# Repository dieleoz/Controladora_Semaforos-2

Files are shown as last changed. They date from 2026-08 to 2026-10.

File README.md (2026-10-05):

# 🚦 Controladora de Semáforos Móviles de 3 Estados (V9.1)

> 🧭 **Las decisiones vigentes viven en [`DECISIONES.md`](DECISIONES.md)** — una fila por
> decision, con su fecha, su motivo y que deroga. *(Aqui se publicaba cuantas hay; se quito el
> 11/09 porque decia 18 y 9 cuando ya eran mas: se cuentan alli.)* Si un parrafo de cualquier
> documento contradice una fila de ahi, **gana la fila**: el parrafo esta caducado. Se lee
> ANTES de encargar un cambio de alcance.

---

## 🔴 Lo que este README no puede decirte, y es lo primero

> ▶️ **Donde esta parado el trabajo y por donde se retoma lo dice [`ESTADO.md`](ESTADO.md)**, que se
> reescribe en cada cierre; aqui no se repite. Lo que paso, en [`HISTORIA.md`](HISTORIA.md) y en `git log`.

**La instalación certificada es `e303485` (V8.4, 31/07/2026).** Lo de debajo llegó a una mesa
el 3-4/09 y la noche del 04/09 —banco con dos tarjetas; la última cinta, 05/09 22:19, sobre
`42a52cd`— y 🔴 **el 10/09 llegó por primera vez a una calle: un Maestro (`SERIE:179DB0`)
corrió en El Sisga con firmware V9 `SIN_BANCO`** —el paquete del 08/09 (`7ff7d12`); después
se probó el del 10/09 (`b354fe9`)—. Su cinta y su diario están en `evidencia/` (308 tramas,
308 checksums que casan). Lo que se reportó allí, lo que dice la cinta y la rama que salió de
ahí, validada por el diff, están en `roadmap.md` §3.16 (`N-162`). 🔴 **Con `7ff7d12`, el
Maestro 179DB0 se declara en hora con el reloj parado: no se usa el Modo Degradado allí.**
**Desde el 29/09 el funcional prueba en banco las candidatas** (`a505fa2`, `6bd1e4f`, `d3606be`; cintas en
`evidencia/300920261130/`, `011020260934/`, `021020260914/`), **pero ninguna ha pasado banco completo.**

**La razon lineas de instrumento / lineas de producto la mide el pre-commit en cada commit**
(`.githooks/trinquete.sh`, contra el techo `RAZON_TECHO` de `.topes`): si sube por encima del techo, el
commit se para. El techo solo baja, cuando un acta de campo archiva un tema (`CLAUDE.md` §4). Cuenta
el indice, sin `historico/`, e incluye la app y el ESP32, asi que no se compara con las razones de la
serie anterior (esa serie, en [`HISTORIA.md`](HISTORIA.md)).

**Tres auditorías externas independientes dijeron lo mismo**, y la tercera lo dijo de la
respuesta a la segunda. La regla que salió de ahí vive en `CLAUDE.md` §0 y §8:

> **Un `20/20` sobre decenas de miles de líneas de instrumento que nunca han tocado una tarjeta
> no es un entregable: es una coartada.**

La tabla de abajo es verdad. **Lee lo que mide antes de lo que puntúa.**

---

## 📐 LA SPEC — empieza por aquí, y son nueve ficheros (`SPEC_0` a `SPEC_8`)

**Escritas el 12–13/09 desde el fuente, verificando cada afirmación contra el código; manda la SPEC y
`DECISIONES.md` es su índice.** `SPEC_0` es la vista del sistema y `SPEC_7` el modo sin reloj. Sustituyen a ~17.000
líneas de manuales que describían un sistema que ha cambiado cuatro veces.
**Nacieron por debajo de 300 líneas a propósito** (hoy `SPEC_1` y `SPEC_2` lo pasan): un fichero que no se puede leer
entero no lo lee nadie entero, y
entonces cada lector deriva su propia versión.

| | qué contesta |
|---|---|
| [`SPEC_1_Ciclo_y_Luces`](05_Funcional/SPEC_1_Ciclo_y_Luces.md) | qué hace **un** poste con sus tres luces y su pluma: modos, tiempos, transiciones, la barrera de salidas |
| [`SPEC_2_Dos_Puntas_y_Radio`](05_Funcional/SPEC_2_Dos_Puntas_y_Radio.md) | 🔴 **lo único de verdad difícil: que los dos postes NUNCA den verde a la vez**, con una radio lenta que pierde tramas y sin cable entre ellos; y sin radio, el Degradado con testigo (§7.bis) y el **automatico a eleccion del tecnico** (§7.ter, 29/09) |
| [`SPEC_3_La_Hora`](05_Funcional/SPEC_3_La_Hora.md) | de dónde sale la hora y qué pasa cuando se pierde — **es lo que autoriza el Degradado**, o sea el modo que da verdes sin confirmar con la otra punta |
| [`SPEC_4_App_y_Bluetooth`](05_Funcional/SPEC_4_App_y_Bluetooth.md) | la **única** forma de operar el equipo (`D-16`): qué órdenes hay, qué contesta el equipo a cada una y de qué depende esa respuesta |
| [`SPEC_5_Cobre_Camaras_Pluma`](05_Funcional/SPEC_5_Cobre_Camaras_Pluma.md) | 🛑 **qué hay en cada pin, qué es peligroso y qué no se ha medido nunca.** Se lee con un destornillador en la mano |
| [`SPEC_8_Camaras_y_Barrera`](05_Funcional/SPEC_8_Camaras_y_Barrera.md) | 🛑 **qué HACE el equipo con las cámaras y la barrera**: el veto, el retardo de 3 s, cuándo pide que se revise una cámara, los dos interruptores de administrador, y **qué NO protege**. Es la otra mitad de `SPEC_5`: aquí lo que decide el **firmware**, allí lo que decide el **cobre** |
| [`SPEC_6_Campo_Radio_y_Alarmas`](05_Funcional/SPEC_6_Campo_Radio_y_Alarmas.md) | el **procedimiento de campo** del Degradado, la configuración de radio y antenas, y la tabla completa de alarmas → qué hace el técnico |

> ⚠️ **La spec dice qué HACE el equipo hoy, no qué debería hacer.** Lo que no cumple una decisión vigente vive
> en el apartado «HUECOS MEDIDOS» de cada una, con la medida pegada. **Y los manuales viejos siguen en el
> árbol a propósito**: se intentó jubilarlos y se paró con medida — hay contenido que ninguna spec cubre
> todavía (la receta de la APK, los ensayos de cámara con instrumento, la trama canónica con checksums de la
> que cuelga un pack). Está contado en `roadmap.md` 1.35(a).

## 🔧 Qué se probó en banco, y qué no

> **El 3 y 4 de Septiembre esto vio una tarjeta.** El funcional ejecutó la guía de 29 pasos
> sobre `617bd00`: **24 pasos completados**, 4 bloqueados por el enlace Bluetooth y 1 abortado
> por un incidente de seguridad. Informe en
> `evidencia/Informe_Pruebas_Banco_Semaforos_V9.0.pdf`.
>
> **Funcionó en cobre:** carga por SWD al primer intento, radio entre puntas con caída a ámbar
> en ~20 s y vuelta sola en ~3 s, talanquera, cámara de demanda y masa común a 0 V.
>
> ✅ **La regresión N-42 —el Modo Automático no movía las luces— está CERRADA EN COBRE.** La
> cerró la sesión de banco de la noche del 04/09, con el responsable delante: *«ahí cambia ese
> amarillo y este a verde. Ahora está funcionando»*. El arreglo es `ceb8cc5` —se retiró el
> asistente entero: una sola puerta, el modo arranca corriendo—. *(Este README publicó
> «regresión abierta» hasta el 07/09; el banco la había cerrado tres días antes.)*
>
> 🔴 **Y aparecieron tres defectos que ninguna cifra de la tabla de abajo podía ver**, porque
> ninguno es una propiedad del código: la tarjeta Maestro tiene un corto de 3,3 V a masa
> (**N-116**), las entradas de campo no tienen ninguna protección mientras las salidas sí
> (**N-120**), y el ESP32 no se anunciaba por Bluetooth (**N-117**). **Los tres pasaron el
> `20/20` sin despeinarlo.**
>
> *(El cuarto de aquella lista, **N-118** —«el mando A/B no responde, 0,6 V en reposo»—, quedó
> **REFUTADO el 05/09**: el propio banco había medido las dos ramas del experimento en la misma
> tabla. Mismo cobre, distinto `pinMode`, distinta tensión. Ver `05_Funcional/historico/DECISIONES_hist.md`, cerradas.)*

**Verificación actual** — cifras **copiadas del acta**
[`evidencia/2026-10-05_compuerta.txt`](evidencia/2026-10-05_compuerta.txt), que genera
`python 01_Firmware/compuerta.py` en una sola corrida. No se escriben a mano — y desde **N-62**
eso ya no es una promesa: el pack `documentos_01_cifras_del_acta` compara esta tabla contra la
última acta en cada corrida del banco. Cuando se escribió por primera vez, **falló**: esta tabla
publicaba 32 rutas y 86,4 % de flash cuando el acta que ella misma citaba medía 38 rutas y
92,8 %. Las cifras eran del 05/08 y llevaban la palabra *«copiadas»* encima.

| Comprobación | Estado | |
|---|---|---|
| guarda de rutas de los instrumentos | ✅ | 61 rutas parseadas, todas existen |
| banco por packs *(70 packs)* | 🔴 **FALLA** | **1372/1373 comprobaciones en 70 packs** — 69 PASS, **1 FALLA**. El rojo es CORRECTO: `decisiones_01_anclas` acusa a **`D-22`**, la única decisión vigente sin construir, y **necesita una tarjeta delante** (`CLAUDE.md` §1: no se decora) |
| compila Maestro / Esclavo / Repetidor / ESP32 | ✅ | **70.4 %** · 62.6 % · 20.6 % · 35.7 % — *el Maestro ocupa **45408 de 64512 B** (la ultima pagina queda para el testigo de `D-35`); el Esclavo, **40360 B**. Bajo al quitar la libreria RTC (`N-172`) y subio con la salida programada (`D-52`)* |
| simulador funcional | ✅ | 9/9 — eran 20, y 11 de aquellas no medían nada: se retiraron una a una con su evidencia |
| simulador de repetidor | ✅ | 10/10 |
| compila ESP32 | ✅ | 35.7 % — 1123581 de 3.145.728 B |
| simulador del puente ESP32 | ✅ | **150/150** — las tres puntas: `bluetooth.cpp` compilado, la app en jsdom, y solo el ESP32 modelado |
| simulador de app y bluetooth | ✅ | **12/12** — estuvo en `ABORTADO` unas horas el 05/09: **N-149** le añadió el campo `ESC` al `$STATUS` y el instrumento no supo con qué compararlo. Se enseñó a leerlo el mismo día. Queda escrito porque **mientras duró, todo lo que vigilaba entró sin mirar** (`CLAUDE.md` §1) |
| **app ejecutada en DOM** | ✅ | **540/540** — carga `index.html` en jsdom, más `app.js` y **los `js/*.js` que el propio HTML declara, en su orden**, y los **ejercita**: pestañas, modales, ingesta de telemetría, *fuzzing* de 200 tramas corruptas y los botones que mandan comandos. Es el único instrumento que **ejecuta** la app en vez de leerla |
| test funcional de la app | ✅ | **70/70** — decía «22/22» a mano y ejecuta 34; su prueba de Courier RTC era una tautología |
| test unitarios TDD de la app | ✅ | **85/85** — la **segunda** suite unitaria, que hasta el 01/09 **no estaba en la compuerta**: 23 pruebas verdes que no medían nada. *(Esta fila publicó `55/55` hasta el 07/09: era la cifra del 02/09, y `documentos_01` **no la vigila** — no está en su tupla `CIFRAS`.)* |
| test unitarios de la app | ✅ | **63/63** — seis suites que no cargan el navegador: NMEA y *checksums*, generador de comandos y barrera de PIN, validación de `SET_TIEMPOS`, Courier RTC, gestor de cruces y escala de 20 cruces |
| arnés del ciclo | ✅ | **55/55** — corre sobre el `ciclo_degradado.h` real compilado, sin espejo en Python |
| arnés del respaldo | ✅ | compila el `calcularSuma()` real; identidad de `respaldo.cpp` entre puntas + prueba de vida |
| arnés del Degradado a dos puntas | ✅ | **143/143** — las dos puntas en Degradado **cada una con su reloj**. Entrega **el número**: el cruce aguanta **29 s** de desfase contra los **20,2 s** que el equipo puede acumular en 48 h, o sea factor **1,44** — y no el 2 que afirmaban los comentarios de las dos puntas |
| arnés de las dos puntas | ✅ | **127/127** — el C++ **real de las DOS puntas** en el mismo proceso y el mismo instante: verde simultáneo en **0** instantes. Cubre `G3`/`N-163` (suelta del verde), `D-34` (verde del Esclavo frente al ámbar del Maestro, `G12`–`G14`) y `D-53` (rojo+amarillo antes de cada verde). Sin banco |
| arnés del automático | ✅ | **88/88** — compila `coordinador.cpp` + `semaforo.cpp` + `modo_automatico.cpp` + `modo_inteligente.cpp`, `demanda.cpp` y el `botones.cpp` real, y comprueba SFTY-2 sobre las escrituras de pin. Las 16 nuevas son el **Bloque G de `D-33`**: el retardo de bajada de la pluma y el veto de la cámara, ejecutados |

> 🛑 **Aquí había una fila más, `arnés de pantalla`, y NO se actualiza: se RETIRA.** Compilaba los cuatro
> `lcd.cpp`/`menu.cpp` reales contra 131 `.c` de U8g2, y **se fue con el LCD** el 13/09 (`D-32` (1), `17d3a1f`).
> La compuerta baja de **20 filas a 19** y el banco pierde sus **287 comprobaciones** (145 Maestro + 142
> Esclavo): **es una bajada A PROPÓSITO, no una regresión.** Se dice aquí abajo y no en la tabla porque en la
> tabla **sólo caben filas con una medida detrás** — una fila sin medida se lee como medida.

**19 PASS · 1 FALLA · 0 ABORTADO, de 19 comprobaciones — la compuerta sale con código `1`.**

> 🔴 **El `1` es el hallazgo, no una regresión.** Lo acusa `decisiones_01_anclas`: **`D-14`, `D-22` y
> `D-23` están vigentes en `DECISIONES.md` sin una línea que las construya.** `D-14` —*el controlador
> cierra un contacto y la cámara graba*— fue **el argumento de una compra**; `D-22` es poner `Y1`, y
> `D-23` es la pantalla propia del poste 2, **que es de la app y la app no se ha tocado**.
>
> 🛑 **Y ninguna de las tres se apaga poniéndole un ancla:** `D-23` se apaga **construyéndola**
> —un `$EVENT` nuevo en el Esclavo y su pantalla en la app—; `D-14` espera **una decisión del
> responsable** —qué canal de `J9`/`J11`/`J13` se gasta, para siempre—; y `D-22` espera **una
> tarjeta delante**, porque si `Y1` no oscila el `_Error_Handler` es `noreturn` y la tarjeta queda
> a oscuras. **El 07/09 se intentó cerrarlas poniéndoles el ancla en un comentario y la compuerta se
> puso en `20/20` sin que se construyera nada** *(`roadmap.md` §3.10)*. Las tres anclas están
> revertidas y el rojo volvió, que es donde tiene que estar.

> 🟢 **Y cuando vuelva a `0`, ese verde será más peligroso que el rojo, no menos.** Mientras la
> compuerta sale con `1` nadie la confunde con un permiso; un `0` sí se confunde. Lo que dice es
> exactamente esto:
> *los modelos y los arneses de PC no encuentran nada*. **No dice que el firmware funcione en la
> tarjeta.** El contraejemplo está fechado: los tres defectos que pararon el banco del 3-4/09
> pasaron estas 19 comprobaciones sin despeinarlas. **Verde no es entregable.**

### Por qué la compuerta está hecha así — cuatro lecciones, en una línea cada una

| | |
|---|---|
| **`ABORTADO` no es `PASS`** | una comprobación que no pudo correr no dice *nada* del firmware. Así se perdió la cobertura del Maestro sin que nadie se enterara (**N-28**) |
| **Un `FALLA` contado como `PASS`** | los tres validadores monolíticos imprimían `FALLA` y salían con código `0`. Se retiraron el 05/08 exigiendo que los packs sumaran *exactamente* sus comprobaciones y que el **texto** de cada una coincidiera — Costura `41 = 41`, Maestro `64/67 = 64/67`, Esclavo `31 = 31` (**N-46**) |
| **Un `gcc` que existe no es un `gcc` que enlaza** | dos arneses cayeron a `ABORTADO` de un día para otro con el mismo compilador en el acta: `ld` no abría una ruta con `ñ`. La compuerta **le exige enlazar un `main()` vacío** antes de fiarse (**N-44**) |
| **Un pack puede estar verde sin medir nada** | la prueba 2.8 del checksum hacía `break` sobre una condición siempre cierta y no evaluaba un solo candidato. Al arreglarla apareció un camino **explotable** en `FLAGS`/`SYNC_BAJA` (**N-51**) |

**El detalle de las cuatro, con su medida, está en [`roadmap.md`](roadmap.md).**

> **Un acta no es una frase.** `evidencia/` guarda fecha, hash de HEAD y versión de toolchain de
> cada corrida, así que "20/20" deja de ser un número que envejece en un README y pasa a ser
> algo que el auditor re-corre sobre ese mismo commit. Estado de hoy en
> [`ESTADO.md`](ESTADO.md); reglas permanentes en [`CLAUDE.md`](CLAUDE.md).

### 📦 El banco son 70 packs — y eso NO es una medalla

```
python 01_Firmware/Simulaciones/banco/correr.py --listar
python 01_Firmware/Simulaciones/banco/correr.py --pack esclavo_03   # un fallo, solo, en 1 s
```

**Por qué se migró** — había tanto instrumento como firmware: **8.898 líneas contra 8.895, uno a
uno**. Y los simuladores no ejecutan el C++, lo *reimplementan a mano*: son una segunda copia que
alguien sincroniza, y eso falló cuatro veces en una semana.

⚠️ **Pero `correr.py` NO es `compuerta.py`.** El banco es **una fila de veinte**: un
`x/y` de packs no dice nada de las otras diecinueve, y una de ellas puede estar en `ABORTADO` por
el mismo cambio que acabas de comitear. **Antes de comitear se corre `compuerta.py`, completo.**

### 📦 Qué se le manda al funcional, y por qué son dos paquetes

**Un paquete es una autorización implícita:** quien lo recibe asume que puede instalarlo. Con el
banco sin pasar, eso obliga a separar lo que pide una medida de lo que entrega una versión.

| | |
|---|---|
| **Encargo de banco** | Pide que alguien ponga la tarjeta delante. Lleva los binarios con sus MD5 y los firmware marcados `SIN_VALIDAR` en el propio nombre |
| **Entrega de versión** | Fuente para PlatformIO + APK + el `.html` de pruebas vigente + `LEEME_PRIMERO.txt`. **Sin `.bin`, sin manuales, sin `.md` y sin acta**; se deja en `entregas/` (ignorada por git), nunca en la raíz |

El `LEEME_PRIMERO` **no abre con la cifra en verde** — abre diciendo qué corre en campo, que esto
no es eso, y qué sigue roto. El método está en `orquestador:entregar` y en
`.claude/particularidades/entregar.md`.

**Certificado en campo:** 31 de Julio de 2026 *(V8.4, dos radios en enlace directo)*
**Última actualización del repositorio:** 11 de Septiembre de 2026 *(la cifra vigente y su hash de
HEAD están en el acta que cita la tabla de arriba, y no se repiten aquí: este pie llevaba
`14 PASS` sobre HEAD `2cde016` cuando el acta ya medía otra cosa, y un recuento viejo no se lee
como viejo, se lee como medida.)*
**Repositorio Oficial:** [`github.com/dieleoz/Controladora_Semaforos-2`](https://github.com/dieleoz/Controladora_Semaforos-2.git) — remoto `origin`.
**Normativa Aplicable:** Resolución 2024 del Ministerio de Transporte de Colombia (Secuencia de Luces y Tiempos de Seguridad Vial)

---

## 🧭 La arquitectura vigente, decidida en obra el 28/08 y cerrada el 31/08

**El documento con el detalle medido —`fichero:linea` en cada afirmación, las decisiones
abiertas con dueño y las medidas de multímetro— es
[`05_Funcional/17_Arquitectura_28-08_y_Decisiones_Abiertas.md`](05_Funcional/17_Arquitectura_28-08_y_Decisiones_Abiertas.md),
y manda la SPEC (`05_Funcional/SPEC_0..8`; [`DECISIONES.md`](DECISIONES.md) es su índice). Aquí va sólo el reparto,
porque un README que describe el aparato anterior manda a cablear el aparato anterior.**

### El reparto, en una frase

**El STM32 sigue siendo el controlador del semáforo. El ESP32 es un módulo de expansión colgado de
un puerto serie: aporta reloj y Bluetooth, y NO manda sobre las luces.**

```
                       fuente propia 12 V (NO sale de la tarjeta)
                                    |
   +--------------------+     +-----v--------------------+
   |   STM32F103C8      |     |         ESP32            |
   |   (controlador)    |     |   (modulo de expansion)  |
   |                    |     |                          |
   |  luces    J3-J8    |     |  DS3231  GPIO21 SDA      |
   |  barrera  J15      |     |          GPIO22 SCL      |
   |  camaras  J16 (*)  |     |          (pila propia)   |
   |  LoRa     J12      |     |                          |
   |           USART3   |     |  Bluetooth (sustituye    |
   |                    |     |   al modulo SPP)         |
   |  USART1 remapeado  |     |                          |
   |  PB6 TX == J17 p3 <------ GPIO16 (RX2)              |
   |  PB7 RX == J17 p2 ------> GPIO17 (TX2)              |
   +---------|----------+     +-----------|--------------+
             |                            |
             +-------- masa comun --------+
                       9600 8N1
```

*(\*) Aquí ponía ~~`camaras J14, J16`~~. ✏️ **11/09:** las cámaras van a `J16` —dos por poste, p10 y
p12 (`D-25`)—. `J14` no lleva cámara: ~~`A-2` lo reserva al fin de carrera,~~ **pero el firmware lo sigue
leyendo como cámara de demanda (`CAM_DEMANDA_PIN` = `PB0`)** — ~~conflicto abierto, del responsable~~
→ **`D-27` (11/09): `J14` LIBRE, sin cablear; el fin de carrera no se instala en este despliegue**,
así que en `J14` no se conecta nada (`ARQUITECTURA.map` §7.3).*

### El enlace, pin a pin — y la fuente

| ESP32 | dirección | `J17` | STM32 |
|---|---|---|---|
| `GPIO17` (TX2) | ➡️ | **p2** | `PB7` — **RX** del micro |
| `GPIO16` (RX2) | ⬅️ | **p3** | `PB6` — **TX** del micro |
| `GND` | — | p7 o p9 | `GND` — **masa común obligatoria** |

`9600 8N1`. El `USART1` ya está remapeado a `PB6`/`PB7` en el firmware de las dos puntas (N-76,
`bluetooth.cpp`, `grep -n "SerialBT(PB7, PB6)"`) — el puerto y el pinout son los mismos que ya
tenía el módulo SPP; **lo que se enchufa, no**.

> 🔴 **El ESP32 lleva fuente propia desde 12 V. NO cuelga de los 3,3 V de `J17` p6/p8.** Ese riel
> sale del `U5` y es **el mismo que alimenta al STM32 que gobierna el semáforo**: un ESP32 con radio
> da picos de corriente del orden de medio amperio, y un reset del controlador provocado por un
> periférico de diagnóstico es el reparto de riesgo que no se acepta. **El accesorio no puede tumbar
> al que manda.**

### Lo que se retira, y por qué — tachado, no borrado

> **Una vía descartada que desaparece en silencio vuelve a proponerse.** Por eso van tachadas con su
> motivo al lado, y no suprimidas.

| se retira | por qué | consecuencia |
|---|---|---|
| ~~**Pantalla LCD ST7920** (las dos puntas)~~ | **este PCB no permite ampliación**, y la pantalla ocupaba cinco pines —`PB3` `PB4` `PB5` `PB6` `PB7`— de los que el Bluetooth necesita `PB6`/`PB7`: **no había de dónde sacarlos**. Confirmado por el responsable el 05/09 (`D-17.bis`) | toda la operación pasa por la app. **Se retira del EQUIPO, no del código**: `lcd.cpp` y `menu.cpp` siguen compilando y `Validacion_LCD` sigue dando `271/271` sobre un framebuffer del PC |
| ~~**Módulo Bluetooth SPP dedicado** (`HC-05` / `JDY-30`)~~ | lo sustituye el ESP32 por el mismo `J17` | **no se compran** |
| ~~**Los CUATRO botones**~~ | los pines 3 y 4 son los que necesitan las cámaras, y el 05/09 el responsable retiró la botonera entera: **«todo por app»** | ⚠️ **DOS funciones de botón están muertas y DOS SIGUEN VIVAS, y el reparto no es casual**: `botonAceptar()`/`botonCancelar()` son `return false;` —son los de `PB14`/`PB15`, **los pines que ahora son cámaras**—; pero `botonArriba()`/`botonAbajo()` tienen llamadores vivos y leen `BOTON1`/`BOTON2`, **que son los pines del mando**. 🔴 **Lo que alguien cierre en `J16` p5/p8 contra los 3,3 V SIGUE ENTRANDO al firmware.** *(`Botón 1` y `Botón 2` SON `Mando A` y `Mando B`: los mismos dos pines con dos nombres.)* |
| ~~**El mando de relés** (hardware)~~ | 05/09, el responsable: *«ya no tenemos mandos de A y B, sólo la app»* (`D-1`) | ~~🔴 **El CÓDIGO no se toca**~~ 🛑 **DEROGADO POR `D-30` (12/09): el software TAMBIÉN sale** —el responsable: *«hasta el sw lo quitamos»*—. **Decidido y SIN CONSTRUIR**, y va con su precio medido, que es lo que lo tiene parado: `mando_ambarLocal()` tiene **SEIS** llamadas vivas (no cinco), y de ellas **la que ABRE PASO es el veto del `CMD_GO_GREEN` del Esclavo**; retirar sólo el armador deja ese `if` **ABIERTO, no inerte**. Además `mando.cpp` es el **único escritor de `senalActiva`**, así que el cambio toca **`SFTY-2`**, y después **ningún instrumento vigila la interceptación de las salidas por señal**. ⚠️ Y no cierra el cobre: `J16` p5/p8 siguen vacíos y **el firmware los lee por DOS caminos**, no sólo por el del mando (`CLAUDE.md` §3) |

> 🔴 **Y su consecuencia declarada, que es una propiedad del sistema y no una avería (`D-16`):
> SIN TELÉFONO NO HAY FORMA DE OPERAR EL EQUIPO.** Ni ámbar, ni volver a automático, ni parar el
> cruce. Va escrito en el manual del operario: el teléfono es herramienta crítica.

### Las cámaras van a `J16` p10 y p12 — **dos por poste** (`D-25`, 11/09) — y **ya se cablean**

*(Resumen: la tabla que manda es `05_Funcional/17_…` §1.7. La columna «red» es el nombre heredado
del netlist, **no el papel del pin**.)*

| `J16` | red | pin | uso nuevo |
|---|---|---|---|
| p1 | `/12V` | — | 🔴 **12 V crudos. Se tapa físicamente en CADA equipo que se monte** (N-120) — es el único conector de señal de la tarjeta que los trae, sin opto ni clamp |
| p5 | `/Boton1` | `PB9` | **libre y SIN CABLEAR** (`A-2`, cerrada el 05/09: ~~el fin de carrera va a `J14`~~ — *11/09, `D-27`: y tampoco allí, el fin de carrera no se instala; `J14` queda libre*). 🔴 **El firmware sigue leyendo ese pin** y alimentando el reconocedor de secuencias del mando |
| p8 | `/Boton2` | `PB13` | igual que p5 |
| p10 | `/Boton3` | `PB14` | 🎯 **`CAM_C_PIN` — cámara 1**, contacto de alarma entre p9 (3,3 V) y p10 *(verificada en banco el 03/09)* |
| p12 | `/Boton4` | `PB15` | 🎯 **`CAM_D_PIN` — cámara 2**, contacto de alarma entre p11 (3,3 V) y p12 |

> ✅ **`D-25` (11/09, el responsable): las conexiones de la guía de cámaras del Sisga quedan
> DEFINITIVAS** —4 cámaras, dos por poste— y derogan de `D-13` solo *«una por poste, p12 vacío»*.
> 🔴 **Lo que el que cablea tiene que saber, medido en el firmware de hoy:** las **dos entradas hacen
> LO MISMO** (piden paso; `botones.cpp`, `CAM_J16[2]`), **ninguna protege la pluma** (el veto es
> `A-1.bis`, sin construir), y **una segunda cámara muerta desde la instalación no la detecta nadie**
> (el vigilante salta el pin que nunca dio un flanco): se comprueba cada cámara por separado al
> instalar. Las frases falsas de la guía del 10/09 se corrigen en su versión nueva (`roadmap.md` §3.16)
> → ✏️ **11/09: es [`05_Funcional/Camaras_Sisga_4x.html`](05_Funcional/Camaras_Sisga_4x.html)**, con
> la fe de erratas delante y la talanquera en `J15` al final. ⚠️ **La app** (también la APK del 10/09)
> **pone `CAM: OK — las dos ven` en cuanto detecta CUALQUIERA de las dos cámaras del poste**, aunque la
> otra no haya detectado nunca: por eso **cada cámara se comprueba con el multímetro en su borne**
> (0 V en reposo, 3,3 V con algo en la zona), y no con la app.

> ✅ **La medida `M3` está CERRADA desde el 03/09 y las cámaras se cablean** (`D-3`). Medido en
> cobre —multímetro, conector vacío, paso 20 de la Guía—: el pull-down de **10 kΩ** que declaraba
> el netlist **es real y está en las cuatro posiciones** (`R65`–`R68` con su 100 nF); `p10` y `p12`
> dan **0 V en reposo**, así que la entrada es **activa en ALTO**, que es lo que el firmware ya
> hacía. El paso 21 cableó `p10` contra `p11` en normalmente abierto y funcionó, **sin demandas
> fantasma**.
>
> ~~🛑 No se cablea cámara a `J16` hasta cerrar la medida `M3`~~ — **caducado**: este README lo
> siguió publicando cuatro días después de cerrarse, y el 05/09 se le contestó al responsable con
> ese párrafo. Se conserva tachado porque una vía descartada que desaparece vuelve a proponerse.

> ⚠️ **El orden sigue siendo asimétrico: primero el firmware cargado, después el destornillador.**
> Un commit no protege de un destornillador — se exige la **carga verificada en la tarjeta**, no el
> merge. ✏️ **11/09, con `D-25` vale para los DOS pines:** con un binario anterior a `deeeab4` (la
> V8.4 incluida) `PB14` es `botonAceptar()` y **`PB15` es `botonCancelar()`**, así que lo que se
> cablee en `p10` **o en `p12`** puede actuar como un botón en un equipo que está en la calle.

### Seis luces gobernadas, no ocho

`pines.h` declara ocho salidas de luz, pero **el semáforo peatonal nunca se conectó a nada**:

| declarado | pin | ¿lo escribe alguien? |
|---|---|---|
| `ROJO1` `AMARILLO1` `VERDE1` / `ROJO2` `AMARILLO2` `VERDE2` | `PA0`-`PA5` | ✅ sí, y **sólo** `semaforo.cpp` |
| `ROJO_PEATON` · `VERDE_PEATON` | `PA6` · `PA7` | 🔴 **ni un `pinMode` ni un `digitalWrite` en ninguna de las dos puntas** |
| `BUZZER` | `PB1` | 🔴 **igual: declarado y nunca escrito** |

Es **hardware pagado y muerto** —tiene opto, MOSFET y bornera propia—. Se anota aquí porque
*"conserva las 8 luces"* es la clase de frase que se copia de documento en documento sin que nadie
corra el `grep`: **la barrera de salidas de `CLAUDE.md` §2 custodia ocho nombres; el equipo mueve
seis.**

### 🛑 Lo que esta arquitectura NO autoriza

- **Nada de esto ha pasado banco entero, y la compuerta no lo suple.** Lo que este apartado llama
  medido se midió en su mayoría **sobre ficheros** —el `.cpp`, el `.h`, el `.kicad_sch` y el
  `.kicad_pcb`—. Un fichero dice lo que alguien dibujó; una placa dice lo que se fabricó.
- 🟠 **Sin pantalla, `$STATUS` es el único tablero que existe** — y hoy trae `BAT:--` porque
  **no hay un solo `analogRead` en `src/`**. Un campo que no se mide se retira o se marca; no se
  deja con aspecto de medida.
- 🟠 **El ESP32 de este proyecto no tiene watchdog en el Repetidor** *(los dos STM32 sí: 4 s; el
  ESP32 de expansión también, desde `vigilante.cpp`)*, y hay precedente escrito de uno clavado
  tumbando el enlace. Con la pantalla y el mando retirados, un ESP32 colgado deja el equipo **sin
  ninguna superficie de mando**.

**El plano de conexiones que se entrega —`J17`, `J16`, `PB6`/`PB7`, el `DS3231` y el SWD— es
[`05_Funcional/Montaje_Campo_2026-10-05.html`](05_Funcional/Montaje_Campo_2026-10-05.html)**,
con el cobre medido en `17_...` y SPEC_5.

---

## 🗂️ Paquete Oficial de Entregables y Manuales (`05_Funcional/`, en `.md` y `.docx`)

> **ARCHIVADOS el 28/09 en `05_Funcional/historico/`: todas las filas salvo la 10 y la 17.** No son vigentes;
> mandan las `SPEC_0..8` (CLAUDE.md §15). La columna «Estado» describe cada manual antes de archivarlo.

| # | Manual | Estado |
|---|---|---|
| 1 | [`1_Manual_Usuario`](05_Funcional/historico/1_Manual_Usuario.md) | Operación y comportamiento vial (Resolución 2024) |
| 2 | [`2_Manual_Hardware_y_Pruebas`](05_Funcional/historico/2_Manual_Hardware_y_Pruebas.md) | Hardware, borneras y ensamblaje STM32 |
| 3 | [`3_Protocolo_Pruebas_Rigurosas`](05_Funcional/historico/3_Protocolo_Pruebas_Rigurosas.md) | Protocolo de auditoría funcional. ⚠️ **reescrito**: cada prueba lleva su marca `SE REESCRIBE` / `SE RETIRA` / `SE APLAZA` |
| 4 | [`4_Manual_Configuracion_Radios`](05_Funcional/historico/4_Manual_Configuracion_Radios.md) | E90-DTU (2.4 kbps / 30 dBm / FEC) |
| 5 | [`5_Manual_Puente_ESP32`](05_Funcional/historico/5_Manual_Puente_ESP32.md) | Puente repetidor V7.6 — **fuera de la configuración vigente** |
| 6 | [`6_Preguntas_Diseno_Funcional`](05_Funcional/historico/6_Preguntas_Diseno_Funcional.md) | Decisiones de diseño cerradas |
| 7 | [`7_Especificacion_Antenas`](05_Funcional/historico/7_Especificacion_Antenas.md) | Antenas y línea de vista |
| 8 | [`8_Procedimiento_Modo_Degradado`](05_Funcional/historico/8_Procedimiento_Modo_Degradado.md) | Operación de emergencia por reloj sin radio |
| 9 | [`9_Manual_Parametrizacion_Camara_IA`](05_Funcional/historico/9_Manual_Parametrizacion_Camara_IA.md) | **4 cámaras, dos por poste** en `J16` p10/p12 (`D-25`, 11/09) — ~~⚠️ **el manual todavía dice una por poste: pendiente de alinear**~~ ✏️ **alineado el 11/09** (el `.docx` no: se regenera aparte). **Es el entregable principal del diseño de cámaras** (`D-12`): toda la inteligencia vive en la configuración de la cámara. 🎯 |
|  |  | **11/09, `D-27`: sus VALORES de configuración salen del manual del modelo, [`05_Funcional/historico/MANUAL_CONFIGURACION_CAMARAS_IA.md`](05_Funcional/historico/MANUAL_CONFIGURACION_CAMARAS_IA.md) §4** —tabla valor a valor en su §4 Paso 3—; las cuatro cámaras están compradas |
| 10 | [`10_Manual_Modulo_Bluetooth_Telemetria`](05_Funcional/historico/10_Manual_Modulo_Bluetooth_Telemetria.md) | ⚠️ **manda enchufar un `HC-05` en `J17`, que es donde va el ESP32** |
| 11 | [`11_Manual_Instalacion_RTC_DS3231_Bateria`](05_Funcional/historico/11_Manual_Instalacion_RTC_DS3231_Bateria.md) | ~~`DS3231` en `PB0`/`PB8`~~ → **se muda al ESP32**. ⚠️ **manual sin corregir** |
| 12 | [`12_Cobertura_de_Pruebas_y_Huecos`](05_Funcional/historico/12_Cobertura_de_Pruebas_y_Huecos.md) | Qué mide cada instrumento y **qué queda sin medir** |
| 13 | [`13_Manual_Modulo_Expansion_I2C_y_Compras`](05_Funcional/historico/13_Manual_Modulo_Expansion_I2C_y_Compras.md) | ⚠️ **su §4 queda sin sujeto**: el I²C ya no vive en el STM32 |
| 14 | [`14_Manual_App_Movil_IOT_VIAL`](05_Funcional/historico/14_Manual_App_Movil_IOT_VIAL.md) | Operación de la app: SPP, gestor de cruces y Courier RTC |
| 15 | [`15_Lista_de_Compras_Hardware`](05_Funcional/historico/15_Lista_de_Compras_Hardware.md) | **Qué se pide, cuánto y cuándo** |
| 16 | [`16_Documento_Auditoria_Arquitectura_y_Usabilidad_App`](05_Funcional/historico/16_Documento_Auditoria_Arquitectura_y_Usabilidad_App_IOT_VIAL.md) | Auditoría de arquitectura y usabilidad de la app |
| 17 | [`17_Arquitectura_28-08_y_Decisiones_Abiertas`](05_Funcional/17_Arquitectura_28-08_y_Decisiones_Abiertas.md) | 🧭 **Manda sobre las filas 9, 10, 11 y 13.** Es donde se anotan las medidas de cobre |
| 18 | [`18_Especificacion_Firmware_ESP32`](05_Funcional/historico/18_Especificacion_Firmware_ESP32.md) | Especificación del firmware del módulo de expansión ESP32 |
| 19 | [`19_Especificacion_Placa_Portadora_ESP32`](05_Funcional/historico/19_Especificacion_Placa_Portadora_ESP32.md) | Especificación de la placa portadora del ESP32 |

*(**La lista se ha desfasado CUATRO veces por lo mismo, y sigue sin instrumento**: el 27/08 anunciaba
11 manuales de los 14 que existían; el 28/08, 15 de 16; el 31/08, 16 de 17; y hasta el 11/09, 17 de
**19**. Contar los ficheros es `ls 05_Funcional/[0-9]*.md`; que nadie lo haga es lo que hace falta
cerrar.)*

---

## 🛠️ Estructura del Ecosistema de Firmware

- [`01_Firmware/Maestro`](01_Firmware/Maestro): **El controlador.** Máquina de estados STM32,
  barrera de salidas (`semaforo.cpp`, el único que escribe pines de luz), Modo Degradado, mando de
  relés (código conservado) y telemetría Bluetooth (`USART1` **remapeado a `PB6`/`PB7` → `J17`**).
- [`01_Firmware/Esclavo`](01_Firmware/Esclavo): Nodo secundario STM32 con ACK por radio
  (`USART3`), fallback de orfandad a **25 s**, ámbar local con veto SFTY-21 y telemetría
  Bluetooth.
- [`01_Firmware/ESP32_Expansion`](01_Firmware/ESP32_Expansion): El módulo de expansión —reloj
  `DS3231` y Bluetooth—, **con watchdog** (`vigilante.cpp`).
- [`01_Firmware/Repetidor`](01_Firmware/Repetidor): Puente ESP32 back-to-back. ⚠️ **Fuera de la
  configuración vigente** y **sin watchdog**: es el mismo firmware que se quedó clavado tumbando el
  enlace el 31/07. **No es el ESP32 de expansión.**
- [`01_Firmware/Simulaciones/`](01_Firmware/Simulaciones): simuladores y `banco/` con sus
  packs *(cuántos, en el acta)*.
- [`01_Firmware/Validacion_LCD/`](01_Firmware/Validacion_LCD) · `_Ciclo/` · `_Respaldo/` ·
  `_Automatico/`: los arneses que compilan C++ real. Qué compila cada uno y su punto ciego:
  [`ARQUITECTURA.map`](ARQUITECTURA.map).
- [`01_Firmware/compuerta.py`](01_Firmware/compuerta.py): **la única forma correcta de
  verificar** — `18 PASS · 1 FALLA · 0 ABORTADO`, exit code 1. Las cifras están en la tabla de
  arriba, que se copia del acta; ésta es sólo la puerta. Qué se corre según lo que se toca (la
  cadencia) y por qué el simulador está congelado: `CLAUDE.md` §4.
- [`.githooks/`](.githooks) y [`.topes`](.topes): el pre-commit del método (topes de documentos,
  ancho, relatos, 500 líneas por fichero de código salvo el firmware grabado) y el trinquete
  instrumentos/producto. Se activa con `git config core.hooksPath .githooks`.
- [`.claude/particularidades/`](.claude/particularidades): lo propio de este repo para las skills
  del plugin `orquestador@diego` (`entregar`, `verificar`) y la mecánica larga de `CLAUDE.md`.
- `ESTADO.md` es el punto de retomar; `HISTORIA.md`, la crónica; `DECISIONES.md`, lo ya contestado.
- **Los paquetes no se versionan:** salen a `entregas/` (ignorada por git), y los retirados a
  `entregas/RETIRADOS/`.

> 🛑 **Y para cerrar donde se abrió: nada de este README es un permiso.** En campo corre la
> **V8.4**; la V9.1 compila y **pasa 18 de las 19 filas de la compuerta — la que falla es el censo de decisiones sin construir, y falla con razón** (`D-22` necesita una tarjeta delante). **Lo que hay hoy en el árbol no ha visto una
> tarjeta**. **Nada sube a campo sin pasar banco** — y el banco no lo sustituye ningún número verde
> de esta página.

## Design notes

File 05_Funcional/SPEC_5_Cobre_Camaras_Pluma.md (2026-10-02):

# SPEC 5 — COBRE Y CONECTORES

**Para quien tiene un destornillador en la mano, y para quien compra — UN SOLO LECTOR.** Que hay en
cada pin, que es peligroso, y que declara este proyecto **sin haberlo medido nunca**. 🔴 **Que HACEN
la camara y la barrera —el veto, el retardo de 3 s, el aviso, los dos interruptores— ya NO vive aqui:
es `SPEC_8`.** **Fuera** ademas: el ciclo (SPEC 1), la radio (SPEC 2), la hora (SPEC 3), la app (SPEC 4).

> **EL CORTE CON `SPEC_8`, Y POR QUE ES ESE — se escribe porque partir un documento deja huecos entre
> las dos mitades, y un hueco que nadie nombra no lo cubre nadie.** Aqui vive lo que decide **EL
> COBRE**: lo que hay en un borne y lo que pasa **sin firmware dentro**. Alli vive lo que decide **EL
> FIRMWARE**. Por eso **la pluma sin energia esta AQUI** (§4: cae el pin, cae el MOSFET, baja el
> brazo) y **la pluma que sube con el ambar intermitente esta en `SPEC_8` §5** — esa la decide una
> linea de `escribirPines()`, no el cobre.

**De donde sale cada linea.** Las MEDIDAS de cobre son de `05_Funcional/17_Arquitectura_28-08_y_
Decisiones_Abiertas.md`, **copiadas literales con su fecha** — esa spec **gana a esta** en todo lo
medido. Lo decidido vive en las spec (`DECISIONES.md` es su indice). El firmware se cita **por SIMBOLO**, nunca por
linea. **Escala:** `MEDIDO EN COBRE` = multimetro sobre la placa, con su numero y fecha · `MEDIDO` = leido
del fichero · `SIN VERIFICAR` = **nadie lo ha comprobado, ni aqui ni en ningun sitio**.

> 🔴 **Y la linea que manda sobre todo lo demas: no hay ni una fila «VERIFICADO EN LA PLACA» en todo
> el mapeo de la tarjeta** (`MAPEO_TARJETA_KICAD.md` §0 y §9) **salvo las que dejo el banco del
> 03-04/09**: `J16` p5/p8/p10/p12, `J17` p2/p3, `J14`, `J15` y las masas del modulo. Todo lo demas
> es un **dibujo**, no una placa.

# 🛑 PAGINA 1 — LOS AVISOS QUE HIEREN A UNA PERSONA: **TRES DE COBRE, Y EL CUARTO SE MUDO**

## 1. `J16` p1 lleva 12 V CRUDOS, y taparlo es OBLIGATORIO en cada equipo

`J16` es un conector de **senal**, directo a la pata del `U1`. **No hay opto, no hay resistencia en
serie y no hay clamp** entre `p1` y el resto del conector. `MAPEO_TARJETA_KICAD.md` §7: **`J16` es el
unico conector de senal de toda la tarjeta que trae 12 V**. **Un contacto de `p1` a `p10` o `p12`
mete 12 V en una pata que espera 3,3.**

- **`D-4`: se tapa en cada equipo que se monte** — no es cautela de banco (`N-120`). **El metodo que
  se documenta es RETIRAR EL PIN del cuerpo del conector volante** (paso 4 del banco), no la funda
  termorretractil: no se puede deshacer por accidente.
- **El firmware NO PUEDE protegerse de esto.** Esa posicion no llega a ningun pin del micro: ninguna
  linea de codigo se entera de que la puentearon contra una de senal. **La barrera es fisica o no hay
  barrera** (cabecera de `pines.h`, `D-4`).
- **MEDIDO EN COBRE 31/08 — el colchon no existe:** la separacion real red de 12 V / senal es
  **1,359 mm** en `p12` (el peor), **1,405 mm** en `p5`, **1,408 mm** en `p8`, 4,269 mm en `p10`. El
  documento viejo publicaba 10-28 mm: contaba **posiciones**. **Un pad no es una red.**

## 2. `J14` es una ENTRADA del micro. La salida de talanquera es `J15`

**`J14` p1 = `PB0`, entrada de 3,3 V, sin opto y sin diodo** (`R64` 10 kOhm + `C25` 100 nF a la
bornera: antirrebote RC de 1 ms **en la placa**). `J14` p2 son **3,3 V**, el nudo de `J16` p4/p7/p9/p11.

> 🔴 **Un rele cableado a `J14` se desconecta ANTES de energizar nada.** La salida de la talanquera
> es **`J15`** — `PB2` -> `R70` 220 / `R69` 10K -> opto `TLP127` (`U15`) -> MOSFET `IRLZ44N` (`Q10`)
> -> bornera. `J15` p1 = 12 V, `J15` p2 = **drenador de `Q10`**.

- **`D-27` (2), 11/09: `J14` queda LIBRE, SIN CABLEAR** — el fin de carrera **no se instala** aqui.
- ⚠️ **Mientras el firmware lea `PB0` como `CAM_DEMANDA_PIN`, en `J14` no se conecta NADA** — sigue
  leyendolo en las dos puntas (`SPEC_8` §2). Vacio, `R64` lo deja en **0 V** (`J14` **MEDIDO EN
  COBRE**, pasos 17-18 del banco 03-04/09).
- ⚠️ **`J15` p2 NO es masa**, aunque un esquema de guia lo rotulara «GND (Q10)»: con `Q10` abierto
  esta a **~12 V** (`D-25`).

## 3. `J16` p5 y p8 estan VACIOS: desde `D-44` el firmware ya NO los lee — y NO se cablean

> 🔴 **Regla de montaje, no cautela: NADA se cablea en `J16` p5 ni p8, y no se puentean «para
> probar».** La regla **sigue en pie**; lo que cambio el 14/09 y el 02/10 es **el motivo**, y son dos:
>
> 1. **El firmware que hay DENTRO del poste puede ser anterior a la retirada.** Un equipo sin carga
>    verificada de un firmware posterior al 14/09 **sigue componiendo secuencias con un puente**:
>    `A.A.A` entra al Modo Automatico **sin ninguna guarda** —abre paso—, `B.B.B` pone ambar y
>    `A.B.A.B` mete al poste en Degradado. **Que firmware lleva cada equipo lo dice `ESTADO.md`, no
>    esta spec**, y el instalador no lo puede ver desde la bornera (`CLAUDE.md` §3: se exige la CARGA,
>    no el commit).
> 2. ~~**El pin sigue LEIDO en el firmware de hoy**~~ → **cerrado por `D-44` (`f9cad1f`, 02/10; sin banco):**
>    en el fuente ya no hay lector (tabla de abajo, `SPEC_1` §12.2). **En campo manda lo CARGADO:** el
>    motivo 1 sigue mientras un equipo lleve firmware anterior.
> 3. **Es una entrada directa a una pata del micro, sin nada en medio** (§5), **a poco mas de un
>    milimetro de la red de 12 V** (§1).

**Lo que el firmware del arbol HACE con esos dos bornes** — MEDIDO leyendo el fuente de las dos puntas el
02/10/2026 sobre `f9cad1f`; **no ejercido en ninguna tarjeta**:

| | simbolo | que produce un flanco en p5/p8 |
|---|---|---|
| la lectura | `botones_setup()` declara `J16_P5_SIN_USO`/`J16_P8_SIN_USO` (`PB9`/`PB13`, antes `BOTON1`/`BOTON2`) como `INPUT` pelado; el reposo lo fija el pull-down de la placa. **Nadie los lee**: `botones_actualizar()` solo llama a `camaras_actualizar()` | **nada**: no hay lector |
| ~~las secuencias del mando~~ | ~~`mando_registrarPulso()` desde `botones_actualizar()`~~ — la llamada se corto el 14/09 (`ccca294`) y el modulo del mando salio entero de las dos puntas ese mismo dia (`f57a401`) | **ninguna secuencia**: no queda reconocedor |
| ~~lo que queda consumiendo el flanco~~ | ~~`botonArriba()` / `botonAbajo()`, `menu_loop()`, `modo_hora_loop()`~~ — salieron con `D-44` (`f9cad1f`), con `botonAceptar()`/`botonCancelar()` y el Modo Hora | **nada** |

Ya no existen en el fuente `mando_registrarPulso()`, `mando_ambarLocal()`, `semaforo_senalEnCurso()`,
`botonArriba()`, `botonAbajo()`, `menu_loop()` ni `modo_hora_loop()`.

> ⬇️ ~~De `mando_ambarLocal()` cuelgan tres vetos en `Esclavo/src/main.cpp`; retirar su armador los dejaria ABIERTOS, y por eso el codigo no se toca~~
> → **MEDIDO el 15/09 sobre los dos commits: ningun veto quedo abierto.** La bandera **solo** se armaba
> desde una secuencia del mando, asi que al cortar los pulsos valia `false` para siempre. Las tres guardas
> del bucle del Esclavo eran «bandera del mando **y** ambar de la app» y quedan en **solo el ambar de la
> app** —la misma respuesta, porque el primer termino ya era siempre verdadero—; la guarda de la
> reanudacion diferida del Degradado y la rama de `CANCELAR_AMBAR` que contestaba «queda el del mando»
> **eran inalcanzables** y salieron. **El veto que sigue vetando es el de la app** (`SPEC_2` §2.3).

## 4. 🔴 LA CAMARA FRENA LA BARRERA — **este aviso se mudo ENTERO a `SPEC_8` §1**

**Lo unico que se afirma de eso desde aqui es cobre: `J16` p10 y p12 son las dos camaras (§2.1) y
`J15` es la pluma (§4). El veto, el retardo de 3 s y el aviso son `SPEC_8`, y no se resumen aqui.**

# 1. El reparto, en una frase

**El STM32 sigue siendo el controlador del semaforo. El ESP32 es un modulo de expansion colgado de un
puerto serie (`J17`, `PB6`/`PB7`, 9600 8N1): aporta reloj `DS3231` y Bluetooth, y NO manda sobre las
luces.** Lleva **fuente propia desde 12 V** y no cuelga de los 3,3 V de `J17` p6/p8: ese riel es el
mismo que alimenta al STM32 del semaforo, y **el accesorio no puede tumbar al que manda** (`17_` §1.5).

# 2. La tabla de conectores — vivo, muerto o libre

**La columna «estado» esta MEDIDA hoy sobre `{Maestro,Esclavo}/include/pines.h` y `src/*.cpp`.**
⚠️ **No existen `camara.cpp` ni `talanquera.cpp`:** la camara vive en `botones.cpp`, la pluma dentro
de `semaforo.cpp`.

| bornera | pin del micro | que es | estado |
|---|---|---|---|
| `J3` `J4` `J5` | `PA0` `PA1` `PA2` | Rojo 1 / Amarillo 1 / Verde 1 | 🟢 **VIVO** — `escribirPines()` |
| `J6` `J7` `J8` | `PA3` `PA4` `PA5` | Rojo 2 / Amarillo 2 / Verde 2 | 🟢 **VIVO** — `escribirPines()` |
| `J11` · `J9` | `PA6` · `PA7` | Rojo peaton · Verde peaton | 🔴 **DECLARADOS Y MUERTOS** |
| `J13` | `PB1` | Buzzer | 🔴 **DECLARADO Y MUERTO** |
| `J15` | `PB2` | **Talanquera** — opto `U15`, MOSFET `Q10` | 🟢 **VIVO** — dentro de `escribirPines()` |
| `J12` | `PB10` TX · `PB11` RX · `PB12` DE/~RE | Radio LoRa (`USART3`) | 🟢 vivo — SPEC 2 |
| `J10` | `PA9` `PA10` · `PA8` DE/~RE | RS485 «IN» / telemetria | 🟡 vacio hoy |
| `J14` | `PB0` | **ENTRADA** — `CAM_DEMANDA_PIN` | 🟡 **LIBRE, sin cablear** (`D-27`) — pero **leido** |
| `J16` | ver abajo | ~~mando `A`/`B`~~ p5/p8 vacios + **las dos camaras** | mitad vivo, mitad libre (sin lector desde `D-44`, §3) |
| `J17` | `PB3`-`PB7` | LCD retirada -> **ESP32** (p2 = `PB7` RX, p3 = `PB6` TX) | 🟢 vivo |
| `J1` · `J2` | — | alimentacion · **SWD** | — |

> 🔴 **TRES SALIDAS NO EXISTEN MAS QUE EN LA TABLA (MEDIDO 02/09, reconfirmado hoy).**
> `grep -rn "ROJO_PEATON\|VERDE_PEATON\|BUZZER" Maestro/src Esclavo/src` devuelve **UNA sola
> coincidencia en las dos puntas, y es un COMENTARIO**. Ni un `pinMode`, ni un `digitalWrite`.
> **Si alguien cablea una cabeza peatonal a `J11`/`J9` o un zumbador a `J13`, no se enciende nunca y
> no hay mensaje de error**: el equipo parece sano — la averia mas cara de diagnosticar. **No se
> venden ni se incluyen en una entrega como funciones del equipo.** El
> cobre **si** esta: tres etapas completas, el mismo molde que `J15`; encender una cuesta **16 B de
> flash** de suelo (desensamblado del `.elf`, 05/09). Gastarlas es **`17_` §3.10, abierta**. 🟢 **Y ya
> NO tienen cuarto pretendiente: `D-32` (4), 13/09, cierra `D-14` para este despliegue** — el ancla vive
> en los dos `pines.h`, justo encima de estos tres pines, porque son sus tres candidatos.

## 2.1 `J16`, posicion por posicion

> 🛑 **La columna «red» es el NOMBRE DE LA RED EN KiCad, NO el papel del pin** — se bautizaron asi
> cuando la placa se diseno con botonera. **Quien lea `/Boton3` como «boton 3» y cablee un pulsador
> esta cableando en el borne de una camara.**

| `J16` | red | GPIO | que es HOY | **MEDIDO EN COBRE, paso 20, 03/09** |
|---|---|---|---|---|
| p1 | `/12V` | — | 🔴 **12 V crudos. SE TAPA** (`D-4`) | 12 V confirmados (pasos 3 y 4) |
| p2 | `GND` | — | **la unica masa del conector** | — |
| p3 · p6 | **sin red** | — | — | — |
| p4 · p7 · p9 · p11 | `3,3 V` | — | el borne contra el que se cierra el contacto | mismo nudo que `J14` p2 |
| p5 | `/Boton1` | `PB9` | 🟡 **LIBRE y sin lector** (`J16_P5_SIN_USO`, `D-44`; ~~`botonArriba()`~~) — **no se cablea**, §3 | **9,92 kOhm** a masa · 11,28 kOhm a 3,3 V · **0,6 V** |
| p8 | `/Boton2` | `PB13` | 🟡 **LIBRE y sin lector** (`J16_P8_SIN_USO`, `D-44`; ~~`botonAbajo()`~~) — **no se cablea**, §3 | **9,92 kOhm** · 11,28 kOhm · **0,6 V** |
| p10 | `/Boton3` | `PB14` | 🎯 **`CAM_C_PIN` — CAMARA 1 del poste** (`D-25`) | **9,93 kOhm** · 11,29 kOhm · **0 V** |
| p12 | `/Boton4` | `PB15` | 🎯 **`CAM_D_PIN` — CAMARA 2 del poste** (`D-25`) | **9,94 kOhm** · 11,31 kOhm · **0 V** |
| p13-p16 | sin red | — | pads que existen en el cobre y no en el esquema | — |

**El pull-down de 10 kOhm que declaraba el netlist es REAL y esta en las cuatro posiciones**
(`R65`-`R68`, con su 100 nF). Con 3,3 V en la posicion contigua, **el gesto que el conector pide es
cerrar el contacto contra los 3,3 V: entrada activa en ALTO, para los cuatro pines y sin excepcion.**
🛑 **El gesto de prueba es contra el 3,3 V contiguo —`p10` contra `p9`, `p12` contra `p11`— NUNCA contra masa**
*(el banco del 03/09 lo hizo tambien en `p5`/`p8`; en un equipo instalado esos dos no se puentean, §3)*: en todo `J16`
hay **una sola masa** (`p2`). Y **`p1` tapado antes de nada.**

# 3. Las camaras — **el cobre**

**Camara comprada: Hikvision `DS-2CD2683G2-IZS`** (`D-10`), **las CUATRO compradas** (`D-27` (1)),
**dos por poste** (`D-25`, 11/09: *«mantener estas conexiones como definitivas»*).

**El contrato es UN CONTACTO SECO y nada mas** (`D-12`): no hay red, no hay imagen, no hay video y no
hay analitica en el controlador — cero `WiFi`, `HTTPClient`, servidor ni ONVIF en el ESP32; el STM32
solo lee un pin. **Toda la inteligencia vive en la CONFIGURACION de la camara**, la del manual del
modelo comprado (`D-27` (3)). La camara **si graba en su propia microSD** (hasta 512 GB, ficha
oficial): el soporte de accidentes existe **en la camara, no en el firmware**.

**Cableado por poste** (`D-25`), cada camara por el **contacto seco de su salida de alarma** (`1A`/`1B`), que al detectar pone 3,3 V en el pin:

| camara | del borne | al borne |
|---|---|---|
| **camara 1** | `J16` **p9** (3,3 V) | `J16` **p10** (`PB14`, `CAM_C_PIN`) |
| **camara 2** | `J16` **p11** (3,3 V) | `J16` **p12** (`PB15`, `CAM_D_PIN`) |

## 3.1 Las DOS entradas hacen EXACTAMENTE LO MISMO — **`SPEC_8` §2**, con la tercera declarada

## 3.2 Una camara muerta desde la instalacion NO SE DETECTA SOLA — **`SPEC_8` §4** (su choque, §7.2)

## 3.3 Lo que la placa pone y lo que no

Las tres entradas son **`INPUT` PELADO y ACTIVAS EN ALTO**. `R64`/`R67`/`R68` son 10 kOhm a masa;
`C25`/`C28`/`C29`, 100 nF: **sobre el netlist las tres llevan el MISMO RC**. La asimetria publicada
(«`PB14`/`PB15` sin condensador») es **falsa** (11/09), y el comentario de `camara_leerPin()`
**todavia la dice** (§7). **Las resistencias estan medidas en cobre; los condensadores, NO.**

# 4. La talanquera — **la cadena electrica**

> 🔴 **Que HACE la pluma —cuando sube, cuando baja, quien la veta, quien la saca de servicio y que
> pasa en averia— es `SPEC_8`. Aqui solo el cobre por el que sale la orden.**

**Cadena:** `PB2` -> `R70` 220 / `R69` 10K -> opto `TLP127` (`U15`) -> MOSFET `IRLZ44N` (`Q10`) ->
bornera **`J15`** (p1 = 12 V, p2 = drenador). **`D-25` / `D-27` (4): `J15` p1/p2 a la bobina de un
rele, y los contactos del rele a `OPEN`/`COM` de la centralita.** **Lo que el COBRE garantiza, pin a
pin** (la regla completa es SFTY-28, y su tabla luz -> pluma es **SPEC 1 §2**):

- **La orden sale por la MISMA puerta que las luces** — dentro de `escribirPines()`, con el `verde`
  ya enclavado por SFTY-2. Una barrera con dos puertas no es una barrera.
- **Equipo SIN ENERGIA: el pin cae a LOW, el MOSFET no conduce, la pluma BAJA** — el fallo seguro. La
  compra pide **actuador con retorno por muelle o gravedad**: eso el software no lo garantiza.
- 🔴 **Y por eso «sacar la barrera de servicio» (`SPEC_8` §6) NO garantiza que el brazo se quede
  arriba si se va la luz:** sin energia la salida cae y el actuador baja por su muelle o por su peso.
  **El interruptor manda mientras haya corriente**; el cobre manda cuando no la hay.

⚠️ **MEDIDO EN COBRE (banco 04/09):** `J15` dio *«en rojo 0 V, en ambar 12 V»*. La causa se explico
el 05/09: **nueve de los diez drenadores llevan pull-up de 1 kOhm + LED al riel de 12 V** (`R23`,
`R28`, `R33`, `R38`, `R43`, `R48`, `R53`, `R58`, `R63`, `R73`), **en el cobre, no en el conector**.
**El borne de potencia en reposo esta a ~12 V, no a 0 V**, con ~10 mA por la cuenta `(12-2)/1k`.

> 🔴 **Un MOSFET a masa NO es un contacto seco.** El proyecto usa «contacto seco» con razon para las
> **entradas** de camara; **las salidas no lo son.** Y **el opto NO crea masa separada**: hay **UNA
> sola red `GND`** (103 pads, plano en las dos capas), con el catodo del LED del opto y la fuente del
> MOSFET dentro. **Lo colgado de esas borneras comparte la masa del controlador** — y sus 12 V.

# 5. La proteccion de esta placa es ASIMETRICA — **MEDIDO en el banco del 03-04/09**

| | cuantas | que llevan en medio |
|---|---|---|
| **Salidas** de campo | **9** *(⚠️ `17_` se corrige a si misma: son **DIEZ** cadenas, `Q1`-`Q10` con `U6`-`U15` — §7)* | `220 Ohm` en serie **+ opto `TLP127`** |
| **Entradas** de campo | **5** | 🔴 **nada.** Del borne **directo** a la pata del STM32 |

> **La tarjeta esta blindada contra lo que ella hace y desnuda contra lo que le hacen.** Cualquier
> tension que aparezca en un borne de entrada —un cruce de hilos en el armario, un cable de camara
> que roza `p1`, una descarga por la linea de una camara que vive fuera del gabinete— entra **entera**
> en una pata del micro que gobierna el semaforo.

**La propuesta para V2 —`2K2` en serie por entrada— es de `17_` §3.6, es del responsable, y NO se
decide aqui.** Su cuenta: con 12 V en el borne, **3,6 mA** (por debajo de los 5 mA/pata del
datasheet); nivel ALTO con la camara cerrada, **2,70 V** contra un `VIH` de **2,31 V**. 🔴 **Con
`4K7`: 2,24 V, POR DEBAJO de `VIH` — ya no leeria la camara.** No es «mas proteccion, mejor»: **hay
un techo y esta cerca**, y lo fija el pull-down de 10 kOhm que la placa ya trae.

# 6. `SIN VERIFICAR` — lo que el proyecto declara sin haberlo medido nunca

**La tabla se conserva ENTERA y con su numeracion**, porque se cita desde fuera por numero de fila.
Lo que no esta medido de la **conducta** —no del cobre— es `SPEC_8` §7.

| # | lo que nadie ha comprobado |
|---|---|
| 1 | **Ninguna camara AcuSense se ha conectado NUNCA a este equipo.** Lo que se cablo en el paso 21 fue **un puente de `p10` a `p11`**, no una camara |
| 2 | **Cual de los dos estados de la salida de la camara (NO/NC) significa demanda.** Es parametrizacion, y sigue **SIN TOMAR** |
| 3 | **`p12` no se ha cableado NUNCA**, ni en banco — y es el borne **mas cercano** a la red de 12 V (1,359 mm) |
| 4 | **La concesion de paso por camara.** El cableado si (paso 21, sin demandas fantasma); que el equipo **conceda** depende del Modo Automatico, que no se pudo seleccionar sin app |
| 5 | **Que `J9`, `J11` y `J13` esten REALMENTE SOLDADOS.** El esquematico los da `in_bom=yes`, `dnp=no`, `on_board=yes`; **nadie los ha mirado en cobre.** `J15`, el gemelo, si funciono: eso los hace **probables, no ciertos** |
| 6 | **Los ~12 V de reposo y los ~10 mA de las borneras de potencia.** Leidos del cobre, **no medidos con multimetro.** Se cierra en dos minutos midiendo p2 contra masa con la bornera desconectada |
| 7 | **Si el `D21` sin conectar de `J8` (`VERDE2`) es defecto o decision.** Su catodo esta sin conectar en esquema y cobre (red `unconnected-(D21-K-Pad1)`, cero pistas): **`J8` p2 FLOTA** en reposo mientras los otros nueve suben a 12 V. **No hay ni una nota en el repositorio.** Se cierra comparando `J8` p1-p2 contra `J7` p1-p2 |
| 8 | **Los condensadores `C25`/`C28`/`C29`.** En el netlist si; **en cobre, sin medir** — solo las resistencias (paso 20) |
| 9 | **El voltaje de `p5`/`p8` con el puente puesto.** El dato se perdio con el incidente de N-116 y **no se retoma sobre la Maestro** mientras siga con el corto |
| 10 | ~~**Que el mando `A`/`B` funcione con la polaridad corregida.**~~ → **sin sujeto desde el 14/09: el mando salio del firmware** (§3). Lo que sigue sin verificar es lo contrario y es de campo: **que firmware lleva cada equipo instalado**, porque con uno anterior un puente en p5/p8 **si** compone secuencias (`ESTADO.md`) |
| 11 | **La causa de N-116** — la tarjeta Maestro tiene un corto entre 3,3 V y `GND` **medido**, arranca ~30 s y se calienta. 🛑 **No se reenergiza.** El firmware queda descartado **por censo** (ninguna salida toca un pin de `J16`); eso **no nombra a nadie mas** |
| 12 | **El `2K2` de §5: no se ha probado en ninguna tarjeta.** Es aritmetica sobre el datasheet y sobre el pull-down medido, **no una medida** |
| 13 | **Que `PB3`/`PB4`/`PB5` se puedan usar con el ESP32 puesto.** Libres y en alta impedancia, con pista a `J17` p4/p1/p5 — **el mismo conector donde vive el modulo**. Usarlos **no cuesta el SWD** (`pinF1_DisconnectDebug()` hace `NOJTAG`, no `SWJ_DISABLE`) |
| 14 | **El nombre de `J17` p3.** La red del esquematico se rotula `RS(A0)` y el firmware lo llama `LCD_PSB`: **los dos no pueden ser ciertos a la vez.** Se cierra siguiendo el hilo hasta la pata rotulada, no leyendo mas codigo |
| 15 | **El pico de 500 mA del ESP32.** Es ficha y Manual 15, no medida — y en banco el modulo se alimento **por USB**, no por la fuente 12 V -> 5 V definitiva |
| 16 | **El `Y2` de la segunda tarjeta.** N-37 midio uno; el otro sigue sin diagnosticar |
| 17 | **Que por el enlace `J17` hable alguien.** El enlace fisico si (patas 42/43, masa comun < 50 mV, `GPIO17` a 3,3 V); **el Bluetooth no subio en toda la sesion de banco** |
| 18 | **Que espera electricamente el `ALARM IN` de la camara** (`D-14`): **sin tension, sin corriente**, y las palabras *«dry contact»* y *«relay»* **no aparecen en las 110 paginas** del manual del fabricante. Conectar una salida que en reposo esta a 12 V, con masa comun, a una entrada cuyo regimen no conocemos **no es un cableado: es un ensayo** — con multimetro y **antes** de escribir firmware. 🟢 **13/09: no urge, y por eso sigue aqui y no en la pagina 1.** `D-32` (4) decide que **`D-14` NO SE INSTALA en este despliegue** —medido sobre `Camaras_Sisga_4x.html`, la guia que sigue el instalador: solo cablea la SALIDA de alarma (`1A`/`1B`), nunca la entrada—. **La decision no borra la capacidad: dice que hoy no se monta**, igual que `D-27` (2) con `J14`. El dia que se instale, este ensayo va primero |
| 19 | **Que la sonda de la medida de `J15`** *(«en rojo 0 V, en ambar 12 V»)* estuviera entre p1 y p2. Es **deduccion** a partir de `TALANQUERA_ABRIR = HIGH`, no una lectura del informe |
| 20 | **Casi todo el resto del cobre de esta tarjeta.** El censo del 05/09 es lectura del `.kicad_pcb`, **no punta sobre la placa** |

> 🔴 **La unica medida de campo que hay no lo mejora:** la cinta del Maestro del Sisga (10/09,
> `evidencia/2026-09-10_Sisga_179DB0_cinta_tramas.txt`) trae **253 tramas con `CAM:` y las 253 dicen
> `CAM:?`**: en esos veinte minutos **ninguna camara le dio un flanco al equipo**. Con `D-25` son
> **cuatro** las que faltan por ver en cobre.

# 7. Choques que esta spec REPORTA y no resuelve

Manda la medida de cobre; el choque se escribe, no se arregla desde aqui (`CLAUDE.md` §12).

1. **`D-27` deja `J14` libre y el firmware sigue leyendo `PB0` como `CAM_DEMANDA_PIN`** en las dos puntas
   (aviso 2). Inofensivo con el borne vacio; **deja de serlo el dia que alguien cablee ahi.**
2. **La exencion del vigilante se escribio PORQUE `p12` iba vacio a proposito, y `D-25` le quito el
   motivo** (`CLAUDE.md` §6: una excepcion es una AFIRMACION sobre el codigo, y esta caduco). Sigue en
   el firmware: **una camara 2 muerta desde la instalacion no la avisa nadie** (`SPEC_8` §4). Pendiente EN
   FIRMWARE, no aqui.
3. **El comentario de `camara_leerPin()` en `botones.cpp` de las dos puntas dice que `PB14`/`PB15`
   «no llevan mas que el 10K de `R67`/`R68`».** El netlist trae `C28` y `C29` (100 nF). **Gana el
   cobre**; el comentario esta caducado y **no se toca desde esta spec**.
4. **`17_` se contradice en la cuenta de salidas de campo: «9» en tres sitios vivos y «DIEZ» en uno**
   (05/09). `pines.h` es explicito: **DIEZ MOSFET y DIEZ optos, `Q1`-`Q10` con `U6`-`U15`.** La
   asimetria del §5 no cambia de signo.
5. **`D-25` dice «las camaras no tocan el ciclo» y en Modo Inteligente SI alargan una fase** (con
   techo, `TECHO_POR_SUELO`). Es el conflicto (2) que `D-27` **no** cerro. El ciclo es SPEC 1.
6. **`CLAUDE.md` §2 enumera ocho pines de luz y `escribirPines()` mueve SEIS** mas la talanquera: la
   regla es **vacuamente cierta** para los dos peatonales (`N-96`; §2 de arriba y SPEC 1 §1).

*Decisiones recogidas: `D-1`, `D-2`, `D-3`, `D-4`, `D-10`, `D-12`, `D-13` (lo no derogado), `D-14`,
`D-25`, `D-27`, ~~`D-32` (1)~~ (derogada por `D-30`, reafirmada el 14/09), `D-32` (4), `D-30`. Abiertas que nombra sin resolver: `A-2`, `17_` §3.6 y §3.10. Las MEDIDAS
son de `17_Arquitectura_28-08_y_Decisiones_Abiertas.md`, que **gana a este fichero**; lo decidido vive
en las spec, y `DECISIONES.md` es su indice. El firmware se remidio contra `{Maestro,Esclavo}/include/
pines.h` y `src/{semaforo,botones,main}.cpp` el 12/09/2026; **§3, contra `botones.cpp`, `menu.cpp`,
`modo_hora.cpp` y `main.cpp` de las dos puntas el 15/09/2026**. **La conducta de camara y barrera se
partio a `SPEC_8` el 14/09/2026** (`roadmap.md` 1.45).*

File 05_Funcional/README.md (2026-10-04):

# 📁 DOCUMENTACIÓN FUNCIONAL Y MANUALES DE CAMPO (05_Funcional)

Esta carpeta centraliza los manuales de operación, guía de cableado, protocolo de pruebas y configuraciones de radio para el personal funcional y técnicos en terreno.

**Última revisión de este índice: 7 de septiembre de 2026** *(11/09: tocado sólo para `D-27` —
`J14` libre, cuatro cámaras compradas, la configuración de cámara sale del manual del modelo—)*.
🔴 **Y la regla que hay que leer antes que ningún manual: mandan las `SPEC_0..SPEC_8` de esta carpeta.**
Los documentos de esta carpeta congelan la foto del día en que se escribieron; esa tabla es la que se
mantiene. **Donde un manual y la SPEC no digan lo mismo, gana la SPEC** ([`DECISIONES.md`](../DECISIONES.md)
es su índice) — y si la contradicción es sobre **cobre, conectores o pines**, gana además
[`17_Arquitectura_28-08_y_Decisiones_Abiertas.md`](17_Arquitectura_28-08_y_Decisiones_Abiertas.md),
que es donde se anotan las medidas.

---

> ## 🚨 EMPIECE POR AQUÍ
>
> **0.** **Antes que nada, abra la SPEC (`SPEC_0`).** Manda sobre todos los documentos de esta carpeta;
> [`DECISIONES.md`](../DECISIONES.md) es su índice de lo ya contestado: donde un manual no diga lo mismo,
> **gana la SPEC**.
> **1.** Reconfigure las **2 radios** —enlace directo, **sin repetidor**— a `2.4 kbps` de Air Data
> Rate → **[`4_Manual_Configuracion_Radios.md`](historico/4_Manual_Configuracion_Radios.md)**
> *(~~«las 4 radios»~~ — **corregido el 07/09**: la configuración vigente son **2 radios en enlace
> directo**, como dice la cabecera de ese mismo manual y `CLAUDE.md` §3. El repetidor está fuera de
> la configuración vigente. ~~⚠️ El CUERPO de `4_Manual` todavía dice «cambiar en las 4 radios» en
> dos sitios: haga caso a su cabecera.~~ ✅ **Los dos sitios se corrigieron en el propio manual el
> 07/09** — ya no hay que hacerle caso a la cabecera contra su cuerpo.)*
> **2.** Cargue el firmware **en las dos tarjetas, la MISMA versión**
> → [`2_Manual_Hardware_y_Pruebas.md`](historico/2_Manual_Hardware_y_Pruebas.md) §4
> **3.** Ejecute el checklist y firme el acta
> → **[`3_Protocolo_Pruebas_Rigurosas.md`](historico/3_Protocolo_Pruebas_Rigurosas.md)**
> **4.** 🔧 **Si va a una SESIÓN DE BANCO, la hoja vigente es la
> [`Pruebas_Funcional_2026-10-04.html`](Pruebas_Funcional_2026-10-04.html)** — se abre en
> el navegador, **se rellena y se devuelve en PDF**. *(El `ENCARGO_SESION_BANCO.md` de 29 pasos se
> archivó el 07/09 en [`historico/`](historico/ENCARGO_SESION_BANCO_ARCHIVADO_07-09.md): se conserva
> como **acta** de la 1.ª noche, no como guion. **Un solo encargo vigente.**)*
> ⛔ *(Las dos guías «de 4 cámaras del Sisga» del 10/09 se **RETIRARON el 11/09** a
> [`historico/`](historico/): afirmaban que una cámara protege la pluma y que la pluma solo sube con
> verde, y las dos cosas son falsas en el firmware. ~~La cámara se cablea por el **Manual 9** y la
> decisión vigente `D-13`: **una por poste**.~~ Veredicto completo en `roadmap.md` §3.16.)*
>
> **5.** 📷 **Si va a montar las CÁMARAS o la TALANQUERA del Sisga, la guía de campo es la
> [`Camaras_Sisga_4x.html`](Camaras_Sisga_4x.html) — versión corregida del 11/09**, que sustituye a
> la del 10/09 y empieza por su **fe de erratas**. ✏️ **11/09, `D-25`:** las conexiones de aquella
> guía quedan **definitivas**: **cuatro cámaras, DOS POR POSTE** —cámara 1 entre `J16` p9 (3,3 V) y
> **p10** (`CAM_C_PIN`), cámara 2 entre `J16` p11 (3,3 V) y **p12** (`CAM_D_PIN`)— y la
> **talanquera en `J15`** por relé a la entrada `OPEN` de la centralita. La configuración de cada
> cámara, por el **Manual 9** y `D-13` (que sigue vigente en todo lo demás). Lo que el que cablea
> tiene que saber, medido en el firmware: **las dos cámaras de un poste hacen LO MISMO**, **ninguna
> frena la pluma** (baja con un coche debajo) y **la app dice `OK — las dos ven` en cuanto detecta
> CUALQUIERA de las dos**, aunque la otra no haya detectado nunca: **cada cámara se comprueba con
> el multímetro en su borne** (paso 11 de la guía).
>
> El paso 1 **no es opcional**: es la corrección de la causa raíz del fallo de comunicación que aparecía
> al paso de cada ciclo, en los tres modos, y del repetidor que no enlazaba. Sin él, el firmware nuevo
> no resuelve el síntoma.

---

> ## 📌 EL SISTEMA CAMBIÓ EL 01/08/2026 — LEA ESTO ANTES DE USAR LOS MANUALES
>
> Los manuales se escribieron cuando el equipo tenía **4 opciones de menú en una lista plana y ningún
> modo por reloj**. Ya no es así:
>
> | Novedad | Dónde está documentada |
> |---|---|
> | ~~**Menú en dos niveles** (`CONFIGURACION` como cuarta opción)~~ ⛔ **`D-17.bis` (05/09): LA PANTALLA Y EL MENÚ SE RETIRAN DEL EQUIPO.** *(Del equipo, no del código: `lcd.cpp` compila y `Validacion_LCD` sigue en `271/271` sobre un framebuffer del PC.)* **Y ya no se podía navegar igualmente:** `botonAceptar()`/`botonCancelar()` son `return false;` | `1_Manual_Usuario.md §3` |
> | ~~Pantalla **AJUSTAR HORA** y **sincronización horaria por radio**~~ ⛔ **DOS COSAS CAÍDAS:** la pantalla, por `D-17.bis` *(`MODO_HORA` tenía su único armador en el menú)*; y el reloj, por **`D-9`/`D-15`** — **la hora la lleva el `DS3231` del `ESP32` de cada poste**, el STM32 no tiene ninguno y **ya no contesta a `SET_RTC`**. Se consulta con **`CMD:LEER_RTC`** (`D-17`). 🔴 **07/09 — `D-20` corrige la SEGUNDA mitad: la sincronización por radio NO está caída, está sin destinatario.** Con `D-20`, **la autoridad de la hora es el ESP32 y es UNA sola** —la del poste 1—, y como los dos ESP32 no se hablan, **la hora vuelve a viajar por la radio**: `ESP32-M -> STM32-M -> radio -> STM32-E` ~~`-> ESP32-E`~~, con los STM32 de **carteros**. ~~**Y la app NO pone la hora en el poste 2, nunca.** *(Decidida y **SIN CONSTRUIR**.)*~~ 🔵 **11/09 — `D-26`: la hora la manda el ESP32 de CADA poste**; con radio el poste 2 hace caso al Maestro, **sin radio toma la de su propio ESP32**, y **al poste 2 sí se le pone la hora desde el teléfono** (es lo que se hace cuando cae la radio). Construida en `68dd2c5`, **sin banco**. `14_Manual_App_Movil_IOT_VIAL.md` §5.3.bis | `11_Manual_Instalacion_RTC_DS3231_Bateria.md` §4.1 · `4_Manual_Configuracion_Radios.md` §5 |
> | 🔴 ~~**`D-20` — la hora del POSTE 2 se pone en la PUESTA EN MARCHA, no durante la avería** *(con la radio muerta no hay camino a su reloj; …)*~~ **`D-26` (11/09) — la hora se pone en LOS DOS postes en la puesta en marcha, y con la radio caída se va al poste 2 a ponérsela** *(sin radio su controladora toma la de su `DS3231` — **perder la radio no es perder la hora**)*. **Y dos alarmas: `FALLO_RF` (radio) y `HORA_ESP32` (el ESP32 no le llega a su controladora)** | `1_Manual_Usuario.md §3` · `14_…` §5.3.bis · `11_…` (apartado final) |
> | **MODO DEGRADADO** — operación por reloj sin radio | **`8_Procedimiento_Modo_Degradado.md`** |
> | ~~**Mando de 2 canales (`A`/`B`)** y sus secuencias desde el piso~~ ⛔ **`D-1` (05/09): EL MANDO NO EXISTE.** *Su código se conserva a propósito —`mando_ambarLocal()` sostiene el veto de SFTY-21— pero no hay emisor, ni pulsadores, ni receptor RF.* **El equipo se opera SÓLO POR APP** (`D-16`) | `1_Manual_Usuario.md §6` · `2_Manual_Hardware_y_Pruebas.md §6` |
> | ~~El **Esclavo ahora tiene pantalla y menú propios**~~ ⛔ **`D-17.bis`: se retiran del equipo, en las dos puntas.** Lo que el Esclavo tiene hoy son **siete comandos por app**, uno de ellos `SET_MODO:DEGRADADO` (`D-18`) | `1_Manual_Usuario.md §7` |
> | **Pila `CR2032`** del reloj en ambas tarjetas — ⚠️ **es la del `VBAT` del STM32, cuyo cristal `Y2` está MUERTO.** No confundir con la pila del `DS3231` del `ESP32`, que es **otra pila en otro equipo** y puede tener que ser `LIR2032` recargable | `2_Manual_Hardware_y_Pruebas.md §5` · `11_…` §5.2 |

> ## 🛑 LOS TRES AVISOS DE COBRE QUE NO PUEDEN FALTAR EN NINGÚN DOCUMENTO DE ESTA CARPETA
>
> *(Añadidos aquí el 07/09 porque este README es el que dice «EMPIECE POR AQUÍ», y los tres hieren a
> una persona o destruyen una tarjeta. La fuente es `DECISIONES.md` y `17_Arquitectura…md`.)*
>
> 1. 🔴 **`J16` p1 lleva 12 V CRUDOS** a un conector de señal **directa** al micro —sin opto, sin
>    serie, sin clamp—. **Taparlo es OBLIGATORIO en cada equipo que se monte** (`D-4`, `N-120`), **no
>    una cautela de banco**. Un contacto de `p1` a `p10` o `p12` mete 12 V en una pata de 3,3 V.
> 2. 🔴 **`J14` es una ENTRADA del micro** (`PB0`, con `R64` + `C25`). **La salida de talanquera es
>    `J15`** (`PB2` → opto `U15` → MOSFET `Q10`). **Un relé de 12 V cableado a `J14` destruye el
>    STM32 que gobierna el semáforo — y además la pluma no se movería.** ⚠️ **Y `J16` y `J17`
>    comparten footprint y son idénticos a la vista:** antes de enchufar nada, **multímetro en la
>    posición 1 contra masa — si da ≈12 V es `J16`.**
> 3. 🔴 **`J16` p5 y p8 están VACÍOS y el código del mando SIGUE leyendo sus flancos** (`D-1`,
>    `A-2`). **Nada se cablea ahí, ni para probar:** cualquier cosa compone secuencias del mando sin
>    que nadie lo pida —`B·B·B` es ámbar local, `A·B·A·B` es entrar en Degradado—, y **`p4` es
>    adyacente a `p5`**, así que un puente corrido una posición pone 3,3 V contra masa: es el
>    candidato del sobrecalentamiento que abortó el paso 29 del banco.
>
> 🛑 **Y la regla de orden, que no es «van en el mismo commit» porque un commit no protege de un
> destornillador: el firmware nuevo tiene que estar CARGADO Y VERIFICADO EN LA TARJETA antes de que
> nadie enchufe nada en `J16`.** Se exige la carga verificada, no el merge.
>
> **La versión que corre en campo hoy es la V8.4**, que **no** incluye nada de lo anterior. Todo lo
> nuevo está construido y validado en simulador, pero **sin prueba de banco ni de campo**. Las
> Secciones 7 a 10 del protocolo de pruebas son su primera verificación física.

> ## ⚠️ SI VA A OPERAR EL MODO DEGRADADO
>
> **Lea completo el [`8_Procedimiento_Modo_Degradado.md`](historico/8_Procedimiento_Modo_Degradado.md) antes de
> tocar nada.** Ese modo da verde **sin confirmación del otro extremo** —con el radio muerto es
> inevitable— y tiene riesgos residuales que el cliente aceptó por escrito. Tres cosas que hay que
> saber de entrada:
>
> - Se activa **en las dos puntas** y **exige verificación visual de ambas**, al entrar **y al salir**.
> - **Se pide POR APP en las dos puntas, con la misma orden:** `CMD:PIN:1234:SET_MODO:DEGRADADO`
>   (`DECISIONES.md` `D-18`). ~~Hoy el Esclavo no tiene receptor de mando: activarlo en esa punta
>   **obliga a subir al gabinete**.~~ 🔴 **Corregido el 07/09: no hay que subir a ningún gabinete, y
>   el mando no existe (`D-1`).**
> - 🛑 **`D-16`: sin teléfono no hay forma de operar el equipo.** No es una avería; es una propiedad
>   declarada del sistema desde que se retiró el mando.
> - **Límite duro de 48 h:** pasado ese tiempo sin resincronizar, el modo **cae solo a ámbar**.

---

> ## 📷 CÓMO DETECTA VEHÍCULOS EL EQUIPO — CORRECCIÓN DEL 28/08/2026
>
> **Este README anunciaba «integración con visión artificial (YOLOv8)». Se corrige, y queda escrito
> qué decía**, porque lo que se borra en silencio se vuelve a proponer.
>
> **Lo que el firmware hace de verdad hoy: lee CONTACTOS SECOS, y nada más.** La analítica de vídeo
> la hace **el DSP de la propia cámara Hikvision AcuSense**; el equipo solo ve un pulso de 1 segundo.
>
> **Desde el 31/08 son TRES entradas por punta, no una** —este README decía *«lee UN contacto seco
> en `PB0`»*—:
>
> | entrada | pin | bornera | antirrebote de placa | estado |
> |---|---|---|---|---|
> | `CAM_C_PIN` | `PB14` | `J16` p10 | ~~❌ ninguno~~ *(pull-down `R67` 10 kΩ ✅; 11/09: el netlist trae además `C28` 100 nF, sin medir en cobre)* | ~~🔵 **AQUÍ VA LA CÁMARA DEL POSTE 1** (`D-2`/`D-3`)~~ → ✏️ **11/09, `D-25`: la CÁMARA 1 DE CADA POSTE**, contra `p9`. ~~NO cablear hasta `M3`~~ — `M3` cerrada el 03/09 |
> | `CAM_D_PIN` | `PB15` | `J16` p12 | ~~❌ ninguno~~ *(pull-down `R68` 10 kΩ ✅; 11/09: el netlist trae además `C29` 100 nF, sin medir en cobre)* | ~~🔵 **AQUÍ VA LA CÁMARA DEL POSTE 2** (`D-2`/`D-3`)~~ → ✏️ **11/09, `D-25`: la CÁMARA 2 DE CADA POSTE**, contra `p11`. **Hace lo mismo que la de `p10`** (`CAM_J16[2]`, un solo bucle en `camaras_actualizar()`). ⚠️ `p12` es el borne con **menos separación a la red de 12 V** (`1,359 mm`, `17_` §1.7): `p1` tapado, trabajo limpio |
> | `CAM_DEMANDA_PIN` | `PB0` | `J14` | ✅ `R64` 10 kΩ + `C25` 100 nF | ~~✅ **cableable hoy**~~ → 🟠 **VIVO Y SIN CÁMARA.** El firmware lo sigue leyendo, pero **`CAM_CIEGA`/`CAM_PEGADA` NO lo vigilan**: es el único borne sin aviso de avería. ~~Reservado a fin de carrera de barrera (`A-2`). 🔴 **CONFLICTO ABIERTO (11/09), del responsable:** `A-2` manda aquí el fin de carrera, pero~~ el firmware **lee `PB0` como cámara de demanda** —el Maestro por nivel en el Modo Inteligente, el Esclavo por flanco y lo manda por radio—, así que un fin de carrera en `J14` **pediría paso cada vez que se mueve la pluma**. ~~Antes de cablear nada aquí, pregunte al responsable~~ → 🟢 **`D-27` (11/09): `J14` LIBRE, sin cablear — el fin de carrera no se instala en este despliegue. En `J14` no se conecta nada** |
>
> 🛑 **Las dos filas de arriba bloqueaban trabajo YA AUTORIZADO, y se tachan con su motivo — 05/09.**
> `M3` se cerró el **03/09 con multímetro** (paso 20 del banco): pull-down real de **10 kΩ** en las
> **cuatro** posiciones de `J16` (`R65`–`R68`), `p10` **9,93 kΩ / 0 V** y `p12` **9,94 kΩ / 0 V** en
> reposo, y el **paso 21** cableó `p10` contra `p11` **sin demandas fantasma**. La medida ya estaba
> publicada en `17_Arquitectura...md` y en `6_Preguntas_Diseno_Funcional.md` §1.1 **desde el 04/09**:
> lo que faltaba era que alguien cruzara los ficheros. **Este README es el que dice «EMPIECE POR
> AQUÍ», así que su copia caducada pesa más que las otras.**
>
> 🔴 **Y lo que esa medida NO levanta: `J16` p1 reparte 12 V CRUDOS** —sin opto, sin serie, sin
> clamp—. **Taparlo es obligatorio en cada equipo que se monte** (N-120), no una cautela de banco:
> un contacto de `p1` a `p10` o `p12` mete 12 V en una pata de 3,3 V.
>
> **Las tres son de DEMANDA y activas en ALTO**: el contacto cierra contra **3,3 V**, no contra masa.
>
> | | |
> |---|---|
> | **NO hay** visión artificial embarcada en el STM32 | 64 KB de flash; el Maestro ya va al ~86 % |
> | **NO hay** YOLO, Raspberry Pi, Jetson ni PC en obra | Descartado **por decisión escrita** en `6_Preguntas_Diseno_Funcional.md` §2: *«Cero Computadores Edge Externos (CERRADO)»* |
> | **NO existe** el puerto serie de cámara IA (`AI_CARS`) | **`AiBus` y sus tres funciones están RETIRADOS**, no huérfanos: `grep AiBus` sobre las dos puntas sólo devuelve comentarios de historia. Colgaba del mismo USART1 que el Bluetooth, así que *«el puerto IA a 115200» nunca existió*; el enlazador ya descartaba las funciones, pero el objeto costaba **280 B de RAM por punta** en cada arranque |
> | **NO está construida** la cámara de umbral (despeje de tramo) | *Especificado, sin construir.* Falta una entrada física y un comando de radio. El despeje se hace **por tiempo** (`cfgDespejeSeg`), que es el criterio conservador. Ver `9_Manual_Parametrizacion_Camara_IA.md` |
>
> **Y el manual `05_Funcional/historico/MANUAL_CONFIGURACION_CAMARAS_IA.md` salió el 26/08 con dos errores de
> pin**, corregidos el 28/08 y registrados en su §0: asignaba la cámara de demanda a **`PB9`**.
>
> 🔴 **`PB9` y `PB13` son hoy `MANDO_A` y `MANDO_B`, los canales del mando de relés** (`J16` p5 y
> p8), y `PB8` es el **LED testigo `D5`**, no una bornera. **Cablear una cámara a `PB9`/`PB13` no
> inyecta «pulsaciones de menú»: compone SECUENCIAS DE MANDO.** Tres pulsos de tráfico en 12 s hacen
> `A·A·A` o `B·B·B` y **el semáforo cambia de modo solo**; cuatro alternos en 18 s lo meten en
> Degradado.
>
> **Evidencia:** todo lo anterior está **MEDIDO** sobre el fuente y el esquemático (`grep` de las
> llamadas y `pines.h` de las dos puntas). **Ninguna línea está VERIFICADA EN LA PLACA todavía**:
> la sesión de banco es su primera comprobación física.
>
> Referencia de campo vigente:
> **[`9_Manual_Parametrizacion_Camara_IA.md`](historico/9_Manual_Parametrizacion_Camara_IA.md)**
> y **[`15_Lista_de_Compras_Hardware.md`](historico/15_Lista_de_Compras_Hardware.md)**. ~~**Son 2 cámaras, una
> por poste** (`DECISIONES.md` `D-2` / `D-13`), y **van a `J16`: `p10` en un poste y `p12` en el
> otro** (`D-3`).~~ → ✏️ **11/09, `D-25`: son 4 cámaras, DOS POR POSTE, y van a `J16` —`p10`
> (contra `p9`) y `p12` (contra `p11`) en CADA poste—.** Guía de campo:
> [`Camaras_Sisga_4x.html`](Camaras_Sisga_4x.html).
>
> ~~**2 cámaras es el montaje mínimo y el único cableable hoy** —una por poste, en `J14`—; las dos
> entradas de `J16` de cada punta están en el firmware y **esperan la medida `M3`**.~~
>
> 🔴 **TACHADO EL 07/09 — DOS ERRORES EN UNA FRASE, Y EN EL DOCUMENTO QUE DICE «EMPIECE POR AQUÍ».**
> Mandaba la cámara a `J14` y **resucitaba `M3`**, que este mismo README declara cerrada tres
> párrafos más arriba. Es exactamente lo que él mismo advierte: *«su copia caducada pesa más que las
> otras»*.
>
> **Y el motivo por el que `J16` no es una preferencia de conector:** el vigilante de
> `CAM_CIEGA`/`CAM_PEGADA` **mira `J16` y no mira `J14`**. Una cámara cableada a `J14` **funciona y
> no está vigilada** — nadie se enteraría de que se estropeó. `J14`/`PB0` queda **libre y vivo**,
> ~~reservado a un posible fin de carrera de barrera — 🔴 **con el conflicto abierto de la tabla de
> arriba (11/09): el firmware lo sigue leyendo como cámara.**~~ → **y sin cablear (`D-27`, 11/09):
> el fin de carrera no se instala; el firmware lo sigue leyendo como cámara, así que no se conecta
> nada.**
>
> ⚠️ **Y el vigilante tampoco ve a una cámara que NUNCA haya detectado** (11/09, medido):
> `vigilante_tick()` no acumula silencio en un pin sin flanco y `camara_estado()` lo salta al
> publicar `CAM:`. Esa exención se escribió cuando `p12` iba vacío a propósito; con `D-25` pierde
> su motivo y **queda pendiente en firmware**. Hasta entonces, **una segunda cámara muerta desde el
> día que se monta no la avisa nadie**, y por eso cada cámara se comprueba con el multímetro.

---

## 📄 Índice de Manuales y Documentos Core:

> **ARCHIVADOS el 28/09 en `historico/`: todos los de esta lista salvo el 10 y el 17.** No son vigentes;
> mandan las `SPEC_0..8`. Lo que sigue describe cada documento antes de archivarlo.

1. 📘 **[1_Manual_Usuario.md](historico/1_Manual_Usuario.md)** / **`1_Manual_Usuario.docx`**  
   Manual de operación y secuencia de luces seguras bajo la **Resolución 2024 de MinTransporte Colombia**.
   Incluye el ~~**menú de dos niveles**, **AJUSTAR HORA**~~ *(⛔ `D-17.bis`: la pantalla y el menú se retiran del equipo)*, ~~el **mando de 4 relés**~~ *(⛔ `D-1`: **el mando no existe**; su código se conserva por SFTY-21)* y el **menú propio del Esclavo**. **Lo vigente de este manual es la operación por app** y el apartado de cámaras (§6, corregido el 07/09).
2. 📘 **[2_Manual_Hardware_y_Pruebas.md](historico/2_Manual_Hardware_y_Pruebas.md)**
   / **`2_Manual_Hardware_y_Pruebas.docx`**  
   Guía de ensamblaje, cableado de borneras RS485 `485_A` / `485_B` (A a A, B a B) y flasheo en PlatformIO.
   Incluye la **pila `CR2032` del reloj** (§5) y el **mando de relés** (§6). 🔴 **07/09:** ~~con la advertencia de que **el Esclavo no tiene receptor**~~ → **`D-1`: NO HAY MANDO en ninguna punta.** Y **§5 está derogada en su parte de diagnóstico**: `D-15` — el STM32 ya no contesta a `SET_RTC`; se consulta con **`CMD:LEER_RTC`** (`D-17`).
3. 📘 **[3_Protocolo_Pruebas_Rigurosas.md](historico/3_Protocolo_Pruebas_Rigurosas.md)**
   / **`3_Protocolo_Pruebas_Rigurosas.docx`**  
   Checklist obligatorio de pruebas de laboratorio y campo para certificar el equipo antes de puesta en marcha.
   ~~**68 pruebas**, con las Secciones **7 (reloj y sincronización)**, **8 (mando)**, **9 (Modo Degradado)** y **10 (interfaz del Esclavo)** nuevas.~~
   🔴 **AQUÍ NO VA UN TOTAL, y no es un descuido: es lo que el propio documento exige — 05/09.**
   ~~La cifra «68» **no aparece en el Protocolo**: `grep -c "68" 3_Protocolo_Pruebas_Rigurosas.md` da
   **0**, con y sin frontera de palabra.~~
   🔴 **ESA EVIDENCIA CADUCÓ EN 48 h — re-corrida el 07/09: `9` sin `-w` y `3` con `-w`.** Los
   nuevos aciertos son referencias de página del manual de la cámara, no un total de pruebas. **La
   conclusión sigue en pie —aquí no va un total—; lo que murió es el `grep` que la sostenía**, y por
   eso se tacha en vez de renumerarse (`CLAUDE.md` §4.sexies: *todo `grep` que se publique se corre
   antes*). Lo que ese documento publica es el reparto de los **82**
   identificadores de la revisión anterior (49 reescritas · 12 aplazadas · 21 retiradas · 4 nuevas),
   y **se niega expresamente a publicar un total nuevo** porque el denominador lo recorta quien
   ejecute la sesión. **Este README publicaba justo la cifra que el documento se niega a inventar.**
   ⚠️ **Y la Sección 10 (interfaz del Esclavo) está RETIRADA entera, no es nueva.** Las nuevas
   vigentes son la **7 (reloj)**, la **8 (mando)** y la **9 (Modo Degradado)**.
4. 📘 **[4_Manual_Configuracion_Radios.md](historico/4_Manual_Configuracion_Radios.md)**
   / **`4_Manual_Configuracion_Radios.docx`**  
   Configuración de radios industriales **E90-DTU** con `RF_Setting4.6.exe` y DIP switches `M0`/`M1`.
5. 📘 **[5_Manual_Puente_ESP32.md](historico/5_Manual_Puente_ESP32.md)** / **`5_Manual_Puente_ESP32.docx`**  
   Instrucciones para la instalación del puente repetidor con ESP32 (Modo 4 Radios para curvas ciegas).
6. 📘 **[6_Preguntas_Diseno_Funcional.md](historico/6_Preguntas_Diseno_Funcional.md)**
   / **`6_Preguntas_Diseno_Funcional.docx`**  
   Cuestionario y parámetros de diseño de obra, y la **detección vehicular por contacto seco**.
   Contiene la decisión **CERRADA** de *«Cero Computadores Edge Externos»* (§2): la analítica corre
   **dentro de la cámara**, y al equipo llega **un pulso de hardware** — no vídeo ni datos.
7. 📡 **[7_Especificacion_Antenas.md](historico/7_Especificacion_Antenas.md)** / **`7_Especificacion_Antenas.docx`**  
   **Especificación para fabricación de antenas bajo pedido.** Documento para entregar al proveedor:
   sintonía a **171 MHz**, ROE ≤ 1,5:1 en 168–174 MHz, sin plano de tierra y con **reporte de medición
   de ROE exigido como entregable**. Resuelve la causa del alcance de 3 cuadras medido el 31/07.
8. 🕹️ **[8_Procedimiento_Modo_Degradado.md](historico/8_Procedimiento_Modo_Degradado.md)**
   / **`8_Procedimiento_Modo_Degradado.docx`**  
   **Procedimiento de campo del MODO DEGRADADO.** Requisitos previos, activación **en las dos puntas**
   con verificación visual de ambas, el **límite duro de 48 h**, la salida —también verificada en
   ambas puntas— y los **riesgos residuales aceptados por el cliente**. **Obligatorio leerlo antes de
   operar ese modo.**

> # 🔴 07/09 — ESTE ÍNDICE LLEGABA HASTA EL 8, Y EN LA CARPETA HAY **19** DOCUMENTOS NUMERADOS
>
> **Medido:** `ls -1 05_Funcional/[0-9]*.md | wc -l` → **19**. Los once que faltaban aquí incluyen
> **los tres que hoy más mandan**, y uno de ellos gana a este README en cobre:

9. 📷 **[9_Manual_Parametrizacion_Camara_IA.md](historico/9_Manual_Parametrizacion_Camara_IA.md)** —
   **entregable principal desde `D-12`**: sin red y sin analítica en el controlador, **toda la
   inteligencia vive en la CONFIGURACIÓN de la cámara.** Es lo que se lleva delante de la cámara.
   🎯 **11/09, `D-27`:** los **valores** de esa configuración son los del manual del modelo
   comprado, [`historico/MANUAL_CONFIGURACION_CAMARAS_IA.md`](historico/MANUAL_CONFIGURACION_CAMARAS_IA.md)
   §4 —la tabla valor a valor está en el §4 Paso 3 del Manual 9—, y **las cuatro cámaras están
   compradas**. ~~⚠️ La guía, paso 07, todavía dice «objetivo: no filtrar»~~ — ✅ **corregida el 11/09 (`7037eb6`)**: la
   guía [`Camaras_Sisga_4x.html`](Camaras_Sisga_4x.html) dice ya ☑ Vehículo · ☐ Humano si la casilla existe (`D-27`).
10. 📱 **[10_Manual_Modulo_Bluetooth_Telemetria.md](historico/10_Manual_Modulo_Bluetooth_Telemetria.md)** —
    el transporte SPP y la alimentación del módulo. **§1 congela el transporte: SPP, no BLE.**
11. ⏱️ **[11_Manual_Instalacion_RTC_DS3231_Bateria.md](historico/11_Manual_Instalacion_RTC_DS3231_Bateria.md)** —
    pila del RTC y el `DS3231`. ⚠️ **§4.1 derogada por `D-15`: no se diagnostica el reloj mandando
    `SET_RTC` al STM32.** La orden vigente es **`CMD:LEER_RTC`** (`D-17`).
12. 🧪 **[12_Cobertura_de_Pruebas_y_Huecos.md](historico/12_Cobertura_de_Pruebas_y_Huecos.md)** — qué está
    cubierto y qué no. **No publica cifras: remite al acta de `evidencia/`.**
13. 🔌 **[13_Manual_Modulo_Expansion_I2C_y_Compras.md](historico/13_Manual_Modulo_Expansion_I2C_y_Compras.md)** —
    🛑 **PRE-IMPLEMENTACIÓN. El bus I²C sobre el STM32 NO SE MONTA.** Lo vigente de él es **§3 y la
    fe de erratas `J14`/`J15`** —riesgo eléctrico real— y **§4.1**, el censo de pines.
14. 📱 **[14_Manual_App_Movil_IOT_VIAL.md](historico/14_Manual_App_Movil_IOT_VIAL.md)** — la app. **Y desde
    `D-16`, la única superficie de mando del equipo.**
15. 🛒 **[15_Lista_de_Compras_Hardware.md](historico/15_Lista_de_Compras_Hardware.md)** — 💰 **el que se
    ejecuta con DINERO: cada fila es una compra.**
16. 📋 **[16_Documento_Auditoria_Arquitectura_y_Usabilidad_App_IOT_VIAL.md][doc16]**
17. 🏗️ **[17_Arquitectura_28-08_y_Decisiones_Abiertas.md](17_Arquitectura_28-08_y_Decisiones_Abiertas.md)** —
    🔴 **GANA A TODO LO DEMÁS DE ESTA CARPETA EN HARDWARE MEDIDO.** Es donde se anotan las medidas de
    cobre, con su fecha, su instrumento y el firmware que había dentro.
18. 🧩 **[18_Especificacion_Firmware_ESP32.md](historico/18_Especificacion_Firmware_ESP32.md)** — el ESP32 de
    **EXPANSIÓN** *(no el del repetidor del doc 5)*. 🟢 **Su firmware existe:**
    `01_Firmware/ESP32_Expansion/`, con rótulo Bluetooth y watchdog.
19. 🔧 **[19_Especificacion_Placa_Portadora_ESP32.md](historico/19_Especificacion_Placa_Portadora_ESP32.md)** —
    la portadora de la línea `A8`.

---

## 🔄 Regeneración de los entregables Word

Los `.docx` **se generan desde los `.md`**, que son la única fuente de verdad:

```bash
python 05_Funcional/convertir_a_word.py        # regenera TODOS los .md numerados de la carpeta
python 05_Funcional/convertir_a_word.py 3 8    # solo los numerados 3 y 8
```

> ~~regenera los 8~~ 🔧 **CORREGIDO EL 07/09: son 19.** El script **descubre solos los `.md`
> numerados** (`sorted(os.listdir(DIR))`), así que **no hay que tocarlo al añadir uno** — lo que
> caducaba era el número escrito aquí a mano. **Y por eso este README no vuelve a publicar la
> cuenta**: se mide con `ls -1 05_Funcional/[0-9]*.md | wc -l`.

> **No edite los `.docx` a mano:** cualquier cambio se pierde al regenerarlos. Edite el `.md`
> correspondiente y vuelva a ejecutar el script.
>
> *Archivo obsoleto:* `2_Manual_Hardware.docx` es un remanente del nombre anterior del documento 2.
> El vigente es `2_Manual_Hardware_y_Pruebas.docx`.

---

## 🔗 Matriz de Referencia Cruzada:
- **`ARQUITECTURA.map` $\leftrightarrow$ `05_Funcional`:** Mapeo directo entre la topología de red RS485/LoRa y las instrucciones físicas de conexión.
- **`README.md` & `roadmap.md` $\leftrightarrow$ `05_Funcional`:** Garantiza el cumplimiento de las fases de desarrollo (Fase 1 Lógica Core, Fase 2 «AI Edge», Fase 3 Protocolo Binario V7 y Fase 4 Pruebas Físicas).
  > *Nota (28/08/2026):* el nombre **«Fase 2 AI Edge»** es histórico y **no describe lo construido**.
  > Lo que quedó de esa fase es la lectura de **contactos secos** —`PB0` en `J14`, y `PB14`/`PB15`
  > en `J16` desde el 31/08— ver el aviso de cámaras más arriba. No hay computador edge ni
  > inferencia en el microcontrolador.

[doc16]: historico/16_Documento_Auditoria_Arquitectura_y_Usabilidad_App_IOT_VIAL.md

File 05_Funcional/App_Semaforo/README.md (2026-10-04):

Lo que hace la app lo dice `05_Funcional/SPEC_4_App_y_Bluetooth.md`.
Se prueba con `node test_dom_execution.js`; se entrega como APK dentro del paquete (`entregar.md`).

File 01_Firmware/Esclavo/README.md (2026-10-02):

Lo que hace este firmware lo dice la SPEC: `05_Funcional/SPEC_0..SPEC_8` (manda tambien sobre el fuente).

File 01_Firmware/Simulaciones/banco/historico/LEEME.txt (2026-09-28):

PACKS ARCHIVADOS DEL BANCO (28/09/2026, poda "opcion B")

correr.py solo descubre banco/packs/: nada de esta carpeta corre ni cuenta. La guarda de
rutas de compuerta.py tampoco la censa. No se borro nada: git mv, historia intacta.
Se archiva lo que no media firmware o lo que un arnes C++ real ya ejerce; cada modelo se
comprobo con un mutante inyectado en el .cpp real antes de sacarlo.
costura_06_reanudacion salio y VOLVIO a packs/: quitar respaldo_hayCiclo() de la puerta
de reanudacion del Esclavo solo lo caza ese pack; ningun arnes reanuda sin ciclo en la pila.

costura_02_fase_ciclo.py        - barrido Python de la fase del Degradado y "el Esclavo guarda el byte tal cual". Sale: mutante "Esclavo duplica el despeje" lo cazan compilar_dos_puntas (D1,G10) y compilar_degradado (B4,B5,C2). costura_12 aun lee este fichero por ruta.
costura_04_config.py            - un ACK por par de configuracion. Sale: mutante "Esclavo no acusa" lo cazan costura_03 y los dos arneses de dos puntas; el mutante "acusa tambien VERDE" no lo cazaba ni este pack (mira config_rxVerde, no la rama de main.cpp).
costura_07_motivos_rechazo.py   - tabla de motivos de rechazo para el manual y LIMITE_*_H derivado de _MS. Sale: sirve a documentacion; un limite cambiado lo cazan costura_05 y compilar_degradado (D2).
costura_11_lcd_sin_bus.py       - que la LCD no mueva el bus J17. Sale: sujeto retirado por D-32(1).
documentos_02_trazabilidad_sfty.py - tabla SFTY->pack de OPTIMIZACIONES.md contra las etiquetas # EJERCE. Sale: solo documento; la tabla queda sin vigilante.
documentos_04_cifras_sin_vigilante.py - cifras de manuales y CERTIFICACION_SW.md contra el acta. Sale: solo documento; las cifras de manuales quedan sin vigilante.
documentos_05_copias_coherentes.py - README/ESTADO/CERTIFICACION coherentes entre si. Sale: solo documento.
documentos_06_no_reabre_lo_cerrado.py - sujetos muertos que reaparecen en documentos vivos (CLAUDE.md 16.3). Sale: solo documento; CLAUDE.md 16.3 lo sigue nombrando.
enlace_02_silencio_j17.py       - registro de silencio de J17. Sale: el propio pack dice que sus numeros no significan nada hasta decidir AB-1.
maestro_05_ciclo_sin_radio.py   - barrido Python del ciclo del Maestro y desigualdad deriva/limite. Sale: su fase es una copia Python que no mira el C++; mutante "limite duro a 60 h" lo cazan costura_05 y compilar_degradado (D2).

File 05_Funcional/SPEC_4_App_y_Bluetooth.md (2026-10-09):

# SPEC 4 — La app y el Bluetooth: la unica forma de operar el equipo

**Para:** el tecnico que va al poste, el funcional y el auditor. **Escrita el 12/09/2026.**

> 🔴 **`D-16`: SIN TELEFONO NO HAY FORMA DE OPERAR EL EQUIPO.** No hay pantalla (`D-17.bis`), no hay
> pulsadores (`D-2`: `BOTON3`/`BOTON4` son camaras) y no hay mando (`D-1`). Ni ambar, ni volver a
> automatico, ni parar el cruce. **Es una propiedad DECLARADA del sistema, no una averia** — y es lo
> que obliga a todo lo de abajo: **cada orden tiene que contestar lo que de verdad paso**, porque no
> queda ninguna otra superficie donde el operario pueda comprobarlo.

**Que manda:** este fichero en su materia y `05_Funcional/17_...` en el cobre; `DECISIONES.md` es su indice.
**Que NO entra aqui:** el ciclo y sus tiempos (SPEC 1), la radio entre postes (SPEC 2), la hora y su
siembra (SPEC 3), el cobre y los conectores (SPEC 5).

**Convencion de este fichero:** se cita el **simbolo**, nunca el numero de linea (`CLAUDE.md` §7.3), y
**no se copia ninguna cifra que este fichero no pueda recalcular** (§14): donde hace falta un numero se
nombra al pack que lo rehace en cada corrida.

---

## 1. El transporte: telefono -> ESP32 -> STM32

Son **tres tramos** y **el del medio no es un cable tonto**.

| tramo | como | quien lo define |
|---|---|---|
| telefono <-> ESP32 | **Bluetooth SPP**, sin cifrar. El rotulo que ve Android lo sirve `transporte_abrir()` | `transporte_app.cpp` |
| ESP32 <-> STM32 | **UART por `J17`**, `ENLACE_BAUDIO` / `ENLACE_FORMATO`, `ENLACE_PIN_TX`/`RX` | `contrato.h` |
| formato de trama | `$TIPO,CLAVE:valor,...` cerrado con `*XX\r\n`, `XX` = XOR-8 del payload **saltando el `$`** | `enviarTramaConCrc()` / `calcularChecksum()` en los dos `bluetooth.cpp` |

**El rotulo SPP se APRENDE.** La serie sale del silicio del STM32 y el ESP32 no puede saberla al arrancar:
`transporte_aprenderRotulo()` la toma del primer `$STATUS` que retransmite y la guarda, y el rotulo bueno
—`ROTULO_PREFIJO` + serie + `M` o `E`— aparece **en la arrancada siguiente**. Hasta entonces se ve
`ROTULO_PROVISIONAL` **a proposito**: un rotulo inventado es peor que uno que admite que no sabe. **No se
re-rotula en caliente**: cambiar el nombre SPP tira la sesion del operario.

**El puente NO filtra la telemetria de subida.** `desdeElEquipo()` valida FORMATO —`trama_valida()`— y
retransmite **toda trama bien formada, la conozca o no**. La lista `PREFIJOS_STM32` existe solo para los
contadores de diagnostico. Un filtro por prefijo se comeria el `$EVENT`, que es la bitacora entera.

**La UNICA trama que el puente modifica** es el sello de hora de `sellarHoraSiFaltaba()`, y va **despues**
de validar el checksum y **recalculandolo**. Su alcance es de SPEC 3.

**Lo que el puente se queda y NO cruza** (`despachador_esParaElPuente()`): `CMD:LEER_RTC`, cualquier
linea que contenga `SET_RTC:`, y cualquier linea que contenga `HORA_ESP32`. Las tres las contesta el
propio puente marcado `NODE:PUENTE`. **O cruza o la atiende el puente, nunca las dos** (`D-15`).

**Los dos limites de linea, y los dos avisan:**

- **Bajada (app -> equipo):** `TRAMA_MAX_UTIL`. Lo que se pase se descarta y **se dice** con
  `$ERR,NODE:PUENTE,CMD:DESCONOCIDO,DESC:LINEA_DEMASIADO_LARGA`. El STM32 truncaria en silencio y
  compararia la linea recortada con `strcmp` como si estuviera entera: por eso el tope se mide en el
  puente.
- **Subida (equipo -> app):** `BUF_ENTRADA_STM32`; lo que desborda se cuenta en
  `puente_descartadasPorLargo()` y no sube.

**El latido.** El puente emite `LATIDO_LINEA` cada `LATIDO_MS` hacia el STM32 para que sus contadores de silencio
de `J17` cuenten **muertes del puente** y no silencios del puerto. **Los dos despachadores tienen una rama
reservada que sale sin actuar y SIN CONTESTAR**, la primera de todas: sin ella el latido caeria en el
`$ERR,CMD:AUTH_FAILED,DESC:PIN_INVALIDO` del final y la app pintaria un aviso rojo cada dos segundos acusando al
operario de una clave que nadie tecleo. **Y sin telefono conectado no se escribe:** `transporte_escribir()` mira
`hasClient()` y devuelve `0`, porque contar como entregada una trama que `BluetoothSerial` tira dejaria mintiendo
al unico contador que se puede mirar desde fuera.

---

## 2. Quien atiende cada orden — las dos puntas NO aceptan lo mismo

La app enruta por `NODE:` del `$STATUS`, no por lo que el operario suponga que tiene delante. Las listas
son `SOLO_MAESTRO` y `SOLO_ESCLAVO` en `app.js`, y `app_08_enrutado_por_punta` recalcula el reparto
leyendo **los dos despachadores** y prohibe que una lista reclame una orden que atienden las dos.

| solo el MAESTRO | solo el ESCLAVO | el PUENTE de cada poste |
|---|---|---|
| `SET_MODO:` AUTO · MANUAL · AMBAR · MENU · ALCANCE · INTELIGENTE · `MANUAL:CAMBIAR_TURNO` · `SET_TIEMPOS` · `TEST_LEDS` · `DEMANDA` · `REINICIAR_RELOJ` · `FORZAR_ROJO` | `AMBAR_EMERGENCIA` · `CANCELAR_AMBAR` | `LEER_RTC` · `SET_RTC` |

Las dos puntas atienden `SET_MODO:DEG_T`, `SET_DEG_AUTO` y `CONSULTA_DEG_AUTO` (§3.1, §3.2). ⬇️ ~~`SET_MODO:DEGRADADO`
la atienden las DOS~~ → **salio de las dos con `D-46` (`f9cad1f`, 02/10; sin banco)**, y `SOLICITAR_PASO` del
Esclavo con ella: las dos caen en el `else` final de `procesarComando()` y contestan
`$ERR,CMD:DESCONOCIDO,DESC:COMANDO_NO_SOPORTADO` (`..._EN_ESCLAVO` en el Poste 2).

⚠️ **`FORZAR_ROJO` no significa lo mismo en las dos puntas, y por eso el Esclavo ya no lo acepta:** alli
prometia rojo y hacia ambar con la talanquera arriba. Lo rechaza **nombrando el literal nuevo**
(`AMBAR_EMERGENCIA`), no en silencio y no como alias.

---

## 3. Las ordenes, y QUE CONTESTA el equipo a cada una

> 🔴 **La regla que gobierna esta tabla (`CLAUDE.md` §2): un `$ACK` que no depende de lo que la llamada
> devolvio es una mentira con formato de exito.** El molde bien hecho es `SET_TIEMPOS`: **pregunta DENTRO
> del `if`** y tiene **un `$ERR` por cada motivo de rechazo**.

### 3.1 Maestro (poste 1) — `Maestro/src/bluetooth.cpp`, `procesarComando()`

| orden | PIN | que contesta, y **de que depende** |
|---|---|---|
| `SET_MODO:AUTO` | si | `RESULT:OK` **incondicional**. La rama llama ella misma a `coordinador_iniciarModo()` —el todo-rojo de entrada—, asi que no depende del flanco de `main.cpp`; las dos llamadas son `void` y no hay rechazo posible |
| `SET_MODO:MANUAL` | si | `RESULT:OK` incondicional, por lo mismo: la rama llama a `coordinador_forzarRojoTotal()` (`N-147`: se entra por el todo-rojo que no programa nada) |
| `SET_MODO:AMBAR` | si | **dos respuestas**, y dependen de `modoActual_get()` leido ANTES de escribirlo: `RESULT:REARMADO` si ya estaba en `MODO_AMBAR` —la rama re-arma con `modo_ambar_setup()`— y `RESULT:OK` si no. `N-146`: sin esto el equipo contestaba OK seis veces sin encender nada |
| `SET_MODO:MENU` | **no** | **tres**: en `MODO_DEGRADADO` depende del bool de `modo_degradado_pedirSalida()` — `RESULT:SALIENDO_TODO_ROJO` si arranco la salida, `$ERR ... YA_VUELVE_AL_MENU` si ya estaba en marcha. Ninguno es OK: el menu tarda el todo-rojo. Fuera del Degradado, `RESULT:OK`. **Construido (`a4545bb`), sin banco:** sigue siendo la salida INMEDIATA del poste conectado, con el aviso de paleteros; con el Maestro en `MENU` esperando la siembra de `D-29`, revoca el permiso y contesta `RESULT:OK_REANUDACION_CANCELADA`. Hueco sin radio: SPEC 2 §7.quater |
| `SET_MODO:ALCANCE` | **no** | `$ERR ... EN_MARCHA_PARE_EL_MODO` si `modoActual_get()` es `MODO_DEGRADADO`; si no, `RESULT:OK` **incondicional** — ver §7 |
| `SET_MODO:INTELIGENTE` | si | igual que la anterior, y con la misma reserva de §7 |
| ~~`SET_MODO:DEGRADADO`~~ | — | **Salio con `D-46` (`f9cad1f`; sin banco):** `$ERR,CMD:DESCONOCIDO,DESC:COMANDO_NO_SOPORTADO`. Su puerta, `modo_degradado_evaluarEntrada()` con `DEG_RECHAZO`, queda en el fuente sin llamador que la alcance y se conserva |
| `SET_MODO:DEG_T:ahora,inicio,verde,despeje` | si | Construido (`990c278`; `D-35`, SPEC 2 §7.bis). **La unica orden de entrada al Degradado.** Puerta paralela a `modo_degradado_evaluarEntrada()`, sin sync de radio: `$ERR ... DESC:<texto>` (`modo_degradado_textoTestigo()`) por `MDT_FALTA_HORA`, `MDT_AHORA_DESFASADO` (`TOLERANCIA_TESTIGO_S`), `MDT_DESPEJE_RANGO`, `MDT_INICIO_VENCIDO`, `MDT_AMBAR_VIGENTE`, `MDT_EN_VERDE`, `MDT_NO_GUARDADO`; `RESULT:OK` / `RESULT:RENOVADO`. Con salida programada (`D-52`): `$ERR ... DESC:Cancele antes la salida programada` |
| `SET_DEG_AUTO:1` / `SET_DEG_AUTO:0` | si | Construido (`A-15`, SPEC 2 §7.ter (a)). **El `$ACK` sale DIFERIDO**, cuando el `ECO` del otro poste refleja el cambio: `RESULT:ON_EFECTIVO` (el otro tambien apto) / `RESULT:ON_FALTA_EL_OTRO_POSTE` / `RESULT:OFF`. Rechazos: `$ERR ... SIN_ENLACE_CON_EL_OTRO_POSTE` · `EN_DEGRADADO_SALGA_PRIMERO` · `FORMATO_INVALIDO`; sin `ECO` en `DEG_AUTO_ACUSE_MS`, `$ERR ... CAMBIADO_AQUI_SIN_ACUSE_DEL_OTRO_POSTE` (el cambio queda y se sigue publicando). Maestro en `MENU`: siempre ese `$ERR` (SPEC 2 §7.ter (a)). Misma orden y mismos literales en el Esclavo |
| `CONSULTA_DEG_AUTO` | no (es una consulta) | Construido. `RESULT:ESTE_<ON/OFF>_OTRO_<ON/OFF>_APTO_<SI/NO>`: la opcion propia, el ultimo `APTO` oido del otro y el `APTO` propio. Igual en el Esclavo |
| `FORZAR_ROJO` | **no** (y con PIN tambien) | Fuera de Degradado: `coordinador_forzarRojoTotal()`, `RESULT:OK`, 3 s de amarillo y rojo (`D-45`); sobre un rojo+amarillo, rojo directo (`D-53`, HUECO, SPEC 1 §3.3 (3)). En Degradado, **construido el 04/10 (`a4545bb`, `D-51`), sin banco:** rojo FIJO inmediato en ese poste (`DEG_ROJO_SIN_HORA`; tambien en la ventana de `D-29`), sin aviso de paleteros (decidido); respuestas en §3.ter.ter |
| `SET_MODO:DEG_FIN:ahora,salida` · `SET_MODO:DEG_FIN:CANCELAR` | si | Construido el 04/10 (`a4545bb`, `D-52`), sin banco; SPEC 2 §7.quater (c): `salida` = `HH:MM:SS` a la que esta punta sale por su reloj; aviso de paleteros; un `$ERR` por motivo y `$ACK` solo si quedo programada (listas en §3.ter.ter) |
| `CONSULTA_DEG_FIN` | no (es una consulta) | Construido el 04/10, sin banco. `RESULT:NINGUNA` o `RESULT:SALE_HHMMSS_FALTAN_<s>S_<RESPALDADA/SIN_RESPALDO>` (`_SIN_RESPALDO` tambien tras `FORZAR_ROJO` o hora perdida). Molde `CONSULTA_DEG_AUTO`; el contador no cabe en `$STATUS` (SPEC 2 §7.quater (c)). Igual en el Esclavo |
| `MANUAL:CAMBIAR_TURNO` | si | **tres, y el ORDEN importa** (`N-151`): `$ERR ... MODO_SIN_CICLO_SALGA_PRIMERO` si `modoMueveElCoordinador()` es falso; si no, `RESULT:OK` cuando `pedirCambioVerificado()` devuelve true, y `$ERR ... EN_TRANSICION_REINTENTE` cuando no |
| `TEST_LEDS` | si | Solo fuera de servicio (`N-82.bis`): `testLedsAdmitido()` exige modo `MENU` o `ALCANCE`, luz en `S_ROJO` y `ACK_RED` del Esclavo (`coordinador_rojoEsclavoConfirmado()`). `RESULT:STARTING_6S` si quedo armado; `$ERR` `SIN_ENLACE_AMBAR_NO_SE_PRUEBA` en `S_FALLO`, `ESPERANDO_ROJO_DEL_ESCLAVO` sin acuse, `EN_SERVICIO_PASE_A_MENU` en el resto |
| `SET_TIEMPOS:v,r,d` | si | **EL MOLDE. Cuatro respuestas, una por motivo:** `$ERR ... FORMATO_INVALIDO` si el `sscanf` con el `%c` centinela no convierte 3 exactos —dos ordenes pegadas convierten 4—; `$ERR ... EN_MARCHA_PARE_EL_MODO` si `modoAutomatico_enMarcha()`; `$ERR ... RANGO` si `modoAutomatico_fijarTiempos()` devuelve false; `RESULT:OK` **solo** si devolvio true; la app, en DEGRADADO, dice solo «guardados» y que sigue en Degradado (con rojo fijo no da verdes) |
| `REINICIAR_RELOJ` | si | **cuatro, y el `$ACK` NO sale en la rama** (1.49 (a), `622a20b`). ~~depende del bool de `reloj_reiniciarDominioRespaldo()`: `RESULT:CRISTAL_OK_PONGA_LA_HORA` o ...~~ → el bool solo decide si hay algo que verificar. `$ERR ... REPITA_EN_UNOS_SEGUNDOS` si ya hay una orden esperando veredicto —sin tocar nada: reiniciar otra vez abriria otra ventana y dejaria dos ordenes para un veredicto—; `$ERR ... SIGUE_PARADO_VEA_CONSULTA_RELOJ` si el oscilador no arranca, con el `$EVENT` `ORIGEN:RELOJ` de `reportarBitsDelReloj()`; y si arranca, **no contesta todavia**: publica `$EVENT ... ORIGEN:APP_BLUETOOTH, DETALLE:RELOJ_REINICIADO_VERIFICANDO` y deja la orden pendiente. **El veredicto sale despues, una sola vez**, desde `bluetooth_loop()` cuando `reloj_estadoCristal()` deja de decir VIGILANDO: `RESULT:CRISTAL_OK_PONGA_LA_HORA` **solo** con CUENTA, o `$ERR ... ARRANCA_Y_NO_CUENTA_VEA_CONSULTA_RELOJ` con CONGELADO, otra vez con los bits. **Llega unos segundos despues de pulsar**: el plazo es la ventana de vigilancia del cristal y no se copia aqui. La app traduce los tres `DESC` |
| `DEMANDA` | si | **tres**: `$ERR ... SOLO_EN_MODO_INTELIGENTE` fuera del modo —registrar una peticion que ningun ciclo va a mirar es fingirla—; `RESULT:REGISTRADA` si `demanda_solicitar()` devuelve true; `$ERR ... REPITA_EN_UNOS_SEGUNDOS` si devuelve false |

### 3.2 Esclavo (poste 2) — `Esclavo/src/bluetooth.cpp`, `procesarComando()`

**`AMBAR_EMERGENCIA` tiene DOS puertas —sin PIN y con PIN— con el MISMO bloque letra por letra.** No se
factoriza a proposito: los packs (`esclavo_07`, `esclavo_08`) leen el bloque de CADA rama, y una respuesta
que viviera en una funcion comun los dejaria midiendo un bloque vacio (`N-89`).

| orden | PIN | que contesta, y **de que depende** |
|---|---|---|
| `AMBAR_EMERGENCIA` | **no** | **seis literales, y ninguno promete de mas.** Con la luz libre (`!degradado_gobiernaLuz()`) el ambar se enciende ya; lo que el `RESULT` anade es **si el aviso al Poste 1 puede haber sido oido**, y eso NO sale de `protocolo_enviarPaquete()` —que es `void`— sino de dos banderas: `enlaceCaidoAnunciado` (esta punta ya declaro que se quedo sin radio) y `avisoAmbarConfirmado` (`D-31`: el Poste 1 acuso un aviso anterior de ESTE ambar). De ahi `OK`, `OK_SIN_RADIO`, `OK_POSTE1_AVISADO` y sus tres gemelos `YA_EN_AMBAR_LATCH_PUESTO...` cuando la luz ya estaba en ambar y lo unico nuevo es el latch. **`SIN_RADIO` gana a `POSTE1_AVISADO`**: el acuse es de hace un rato, la caida es de ahora |
| `AMBAR_EMERGENCIA` (con el Degradado gobernando) | — | `RESULT:SALIENDO_TODO_ROJO` si hay salida iniciada y `RESULT:SALIDA_YA_EN_CURSO` si es una rendicion (`degradado_rendicionEnCurso()`) — **no `OK`**, porque el ambar tarda el todo-rojo entero. Y si la salida en curso termina en ROJO porque la pidio otro: `$ERR ... SALIDA_A_ROJO_EN_CURSO_REPITA`, **sin armar el latch** |
| `CANCELAR_AMBAR` | si | **PIDE PIN al reves que armar**, y es deliberado: quitar el ambar devuelve el cruce a dar verdes, o sea **abre paso**. Depende de `ambarEmergencia`: con latch puesto lo retira, avisa al Poste 1 y contesta `RESULT:RETIRADO` (la rama del mando salio con el, `D-30`). Sin latch, `RESULT:REENVIADO_AL_MAESTRO` si esta punta **sigue** en `S_FALLO` (la red de la trama perdida, `N-152`), y `$ERR ... NO_HAY_AMBAR_VIGENTE` si no |
| ~~`SOLICITAR_PASO`~~ · ~~`SET_MODO:DEGRADADO`~~ | — | **Salieron con `D-46` (`f9cad1f`; sin banco):** `$ERR,CMD:DESCONOCIDO,DESC:COMANDO_NO_SOPORTADO_EN_ESCLAVO`. La app ya no las ofrecia (`D-36`, `D-37`). El paso se da desde el Maestro (Manual y DAR PASO, SPEC 1 §8); al Degradado se entra por el testigo |
| `SET_MODO:DEG_T:ahora,inicio,verde,despeje` | si | Construido (`990c278`; `D-35`, SPEC 2 §7.bis). Misma orden, `RechazoTestigo` propio: `DEG_RECHAZO_T_SIN_HORA` / `_AHORA_DESFASADO` / `_INICIO_VENCIDO` —texto «repita el testigo en el Maestro»— / `_DESPEJE_RANGO` / `_AMBAR_VIGENTE`, o `RESULT:OK` / `RESULT:RENOVADO` |
| `SET_MODO:DEG_FIN:ahora,salida` · `...:CANCELAR` · `CONSULTA_DEG_FIN` | si · si · no | Construidos el 04/10 (`a4545bb`, `D-52`), sin banco. Misma orden y mismos literales que el Maestro (§3.1), con `RechazoSalida` propio; aqui muerde «Salida ya vencida», con el MISMO literal que el Maestro (el consejo lo dice la app). Al llegar la hora llama a `iniciarSalida(false)`: rojo, el despeje y `DEG_INACTIVO`, **sin menu**: sin radio queda en ambar por silencio. `DEG_T` con salida programada se rechaza igual |
| `SET_DEG_AUTO:1` / `SET_DEG_AUTO:0` · `CONSULTA_DEG_AUTO` | si · no | Construidos. Los del Maestro (§3.1); aqui el enlace es una orden de gobierno del Maestro en los ultimos `SFTY6_SILENCIO_MS`, y el `ECO` llega en su `PING` |
| `FORZAR_ROJO` | las dos formas | `$ERR ... RENOMBRADO_USE_AMBAR_EMERGENCIA`. **Se rechaza ensenando el nombre bueno**, no en silencio: quien lo manda tiene una app o un manual anteriores al cambio |
| `TEST_LEDS` | si | `$ERR ... NO_EN_SERVICIO_USE_EL_MAESTRO`, **rechazado a proposito**: la secuencia enciende VERDE sin mirar nada, y ese verde saldria mientras el Maestro da paso al otro sentido |

### 3.3 El puente ESP32 de cada poste — `ESP32_Expansion/src/despachador.cpp`

| orden | PIN | que contesta, y **de que depende** |
|---|---|---|
| `CMD:LEER_RTC` | no (es una consulta: no abre, no para, no cambia) | `$ACK,NODE:PUENTE,...,RESULT:OK` con `FECHA:` y `HORA:` **releidas del chip ahora mismo**, o **siete `$ERR` distintos**, uno por cada valor de `MotivoSinHora` —incluido `BARRERA_INCOHERENTE`, que existe para que un defecto del firmware no se disfrace de averia del modulo—, mas un octavo, `MOTIVO_NO_CONTEMPLADO`, para que nadie anada un valor al enum y deje la consulta muda—. Cada literal vive **dentro** de su rama |
| `SET_RTC:<fecha>,<hora>` | **el PIN viaja y no lo comprueba nadie** — ver §7 | siete motivos, uno por valor de `ResultadoReloj`, y el `$ACK` final **devuelve la hora RELEIDA**, no la que se mando. Hay un octavo caso que es `$ACK` y no `$ERR`: `RESULT:HORA_PUESTA_SIN_PROPAGAR` cuando el DS3231 quedo puesto pero `siembra_ahora()` no pudo poner la linea entera en el cable. El detalle es de SPEC 3 |
| cualquier linea con `HORA_ESP32` dentro | — | `$ERR,NODE:PUENTE,CMD:HORA_ESP32,DESC:LINEA_RESERVADA_AL_PUENTE`, **y va la primera de todas**: esa orden solo la origina el modulo, y el STM32 la acepta sin PIN porque el puente no lo conoce |

---

## 3.bis 🟢 LAS BOTONERAS A/B/C/D ESTAN ELIMINADAS — el equipo se opera SOLO por la app

**El hardware ya no existe: se retiro del equipo el 05/09** —*«se opera solo por app»*— y el
responsable lo reafirma el 14/09: *«eliminamos las botoneras A, B, C y D»*. **No hay superficie
fisica de operacion**: ni botones, ni receptor que comprar, ni pantalla —esa salio del firmware el
13/09—. La guia de campo ya retiro su paso de prueba del mando, y **`J16` p5 y p8 se quedan vacios:
no hay nada que cablear ahi**.

✅ **Y EL PROGRAMA YA NO COMPONE NADA CON ELLOS: el mando salio del firmware el 14/09.** `mando.cpp` y `mando.h` de
las dos puntas estan retirados —681 lineas— y con ellos el reconocedor de secuencias, de modo que
**un puente en `J16` p5 o p8 ya no compone nada**: era el unico riesgo que quedaba vivo, porque
puentear una bornera para probarla es lo primero que hace un instalador y entonces movia el cruce de
verdad. Los bornes siguen vacios y pelados, asi que **la instruccion de no cablearlos sigue en pie**;
lo que cambia es que ya no es lo unico que lo impide.

✅ **Y lo que cuesta sacarlo esta MEDIDO hoy, porque el repositorio lo daba por mas caro de lo que
es** — dos frases que lo frenaban y son falsas:

| lo que se decia | lo medido el 14/09 |
|---|---|
| *«retirar el mando se lleva por delante parte de la barrera de salidas»* | **No.** La bandera que intercepta las luces la arman **dos** funciones y sus **unicos** llamadores son el mando. Sin ellos la bandera se queda en falso para siempre y la guarda que cuelga de ella **no dispara**: el equipo escribe las luces por el camino normal. **No deja ningun veto abierto — deja codigo muerto** |
| *«borrar el menu borra el todo-rojo de las dos puntas»* | **Tampoco.** Ese todo-rojo tiene **tres** llamadores: el menu, el Modo Alcance y el Modo Hora, **y los dos ultimos se alcanzan desde la app**. ⬇️ Con `D-44` el Modo Hora salio y `menu_setup()` **se quedo**: es la puerta que piden `SET_MODO:MENU` y la salida de cada modo |

✅ **Y la condicion que puso el responsable se cumplio: el camino de interceptar las luces SALIO
ENTERO con el mando**, en vez de quedarse dentro sin nadie que lo ejerza. Con el fuera, `semaforo.cpp`
escribe los pines por un solo sitio —`aplicarSalidas()`, donde vive el enclavamiento `SFTY-2`— y la
lista de funciones autorizadas a saltarselo **baja de cinco a una**: cualquier camino nuevo a una
lampara es ahora un rojo del banco en vez de una excepcion ya aprobada por su nombre.

✅ **Y CON `D-44` (`f9cad1f`, 02/10; sin banco) SALIO EL RESTO** (SPEC 1 §12.2): `J16` p5/p8 son `J16_P5_SIN_USO` y
`J16_P8_SIN_USO`, `INPUT` sin lector (`botones_actualizar()` solo llama a `camaras_actualizar()`); salieron
`botonArriba`/`Abajo`/`Aceptar`/`Cancelar`, la navegacion del menu, el Modo Hora y `semaforo_toggle()`.
`menu_setup()` se queda: es el todo-rojo de `SET_MODO:MENU`.

## 3.ter EL DEGRADADO CON TESTIGO EN LA APP — flujo (`D-35`, SPEC 2 §7.bis; construido en `11b57b3`)

**Boton nuevo, en LAS DOS pantallas** —Maestro y Esclavo—, gobernado por `puntaCorrecta()` igual que los demas
(`app.js`, §7 hueco nuevo abajo): «Degradado con testigo». ~~Aparece junto a `SET_MODO:DEGRADADO`~~ → desde `D-46` es
la unica entrada al Degradado: `SET_MODO:DEGRADADO` salio del firmware.

**En el Maestro (primera punta que se toca):**
1. El operario escribe el **traslado** —minutos hasta el Esclavo, por defecto **20**— y el **despeje** —30 a 255 s,
   el mismo limite que el firmware exige (§3.1)—. `verde` no se pide: viaja fijo en **180**.
2. La app manda `SET_RTC:<fecha del telefono>,<hora del telefono>` a ESTA punta, igual que siempre —**no bloquea
   el paso siguiente**: el resultado (`RESULT:OK` o `HORA_PUESTA_SIN_PROPAGAR`) se registra en el Diario, pero
   el testigo ya no depende de el (SPEC 2 §7.bis: la garantia la da `ahora`, no el `SET_RTC` previo).
3. La app LEE la hora del telefono OTRA VEZ, justo antes de enviar —es el `ahora` de la orden—, calcula
   `inicio = ahora + traslado` y manda `SET_MODO:DEG_T:ahora,inicio,180,<despeje>`.
4. **Lo que la app GUARDA, para el paso 2 del Esclavo** (localmente, no en el equipo): `inicio`, `verde`,
   `despeje`, la `SERIE:` del Maestro (del `$STATUS`, `NODE:` distingue de cual poste vino) y el instante en
   que se emitio. Sin este dato el operario tendria que teclear los mismos numeros dos veces, y un numero mal
   repetido en el Esclavo es exactamente lo que este modo NO puede permitirse (§8(e): un ciclo distinto en cada
   punta solapa verdes).

**En el Esclavo (segunda punta, tras desplazarse):**
1. La pantalla ofrece «Aplicar testigo guardado — Maestro `<serie>`, inicio `HH:MM:SS`», con `inicio`, `verde`
   y `despeje` del paso anterior, **no un formulario nuevo**: repetirlos a mano es el error que el guardado
   del paso 4 evita.
2. La app manda `SET_RTC` a esta punta primero, igual que en el Maestro — tampoco bloquea aqui.
3. La app LEE la hora del telefono de nuevo —un `ahora` distinto del que uso el Maestro, mas tarde por el
   traslado— y manda `SET_MODO:DEG_T:ahora,inicio,verde,despeje`: `inicio`, `verde` y `despeje` son los
   GUARDADOS, no se recalculan aqui; `ahora` es fresco.
4. **Si `ahora` no coincide con el reloj de esta punta** (mas de `TOLERANCIA_TESTIGO_S`), se rechaza con
   `DEG_RECHAZO_T_AHORA_DESFASADO`; la app sugiere repetir el `SET_RTC`. **Si `inicio` ya pasó**, se rechaza con
   `DEG_RECHAZO_T_INICIO_VENCIDO` y la app traduce el motivo tal cual lo devuelve el firmware: «el testigo
   caducó — repita el paso completo en el Maestro». **No ofrece reintentar con el mismo `inicio`**: el traslado
   ya se cumplió (el motivo no lo arregla el reintento, lo arregla un testigo nuevo).

**Testigo con más de 31 días (el limite de vigencia del testigo):** la app no puede saberlo de
antemano —el contador vive en la tarjeta, no en el telefono—; se entera por el `$STATUS`/`$ALARM` igual que
hoy se entera del ámbar por límite duro (`SPEC 6` Parte C), y el texto es el que ya existe para ese aviso,
sin uno nuevo.

## 3.ter.bis EL DEGRADADO AUTOMATICO EN LA APP — construido en `js/deg_auto.js` (`A-15`, SPEC 2 §7.ter)

**Es una ELECCION DE MONTAJE, no un modo que se pone cuando ya cayo la radio** (decidido el 05/10, tras el banco del
funcional: lo intento sin radio y no entendio el rechazo `SIN_ENLACE_CON_EL_OTRO_POSTE`). Construido en
`js/deg_auto.js` y `js/deg_auto_eleccion.js` (`N-176`, sin banco):
- **La tarjeta (pestana Tecnico, las dos pantallas) es una pregunta**: «Si se cae la radio entre los postes:»
  (a) «Ambar intermitente y voy con el testigo» = `SET_DEG_AUTO:0`, la de fabrica y la de carretera (`D-43`);
  (b) «Entran solos en Degradado a los 5 min sin radio» = `SET_DEG_AUTO:1`. Pide PIN; se elige en LOS DOS postes.
- **Sin radio los botones quedan desactivados** y la orden no sale: con `FALLO COM` fuera de `MODO:AMBAR` o `RF:0%`.
  No se bloquea por `APTO_NO`: con la opcion en OFF el apto es siempre NO.
- **Pantalla principal, linea fija encima de la tarjeta del cruce** con lo que dio `CONSULTA_DEG_AUTO`: «Si se
  cae la radio: AMBAR, ir con testigo» o «… DEGRADADO SOLO a los 5 min»; «Los postes no coinciden» en rojo si ESTE
  y OTRO difieren.
- **Recuadro de la eleccion, «Listo para entrar solo»** (06/10, foto de Marco: «SI» con el otro en OFF y no entro): SI
  solo con `ESTE_ON`, `OTRO_ON` y `APTO_SI`, lo mismo que exige el firmware para entrar. Si no, NO con el motivo:
  «este poste en OFF», «el otro poste no esta listo» (su ultimo APTO oido) o «este poste no cumple las
  condiciones». **Debajo, «Que falta» con el PRIMER paso pendiente y la accion** (responsable, 06/10: «no dice que
  hacer»), en este orden: (1) ESTE OFF: «pulse (b) en este poste»; (2) conectado al Maestro con `MODO` distinto de
  `AUTO`/`INTELIGENTE`: «ponga el POSTE 1 en AUTO o INTELIGENTE y espere a que cicle con radio» (`puertaAbierta()`);
  (3) OTRO OFF: desde el Maestro, «vaya al POSTE 2, pulse (b) y espere 10 s»; desde el Esclavo, «el POSTE 1 debe
  estar en AUTO o INTELIGENTE con (b) pulsada»; (4) APTO NO: «ponga la hora y compruebe que hay radio»; todo bien:
  «nada: si la radio cae 5 min, entran solos».
- **Al conectar**, si no consta o no coincide, aviso que pide elegir («Mas tarde» lo pospone hasta la siguiente).
- **Al caer la radio**, cartel segun la eleccion: (a) «quedan en AMBAR y NO arrancan solos: hay que ir con el
  testigo», con boton al testigo; (b) cuenta «aprox. m:ss» desde que la app ve `FALLO COM` (llega tarde respecto al
  reloj del firmware: por eso «aprox.»), y con `AUTO_ENTRADA_INICIO` o `MODO:DEGRADADO`, «En Degradado por reloj».
  La cuenta (b) sale solo con `ESTE_ON`, `OTRO_ON` y `APTO_SI`: es lo que el firmware exige para entrar
  (`degAuto_loop()`: `respaldo_otroApto()` y `puertaAbierta()`, y `entrar()` repite la comprobacion de
  `degAuto_aptoPropio()`; el ECO `respaldo_aptoDado()` no llega a la app). En cualquier otro caso sale el cartel (a),
  con boton al testigo y una linea con el motivo: ESTE y OTRO distintos, «Los postes no tienen la misma eleccion»;
  `ESTE_ON_OTRO_ON` con `APTO_NO`, «Este poste no esta listo para entrar solo». Si la cuenta pasa de 0 en mas de
  60 s sin `MODO:DEGRADADO` ni `AUTO_ENTRADA_INICIO` (cubre el ECO, que la app no ve): «No entraron solos: quedan en
  AMBAR. Hay que ir con el testigo», con boton al testigo.
- Mientras espera el `$ACK` diferido (hasta `DEG_AUTO_ACUSE_MS`) queda «esperando al otro poste», no el valor pedido.

**Eventos y alarmas que traduce, a texto de operario:**
- `DEGRADADO` / `AUTO_ENTRADA_INICIO_HH:MM:SS` — «Sin radio 5 min: modo degradado automatico, rojo hasta HH:MM».
- `DEGRADADO` / `ENLACE_DISPONIBLE` — un **cartel fijo** (`js/carteles_equipo.js`, §6): «LA RADIO VOLVIO entre los
  dos postes. Siguen en Degradado.» y, para volver al ciclo, Volver al menu en el Poste 1. El firmware lo repite
  mientras oiga al otro (SPEC 2 §7.ter (c)): toast y linea solo la primera vez por conexion; despues se refresca la
  hora del ultimo aviso. Lo quitan Entendido, soltar el enlace o un `$STATUS` con otro `MODO`.
- `$ALARM DEGRADADO,CAUSA:AUTO_NO_<codigo>` (codigos en SPEC 2 §7.ter (b); tabla `DegAuto.MOTIVO`) — «No pudo
  entrar solo: <motivo>.» y lo que dice la `ACCION`: con `SIGUE_AMBAR`, «Sigue en ambar»; con `QUEDA_ROJO` (solo el
  Maestro con `GUARDADO`), «Queda en ROJO FIJO en este poste, no en ambar: avise a mantenimiento».
- `$ALARM DEGRADADO,CAUSA:OTRO_EN_DEGRADADO,ACCION:REVISE_OTRO` — «El otro poste esta en degradado y este no: vaya
  al otro poste».
- `$ALARM DEGRADADO,CAUSA:RENOVAR_TESTIGO,ACCION:REPITA_TESTIGO` (28 dias sin renovar) — «vaya a los dos postes y
  repita el Degradado con testigo». Sin vencimiento: la luz no cambia (29/09).

**Y el `$STATUS` del Maestro en Degradado publica `ESC:?`**: la app lo pinta como «desconocido», no como el ultimo
color que vio (SPEC 2 §7.ter (e)).

## 3.ter.ter LA SALIDA PROGRAMADA Y EL ROJO TOTAL EN LA APP — construido el 04/10, sin banco (`D-52`, `D-51`; SPEC 2
§7.quater)

**Respuestas del firmware (construido el 04/10, `a4545bb`, sin banco).** `FORZAR_ROJO` en Degradado, cada una segun lo
que devolvio `modo_degradado_forzarRojo()`: `RESULT:ROJO_FIJO_EN_ESTE_POSTE` · `RESULT:YA_EN_ROJO_FIJO` ·
`RESULT:SALIDA_YA_EN_CURSO` · `RESULT:OK` (fuera del modo). En la ventana de `D-29` (permiso esperando la siembra)
revoca el permiso y entra en ROJO FIJO, nunca ambar: `OK_REANUDACION_CANCELADA`. `SET_MODO:MENU` en esa ventana:
`OK_REANUDACION_CANCELADA`.
no cruza a nadie.

`SET_MODO:DEG_FIN`, un `$ERR ... DESC:<texto>` por motivo y en este orden: `FORMATO_INVALIDO` · «No esta en
Degradado» · «Ya esta saliendo» · «Falta: reloj sin poner en hora» · «Ahora no coincide» (`TOLERANCIA_TESTIGO_S`) ·
«Salida ya vencida» (mas de 12 h por delante) · «Salida antes del inicio» · «En verde: repita en rojo» · «No se pudo
guardar la salida» · «No hay salida programada» (`CANCELAR` sin nada). `$ACK` solo si quedo programada:
`RESULT:PROGRAMADA` · `REPROGRAMADA` (solo con respaldo en flash) · `PROGRAMADA_SIN_RESPALDO` (sin respaldo: rojo total
o sin registro; un corte la pierde; gana a `REPROGRAMADA`) · `CANCELADA`.

**Lo que HACE la app (`7cd3042`, sin banco ni telefono):** `FORZAR_ROJO` sale sin aviso de paleteros
(`js/aviso_degradado.js`, `aplica()` solo mira `SET_MODO:*`, `SET_DEG_AUTO:0` y las dos órdenes del Esclavo). La clave
`FORZAR_ROJO|SALIENDO_TODO_ROJO` ya no existe en `ACK_TEXTO` (`app.js`).
1. **Texto de `FORZAR_ROJO` en Degradado**, una entrada por `RESULT` (SPEC 4 §3.1): `ROJO_FIJO_EN_ESTE_POSTE` dice
   «ROJO FIJO en ESTE poste. El OTRO POSTE SIGUE ALTERNANDO por su reloj: vaya a él. Se sale con la salida programada o
   con Volver al menu»; `YA_EN_ROJO_FIJO`, «ya estaba en rojo fijo; nada cambia»; `SET_MODO:MENU` con
   `OK_REANUDACION_CANCELADA`, «volvió al menú; el degradado que esperaba la hora NO se reanudará». Desaparece la clave
   `SALIENDO_TODO_ROJO` de esta orden; `SALIDA_YA_EN_CURSO` se queda (ya está saliendo al menú). **Sin aviso de
   paleteros** (decidido, SPEC 2 §7.quater (b)).
2. **Botón «Programar salida del Degradado»** en las DOS pantallas, un bloque por punta según `state.node` (si no
   coincide, aviso y no sale nada), con el mismo flujo
   que el testigo (§3.ter): en el Maestro se escribe la hora de salida (por defecto `ahora` + el traslado, editable) y
   la app manda `SET_MODO:DEG_FIN:ahora,salida` con `ahora` releído justo antes de enviar; **guarda `salida`** (local) y
   en el Esclavo ofrece «Aplicar salida guardada — Maestro `<serie>`, salida `HH:MM:SS`» sin formulario nuevo, con un
   `ahora` fresco. **Lleva el aviso de paleteros** (`aplica()` ya cubre `SET_MODO:DEG_FIN`; el vale se compara por el
   nombre de la orden, no por sus argumentos). Botones «Reprogramar» y «Cancelar salida» (`SET_MODO:DEG_FIN:CANCELAR`).
3. **Tarjeta de estado** (la pestaña Técnico, como `js/deg_auto.js`): pide `CONSULTA_DEG_FIN` al conectar y tras cada
   orden y pinta «sale a HH:MM:SS, faltan N s» contando hacia atrás sola, con la marca «sin respaldo» si el firmware la
   dio. **Si esta app programó el Maestro y no consta el Esclavo, el cartel queda fijo:** «salida programada en el
   Maestro; FALTA el Esclavo» (el firmware no puede saberlo sin radio; riesgo SPEC 2 §7.quater (h).1).
4. **Traduce** cada `$ERR` de `DEG_FIN` (un texto por motivo; «Salida ya vencida» dice «reprograme la salida en el
   Maestro o cancélela», **no ofrece reintentar** con la misma hora), cada `RESULT` (`PROGRAMADA`, `REPROGRAMADA`,
   `PROGRAMADA_SIN_RESPALDO`, `CANCELADA`), `$EVENT DEGRADADO,SALIDA_PROGRAMADA_*` y `$ALARM DEGRADADO,CAUSA:ROJO_TOTAL,
   ACCION:ROJO_FIJO` («rojo total puesto por una persona; el otro poste sigue alternando»), que NO es `ROJO_SIN_HORA`.

**Ficheros (HACE, `7cd3042`).** `js/deg_fin.js` (modulo `DegFin`: botones, tarjeta con cuenta atras, motivos y
`$EVENT`; la tarjeta se arma por JS porque `index.html` no crece) · `js/deg_auto.js` (reparte a `DegFin` desde los
enganches que `app.js` ya llamaba: `enviarFin`, `consultarFin`) · `js/aviso_degradado.js` (el vale del aviso de
paleteros se casa por NOMBRE de orden, no por la trama: `DEG_FIN` lleva un `ahora` distinto en cada envio) ·
`app.js` (entradas de `ACK_TEXTO` y `CONSULTA_DEG_FIN` en `SIN_PIN`). Copias en `www/` y en la APK.
**Limites que HACE y quedan escritos:** un `CANCELADA` que esta app no pidio (otro telefono) no borra el cartel local
«FALTA el Esclavo», aunque la tarjeta si refleja la consulta; y la app mide la ventana de 12 h con el reloj del
telefono y el poste con el suyo, asi que en el borde pueden discrepar: manda el `$ERR` del poste.

**Aviso `$EVENT DEGRADADO ... SYNC:<h>h AVISO:SI|NO VENCIDA:SI|NO` (HACE, sin banco; `deg_auto.js`).** El evento no
dice si el poste tiene testigo y la app no lo deduce de `h`; se publica en todo modo y en las dos puntas. `VENCIDA:SI`
va primero, con o sin `AVISO` (sin testigo y sin fecha el Maestro publica `AVISO:NO VENCIDA:SI`): «sin sincronizacion
de radio valida (48 h o mas, o sin fecha): este poste no da verdes por reloj; la luz que tiene la ve en su estado en
esta pantalla: ambar, o rojo fijo si llega la alarma de reloj parado». No remite a una alarma de la rendicion: el
Maestro emite `LIMITE_48H` pero el Esclavo se rinde sin ninguna (SPEC 6, fila `LIMITE_48H`, solo Maestro), y con el
reloj parado (`D-49`) el poste esta en rojo fijo con la trama diciendo `VENCIDA:SI`. `AVISO:SI` sin `VENCIDA:SI`: un
solo texto, «lleva <h> h sin radio» (sin la cifra si falta `h`), «si este poste tiene testigo, renuevelo en los dos
postes; si no, recupere la radio antes de 48 h». La orden de renovar la da tambien la alarma `RENOVAR_TESTIGO`, que no
sale sin fecha.

## 4. El PIN

- La forma del cable es `CMD:PIN:<pin>:<accion>` y la comparacion es **literal en los dos despachadores**.
  La app lo antepone a todo lo que no este en su lista `SIN_PIN`.
- **El criterio, escrito en el firmware:** *el PIN guarda lo que ABRE paso o mueve luces; no lo que las
  para.* Por eso el rojo de emergencia entra sin clave: quien esta viendo el incidente tiene que poder
  pedirlo aunque no se sepa la clave.
- **La segunda puerta de la app no es una clave: es el VALE DE VIA DESPEJADA.** Para las ordenes que abren paso
  desde la botonera de campo, `enviarComandoFirmware()` exige `viaConfirmadaVigente()` en vez del PIN, y el motivo
  no es comodidad: **un PIN demuestra QUIEN eres y no demuestra que hayas MIRADO.** El firmware no cambia —sigue
  exigiendo el PIN y la app se lo sigue poniendo—; cambia a quien se lo pide la app.
- **La app devuelve si la orden llego a salir, y el que llama tiene que mirarlo.** `enviarComandoFirmware()`
  devuelve `bool`: pulsar un boton no es saber que el equipo obedecio, y **ni siquiera es saber que la orden
  salio**. Una orden que no salio se anota en el Diario **y no en la cinta** —por el cable no paso un byte—.

- **La unica orden que sale sin que nadie pulse es `CMD:VERSION`** (sin PIN, no cambia nada): una vez por enlace,
  a los `TIMEOUT_ENLACE_MS` de conectar, solo con telemetria viva y si el CONTROLADOR no ha contestado ya
  (`EVT:VERSION` es el sello del puente). No renueva la inactividad del PIN. El sello de cada `NODE` va en la linea
  `Firmware:` de la cabecera del diario y de la cinta, y **«Exportar todo como archivo»** saca los dos en un
  `IOTVIAL_<serie>_<AAAAMMDD-HHMMSS>.txt` (`js/exportar.js`). En el navegador sale por la hoja de compartir con
  el fichero adjunto o, si no la hay, como descarga. En la APK se escribe en la cache de la app
  (`@capacitor/filesystem`, `Directory.Cache`) y se abre la hoja de compartir de Android con ese fichero
  (`@capacitor/share`, por el `FileProvider` `<applicationId>.fileprovider` y el `<cache-path>` de
  `file_paths.xml`); cerrar la hoja se dice como cancelado, y un fallo, o una APK sin los dos plugins, va en rojo a
  la bitacora con «use Copiar». Sin probar en un telefono (§7.12).

🔴 **Lo que el PIN NO cubre hoy esta medido y esta en §7.**

---

## 5. Las cinco tramas que la app lee

`TIPOS_QUE_LA_APP_LEE` en `app.js` es la lista, y `juzgarTrama()` la unica puerta: valida el XOR-8 y
**devuelve POR QUE** cuando no entra. Una cabecera fuera de la lista **no se pinta y se cuenta nombrandola**.

| trama | campos, en orden | quien la emite |
|---|---|---|
| `$STATUS` | `NODE` `SERIE` `MODO` `ESTADO` `T` `RF` `RTT` `BAT` `HORA` **`ESC`** `PLUMA` `CAM` | Maestro, cada `tUltimaTelemetria` |
| `$STATUS` | `NODE` `SERIE` `MODO` `ESTADO` `T` `RF` `RTT` `BAT` `HORA` `PLUMA` `CAM` | Esclavo — **sin `ESC`**, y la asimetria es deliberada (`N-149`): esta punta no tiene a quien preguntarle por el otro poste |
| `$ACK` | `CMD` `RESULT` (+ `FECHA` `HORA` en los del puente, que ademas llevan `NODE:PUENTE`) | la punta que atendio la orden |
| `$ERR` | `CMD` `DESC` (+ `NODE:PUENTE` si es del ESP32) | idem |
| `$EVENT` | `NODE` `ORIGEN` `DETALLE` `HORA` | las dos puntas. Es el **Diario de Ordenes**: lo que sobrevive al viaje del tecnico |
| `$ALARM` | `NODE` `EVENTO` `CAUSA` + el tramo del enlace + `ACCION` `HORA` | las dos puntas. El tramo es `RF`/`RTT`/`SINRESP` en el Maestro y `RX`/`OK`/`RUIDO` en el Esclavo — **no son los mismos tres numeros**, porque no miden lo mismo |

**Las marcas de ausencia, y significan cosas distintas:** `--` es *«todavia no lo se»* o *«en esta fase no
hay dato»*; `!` es *«llego un valor imposible»*. **Un `0` de relleno esta prohibido**: `T:0` es el ultimo
segundo de la fase y significa lo contrario que `T:--`.

**El `DETALLE` de un `$EVENT` no lleva comas**, y no es estilo: el parser de la app parte por `,` y cada
trozo por su **primer** `:`, asi que una coma dentro convertiria el resto en campos sueltos que el pintor
de `$EVENT` no mira. Los buffers de todas estas tramas los recalcula `esp32_07_presupuesto_bytes` en cada
corrida, **y la cuenta no se copia aqui** (§14).

---
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

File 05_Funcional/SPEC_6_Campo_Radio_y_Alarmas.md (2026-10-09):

# SPEC 6 — CAMPO: el Degradado paso a paso, la radio como aparato, y las alarmas

**Para el que esta subido al poste con el telefono en la mano**, y para el que compra antenas. Escrita el
12/09/2026. **Son los huecos que las otras cinco spec dejaron entre ellas**, y no repite lo que ya dicen: el
**comportamiento** del Degradado es SPEC 2 §7 y su **luz** es SPEC 1 · el **dialogo de radio** y los DOS RELOJES
del silencio son SPEC 2, §§4 y 9 · la **hora** es SPEC 3 §7 · el **formato de las tramas** y lo que la app pinta es
SPEC 4 · el **cobre**, `J12` y las camaras son SPEC 5. Aqui va **lo que se TECLEA, lo que se CONFIGURA, lo que se
HACE cuando salta una alarma — y el unico binario que hoy se puede cargar en el equipo montado (PARTE D).**

**De donde sale cada linea.** Manda la spec (`DECISIONES.md` es su indice) y el fuente dice lo que el equipo HACE. **Los
manuales anteriores NO son fuente**: se abrieron para censar y **ninguna frase entro sin remedirla**. Se cita el
**SIMBOLO**, nunca la linea, y **no se copia ninguna cifra que este fichero no pueda recalcular**. 🔴 **Un paso
inventado es peor que un paso ausente, porque el instalador lo ejecuta:** donde el fuente no dice como se hace algo,
aqui pone **HUECO** y no un procedimiento verosimil.

# PARTE A — PROCEDIMIENTO DE CAMPO DEL MODO DEGRADADO

**Cuando se usa:** la radio entre postes esta MUERTA y el cruce tiene que seguir alternando; que hace el equipo
dentro, SPEC 2 §7. **No se entra "por si acaso"**: con el Maestro vivo su latido saca al Esclavo del modo.

## A.1 La entrada — UNA orden, y en LAS DOS PUNTAS por separado

~~`SET_MODO:DEGRADADO`, **con PIN, a cada poste**; el Esclavo tambien la acepta (`D-18`)~~ → **salio de las dos puntas
con `D-46` (`f9cad1f`, 02/10; sin banco)**: hoy contesta `$ERR,CMD:DESCONOCIDO,DESC:COMANDO_NO_SOPORTADO`
(`..._EN_ESCLAVO` en el Poste 2). **La entrada es el testigo (A.1.bis), con PIN, a cada poste** (y, construida
`D-56`, con la clave de administracion de la app para ver la pestana). La tabla de abajo y
A.2 son las respuestas de la orden retirada: solo valen ante un equipo con firmware anterior (`ESTADO.md`). La app
antepone el PIN ella sola.
**No hay mando, no hay pulsadores y no hay pantalla**, asi que **sin telefono no hay forma de pedirlo**
(`D-1`, `D-2`, `D-16`, `D-17.bis`). **Que contesta cada punta** (la tabla completa es SPEC 4 §3):

| respuesta | que hacer |
|---|---|
| `RESULT:OK` | entro. **Empieza el todo-rojo obligatorio de entrada** — la luz tarda, no repita |
| `RESULT:YA_ACTIVO` *(Esclavo)* | **ya estaba dentro**: esta pulsacion no encendio nada |
| `$ERR ... DESC:<motivo>` | **rechazado. Lea el motivo — dice cual falta.** Las dos tablas de A.2 |

## A.2 🔴 LAS DOS PUNTAS NO RECHAZAN POR LO MISMO, Y HAY QUE LEER CADA UNA

Medido sobre las funciones de entrada y rechazo de cada punta. **MAESTRO — seis motivos**, su `DESC:` las dos juntas:

| lo que se lee en el telefono | que falta, y que se hace |
|---|---|
| `Falta: reloj sin poner en hora` | la hora no puede decidir una luz: **fiable, no solo puesta**. Ponerle la hora a ESE poste con el telefono, o esperar la siembra de su ESP32; si no llega, mire la alarma de la hora (parte C) |
| `Falta: nunca hubo sincronizacion RF` | esta punta **jamas** hablo con la otra en esta sesion. **Arregle la radio primero** (parte B): sin una sincronizacion no hay modo |
| `Falta: la ultima sync es muy vieja` | la hubo y caduco. El plazo de frescura son **horas, no dias**, y **NO es el mismo que el del Esclavo** |
| `Falta: el esclavo no tiene el ciclo` | el otro poste no ha acusado la configuracion. **No se puede saltar**: sin ella el Maestro daria verde por reloj mientras el Esclavo cae a ambar por orfandad |
| `Falta: sin medida de desfase valida` | no hay medida de desfase utilizable (`SFTY-23`) |
| `Desfase fuera de tolerancia (+-3s)` | la hay y se sale de la tolerancia. **No se corrige a ojo** |

**ESCLAVO — seis motivos, y TRES no existen en el Maestro:**

| lo que se lee en el telefono | que falta, y que se hace |
|---|---|
| `SIN HORA VALIDA` | igual que la primera del Maestro |
| `FALTA CONFIG CICLO` | el Maestro nunca le mando la duracion del ciclo |
| `CICLO EN CERO` | 🔸 **solo aqui.** Se la mando con un verde o un despeje en cero |
| `NUNCA SINCRONIZADO` | no hubo ninguna sincronizacion en esta sesion |
| `SYNC CADUCADA >48h` | 🔸 **solo aqui, y el plazo es OTRO**: es el limite duro, mucho mas largo que el plazo de frescura del Maestro. **Obliga a arreglar la radio** |
| `AMBAR EMERG.PUESTO` | 🔸 **solo aqui, y es la que muerde** — ver el bucle de abajo |

> 🔴 **EL BUCLE DEL AMBAR ENCLAVADO, que se paga en el poste.** El plan de aborto (A.4) manda `AMBAR_EMERGENCIA` al
> Esclavo, y **ese ambar queda enclavado**: esa punta **rechaza volver a entrar en Degradado** hasta que alguien
> mande `CANCELAR_AMBAR`. **No es una averia**: la maquina no revoca sola lo que puso una persona, porque debajo
> de esa luz puede haber alguien trabajando. **El Maestro no tiene esa guarda**, asi que aceptara mientras el
> Esclavo rechaza. ⚠️ **Y de que las dos listas sean distintas sale lo peor: UNA PUNTA PUEDE ENTRAR Y LA OTRA NO**,
> que es peor que ninguna — **si la segunda rechaza, se saca a la primera** (A.4) antes de arreglar el motivo.

## A.1.bis EL TESTIGO — para cuando la radio no vuelve en semanas, no en minutos (construido, `990c278`; `D-35`)

**Cuando se usa:** el enlace entre postes está muerto y **no hay repuesto a la vista** —el de A.1 es para un corte
que se resuelve pronto—. **Una orden por poste**, `SET_MODO:DEG_T:ahora,inicio,verde,despeje` —la app manda
`SET_RTC` primero por costumbre, pero YA NO CONDICIONA el testigo: éste prueba por sí solo que el reloj del
poste coincide con el del teléfono, comparando `ahora` (SPEC 4 §3.ter trae el flujo completo, con el traslado
y el despeje)—. **Primero el Maestro, después el Esclavo** —el segundo aplica el MISMO testigo que guardó la
app en el primero, no uno nuevo, pero LEE `ahora` otra vez al enviarlo—.

| respuesta | qué hacer |
|---|---|
| `RESULT:OK` | entró. Queda en **ROJO fijo hasta `inicio`**, después alterna sola: no repita |
| `$ERR ... DESC:<motivo>` | rechazado. Lea el motivo — A.2.bis dice cuál falta |
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

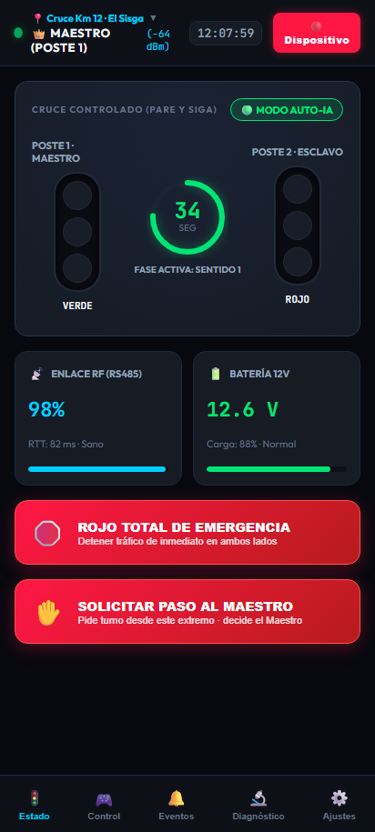
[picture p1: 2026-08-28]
evidencia/08_dashboard_telemetria_en_vivo.png

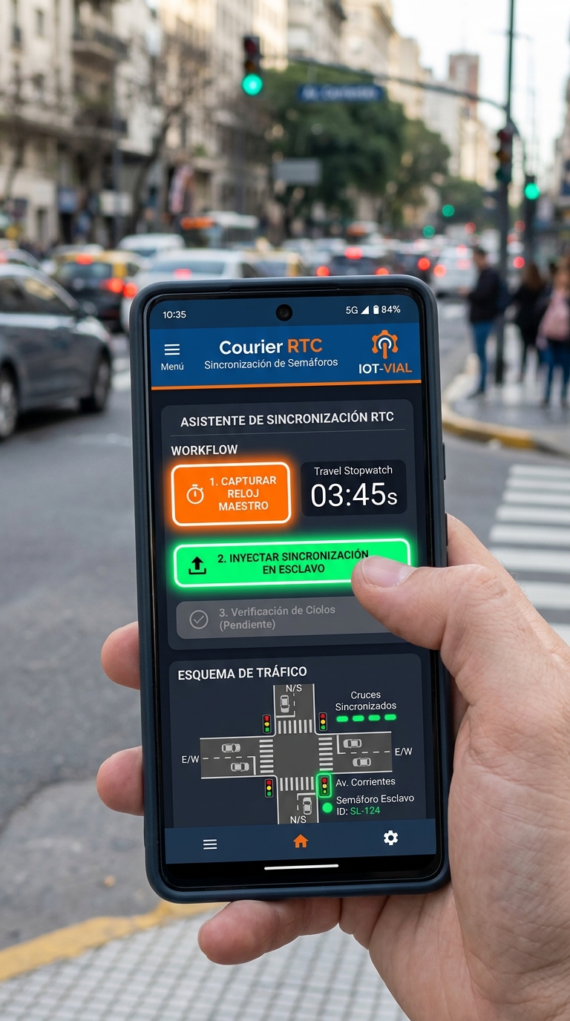
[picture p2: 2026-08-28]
05_Imagenes/app_courier_flow.jpg

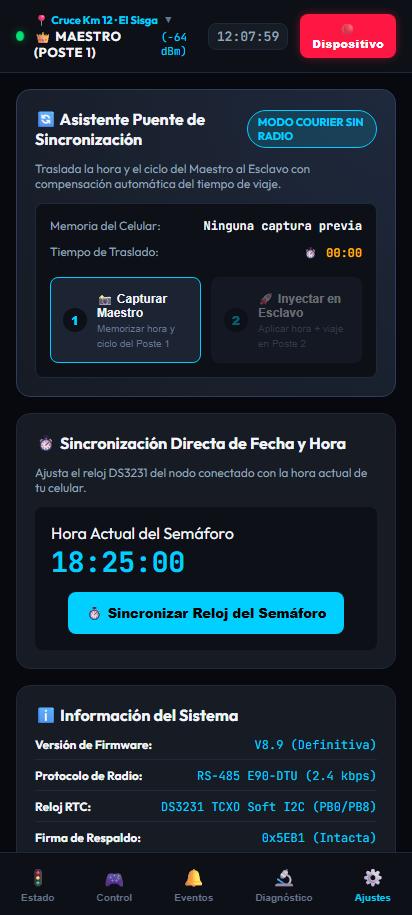
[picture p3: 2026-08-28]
evidencia/07_pestana_ajustes.png

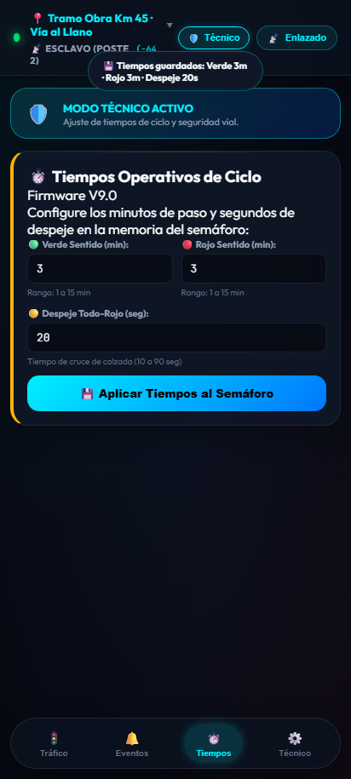
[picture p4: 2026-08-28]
evidencia/07_tiempos_guardados_exito.png

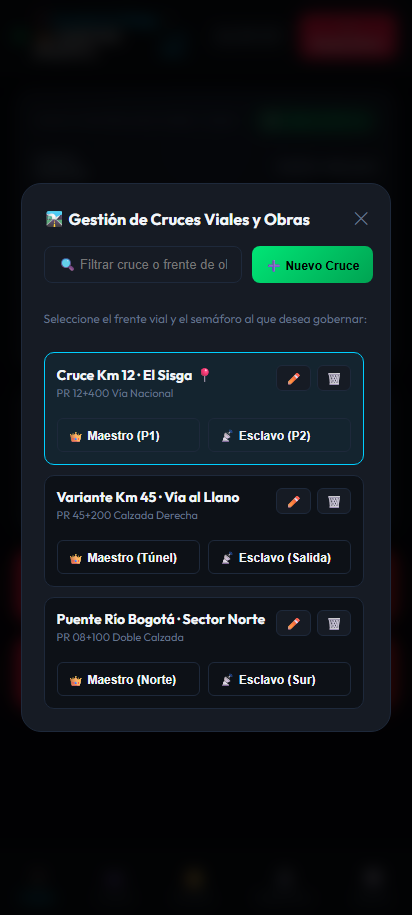
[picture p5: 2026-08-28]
evidencia/03_modal_gestor_cruces.png

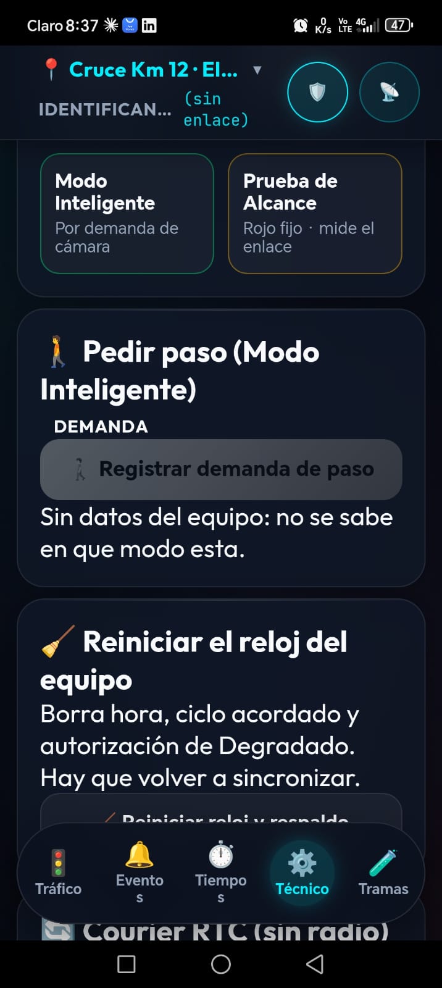
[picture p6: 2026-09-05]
evidencia/WhatsApp Image 2026-09-04 at 8.38.30 PM.jpeg

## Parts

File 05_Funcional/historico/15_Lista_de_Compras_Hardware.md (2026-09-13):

# 🛒 MANUAL 15: LISTA DE COMPRAS DE HARDWARE — QUÉ PEDIR, CUÁNTO Y CUÁNDO

**Sistema:** Controladora de Semáforos Móviles de 3 Estados (V9.0)
**Fecha:** 27 de Agosto de 2026
**Última revisión:** **11 de Septiembre de 2026 (2.ª)** — 🎯 **`D-27`: LAS CUATRO CÁMARAS ESTÁN
COMPRADAS, y `A4` pasa a ser un RELÉ DE BOBINA DE 12 V, no un módulo optoacoplado.** El responsable
cierra lo que fija la guía del Sisga: `A2` queda **cubierta entera (4 de 4)**; `J14` queda **libre y
sin cablear** (el fin de carrera no se instala, así que no se compra); y la talanquera va **como en
la guía** —bobina entre `J15` p1 y p2, contacto a `OPEN`/común de la centralita—, que es lo que
ahora pide `A4`. Detalle en el bloque de abajo, que va primero.

**Revisión anterior:** **11 de Septiembre de 2026** — 📷 **`D-25`: SON CUATRO CÁMARAS, DOS POR POSTE.**
Cambia la **cantidad** de `A2`, `A7` (cable) y `A10` (microSD), y ~~**constan compradas sólo 2**~~
*(`D-27`, 11/09: **las cuatro compradas**)*.

**Revisión anterior:** **5 de Septiembre de 2026** — ⛔ **`A9` SALE DE LA LISTA: el mando de relés y
sus pulsadores NO SE COMPRAN**, y **entra `A10`: las microSD de las cámaras**. Detalle en el bloque
rojo de abajo.

**Revisión anterior:** **4 de Septiembre de 2026** — 🔬 **primera revisión con datos de BANCO REAL
(sesión del 03–04/09), y cambia lo que se compra en cuatro sitios:**

* ~~🟢 **`A9` (receptor del mando) se PIDE, y con salida `NO` (normalmente abierto).**~~ ⛔ **CADUCADO
  EL 05/09 POR `D-1`: NO SE COMPRA NINGUNO.** Se conserva tachado con su motivo, y el motivo entero
  se conserva en el bloque `A9`, porque la cadena de razonamiento —una sola masa en `J16`, activo en
  ALTO, `NC` inseguro— **sigue siendo válida para los pines de cámara**, que sí se cablean.
* 🟢 **`A7` (cable y conector de `J16`) se DESBLOQUEA para conectar:** la medida **`M3` está cerrada
  en banco** —pull-down real de 10 kΩ, `p10` 9,93 kΩ y `p12` 9,94 kΩ—. Se compraba ya; **ahora
  además se puede enchufar**, con el pin de 12 V tapado.
* 🆕 **Aparece el bloque `E`: la REVISIÓN V2 DE LA TARJETA.** Dos líneas nuevas que **no son
  decisiones tomadas**, sino cuentas para quien firme la placa: **`E1` resistencias de 2K2** para
  proteger las cinco entradas de campo, y **`E2` un diodo de potencia** que sustituya al `D30`.
* 🛑 **`A5` (la fuente) y `A8` (la placa portadora) siguen EXACTAMENTE IGUAL que el 31/08: sin pedir,
  sin referencia elegida, sin diseñar y sin fabricar.** Cuatro días después no se ha movido nada:
  se escribe para que la fila no envejezca en silencio.

**Revisión anterior:** **31 de Agosto de 2026** — 🟢 **`BLQ-1` CERRADO: el módulo que llegó es un
`ESP32-WROOM-32` clásico y habla SPP, así que `A1′` se DESBLOQUEA.** Con ella cambian tres cosas
más: `A5` pasa a exigir **DC-DC conmutado y no lineal** (con la cuenta de disipación delante),
aparece **`A8`, la placa portadora**, que hasta hoy no era línea de compras, y el **receptor del
mando de relés sube de prioridad**, porque sin él el Esclavo se queda sin ninguna vía de mando. Lo
del 28/08 se conserva entero debajo.
**Revisión anterior:** 28 de Agosto de 2026 (3.ª del día) — 🔄 **la arquitectura cambió en obra: el
`ESP32` SUSTITUYE al módulo Bluetooth SPP, el `DS3231` deja de ir en la placa STM32 y se cuelga del
`ESP32`, y se retiran la pantalla LCD, los cuatro pulsadores y el mando de relés.** Lo que ya no se
compra queda **tachado con su motivo**, no borrado. *(2.ª rev. del 28/08: corrige la bornera de la
talanquera en A4 —decía `J14`, y `J14` es una ENTRADA del micro—; avisa de que el `DS3231` no tiene
driver; arregla las referencias a las secciones del Manual 13. 1.ª rev.: bloque 0 con el estado real
de lo recibido —llegaron ESP32, no `HC-05`—, criterio de compra del módulo Bluetooth y corrección de
`JDY-31` → `JDY-30`.)*
**Para:** el funcional / quien autoriza la compra

---

> [!IMPORTANT]
> # 🎯 11/09/2026 (2.ª) — `D-27`: CÁMARAS CUBIERTAS, Y EL RELÉ DE LA TALANQUERA ES OTRA PIEZA
>
> **Decisión del responsable, 11/09 (`DECISIONES.md` `D-27`)**, sobre `D-25`:
>
> | línea | antes de `D-27` | con `D-27` |
> |---|---|---|
> | **`A2`** cámaras | 4 pedidas, **2 compradas**, 2 `SIN VERIFICAR` | ✅ **las 4 COMPRADAS**, modelo `DS-2CD2683G2-IZS` (`D-10`) confirmado. **Nada que pedir** |
> | **`A4`** talanquera | ~~«Módulo de 1 relé optoacoplado, con jumper `JD-VCC`»~~ | 🔴 **UN RELÉ con BOBINA de 12 V DC y un contacto normalmente abierto**, uno por poste — **sin módulo optoacoplado ni `JD-VCC`**: `J15` sólo da dos hilos (p1 = 12 V, p2 = drenador de `Q10`) y no hay ni masa ni 3,3 V para alimentar la lógica de un módulo. La **rueda libre ya está en la placa** (`D30`, un `1N4148` de 200 mA — bloque `E2`): **la corriente de la bobina tiene que quedar por debajo de eso**. Qué corriente, y qué aguanta el contacto frente a la entrada `OPEN` de la centralita: `SIN VERIFICAR` — **la referencia la elige el responsable antes de pedir** |
> | fin de carrera de la pluma | *(nunca fue línea: `A-2` lo mandaba a `J14`)* | ⛔ **NO SE COMPRA en este despliegue.** `J14` queda **libre y sin cablear**: el firmware lo lee como demanda (`CAM_DEMANDA_PIN`), así que en `J14` no se conecta nada |
> | `A7` · `A10` | ver el bloque `D-25` | **sin cambio**: 2 conectores + cable para 4 cámaras; ~~4 microSD, sin comprar~~ → 🟢 **las 4 microSD COMPRADAS y en mano** *(`A-0`, 12/09: cuatro de 64 GB)* |
>
> **De dónde sale el cableado de `A4`:** `05_Funcional/Camaras_Sisga_4x.html`, apartado *«Talanquera
> en J15»* —`J15` p1 a un borne de la bobina, p2 al otro, contacto NA a `OPEN` y a su común «como diga
> el manual de esa centralita», diodo ya en la placa (`D30`)—. 🛑 **Y lo que la guía deja sin
> comprobar se queda sin comprobar aquí:** cómo responde la centralita cuando `OPEN` se queda cerrado
> o se suelta, y qué hace la pluma sin energía. **Ninguna cámara la frena.**
>
> ⚠️ **Sin cambio en `E2`**: el diodo de potencia en lugar del `D30` sigue siendo **una propuesta
> para la V2** de la placa, escrita para una carga de motor; con `D-25`/`D-27` la carga de `J15` es
> una bobina de relé, y **si la V2 lo sigue necesitando es una pregunta, no una compra**.

> [!IMPORTANT]
> # 📷 11/09/2026 — `D-25`: CUATRO CÁMARAS, DOS POR POSTE. LA CANTIDAD CAMBIA ~~Y NO ESTÁ CUBIERTA~~ *(`D-27`: cubierta)*
>
> **Decisión del responsable, 11/09 (`DECISIONES.md` `D-25`):** *«mantener estas conexiones como
> definitivas»*. En **cada** poste:
>
> | | señal | 3,3 V | pin del micro |
> |---|---|---|---|
> | **cámara 1** | `J16` **p10** | `J16` **p9** | `PB14` · `CAM_C_PIN` |
> | **cámara 2** | `J16` **p12** | `J16` **p11** | `PB15` · `CAM_D_PIN` |
> | **talanquera** | `J15` **p1** = 12 V · **p2** = drenador de `Q10` (**NO es masa**: con `Q10` abierto está a ~12 V) | — | `PB2` · `MOTOR_TALANQUERA` |
>
> La talanquera va a la **bobina de un relé** entre `J15` p1 y p2, y el **contacto** de ese relé a la
> entrada **`OPEN`** de la centralita de la barrera. **Deroga de `D-13` SÓLO «una cámara por poste» y
> el `p12` vacío**; el resto de `D-13` sigue: las cuatro con la misma configuración.
>
> **Lo que cambia en esta lista, línea a línea:**
>
> | línea | antes | con `D-25` | qué consta |
> |---|---|---|---|
> | **`A2`** cámaras | 2 | **4** | ~~🔴 **compradas constan 2** (fila `A2`, 05/09). **Las otras 2: `SIN VERIFICAR` con compras.**~~ → 🟢 **`D-27` (11/09): las 4 compradas.** Y el modelo está marcado **`Discontinued`** en la web del fabricante (05/09): ~~**esas 2 son las que ese aviso afecta**~~ *(con las cuatro ya compradas, afecta sólo a repuestos)* |
> | **`A7`** conexión a `J16` | 2 juegos | **2 conectores** *(uno por tarjeta)* **+ cable de 2 hilos para 4 cámaras** | sin pedir |
> | **`A10`** microSD | 2 | **4** *(una por cámara)* | ~~sin comprar~~ → 🟢 **COMPRADAS**, cuatro de **64 GB** *(`A-0`, 12/09)* |
> | **`A4`** relé de talanquera | 2 | **2** *(uno por poste, no cambia)* | ⚠️ ver la nota de la fila `A4`: el tipo de relé pedido **no casa** con dos hilos en `J15` · 🟢 **`D-27`: se cambia la pieza** — relé de bobina 12 V DC, contacto NA (bloque `D-27` de arriba) |
> | energía de cámara por poste | 13 W | **2 × 13 W = 26 W** *(máximo de ficha)* | es un número para quien dimensiona batería y panel — ver el bloque 📷 de `A2` |
>
> 🛑 **LO QUE LA SEGUNDA CÁMARA NO ES, y quien firma la compra tiene que saberlo** (medido el 11/09
> en el firmware, `botones.cpp` y `semaforo.cpp` de las dos puntas):
>
> 1. **Hace LO MISMO que la primera.** Las dos entradas se recorren en el mismo bucle
>    (`CAM_J16[2] = {CAM_C_PIN, CAM_D_PIN}`): piden paso y las vigila el mismo vigilante. No hay una
>    «de demanda» y otra «de presencia».
> 2. **NO protege la pluma.** `escribirPines()` sube la pluma con `(verde && !testLedsActivo) ||
>    estado == S_FALLO` y **no lee ninguna cámara**: la pluma baja aunque haya un coche debajo, y sube
>    también con el ámbar intermitente. El veto es `A-1.bis`, **sin construir**. **No es la «segunda
>    cámara por poste de SFTY-29»** que esta lista citaba: SFTY-29 sigue siendo **sólo diseño**.
> 3. **Una cámara que no ha detectado nunca nada no la vigila nadie.** El vigilante y el campo `CAM:`
>    se saltan el pin que nunca dio un flanco —exención escrita cuando `p12` iba vacío a propósito—, y
>    la app pinta *«OK — las dos ven»* con la primera detección de **cualquiera** de las dos. **Cada
>    cámara se comprueba con el multímetro en su borne** al montarla.
>
> ⚠️ **Y `p12` es el borne de `J16` más cercano a la red de 12 V** (`1,359 mm` de cobre, `03_Hardware_Tarjeta/MAPEO_TARJETA_KICAD.md` §7.bis). Con
> `D-25` ahí va una cámara: **el p1 de `J16` se tapa en cada equipo** (`D-4`), y el tapón va en `A7`.

> [!IMPORTANT]
> # ⛔ 05/09/2026 — DOS CAMBIOS QUE SE EJECUTAN CON DINERO. LÉASE ANTES DE EMITIR NINGUNA ORDEN
>
> ## 1. 🛑 `A9` SALE: **EL MANDO DE 4 RELÉS Y LOS PULSADORES NO SE COMPRAN — Y NO ES UNA PIEZA PENDIENTE**
>
> **`DECISIONES.md` `D-1`, confirmada por el responsable el 05/09:** *«ya no tenemos mandos de A y B,
> sólo la app, los quitamos»*.
>
> **Esto NO es «está pendiente», NO es «se compra después del banco» y NO es «falta decidir la
> referencia». Es una decisión tomada: no se compra, ni ahora ni luego.** Se escribe con estas
> palabras porque la línea `A9` llevaba desde el 31/08 subiendo de prioridad y el 04/09 volvió al
> «se pide»: **quien lea una copia impresa de cualquiera de esas dos revisiones va a pedir dos
> receptores RF que ya no tienen para qué**.
>
> | | qué se compra |
> |---|---|
> | Receptor RF del mando *(línea `A9`)* | ⛔ **NADA. Cero unidades** |
> | Emisor de 4 canales | ⛔ **nada — el que había se retiró con el mando** |
> | Pulsadores de `J16` p5 y p8 | ⛔ **nada. Los pines quedan LIBRES y sin cablear** |
>
> 🛑 **Y LA OTRA MITAD, QUE VA PEGADA A ÉSTA O EL LECTOR SACA LA CONCLUSIÓN CONTRARIA: el CÓDIGO del
> mando NO se retira.** Es firmware, no compras, pero se escribe aquí porque *«ya no compramos el
> mando»* invita directamente a *«pues quitemos su código»*, y eso **abre el veto de SFTY-21 en vez
> de dejarlo inerte**. Con el mando desmontado la bandera simplemente **no se arma nunca**, que es lo
> correcto. El desarrollo está en el **Manual 2 §6**.
>
> ### 📵 Y la consecuencia de operación que esta lista tiene que declarar, porque nace de una compra que NO se hace
>
> **Retirado el mando, la app es la ÚNICA superficie de mando del equipo** (`D-16`). Ni ámbar, ni
> volver a Automático, ni parar el cruce sin un teléfono. **Lo que esta lista puede hacer al respecto
> es una sola cosa, y no cuesta casi nada: que haya un SEGUNDO TERMINAL ya emparejado** —con su cable
> de carga— **antes de que un equipo salga a la calle**. No se pide como electrónica; se pide como
> herramienta, igual que la escalera.
>
> ## 2. 🆕 `A10` ENTRA: **LAS microSD DE LAS CÁMARAS SE COMPRAN**
>
> **Decisión del responsable, 05/09:** *«cada cámara tiene una micro, la metemos»*. Deja de ser la
> pregunta `A-0` en su primera mitad: **se compran, una por cámara — ~~2 unidades~~ → 4 unidades
> (11/09, `D-25`: cuatro cámaras).** Ver la línea
> **`A10`** en el bloque **A**.
>
> ⚠️ **Lo que la decisión NO cierra, y sigue en `A-0` de `DECISIONES.md`:** ~~**capacidad**,~~ **días de
> retención** y **si la grabación va continua o por evento**. ~~Se puede comprar sin cerrarlas —una
> tarjeta grande sirve para las tres respuestas—~~ **pero no se puede configurar la cámara sin ellas**.
>
> 🟢 **12/09 — YA NO SE COMPRAN: ESTÁN COMPRADAS.** El responsable: *«ya están compradas, con SD de
> 64 GB, son 4 ya»*. **La capacidad deja de ser pregunta: 64 GB.** ⚠️ **Sin verificar si son
> `high endurance`.**
>
> ---
>
> # 🔬 04/09/2026 — LO QUE EL BANCO CAMBIÓ EN ESTA LISTA
>
> **Es la primera vez que esta lista se corrige con una tarjeta delante y no con el fuente.** Se lee
> antes que el resto porque **una copia impresa de la revisión del 31/08 se ejecuta con dinero y le
> falta lo de abajo**.
>
> ## 1. ~~🟢 `A9` — se PIDE, con salida `NO`~~ ⛔ **NO SE PIDE (05/09, `D-1`).** El mando **estuvo** sordo, ya no lo está en el fuente, **y ya no está**
>
> 🛑 **Todo este apartado queda como HISTÓRICO: cierra `N-118` y no autoriza ninguna compra.** Se
> conserva entero porque explica por qué durante cuatro días se creyó que había un defecto de placa,
> y esa confusión es la que no debe volver.
>
> **EL DEFECTO, en pasado — es lo que midió el banco el 03–04/09 sobre el firmware `617bd00`:**
> `R65`/`R66` —10 kΩ a masa, el mismo cobre que las entradas de cámara— dejan el pin en **0,6 V**.
> Aquel firmware leía `INPUT_PULLUP` y activo en **BAJO**, así que veía **BAJO permanente** y el
> arranque lo sembraba como **«flanco ya consumido»**: **nunca había transición**. No era que el
> mando funcionara mal — **es que no había gesto que lo activara** (N-118).
>
> **EL ESTADO DE HOY:** 🟢 **el firmware está arreglado en las DOS puntas** (`346ea5f`), verificado
> por lectura el 05/09 sobre los símbolos, no sobre números de línea:
>
> ```text
>   RE-CORRIDO EL 07/09 -- los cuatro renglones se movieron; el hallazgo, no
>
>   $ grep -n "pinMode(BOTON1, INPUT)" Maestro/src/botones.cpp Esclavo/src/botones.cpp
>   Maestro/src/botones.cpp:521:  pinMode(BOTON1, INPUT);        (decia :160)
>   Esclavo/src/botones.cpp:507:  pinMode(BOTON1, INPUT);        (decia :178)
>
>   $ grep -n "lecturaCruda = " Maestro/src/botones.cpp Esclavo/src/botones.cpp
>   Maestro/src/botones.cpp:42:  bool lecturaCruda = (digitalRead(b.pin) == HIGH);   (decia :40)
>   Esclavo/src/botones.cpp:56:  bool lecturaCruda = (digitalRead(b.pin) == HIGH);   (decia :54)
> ```
>
> Exactamente como la cámara en N-67. 🔴 **Y nadie lo volvió a medir con el binario nuevo dentro:**
> el paso 29 se abortó y la Maestro sigue con el corto de N-116. **Esa medida queda `SIN VERIFICAR` y
> ya no se va a tomar** — porque no hay mando.
>
> ⚠️ ~~**Y con el arreglo cambia EL GESTO DE PRUEBA:** cerrar contra los 3,3 V del pin contiguo,
> `p5`–`p4` y `p8`–`p7`.~~ ⛔ **CADUCADO EL 05/09: no hay mando, así que no hay gesto.** **`p5` y `p8`
> quedan libres y NO se les acerca un cable** — ni para probar: `p4` es adyacente a `p5` y un puente
> corrido una posición pone 3,3 V contra masa, que es el candidato del calentamiento del paso 29.
>
> 🟢 ~~**Y de ahí sale una DECISIÓN DE COMPRA que no está tomada: `NO` o `NC`.**~~ → **CADUCADA el
> 04/09 (no era una decisión: la decide el cobre) y AMORTIZADA el 05/09 (no hay compra).** ✅ **Lo que
> del razonamiento sigue vigente y por eso no se borra: los cuatro pines de `J16` son eléctricamente
> idénticos y todos son ACTIVOS EN ALTO** —una sola masa en el conector (`p2`), 3,3 V en cada
> posición contigua—. **Eso gobierna hoy el cableado de las CÁMARAS** (`A7`), que sí se conectan.
>
> ## 2. 🟢 `A7` — `M3` CERRADA: las cámaras de `J16` ya se pueden CONECTAR
>
> ```text
>   M3, paso 20, tarjeta energizada y J16 vacio:
>     J16 p10 (PB14) ->  9,93 kOhm a masa  ->  0 V
>     J16 p12 (PB15) ->  9,94 kOhm a masa  ->  0 V
>   Paso 21: en reposo, CON y SIN el cable puesto, el equipo NO pide paso solo.
> ```
>
> **El pull-down de 10 kΩ es real.** Esta lista decía *«el cable se compra hoy; conectarlo espera a
> `M3`»* — **ya no espera**. La polaridad la decide el cobre: **activo en ALTO**, contacto contra los
> 3,3 V del borne contiguo. Detalle completo en el **Manual 9**.
>
> ## 3. 🛑 EL AVISO QUE ACOMPAÑA A TODO LO QUE SE ENCHUFE EN `J16`
>
> **`J16` p1 lleva 12 V CRUDOS, y las 5 entradas de campo van DESNUDAS al pin del STM32** —sin
> resistencia en serie, sin opto, sin clamp—, mientras que **las 9 salidas de la placa sí llevan
> 220 Ω y optoacoplador**. **Tapar físicamente el pin de 12 V de `J16` es OBLIGATORIO en cada equipo
> antes de cablear.** El 04/09 **una tarjeta Maestro quedó con un cortocircuito de 3,3 V a masa**;
> esto es lo único que hay entre un instalador y que vuelva a pasar.
>
> **Eso no es una compra: es un gesto de montaje.** La compra que lo corrige de verdad es el bloque
> **`E`**, y es de la **revisión V2 de la placa**.
>
> ## 4. ⏸️ Lo que NO se movió en cuatro días, y por eso se escribe
>
> | | estado al 31/08 | estado al **04/09** |
> |---|---|---|
> | **`A5`** fuente DC-DC conmutada | sin pedir, sin referencia elegida | **igual** |
> | **`A8`** placa portadora | sin pedir, sin diseñar, sin dueño | **igual** |
> | **`A1′`** conteo de pines (30/38) y cuántos hay en almacén | sin contar | **igual** |
>
> **Una fila que no cambia no es una fila cerrada.** `A5` y `A8` siguen siendo lo que **BLOQUEA EL
> MONTAJE** del `ESP32`, y las dos se pueden empujar hoy sin esperar a nadie.

---

> [!IMPORTANT]
> # 🟢 31/08/2026 — `BLQ-1` ESTÁ CERRADO: LA LÍNEA `A1′` SE DESBLOQUEA
>
> **El módulo que llegó a obra es un `ESP32-WROOM-32` clásico.** La ficha del artículo comprado
> —aportada por el responsable— lo declara con **tres confirmaciones independientes**, y las tres
> apuntan al mismo silicio:
>
> ```text
> Microcontrolador ...  ESP32-WROOM-32
> CPU ................  Tensilica Xtensa 32-bit LX6, DUAL-CORE
>                       el S3 es LX7 y el C3 es RISC-V -> no es ninguno de los dos
> Bluetooth ..........  v4.2 BR/EDR and Bluetooth Low Energy (BLE)
>                              ^^^^^^ Bluetooth Clasico
> ```
>
> **`BR/EDR` es Bluetooth Clásico, o sea SPP.** Es exactamente el perfil que necesita
> `createRfcommSocketToServiceRecord` del puente nativo de Android: **la app conecta sin tocar una
> línea de transporte**, y **el apartado 1 del Manual 10 no se reabre**. 📄 **LEÍDO** de la ficha del
> artículo, no medido con `esptool` ni con la serigrafía en la mano — ver `roadmap.md` **N-107** y
> `ESTADO.md` (fila `BLQ-1`).
>
> ### Lo que eso cambia en esta lista, y lo que NO
>
> | | |
> |---|---|
> | ✅ **`A1′` deja de estar 🛑 BLOQUEADA** | El módulo que hay sirve. **La cantidad que hay en almacén sigue sin anotarse** |
> | ✅ **La vía WiFi queda descartada** | No hay que reabrir el Manual 10 §1. Era la rama cara y ya no está sobre la mesa |
> | ✅ **La alimentación queda fijada por la propia ficha** | `12 V → DC-DC **conmutado** → 5 V → `VIN`` (entrada recomendada 5 V, límite 5,5 V, con regulador a bordo). Ver `A5`, que **cambió** con este dato |
> | ✅ **Las E/S del módulo son de 3,3 V** | El enlace con el STM32 por `J17` va **directo, sin adaptador de niveles**. No hay que comprar traductor |
> | 🛑 **NO se compra ni un `ESP32` más todavía** | **El bloqueo cambió de motivo, no desapareció:** ahora es el **conteo de pines**. Ver el aviso de abajo |
>
> ### 🛑 Lo que HOY bloquea comprar más módulos: 30 pines o 38, y no es lo mismo
>
> **Estas NodeMCU vienen en dos formatos, de 30 y de 38 pines, con anchos de placa distintos** — y
> la placa portadora (`A8`) lleva **hembrillas**, no la huella del `WROOM-32`. Un módulo de 38 pines
> no entra en unas hembrillas dimensionadas para 30, y al revés queda con filas al aire.
>
> **Se cuentan los pines y se mide el ancho con pie de rey ANTES de fabricar la portadora.** Es lo
> único que bloquea el taladro, y **no bloquea firmware** — el firmware del ESP32 es el mismo en los
> dos formatos. **Se anota aquí, con fecha y quién lo contó:**
>
> ```text
> Fecha: ____________   Contado por: ____________________
> Pines por fila:  [ ] 15 (placa de 30)   [ ] 19 (placa de 38)
> Ancho de placa medido con pie de rey: ________ mm
> Separacion entre filas (centro a centro): ________ mm
> Cuantos modulos hay en almacen: ______
> ```
>
> > ⚠️ **Y por qué no se compra «uno más por si acaso» antes de contarlos:** si el segundo pedido
> > llega en el otro formato, la portadora sirve para uno de los dos postes. Dos referencias
> > distintas en el mismo cruce es exactamente lo que este documento lleva un mes evitando.
>
> ### La lección de N-107, que se queda escrita porque cuesta dinero repetirla
>
> **El bloqueo se mantuvo más días de los necesarios por exigir la medida más cara.** Se pidió
> durante toda una sesión *«la serigrafía del blindaje, 30 segundos»* cuando **la ficha técnica del
> artículo comprado ya lo declaraba** y estaba a mano desde el principio.
>
> > **Antes de declarar algo bloqueado por una medida física, censa qué fuentes escritas pueden
> > responderlo ya.** Una ficha de compra, una factura, una serigrafía y un `esptool chip_id`
> > contestan la misma pregunta con costes muy distintos, y **la más cara no es la primera que hay
> > que pedir**. Un bloqueo que se levanta leyendo no es un bloqueo: es una consulta pendiente.

> [!CAUTION]
> # 🔄 28/08/2026 — LA ARQUITECTURA CAMBIÓ. ESTO SE LEE ANTES QUE EL RESTO DEL DOCUMENTO
>
> **El `ESP32` pasa a SUSTITUIR al módulo Bluetooth SPP —ya no se compran `HC-05` ni `JDY-30`—, el
> `DS3231` se cuelga del `ESP32` por I²C con pila propia en vez de montarse en la placa STM32, y se
> retiran la pantalla LCD, ~~los cuatro pulsadores y el mando de relés~~.**
>
> > 🔴 **ESA ÚLTIMA FRASE ESTÁ CORREGIDA DESDE EL 31/08 Y NO SE EJECUTA LITERAL.** Por decisión del
> > responsable: **se retiran SÓLO los pulsadores 3 y 4** (`PB14`/`PB15`), y **el MANDO DE RELÉS SE
> > CONSERVA** en los canales A (`PB9`) y B (`PB13`). **Retirar el mando entero no dejaba código
> > inerte: borraba un veto de seguridad** —el que impide que una orden de radio saque al Esclavo de
> > un ámbar que un operario dejó puesto a propósito—. ~~**Y de la corrección sale una línea de compra
> > nueva: `A9`, el receptor RF del mando, que nunca se compró.**~~
> >
> > 🔧 **05/09 — LA CORRECCIÓN SE CORRIGE A SU VEZ, Y CONVIENE VER LAS DOS MITADES POR SEPARADO
> > PORQUE UNA SOBREVIVE Y LA OTRA NO:** el responsable retiró **el hardware** del mando (`D-1`), así
> > que **`A9` queda anulada: cero unidades**. Pero *«retirar el mando entero no dejaba código
> > inerte: borraba un veto de seguridad»* **sigue siendo exactamente cierto**, y es hoy el motivo de
> > que **el código NO se toque** aunque el aparato ya no exista.
>
> **Todo lo que aparece ~~tachado~~ más abajo es de la arquitectura anterior: no se compra, y lleva
> el motivo escrito al lado.** No se borra a propósito — una línea borrada vuelve a proponerse
> dentro de un mes y nadie recuerda que se descartó; una línea tachada con su porqué, no.

> [!CAUTION]
> ### 🩹 FE DE ERRATAS DEL 28/08/2026 — 🔴 **LA FILA A4 MANDABA CABLEAR LA TALANQUERA A `J14`**
>
> **Si ya se cableó un módulo de relé de talanquera a `J14` siguiendo la versión anterior de esta
> lista: DESCONECTARLO ANTES DE ENERGIZAR.** No es un error de compra —el relé pedido es el
> correcto—, es un error de **dónde se conecta**.
>
> | | decía la lista | es |
> |---|---|---|
> | Bornera | **`J14`** ❌ | **`J15`** ✅ |
> | Red | `Puerta` ❌ | `Motor` ✅ |
> | Pin | — | `PB2` (`MOTOR_TALANQUERA`) |
>
> * **`J14` es ~~la ENTRADA de la cámara de demanda~~ una ENTRADA del micro** (`PB0`, `CAM_DEMANDA_PIN`), con `R64` 10 kΩ y
>   `C25` 100 nF de antirrebote. **Meterle los 12 V de un relé destruye el STM32**, que es el micro
>   que gobierna el semáforo — y además la pluma no se movería, porque `J14` no tiene etapa de
>   salida.
>   ✏️ **11/09 — «de la cámara» ya no vale:** las cámaras van a `J16` (`D-2`/`D-3`; con `D-25`, dos
>   por poste en p10 y p12) y ~~**`A-2` reservó `J14` al fin de carrera de la pluma**. 🔴 **CONFLICTO
>   ABIERTO, no se resuelve aquí:**~~ el firmware **sigue leyendo `PB0` como `CAM_DEMANDA_PIN`** —el
>   Maestro por nivel en el Modo Inteligente, el Esclavo por flanco y lo manda como demanda por
>   radio—, así que un fin de carrera en `J14` **se leería como coches pidiendo paso**. ~~Es del
>   responsable.~~ → 🟢 **`D-27` (11/09): `J14` LIBRE, sin cablear — el fin de carrera no se instala
>   en este despliegue y no se compra.** En `J14` no se conecta nada.
> * **La talanquera SALE por `J15`:** `PB2` → opto `U15` → MOSFET `Q10` → `J15`. Es un canal de
>   potencia propio, ya montado en la placa.
> * **Medido** el 28/08 en `01_Firmware/Maestro/include/pines.h` (líneas 31 y 46). El **Manual 13
>   §3 siempre lo dijo bien**; lo que estaba mal era la §5 de aquel manual y esta fila A4, y las dos
>   se han corregido hoy.
> * **La errata no se borra: queda escrita con su fecha**, porque quien haya cableado siguiendo la
>   versión vieja tiene que poder enterarse.
>
> **De dónde salió el error, para no repetirlo:** la red de `J14` se llama **`Puerta`** en el
> esquemático, y «puerta» suena a talanquera. **No lo es: es ~~por donde la cámara pide paso~~ una
> entrada** *(11/09: ~~reservada al fin de carrera por `A-2`, y leída por el firmware como cámara —
> conflicto abierto, ver arriba~~ → leída por el firmware como demanda, y **libre y sin cablear** por
> `D-27`)*.

> ### Por qué existe este documento, y qué NO es
>
> La compra estaba repartida en **siete manuales** (el 4 las radios, el 7 las antenas, el 9 las
> cámaras, el 10 los módulos Bluetooth, el 11 la pila del reloj, el 13 la placa de expansión). Un
> listado repartido es como se olvida una línea, y como se compra dos veces la misma.
>
> **Esto es un índice con cantidades y decisión, no una copia de las especificaciones.** De cada
> línea, la especificación completa —modelo exacto, conector, tolerancias— vive en su manual, y ahí
> se lee antes de pedir. Copiarla aquí crearía una segunda versión que alguien tendría que
> sincronizar a mano, que es exactamente el defecto que este proyecto lleva un mes cerrando.

> ### 🛑 La regla que decide qué entra en esta lista
>
> **No se compra hardware para una función que el firmware no ejecuta.** Se ha pagado dos veces por
> saltársela: `PB8` estuvo en cuatro manuales como *«umbral de tramo»* con el pin **sin leer** (N-59),
> y la placa de expansión iba a llevar chip para dos funciones que **ya están en el cobre** de la
> tarjeta (N-63). Por eso hay bloques separados y no una lista sola: **A** lo que se pide, **B** lo
> que espera al banco, **C** lo que ya está en servicio y **D** —nuevo el 28/08— **lo retirado, que
> se escribe en vez de borrarse**, y **E** —nuevo el **04/09**— **lo que necesita una
> revisión V2 de la placa: cuentas para quien la firme, no compras autorizadas**.

---
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

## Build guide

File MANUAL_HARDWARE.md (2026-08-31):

# ⚙️ Manual de Hardware y Topología Física (V7.6 Definitiva)

Este documento describe la arquitectura física de las placas impresas (PCBs), los componentes electrónicos, y la topología de red utilizada en el ecosistema de semáforos móviles.

**Última revisión:** 31 de agosto de 2026 — **el apartado 3 (cámaras) estaba MAL y se ha corregido.**
Llamaba a `PB8` *«Entrada Libre»* y mandaba enchufarle una cámara: `PB8` es el **`LED_TESTIGO`**, una
salida por `R16` 1 kΩ al LED `D5`. Y mandaba las cuatro cámaras contra `GND` cuando la entrada es
**activa en ALTO**. Es `N-105` de [`roadmap.md`](roadmap.md). El texto viejo queda **tachado en su
sitio con el motivo, no borrado**.

---

## 1. Topología de Comunicaciones y Conexión de Radios RS485

Para superar los obstáculos del terreno (montañas, maquinaria, polvo), el sistema utiliza radios industriales **E90-DTU (RS485/232 $\leftrightarrow$ RF)**.

```text
+------------------------+        2 Hilos RS485       +------------------------+
| Tarjeta Semáforo STM32 |                            |     Radio E90-DTU      |
|  (MAX3485 Integrado)   |                            |   (Caja Metalica RF)   |
|                        |                            |                        |
|        Bornera A  ----|----------------------------|----> Pin 485_A         |
|        Bornera B  ----|----------------------------|----> Pin 485_B         |
|                        |                            |      Pin V+ (12-24V)   |
|        GND / V-   ----|----------------------------|----> Pin V-            |
+------------------------+                            +------------------------+
```

### 💡 Reglas Inquebrantables de Cableado:
1. **La PCB del Semáforo ya incluye el integrado MAX3485:** Convierte las señales TTL del STM32 (`PB10`, `PB11`, `PB12`) a bus diferencial RS485.
2. **Conexión de solo 2 hilos de datos hacia la radio E90-DTU:**
   - Bornera **`A`** de la Tarjeta Semáforo $\rightarrow$ Pin **`485_A`** de la radio E90-DTU.
   - Bornera **`B`** de la Tarjeta Semáforo $\rightarrow$ Pin **`485_B`** de la radio E90-DTU.
   - **`V+`** y **`V-`** para alimentación de 12V/24V de la radio.
3. **Autoconmutación TX/RX:** La radio E90-DTU realiza la conmutación de dirección RS485 automáticamente por hardware. NO se requiere cablear pines DE/RE hacia la radio.

---

## 2. Topologías de Red Soportadas (Transparente Automático)

El firmware V7.6 en las placas STM32 es 100% agnóstico a la topología de red instalada:

### Opción A: Modo Directo (2 Radios - Línea de Vista)
- **Maestro:** Conectado por bornera A/B a Radio 1 (Frecuencia 170.0 MHz).
- **Esclavo:** Conectado por bornera A/B a Radio 2 (Frecuencia 170.0 MHz).
- **Operación:** Transmisión directa transparente por aire. No requiere la tarjeta Repetidor ESP32.

### Opción B: Modo Repetidor (4 Radios - Esquinas Ciegas / Montaña)
- **Maestro:** Conectado a Radio 1 (Frecuencia 170.0 MHz).
- **Repetidor ESP32 (Físico Back-to-Back V7.6):**
  - Radio B1 en 170.0 MHz (Habla con el Maestro).
  - Radio B2 en 172.0 MHz (Habla con el Esclavo).
  - El ESP32 reenvía tramas con temporizador de ráfaga inter-byte de 15ms y 2ms de estabilización RS485 en `01_Firmware/Repetidor`.
- **Esclavo:** Conectado a Radio 4 en 172.0 MHz.

### Opción C: Modo Cable Físico Directo (Respaldo si el radio no va)
- **Maestro:** Bornera `RS485_OUT` (Pines A, B, GND).
- **Esclavo:** Bornera `RS485_OUT` (Pines A, B, GND).
- **Conexión:** Cable trenzado directo 3 hilos (A con A, B con B, GND con GND).
- **Operación:** Comunicación cableada transparente sin necesidad de radios.

---

## 3. Integración de las Cámaras IA de Demanda Vehicular

> ## 🛑 AVISO — `PB8` **NO** ES UNA «ENTRADA LIBRE». ES UNA **SALIDA A LED** (31/08/2026)
>
> Este apartado llamaba a `PB8` *«Entrada Libre»* y mandaba enchufarle ahí la Cámara 2 y la Cámara 4.
>
> **MEDIDO EN EL FUENTE** (`01_Firmware/Maestro/include/pines.h:63`, línea idéntica en el Esclavo):
>
> ```
> #define LED_TESTIGO        PB8  // -> R16 1K -> LED D5. NO es entrada de camara
> ```
>
> `PB8` sale por **`R16` de 1 kΩ al LED `D5`**. No es bornera, no es entrada optoacoplada y no hay
> dónde enchufar un contacto seco. El firmware lo deja **en alta impedancia a propósito**
> (`01_Firmware/Maestro/src/modo_inteligente.cpp:50`): con `INPUT_PULLUP` se le colarían ~40 µA y
> quedaría un testigo encendido a medias que nadie sabría explicar.
>
> **Y el `GND` de las cuatro líneas también estaba mal.** La entrada de cámara es
> **activa en ALTO** (`modo_inteligente.cpp:25`, `:46`) y la bornera saca el pin **junto a 3,3 V**:
> cableada contra masa, **la cámara no dispara nunca**. Es `N-105`; ver el detalle y las dos
> configuraciones de la salida de la cámara en [`MANUAL_USUARIO.md`](MANUAL_USUARIO.md) §6.3.
>
> Es la **tercera** vez que este proyecto publica un pin como libre sin cruzarlo contra `pines.h`
> (`N-59`, `N-67`, y ésta). **«Pin libre» no es una observación: es una medida contra `pines.h`.**

### 3.1 ~~El cableado que este apartado mandaba hacer~~ — ⛔ ANULADO, CONSERVADO COMO RASTRO

* ~~**En el Semáforo Maestro (Extremo 1):**~~
  * ~~**Cámara 1 (Demanda Sentido 1):** Contacto seco `1A`/`1B` conectado a **`PB0`** (Entrada Libre) y **`GND`**.~~
  * ~~**Cámara 2 (Umbral Tramo 1):** Contacto seco `1A`/`1B` conectado a **`PB8`** (Entrada Libre) y **`GND`**.~~
* ~~**En el Semáforo Esclavo (Extremo 2):**~~
  * ~~**Cámara 3 (Demanda Sentido 2):** Contacto seco `1A`/`1B` conectado a **`PB0`** (Entrada Libre) y **`GND`**.~~
  * ~~**Cámara 4 (Umbral Tramo 2):** Contacto seco `1A`/`1B` conectado a **`PB8`** (Entrada Libre) y **`GND`**.~~
* ~~**Independencia de Buses:** Los pulsos de detección entran por las entradas dedicadas `PB0` y `PB8` sin interferir con los botones del panel LCD (`PB9`, `PB13`, `PB14`, `PB15`)…~~
  ⛔ **Falso por partida doble:** `PB8` no es entrada, y `PB14`/`PB15` **dejan de ser botones** y pasan
  a ser justamente las entradas de cámara (`N-104`). Lo que **sí** sigue siendo cierto es que nada de
  esto toca el bus de sincronización `RS485_OUT`.

### 3.2 ✅ El reparto real de estos pines

| pin | qué es de verdad | nivel |
|---|---|---|
| **`PB0`** | **`CAM_DEMANDA_PIN`** — la **única** entrada de cámara con firmware que la lee hoy. Bornera **`J14`**, con `R64` 10 kΩ (*pull-**down***) + `C25` 100 nF = antirrebote por hardware de 1 ms | ✅ **MEDIDO** (`pines.h:43-46`; se lee en `modo_inteligente.cpp:98`, `:136` y `Esclavo/src/main.cpp:350`) |
| **`PB8`** | **`LED_TESTIGO`** — salida por `R16` 1 kΩ al LED `D5`. **No es entrada de nada** | ✅ **MEDIDO** (`pines.h:63`) |
| **`PB9`** (`J16` p5) | **`BOTON1` = `MANDO_A`** del mando de relés. **Se conserva** (`N-104`) | ✅ **MEDIDO** (`pines.h:92`, `botones.cpp:119`) |
| **`PB13`** (`J16` p8) | **`BOTON2` = `MANDO_B`**. **Se conserva** — es el único canal que arma `ambarLocal` | ✅ **MEDIDO** (`pines.h:93`, `botones.cpp:120`, `Esclavo/src/mando.cpp:129-132`) |
| **`PB14`** (`J16` **p10**) | Hoy `botonAceptar()`. **Destino decidido de cámara** tras la Fase 3 | ✅ **MEDIDO** hoy (`pines.h:94`, `botones.cpp:131`) · 📖 **LEÍDO** el destino (`ESTADO.md:83`) |
| **`PB15`** (`J16` **p12**) | Hoy `botonCancelar()`. **Destino decidido de cámara** tras la Fase 3 | ✅ **MEDIDO** hoy (`pines.h:95`, `botones.cpp:132`) · 📖 **LEÍDO** el destino (`ESTADO.md:83`) |

> 🔴 **`PB9`/`PB13` no son un destino posible para una cámara, ni siquiera «provisionalmente».** Son
> los dos canales del mando: tres pulsos dentro de la ventana de **12 s** (`mando.cpp:38`) componen
> una secuencia —`A·A·A` = Modo Automático, `B·B·B` = Ámbar y armado de `ambarLocal`—, así que **el
> tráfico cambiaría el modo del semáforo solo**. Detalle completo en `MANUAL_USUARIO.md` §6.

### 3.3 🛑 Bloqueos vigentes antes de cablear cámara a `J16`

**No se cablea todavía.** Las cuatro condiciones están enumeradas en `MANUAL_USUARIO.md` §6.5; en
resumen y con su medida:

1. 🔴 **Falta la medida M3** — la polaridad de los pines de botón está en **contradicción medida**:
   el `.kicad_pcb` traza `R65`–`R68` de 10 kΩ **a `GND`** (pull-**down**, activo en ALTO) y
   `botones.cpp:19` lee `== LOW` con `INPUT_PULLUP`. Las dos no pueden ser ciertas.
   `03_Hardware_Tarjeta/MAPEO_TARJETA_KICAD.md` §3 · `05_Funcional/17_…` sección **M3**.
   **`PB0` tiene su resistencia a masa MEDIDA; de `PB14`/`PB15` sólo lo dice el netlist** — y con
   `pinMode(INPUT)` pelado, un pin sin resistencia real **flota** y el ruido dispara demandas fantasma.
2. 🔴 **Orden asimétrico** (`CLAUDE.md` §9.bis): `PB14` es **`botonAceptar()`, el que EJECUTA**, leído
   hoy activo en BAJO. **El firmware nuevo tiene que estar CARGADO EN LA TARJETA antes de que nadie
   enchufe nada en `J16`.** Un commit no protege de un destornillador.
3. 🔴 **`J16` p1 lleva 12 V crudos** —sin opto, sin limitadora, sin clamp— y **se tapa físicamente
   antes de cablear**. La separación **real sobre cobre** contra la red de 12 V, **MEDIDA** en
   `03_Hardware_Tarjeta/MAPEO_TARJETA_KICAD.md:576-588`, no es el paso del conector:

   | red de 12 V contra | separación mínima real |
   |---|---|
   | `/Boton1` (p5) | 1,405 mm |
   | `/Boton2` (p8) | 1,408 mm |
   | `/Boton3` (**p10**) | **4,269 mm** |
   | `/Boton4` (**p12**) | **1,359 mm** ← el peor |

   👉 **Si una de las dos cámaras es más crítica, va en `p10`**, no en `p12`.
4. 🔴 **Ningún firmware lee `PB14`/`PB15` como cámara todavía**: siguen en `pinMode(…, INPUT_PULLUP)`
   como botones (`botones.cpp:52-53`).

Detalle de parametrización de la cámara —incluidas las **dos configuraciones `NO`/`NC`** de la salida
de relé y cuál elegir según **M3**— en
[`05_Funcional/9_Manual_Parametrizacion_Camara_IA.md`](05_Funcional/9_Manual_Parametrizacion_Camara_IA.md).

> **Nada de este apartado ha pasado prueba de banco y no autoriza a instalar ni a cablear nada.**

---

## 4. Módulo Bluetooth para Telemetría y Diagnóstico Móvil

Para soporte técnico, caja negra de alarmas y monitoreo desde el suelo sin subir al poste (estándar probado en proyecto Baliza):
* **Pines de Conexión:** Puerto **USART1 REMAPEADO** del STM32 — **`PB6` TX ➔ `RXD` BT, `PB7` RX ➔ `TXD` BT**, conector **`J17`**. ✅ **MEDIDO EN EL FUENTE:** `static HardwareSerial SerialBT(PB7, PB6);` (`01_Firmware/Maestro/src/bluetooth.cpp:28`, con el porqué del remapeo en `:16-22`).
  > ⛔ Este apartado publicó ~~«`PA9` TX ➔ `RXD` BT, `PA10` RX ➔ `TXD` BT»~~ hasta el 31/08/2026. Ese
  > era el sitio del puerto **antes de `N-76`**, y no es un detalle de redacción: manda soldar el módulo
  > Bluetooth a dos pines por los que hoy **no sale ni un byte**. El técnico no vería un error — vería
  > un módulo mudo, que es el fallo más caro de diagnosticar desde el suelo.
* **Desacoplo Eléctrico:** Pin `PA8` forzado en `HIGH` permanente para poner en alta impedancia ($\text{Hi-Z}$) el transceptor `MAX3485 U3`.
* **Alimentación:** `5V` (o `3.3V`) y `GND` de la tarjeta controladora.
* **Funcionalidad:** Envío continuo de telemetría (estado de luces, modo, cuenta regresiva `T:`, calidad de señal RF, % de paquetes y motivos de alarma con hora exacta de RTC) hacia la App en celular con comandos protegidos por PIN (`1234`). Detalle completo en [`05_Funcional/10_Manual_Modulo_Bluetooth_Telemetria.md`](05_Funcional/10_Manual_Modulo_Bluetooth_Telemetria.md).

---

## 5. Placa Base (Mainboard STM32)

La tarjeta principal de control que gobierna las luces del semáforo.

### Componentes Clave:
- **Cerebro:** Microcontrolador **STM32F103C8T6** ("Blue Pill" / CKS32F103).
- **Pantalla y UI:** LCD ST7920 (128x64 píxeles) conectada por SPI de 3 hilos. 4 botones físicos de navegación.
- **Salidas de Potencia:** Transistores MOSFET N-Channel (**IRLZ44N**) a 12V/24V para lámparas LED (Rojo, Amarillo, Verde).
- **Protección Galvánica:** 9 Entradas Optoacopladas para aislamiento eléctrico de botoneras y sensores.
- **Transceptor Integrado:** Chip MAX485 (Half-Duplex) conectado a la bornera RS485 `A` / `B`.
- **Watchdog:** Inicialización IWDG por registros directos adaptada a CKS32F103 (refresco en `loop()`).

---

## 6. Placa Repetidora (ESP32 V7.6)

Ubicada en la carpeta [`01_Firmware/Repetidor`](file:///d:/@Proyect/Controladora_Semaforos/01_Firmware/Repetidor).

### Componentes Clave:
- **Cerebro:** Microcontrolador **ESP32 Dev Module**.
- **Puertos Seriales:** `RadioA` (UART1: RX=16, TX=17, DE/RE=4) y `RadioC` (UART2: RX=32, TX=33, DE/RE=22).
- **Firmware V7.6:** Passthrough asíncrono con `delay(2)` y 15ms de ventana de ráfaga que previene la fragmentación de tramas binarias.

---

## 7. Guía de Pruebas y Carga de Firmware en PlatformIO

### 5.1 Carga del Firmware a los STM32 y ESP32:
En PlatformIO (VSCode), usar el botón **"Open Project"** y abrir de forma independiente la carpeta específica del nodo a programar:
1. `01_Firmware/Maestro` para la tarjeta Maestro STM32.
2. `01_Firmware/Esclavo` para la tarjeta Esclavo STM32.
3. `01_Firmware/Repetidor` para la tarjeta Repetidor ESP32.

> **Tip para Chips Clones CKS32F103:** Si el ST-Link rechaza la primera carga, mantener presionado el botón RESET de la tarjeta BluePill al hacer clic en "Upload" y soltarlo en el instante en que la consola indique "Connecting...".

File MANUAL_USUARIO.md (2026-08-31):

# 🚦 Manual de Operación y Comportamiento del Sistema (V8.9 Definitiva)

Este manual define el **"Ground Truth"** (la verdad absoluta) de cómo DEBE comportarse el sistema, sirviendo como base para validar que las simulaciones y el código cumplan con la especificación.
Todas las operaciones están alineadas al **Manual de Señalización Vial de Colombia (Resolución 2024 - MinTransporte)**.

**Última revisión:** 31 de agosto de 2026 — **el apartado 6 (cámaras) estaba MAL y se ha corregido.**
Mandaba cablear las cuatro cámaras a `PB9` y `PB13`, que son **los dos canales del mando de relés**, y
además con la polaridad invertida. Es `N-105` de [`roadmap.md`](roadmap.md). El texto viejo **no se
borra**: queda tachado en su sitio con el motivo, porque una vía descartada que desaparece en
silencio se vuelve a proponer. **Nada de esto ha pasado prueba de banco y este manual no autoriza a
cablear nada** — ver el apartado 6.6.

---

## 1. Comportamiento Físico de las Luces (Secuencia Normativa Colombia)

Para evitar arranques prematuros y dar tiempo de frenado, la secuencia lumínica **debe** operar de la siguiente manera:

1. 🔴 **ROJO FIJO:** Vía cerrada.
2. 🟡 **AMARILLO FIJO:** (Duración estricta de 4.0 segundos avisando el arranque inminente en Maestro y Esclavo).
3. 🟢 **VERDE FIJO:** Vía libre.
4. 🔴 **ROJO FIJO:** (Transición directa desde el verde, 0s de aviso). Vía cerrada.

### Tiempos de Despeje (All-Red / Rojo Estático)
Cuando se solicita el cambio de vía, el sistema debe entrar en un estado de **ROJO ABSOLUTO**.
- Durante *N* segundos, **ambos semáforos estarán en ROJO**.
- **Variabilidad de Terreno:** Como la obra puede abarcar de 20m a 500m (con radios que alcanzan hasta 6km en línea vista), el tiempo de despeje no puede estar limitado a un valor bajo.
- **Configuración:** La interfaz del menú LCD permite configurar tiempos de despeje de **10 a 90 segundos**, con **piso mínimo de 10 s** por seguridad vial. Lo impone el firmware, no la pantalla: `DESPEJE_SEG_MIN = 10, DESPEJE_SEG_MAX = 90` en `01_Firmware/Maestro/src/modo_automatico.cpp:34`, y `modoAutomatico_fijarTiempos()` **rechaza** (`return false`) cualquier valor fuera del rango, venga del menú o de un comando por Bluetooth. ✅ **MEDIDO EN EL FUENTE.**

> ### ⛔ Este apartado publicó ~~«de 5 a 999 segundos, piso mínimo de 5 s, hasta 16.6 minutos»~~ hasta el 31/08/2026. Era falso por partida triple.
>
> No se borra —una vía descartada que desaparece en silencio se vuelve a proponer— y se explica por qué,
> porque las tres razones son distintas:
>
> 1. 🔴 **El piso publicado era la MITAD del real.** Un operario que configurase **5 s** de despeje
>    creyendo que el manual manda, se encontraría con que el equipo **rechaza el valor** y se queda con
>    el anterior. El despeje es *«el tiempo que garantiza que el tramo quedó vacío antes de dar verde al
>    otro lado»*: **los 10 s no son un número redondo, son el tramo más corto que esta casa ha montado**
>    (comentario de `modo_automatico.cpp:29-31`). Publicar 5 s invita a pedir un despeje que **no da
>    margen**, y esto está en la matriz de seguridad como **SFTY-4**.
> 2. 🔴 **El techo publicado era 11 veces el real.** El máximo es **90 s**, no 999. Quien planifique un
>    túnel de 500 m contando con *«hasta 16.6 minutos»* está planificando sobre un equipo que no existe.
> 3. 🔴 **Y 999 no fue nunca representable.** `despejeSeg` es un **`uint8_t`** (`modo_automatico.cpp:34`,
>    `:37`): el valor más grande que cabe en ese tipo es **255**. La cifra publicada no era una
>    configuración desafortunada — era un número que **ningún firmware podría haber aceptado jamás**, y
>    llevaba meses escrito como si fuera una capacidad del equipo.

---

## 2. Comportamiento en Destello / Intermitente (Bajo Flujo)

Según el Manual de Señalización (2024), si el flujo vehicular baja al 50% o menos durante 4 horas o más (usualmente operación nocturna), el sistema debe pasar a operación intermitente.
- **Funcionamiento:** Un semáforo parpadea en 🟡 **Ámbar** (Precaución - vía principal) y el otro en 🔴 **Rojo** (Pare - vía secundaria), o ambos en Rojo Intermitente para pasos de igual jerarquía.

---

## 3. Comportamiento de la Interfaz y Menú (LCD ST7920)

El acceso a la pantalla LCD y los botones de configuración es crítico para los operarios.
- **Regla de Oro (Independencia de Red):** El operario DEBE poder acceder al menú de configuración (para elegir modo Manual, Automático o Inteligente, y fijar tiempos) **incluso si las radios están apagadas o no hay comunicación con el esclavo**.
- **Comportamiento en Menú:** En el Menú Principal, si hay comunicación el Maestro mantiene **🔴 ROJO FIJO continuo en ambos semáforos** sin congelar la pantalla. Si no hay comunicación, indica orfandad pasando a Amarillo Intermitente.
- **Arranque Inmediato:** Al seleccionar un modo en el menú, el sistema aplica inmediatamente el tiempo de Despeje All-Red en ambos extremos.

### Prueba de Alcance
Cuarta opción del Menú Principal. Muestra **calidad de enlace en %**, barra gráfica, **tiempo de respuesta** en ms y fallos consecutivos, actualizándose cada 3 segundos. Permite determinar la cobertura real de radio desplazando el equipo, en lugar de estimarla.
Mientras está activa, ambos semáforos permanecen en **🔴 Rojo Fijo** (o Amarillo Intermitente sin enlace), igual que en el Menú. **No arranca ciclos.** Se sale con el Botón 4.

---

## 4. Comportamiento ante Fallas (Fail-Safe & Self-Healing Real)

1. **Pérdida de Comunicación (SFTY-6):** Si se pierde comunicación por más de **25 s de silencio**, el sistema entra automáticamente en `C_FALLO` / `S_FALLO` (🟡 **Amarillo Intermitente**). En `C_FALLO`, el Maestro envía `CMD_GO_RED` para obligar al Esclavo a pasar a Rojo o Amarillo Intermitente por timeout. ✅ **MEDIDO:** `SFTY6_SILENCIO_MS = 25000UL` en `01_Firmware/Maestro/include/protocolo.h:149` y en `01_Firmware/Esclavo/include/protocolo.h:149` — el umbral vive **una sola vez por punta** y las dos líneas son idénticas.
   > ⛔ Este manual publicó ~~12.0 segundos~~ hasta el 31/08/2026. Era el umbral anterior a **N-71**, y no
   > era sólo una cifra vieja: **12 s quedaban por debajo de los ~20,8 s que el ciclo necesita** para
   > agotar sus cinco reintentos, así que **los reintentos 4 y 5 no se ejecutaban nunca** — el ámbar por
   > orfandad saltaba antes. Nada lo delataba, porque irse a ámbar es un comportamiento razonable.
2. **Auto-Recuperación Autónoma (Self-Healing Real):** Al restablecerse la señal de radio, el sistema **NO requiere reinicio manual**. Limpia automáticamente el registro de duplicados (`protocolo_resetReplayProtection()`), fuerza Rojo Estático (All-Red) de 15 segundos en ambos semáforos para limpiar la vía y reanuda el ciclo lumínico sin intervención técnica.
3. **Cuelgue de Procesador (Ruido EMI):** El Watchdog interno (`IWatchdog` activo a 4.0s) reinicia el procesador ante interferencias severas.

---

## 5. Resiliencia RF: Ráfaga configurable y Ventana Deslizante (SFTY-11)

Para garantizar comunicación inquebrantable en zonas de montaña con alta interferencia:
- **Ráfaga (Burst):** 1 copia de 4 bytes con FEC activo en radios E90-DTU.
- **Ventana Deslizante (Sliding Window):** Procesamiento asíncrono con CRC-8 Maxim (`0x31`).
- **Protección Antirepetida (Replay Protection):** Descarte de duplicados mediante `msgID`.

---

## 6. Integración de Cámaras IA para Demanda Vehicular (AcuSense G2)

> ## 🛑 AVISO DE SEGURIDAD — LÉASE ANTES DE CABLEAR NADA (31/08/2026)
>
> ### ⛔ NO SE CABLEA CÁMARA A `PB9` NI A `PB13`. **SON LOS DOS CANALES DEL MANDO DE RELÉS.**
>
> Hasta el 31/08 este apartado mandaba las cuatro cámaras a `PB9` y `PB13`. **`PB9` es `MANDO_A` y
> `PB13` es `MANDO_B`**, y el mando **se conserva** (decisión del 31/08, `N-104`).
>
> **MEDIDO EN EL FUENTE:**
>
> ```
> 01_Firmware/Maestro/src/botones.cpp:119   if (flanco[0]) mando_registrarPulso(MANDO_A);  // BOTON1 = PB9  = J16 p5
> 01_Firmware/Maestro/src/botones.cpp:120   if (flanco[1]) mando_registrarPulso(MANDO_B);  // BOTON2 = PB13 = J16 p8
> 01_Firmware/Maestro/include/pines.h:92-93 #define BOTON1 PB9   ·   #define BOTON2 PB13
> 01_Firmware/Maestro/src/mando.cpp:38      VENTANA_TRIPLE_MS = 12000     (12 s)
> 01_Firmware/Maestro/src/mando.cpp:225-234 A·A·A -> ACC_AUTOMATICO   ·   B·B·B -> ACC_AMBAR
> 01_Firmware/Esclavo/src/mando.cpp:129-132 case ACC_AMBAR: ambarLocal = true;
> ```
>
> **Lo que pasa si alguien sigue el texto viejo:** una cámara enchufada ahí **entrega pulsos**, y
> **tres pulsos dentro de la ventana de 12 s componen una secuencia del mando** (apartado 7 de este
> mismo manual). En `PB9`, `A·A·A` mete el equipo en **Modo Automático**; en `PB13`, `B·B·B` lo manda
> a **Ámbar** y además arma `ambarLocal`, la bandera de la que cuelgan los tres vetos del Esclavo
> (`01_Firmware/Esclavo/src/main.cpp:406`, `:416`, `:540`), que **desobedecen las órdenes de radio**.
>
> ### 🔴 Dicho en una línea: **el tráfico cambiaría el modo del semáforo solo**, sin que nadie lo pida y sin que nada lo registre como orden.
>
> **Y encima había un SEGUNDO error que TAPABA al primero.** El texto viejo decía *«y `GND`»*. El
> camino de cámara del firmware es `pinMode(INPUT)` pelado y **activo en ALTO**
> (`01_Firmware/Maestro/src/modo_inteligente.cpp:46` y `:25`), y la bornera saca el pin **junto a
> 3,3 V**. Cableada a masa, **la cámara no dispara nunca**: un ensayo de taller la habría dado por
> buena sin llegar a ver el defecto de arriba, que aparecería el día que alguien *«arreglara»* el
> cableado. **Los dos errores se corrigen juntos o el arreglo es peor que el defecto.**

### 6.1 ~~El cableado que este manual mandaba hacer~~ — ⛔ ANULADO, CONSERVADO COMO RASTRO

~~Para detección inteligente de flujo vehicular en pasos alternados de obra:~~

* ~~**Semáforo Maestro:**~~
  * ~~**Cámara 1 (Aproximación Sentido 1):** Contacto seco `1A`/`1B` en **`PB9`** y `GND` ➔ Demanda Verde Maestro.~~
  * ~~**Cámara 2 (Monitoreo Obra Sentido 1):** Contacto seco `1A`/`1B` en **`PB13`** y `GND` ➔ Confirma flujo interno.~~
* ~~**Semáforo Esclavo:**~~
  * ~~**Cámara 3 (Aproximación Sentido 2):** Contacto seco `1A`/`1B` en **`PB9`** y `GND` ➔ Demanda Verde Esclavo.~~
  * ~~**Cámara 4 (Monitoreo Obra Sentido 2):** Contacto seco `1A`/`1B` en **`PB13`** y `GND` ➔ Confirma flujo interno.~~

**Por qué estaba mal, pin por pin:**

| pin | lo que decía este manual | lo que hay de verdad | nivel |
|---|---|---|---|
| `PB9` | «Cámara 1 / 3, demanda de verde» | **`BOTON1` = `MANDO_A`** (`J16` p5). Tres pulsos en 12 s = **Modo Automático** | ✅ **MEDIDO** (`pines.h:92`, `botones.cpp:119`, `mando.cpp:225-227`) |
| `PB13` | «Cámara 2 / 4, monitoreo de obra» | **`BOTON2` = `MANDO_B`** (`J16` p8). Tres pulsos en 12 s = **Ámbar + `ambarLocal`** | ✅ **MEDIDO** (`pines.h:93`, `botones.cpp:120`, `mando.cpp:230-234`) |
| el `GND` de las cuatro líneas | «contacto seco contra masa» | El pin es **activo en ALTO** y la bornera lo saca junto a **3,3 V**: contra masa **no dispara jamás** | ✅ **MEDIDO** (`modo_inteligente.cpp:25`, `:46`) |

**Además ya no son cuatro cámaras.** Desde el 28/08 **no existen las cámaras 2 y 4**: `PB8` nunca fue
una entrada —es el `LED_TESTIGO`, ver el apartado 6.4— y el conteo de umbral necesitaría un comando de
radio que el protocolo no tiene (`N-59`, `N-64`). El despeje se hace **por tiempo** (`cfgDespejeSeg`),
que es el criterio conservador: la cámara de umbral daría **eficiencia, no seguridad**.

### 6.2 ✅ Dónde va la cámara HOY, y dónde va DESPUÉS — no es el mismo pin

**Son dos situaciones distintas y confundirlas deja un hilo colgando de una entrada viva.**

| | pin | bornera | estado del firmware |
|---|---|---|---|
| **HOY, lo único que un firmware lee** | **`PB0`** (`CAM_DEMANDA_PIN`) | **`J14`** | ✅ **MEDIDO**: se lee de verdad — `modo_inteligente.cpp:98`, `:136` (Maestro) y `main.cpp:350` (Esclavo). La placa ayuda con `R64` 10 kΩ + `C25` 100 nF = antirrebote de 1 ms (`pines.h:43-46`) |
| **DESPUÉS de la Fase 3, decidido** | **`PB14`** (`J16` **p10**) y **`PB15`** (`J16` **p12**) | **`J16`** | 🔴 **NINGÚN firmware los lee como cámara.** Hoy siguen siendo botones: `pinMode(BOTON3, INPUT_PULLUP)` y `pinMode(BOTON4, INPUT_PULLUP)` en `botones.cpp:52-53` |

📖 **LEÍDO** (decisión, no medida): las cámaras se mudan a `J16` p10/p12, los pines que libera la
retirada de los pulsadores **C** y **D** — `ESTADO.md:83`, `:105`, `:119` y `roadmap.md` `N-104`. Los
canales **A** (`PB9`, p5) y **B** (`PB13`, p8) **se conservan para el mando** y **no quedan libres**.

> 🟡 **ABIERTO, y no lo cierra este manual:** cuántas cámaras van por poste. `ESTADO.md:50` dice
> *«dos cámaras de demanda, una por poste»*, y el reparto de pines libera **dos** entradas en cada
> nodo. **Lo decide el responsable**; aquí sólo queda escrito que los pines disponibles son p10 y p12.

### 6.3 🔴 La salida de la cámara es configurable (NO / NC) y hay que elegir DESPUÉS de la medida M3

La salida de alarma de la AcuSense se parametriza como **`NO` (Normalmente Abierto)** o **`NC`
(Normalmente Cerrado)** (`05_Funcional/9_Manual_Parametrizacion_Camara_IA.md`, Paso 4). **Las dos
configuraciones están escritas aquí porque cuál es la correcta depende de una medida que todavía no
se ha hecho.**

| si la medida **M3** dice… | cómo se cablea el contacto seco | configuración de la cámara | encaja con el firmware de hoy |
|---|---|---|---|
| **~0,66 V** en reposo → la placa tiene el *pull-**DOWN*** de 10 kΩ del netlist (`R65`–`R68` a `GND`) | entre el pin de señal y el pin de **3,3 V** contiguo (`J16` p9 para p10, p11 para p12) — **NO contra `GND`** | **`NO`**, pulso de **1 s** | ✅ Sí: `pinMode(INPUT)` + `digitalRead(...) == HIGH` (`modo_inteligente.cpp:25`, `:46`) |
| **~3,3 V** en reposo → *pull-**UP*** y el netlist no describe esta placa | entre el pin de señal y **`GND`** (`J16` p2) | **`NO`**, pulso de **1 s** | ❌ No: habría que **invertir la lectura de la cámara** en las dos puntas antes de cablear |
| **otra cosa** | **no se cablea** | — | se anota el número y **se para** |

* **`NC` no se usa en ninguno de los dos casos.** Con `NC` el contacto está cerrado en reposo y se
  abre al detectar: el firmware vería **demanda permanente** mientras no pasa nada y **ausencia de
  demanda** justo cuando pasa un vehículo. Es la inversión exacta que ya costó `N-67`.
* El detalle de M3 —qué se mide, con qué y qué número se espera **antes** de mirar el multímetro—
  está en `05_Funcional/17_Arquitectura_28-08_y_Decisiones_Abiertas.md`, sección **M3**.

> 🔴 **Y hay un tercer resultado posible de M3 que también bloquea: que no haya resistencia ninguna.**
> `PB0` tiene su reposo garantizado por hardware —`R64` de 10 kΩ y `C25`, **MEDIDO** en `pines.h:43-46`—.
> De `PB14`/`PB15` **sólo lo dice el netlist**: `R65`–`R68` de 10 kΩ a `GND`
> (`03_Hardware_Tarjeta/MAPEO_TARJETA_KICAD.md`, §3), y eso es un plano, no una tarjeta. Con
> `pinMode(INPUT)` pelado y **sin resistencia real montada**, el pin queda **flotando** y el ruido
> dispara **demandas fantasma** en un equipo que gobierna un cruce. La medida con óhmetro entre el pin
> y masa —**10 kΩ esperados**— es parte de M3 y no se salta.

### 6.4 `PB8` no es una entrada: es el LED testigo

**MEDIDO** — `01_Firmware/Maestro/include/pines.h:63` y `01_Firmware/Esclavo/include/pines.h:63`:

```
#define LED_TESTIGO        PB8  // -> R16 1K -> LED D5. NO es entrada de camara
```

Sale por `R16` de 1 kΩ al LED `D5`. **No es bornera y no es entrada optoacoplada.** El firmware lo
deja a propósito en alta impedancia (`modo_inteligente.cpp:50`). Cuatro manuales llegaron a
describirlo como *«umbral de tramo»* (`N-59`, `N-64`); ninguno se había cruzado contra `pines.h`.

### 6.5 🛑 Lo que BLOQUEA el cableado hoy — las cuatro cosas, ninguna opcional

1. 🔴 **Falta la medida M3** (polaridad de `J16`). El netlist dice pull-**down**, activo en ALTO; el
   firmware de botones dice `INPUT_PULLUP` y activo en BAJO (`botones.cpp:19`, `:52-53`). **Las dos no
   pueden ser ciertas a la vez** y se cierra con multímetro, no leyendo más. `CLAUDE.md` §9.bis:
   mientras esa contradicción siga abierta, **no se cablea cámara a `J16`**.
2. 🔴 **El orden es ASIMÉTRICO, y un commit no protege de un destornillador.** `PB14` es
   **`botonAceptar()`, el que EJECUTA** (`botones.cpp:131`). Con el firmware viejo todavía dentro, se
   lee **activo en BAJO**: cualquier cosa que un instalador enchufe en `J16` p10 **puede pulsar
   *Aceptar* en un equipo que está en la calle**. Por eso el firmware nuevo tiene que estar
   **CARGADO Y VERIFICADO EN LA TARJETA antes** de que nadie enchufe nada. El sentido contrario no es
   seguro. (`CLAUDE.md` §9.bis.)
3. 🔴 **`J16` p1 lleva 12 V crudos**, sin opto, sin limitadora y sin clamp. **Se tapa físicamente
   antes de cablear nada.** Y la separación real sobre cobre **no** es la distancia entre pads
   —MEDIDO en `03_Hardware_Tarjeta/MAPEO_TARJETA_KICAD.md:576-588`—:

   | red de 12 V contra | separación mínima real |
   |---|---|
   | `/Boton1` (p5) | **1,405 mm** |
   | `/Boton2` (p8) | **1,408 mm** |
   | `/Boton3` (**p10**) | **4,269 mm** |
   | `/Boton4` (**p12**) | **1,359 mm** ← el peor de los cuatro |

   👉 **Consecuencia útil: si una de las dos cámaras es más crítica, va en `p10`** (4,27 mm), **no en
   `p12`** (1,36 mm). Un error de una posición al enchufar `J16` mete **12 V en un pin de 3,3 V**.
4. 🔴 **Ningún firmware lee `PB14`/`PB15` como cámara todavía** (MEDIDO, 6.2). Cablear antes de que
   exista ese firmware deja dos hilos conectados a dos entradas de botón.

### 6.6 Seguridad vial y nivel de prueba de este apartado

* **Invariante que no cambia con nada de lo anterior:** cada cambio de sentido exige obligatoriamente
  el **Despeje Todo-Rojo** completo antes de habilitar el verde opuesto, y el **amarillo normativo de
  4,0 s**. Bajo ninguna circunstancia se omite ninguno de los dos.

| lo que este apartado afirma | nivel |
|---|---|
| `PB9` = `MANDO_A`, `PB13` = `MANDO_B`, y tres pulsos en 12 s componen secuencia | ✅ **MEDIDO EN EL FUENTE** (`pines.h:92-93`, `botones.cpp:119-120`, `mando.cpp:38`, `:225-234`) |
| La cámara es activa en ALTO y no se cablea contra `GND` | ✅ **MEDIDO EN EL FUENTE** (`modo_inteligente.cpp:25`, `:46`) |
| `PB0`/`J14` es hoy el único camino de cámara con firmware | ✅ **MEDIDO** (`modo_inteligente.cpp:98`, `:136`; `Esclavo/src/main.cpp:350`) |
| `PB14`/`PB15` son hoy `botonAceptar()` y `botonCancelar()` | ✅ **MEDIDO** (`botones.cpp:52-53`, `:131-132`) |
| Las distancias de cobre de `J16` contra los 12 V | ✅ **MEDIDO** sobre el `.kicad_pcb` (`MAPEO_TARJETA_KICAD.md:576-588`) |
| Que las cámaras se muden a `J16` p10/p12 | 📖 **LEÍDO** en las decisiones (`ESTADO.md:83`, `:105`, `roadmap.md` `N-104`). **Decidido, sin construir** |
| Que `R65`–`R68` estén realmente montadas y la polaridad sea la del netlist | 🔴 **NO VERIFICADO.** Es la medida **M3**, con multímetro, y está **pendiente** |

> **Nada de este apartado ha pasado prueba de banco**, y **no autoriza a instalar ni a cablear nada**.
> La única forma correcta de verificar el firmware es `01_Firmware/compuerta.py`, y un verde suyo
> **tampoco es un permiso**: dice que los modelos y los arneses de PC no encuentran nada, no que el
> firmware funcione en la tarjeta (`CLAUDE.md` §3).

---

## 7. Vocabulario Oficial del Mando a Distancia de Relés (Anti-Colisión N-53)

Para permitir la operación del semáforo a nivel del suelo sin colisionar con la edición de parámetros en pantalla.

> 🛑 **ESTA TABLA ESTABA MAL EN CUATRO DE SUS CINCO FILAS, y se corrige el 31/08.** No es un detalle
> de redacción: es el vocabulario que decide **qué pulsos componen una orden**, y es justo lo que hace
> peligroso el defecto del apartado 6. Lo de abajo está **MEDIDO** sobre
> `01_Firmware/Maestro/src/mando.cpp` (el Esclavo es idéntico).

### 7.1 ✅ El vocabulario REAL, medido en el fuente

| Secuencia | Ventana | Modo Activado | Confirmación Lumínica | dónde está medido |
|---|---|---|---|---|
| **`A · A · A`** | ≤ **12 s** | 🟢 **Modo Automático** | **2** destellos rojos | `mando.cpp:225-227`, `:45` |
| **`B · B · B`** | ≤ **12 s** | 🟡 **Modo Ámbar (Seguro)** | **3** destellos rojos | `mando.cpp:230-234`, `:46` |
| **`A · B · A · B`** | ≤ **18 s** | 🕒 **Modo Degradado (Reloj)** | **4** destellos rojos | `mando.cpp:204-214`, `:47` |

**Y no hay más.** El repertorio completo son **tres acciones**, no cinco:
`enum AccionMando { ACC_NINGUNA, ACC_AUTOMATICO, ACC_AMBAR, ACC_DEGRADADO };` (`mando.cpp:53`).

### 7.2 ~~La tabla anterior~~ — ⛔ ANULADA, conservada con el motivo de cada fila

| ~~Secuencia~~ | ~~Modo~~ | por qué era falsa |
|---|---|---|
| ~~`A · B · A` (≤12s)~~ | ~~🟢 Modo Automático~~ | ⛔ **Es `A · A · A`.** `A·B·A` no dispara nada |
| ~~`B · A · B` (≤12s)~~ | ~~🟡 Modo Ámbar~~ | ⛔ **Es `B · B · B`.** `B·A·B` no dispara nada |
| ~~`B · A · B · A` (≤18s)~~ | ~~✋ Modo Manual, 5 destellos~~ | ⛔ **NO EXISTE.** No hay `ACC_MANUAL` en el `enum` |
| `A · B · A · B` (≤18s) | 🕒 Modo Degradado, 4 destellos | ✅ **la única fila que era correcta** |
| ~~`A · A · B · B` (≤18s)~~ | ~~📷 Modo Inteligente, 6 destellos~~ | ⛔ **NO EXISTE.** No hay `ACC_INTELIGENTE` en el `enum` |

### 7.3 Lo que el mando comprueba además de la secuencia

* **La red de seguridad real del Degradado no es la secuencia, es la validación.** Aunque alguien
  acierte `A·B·A·B` por casualidad, el firmware **no entra** si la hora no está validada:
  `modo_degradado_evaluarEntrada() == MDG_OK` (`mando.cpp:213`). El mando permite reactivar en campo
  sin grúas, **pero no saltarse la puesta a punto**.
* **El Ámbar entra sin condiciones y desde cualquier modo en marcha** (`mando.cpp:230-234`): es la
  regla que impide que nadie quede atrapado con un semáforo en estado raro a 5 m de altura. Además
  arma **`ambarLocal`**, la bandera de la que cuelgan los tres vetos del Esclavo
  (`Esclavo/src/main.cpp:406`, `:416`, `:540`): mientras un operario dejó ámbar local puesto, **una
  orden de radio no lo saca de ahí**. Es una desobediencia deliberada, no un fallo.
* **Los destellos son SIEMPRE ROJOS** y contables desde el suelo (`mando.cpp:41-44`): el rojo nunca
  significa *«pase»*, así que si el operario cuenta mal, **el peor caso sigue siendo seguro**.
* **Inhibición de UI (N-53):** mientras el operador esté en pantallas de configuración
  (`AJUSTAR HORA`, `CONFIG_TIEMPOS`), el receptor del mando **se inhibe al 100%**
  (`mando.cpp:89`, `:180`), permitiendo ajustar números con el codillo sin disparar cambios de modo
  involuntarios.
* **Sólo los botones 1 y 2 alimentan el mando.** El 3 **ejecuta** y el 4 sale: si formaran parte de
  alguna secuencia, repetirlos a ciegas podría arrancar un modo que nadie pidió (`botones.cpp:115-120`).

### 7.4 🟢 El mando SE CONSERVA — y por eso el apartado 6 importa

**DECIDIDO el 31/08** (`roadmap.md` `N-104`): se conservan los canales **`A`** (`PB9`, `J16` p5) y
**`B`** (`PB13`, `J16` p8); se retiran **`C`** (`PB14`, p10) y **`D`** (`PB15`, p12), **y esos dos
pines pasan a las cámaras**.

* **Por qué los dos canales y no sólo `A`:** `B·B·B` es **el único sitio donde se arma `ambarLocal`**
  (`Esclavo/src/mando.cpp:129-132`, **MEDIDO**). Sin el canal `B` esa bandera no se armaría jamás, los
  tres `if` que la niegan se volverían siempre-verdaderos y **el veto desaparecería** — una regla de
  seguridad perdida por sustracción. Y `A`-solo tampoco compraba nada: liberaría **tres** entradas
  cuando sólo hacen falta **dos**.
* 🟠 **El receptor físico del mando nunca se compró.** Lo que se conserva hoy es el **firmware y el
  veto**; para tener mando físico hay que comprarlo.
* 📄 **Coherente con `ESTADO.md`, verificado el 31/08:** `ESTADO.md:83-84` ya recoge esta decisión —se
  retiran **sólo** los pulsadores 3 y 4, y *«EL MANDO DE RELÉS SE CONSERVA, en los canales A y B»*—.
  La redacción anterior del **28/08**, que retiraba los cuatro pulsadores y el mando entero, queda
  **tachada allí con su motivo**. Si alguien encuentra todavía la versión vieja en otro documento, la
  vigente es ésta: `roadmap.md` `N-104`.

---

## 8. Módulo Bluetooth para Telemetría y Diagnóstico Móvil (Estándar Baliza)

Para soporte técnico en campo sin escaleras:
* **Conexión Hardware:** Puerto **USART1 REMAPEADO a `PB6` (TX) / `PB7` (RX)**, conector **`J17`**, alimentado con 5V/3.3V de la PCB. ✅ **MEDIDO:** `static HardwareSerial SerialBT(PB7, PB6);` en `01_Firmware/Maestro/src/bluetooth.cpp:28`.
  > ⛔ Este manual publicó ~~«USART1 (`PA9` TX, `PA10` RX)»~~ hasta el 31/08/2026. Es el sitio donde
  > estuvo **antes** de `N-76`, y dejarlo escrito manda al técnico a soldar el módulo Bluetooth al
  > conector equivocado.
* **Telemetría en Vivo:** Emisión periódica de `$STATUS,...` cada 1 segundo con modo, fase de luces, cuenta regresiva, % de señal RF y hora exacta del RTC.
* **Caja Negra de Alarmas:** Registro inmediato de eventos con timestamp (`$ALARM,NODE:MAESTRO,EVENTO:FALLO_RF,CAUSA:SILENCIO_25000ms,ACCION:CAMBIO_A_AMBAR,HORA:...`) para diagnosticar la causa exacta de cualquier caída de radio en obra.
  > ⛔ El ejemplo decía ~~`$ALARM,EVENTO:FALLO_RF_12S...`~~ hasta el 31/08/2026. El propio firmware ya
  > había retirado ese literal con su motivo escrito al lado —`Esclavo/src/main.cpp:573` y
  > `*/include/bluetooth.h:18-19`: *«el numero quedo mintiendo al subir el umbral a 25 s»*—, pero el
  > manual se quedó con la versión vieja. La causa **no lleva el número pegado al nombre del evento**:
  > se compone en tiempo de ejecución desde `SFTY6_SILENCIO_MS`, y por eso no puede envejecer.

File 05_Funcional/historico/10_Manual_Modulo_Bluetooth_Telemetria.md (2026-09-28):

# 📱 MANUAL TÉCNICO Y ESPECIFICACIÓN INTEGRAL DE LA APP MÓVIL Y BLUETOOTH (V9.0)

**Sistema:** Controladora de Semáforos Móviles de 3 Estados (Maestro y Esclavo V9.0)  
**Transporte de Diagnóstico:** Bluetooth Serial **SPP (Clásico)** — **no BLE** (Estándar Probado en Proyecto Baliza). **El transporte NO cambia.**  
**Módulo que lo lleva:** ~~`HC-05` / `JDY-30` dedicado~~ → **`ESP32` clásico haciendo de puente SPP** *(decisión de obra del 28/08, ver §1.9)*. ~~🛑 **Condicionado a `BLQ-1`: la referencia del ESP32 que llegó a obra sigue SIN LEER.**~~ ✅ **`BLQ-1` CERRADO el 31/08 — ver el recuadro de abajo.**

> ## ✅ 05/09 — `BLQ-1` ESTÁ CERRADO DESDE EL 31/08. ESTE MANUAL YA NO BLOQUEA EL MONTAJE
>
> 🛑 **Este documento condicionaba a `BLQ-1` el montaje, la compra y hasta su propio diagrama de
> conexión —en SEIS sitios (`:5`, `:44`, `:211`, `:226-251`, `:253`, `:437`)— por una pregunta que
> se contestó hace cinco días.** Y es el manual que él mismo describe como *«el único documento de la
> entrega con dibujo de conexión del módulo»*, así que su bloqueo paraba la instalación entera.
>
> **MEDIDO:** el módulo es un **`ESP32-WROOM-32` clásico**, con **`BR/EDR` y por tanto SPP**.
> Consta cerrado en **`ESTADO.md:151`** (*«CERRADO el 31/08… El apartado 1 del Manual 10 **no se
> reabre**»*), en **`roadmap.md:1509`** (N-107) y en **`15_Lista_de_Compras_Hardware.md:112`**. Y
> **`14_Manual_App_Movil_IOT_VIAL.md:96` ya lo decía con todas las letras: *«`BLQ-1` está CERRADO.
> Si algún documento lo da por abierto, está caducado»*** — éste era ese documento.
>
> 🔴 **Y la lección de N-107, que corrige el método que este manual exigía:** `BLQ-1` **no lo cerró
> el banco leyendo la serigrafía**; lo cerró **la ficha técnica del artículo comprado**, que ya lo
> declaraba. *«Antes de declarar algo bloqueado por una medida física, censa qué fuentes escritas
> pueden responderlo ya. Un bloqueo que se puede levantar leyendo no es un bloqueo.»*
>
> **Todo lo que abajo siga marcado ~~🛑 Condicionado a `BLQ-1`~~ describe el mundo anterior al 31/08
> y NO bloquea ni el montaje ni la compra.**
>
> 🔴 **Lo que SÍ sigue bloqueando el montaje, y no es el chip: la línea `A5`, la fuente propia
> DC-DC 12 V→5 V del ESP32, que NO SE HA PEDIDO.** Sin ella el módulo cuelga del `LM7805` que
> alimenta al STM32 que gobierna el cruce (§2.3.bis). **`J17` p6 no se conecta.**

---

> # 🔴 FE DE ERRATAS DEL 07/09/2026 — LÉASE ANTES QUE NADA
>
> **Este manual publica cinco afirmaciones que fueron ciertas cuando se midieron y son falsas hoy.**
> Ninguna se borra: se tacha donde vive, con su motivo. Se listan aquí porque **la que más pesa
> aparece en el apartado 1, y quien lea sólo el principio se la lleva entera.**
>
> ### 1. 🔴 «El firmware del puente SPP del ESP32 NO EXISTE» — FALSO desde el 31/08, y la fecha del `MEDIDO` es CORRECTA
>
> Este manual lo afirma en **tres sitios** —la nota de «lo que no se ha tocado», el bloque del
> `AT+NAME` y la tabla de cableado del ESP32— y uno de ellos lleva **la palabra `MEDIDO` y la fecha
> `31/08`** encima. **La medida fue cierta el día que se tomó. El módulo entró ESE MISMO DÍA**, en
> `d2427c2`:
>
> ```
> $ git log -1 --format="%h %ad %s" --date=short d2427c2
> d2427c2 2026-08-31 feat: el firmware del ESP32 de expansion, con sus nueve packs
>
> $ ls 01_Firmware/ESP32_Expansion/src/
> despachador.cpp  enlace_stm32.cpp  main.cpp  puente.cpp
> reloj_ds3231.cpp  trama.cpp  transporte_app.cpp  vigilante.cpp
> ```
>
> **2.588 líneas en 16 ficheros**, y trae exactamente las dos cosas que este manual daba por
> pendientes:
>
> | lo que el manual da por inexistente | lo que hay hoy, medido por símbolo |
> |---|---|
> | *«el nombre lo fija su propio firmware… hay un firmware que escribir y grabar»* | **la matrícula está construida**: `ROTULO_PREFIJO "SEM-"` y `ROTULO_PROVISIONAL "SEM-SIN-MATRICULA"` en `ESP32_Expansion/include/contrato.h`, aplicados en `transporte_app.cpp` sobre `spp.begin(rotulo)`, y **el rótulo se guarda en NVS** para que un módulo sin aprender no salga con un nombre inventado |
> | *«va detrás del watchdog del ESP32 —hoy no tiene ninguno—»* | **el watchdog está construido**: `#include <esp_task_wdt.h>` en `ESP32_Expansion/src/vigilante.cpp`, con `ESP32_WDT_MS` y su pack |
>
> 🔴 **Y la consecuencia operativa, que es lo que le importa a quien monta:** este manual usaba esa
> ausencia para decir *«no hay nada que rotular y no hay módulo que instalar»*. **Ese motivo
> desapareció.** Lo que sigue bloqueando el montaje es **otra cosa y sólo una**: la línea `A5`, la
> fuente propia DC-DC, que **sigue sin pedirse** (verificado hoy en
> `05_Funcional/historico/15_Lista_de_Compras_Hardware.md`, fila `A5`: *«NO se ha pedido, y es LO QUE BLOQUEA
> EL MONTAJE»*).
>
> ### 2. 🔴 Este documento CIERRA `BLQ-1` arriba y lo declara VIVO dos veces más abajo
>
> El recuadro de cabecera dice *«`BLQ-1` ESTÁ CERRADO DESDE EL 31/08. ESTE MANUAL YA NO BLOQUEA EL
> MONTAJE»*. Y a continuación, en el mismo documento, sobreviven **dos frases que lo reabren**: la
> nota de *«dos bloqueos vivos delante del montaje: `BLQ-1` —la serigrafía del ESP32, sin leer—»* y
> un *«⏳ PENDIENTE — la referencia exacta está sin confirmar»*. **Las dos están tachadas hoy donde
> viven.** `BLQ-1` está cerrado en `ESTADO.md`, en `roadmap.md` (N-107), en la lista de compras y en
> otros dos manuales; **si algún párrafo de aquí lo da por abierto, ese párrafo es el caducado.**
>
> ### 3. 🔴 EL 95 % DE LAS CITAS POR NÚMERO DE LÍNEA DE ESTE MANUAL NO SEÑALA AL SITIO — medido hoy
>
> No es una sospecha ni una regla general aplicada a ojo: se corrió sobre este fichero.
> **El criterio, declarado para que se pueda discutir:** de cada cita `fichero.cpp:N` se toman los
> símbolos que el manual nombra entre acentos graves **en esa misma línea**, y se comprueba si
> alguno aparece en el fuente **en un margen de ±3 líneas** alrededor de la citada. Es un borde
> generoso a propósito: cuenta como acierto un desplazamiento pequeño.
>
> ```
> citas de firmware juzgables: 20 | el simbolo SI esta cerca: 1 | NO esta: 19
> ```
>
> **19 de 20.** Y el que más duele porque enseña el mecanismo: este manual cita
> `Esclavo/src/bluetooth.cpp:768` como *«la cadencia de 2000 ms del `$STATUS`»*, y esa línea dice
> hoy:
>
> ```
> $ sed -n '768p' 01_Firmware/Esclavo/src/bluetooth.cpp
>       enviarTramaConCrc("$ACK,CMD:SET_MODO:DEGRADADO,RESULT:OK");
> ```
>
> — que es el acuse de `D-18`, escrito seis días después de la cita. **Una cita que ha caducado no
> falla: apunta a otra cosa y se lee como si fuera la buena.**
>
> 🔴 **Dónde muerde esto:** el apartado del **Modo Degradado** de este manual —la tabla de motivos
> de rechazo, los estados `DEG_*` y el trazado de `degradado_salir()`— está sostenido **entero** por
> ese bloque de citas. **Ninguna de sus 19 direcciones apunta hoy a lo que anuncia.**
>
> **No se renumeran.** Ya se probó en este repositorio: las seis citas que se renumeraron a mano el
> 31/08 están caducadas hoy. **Lo que se lee es el símbolo, con `grep`:**
> `grep -rn "degradado_salir" 01_Firmware/Esclavo/` cuesta lo mismo y no caduca. Las citas de este
> manual quedan como **orientativas y sin autoridad**: si una y el `grep` no coinciden, **manda el
> `grep`**.
>
> ### 4. 🔴 `D-18` NO TIENE CANAL DE VUELTA: el Maestro no puede enterarse de que el Esclavo está en Degradado
>
> El Esclavo **sí** entra en Degradado por app —`SET_MODO:DEGRADADO` existe en su `bluetooth.cpp`,
> es la fila `D-18` de `DECISIONES.md`—. Lo que **no existe** es ningún comando de radio por el que
> lo anuncie, y el getter de estado del Maestro **sólo sabe devolver color**. **Si algún párrafo de
> este manual describe al Maestro reaccionando a que el Esclavo entró en Degradado, o a la app
> enseñándolo desde el Maestro, es falso hoy.**
>
> ⚠️ **Y el matiz que hay que dar para no cambiar una frase falsa por otra: el dato SÍ es visible,
> pero sólo desde el otro poste.** El `$STATUS` **del propio Esclavo** lo publica —
> `obtenerNombreModo()` en `Esclavo/src/bluetooth.cpp` devuelve `SUBORDINADO` · **`DEGRADADO`** ·
> `RENDIDO`—, así que una app conectada al **poste 2** lo ve. Lo que no hay es **vista de cruce**:
> hay que conectarse a las dos puntas una por una, **y el Maestro no puede reaccionar** — que es lo
> que decide, porque el Degradado es el único modo que da verde sin confirmar la otra punta.
>
> ### 5. 🔴 LA ANTIGÜEDAD DE LA ÚLTIMA SINCRONIZACIÓN NO VIAJA EN NINGUNA TRAMA — y se quedó sin lector
>
> Las dos plantillas reales del `$STATUS`, leídas hoy del `snprintf` de cada punta:
>
> ```
> $STATUS,NODE:MAESTRO,SERIE:%s,MODO:%s,ESTADO:%s,T:%s,RF:%s,RTT:%s,BAT:--,HORA:%s,ESC:%s,PLUMA:%s,CAM:%s
> $STATUS,NODE:ESCLAVO,SERIE:%s,MODO:%s,ESTADO:%s,T:--,RF:--,RTT:--,BAT:--,HORA:%s,PLUMA:%s,CAM:%s
> ```
>
> **No hay campo de antigüedad de sincronización en ninguna de las dos.** Y los dos getters que la
> publicaban —`degradado_syncVencida()` y `degradado_avisoLimite()`, declarados en
> `Esclavo/include/modo_degradado.h`— **tienen un solo llamador, `Esclavo/src/menu.cpp`**: la
> pantalla que `D-17.bis` retira del equipo.
>
> ```
> $ grep -rn "degradado_syncVencida\|degradado_avisoLimite" 01_Firmware/Esclavo --include=*.cpp
> src/menu.cpp:86  · src/menu.cpp:117 · src/menu.cpp:129 · src/modo_degradado.cpp:186 (la definicion)
> ```
>
> **Consecuencia para el técnico que sube al poste 2: sin menú y sin campo en la trama, no tiene
> forma de ver cuánto hace que ese equipo se sincronizó, ni sustituto por app.** No es un descuido
> de redacción de este manual: es un dato que existe dentro del micro y **hoy no sale**.
>
> ### 6. Y el marco que cambió debajo de todo esto: `D-16`
>
> **Sin teléfono no hay forma de operar el equipo.** Retirado el mando de relés (`D-1`), **la app es
> la única superficie de mando**: ni ámbar, ni volver a automático, ni parar el cruce. Este manual
> describe la app como *«consola de servicio»* y *«accesorio de diagnóstico»* — **hoy es la única
> vía de operación, y el teléfono es herramienta crítica** (batería, cable, y conviene un segundo
> terminal emparejado).

---

**Software Móvil:** App Android (.apk) con Frontend Reactivo Dark-Theme (Estándar IOT-VIAL)  
**Propósito:** Telemetría en tiempo real, caja negra de alarmas, test de banco, ~~sincronización Courier RTC~~ **puesta en hora del POSTE 1 y consulta del reloj de los dos** *(07/09: el Courier RTC queda **derogado por `D-20`** — ver `§3`, Pantalla 5)* y control desde el suelo con PIN  
**Verificación Hardware:** Esquemáticos KiCad `Controladora_Semaforos.kicad_sch`, `pines.h` y `MAPEO_TARJETA_KICAD.md`  
**Fecha de Emisión:** 26 de Agosto de 2026  
**Última revisión:** 28 de Agosto de 2026 — **el apartado 2 se redibujó entero: el módulo entra por
el conector `J17` (`USART1` REMAPEADO a `PB6`/`PB7`), NO por `PA9`/`PA10`.** Además, en el mismo
apartado: corrección del transceptor `U3` → **`U2`**, y el `PA8` reclasificado como **residuo
pendiente de revisar** (su motivo original desapareció con el remapeo). En el apartado 1: criterio
de compra del módulo (ESP32 sí/no), consumo y puesta a punto con `AT+NAME`.

> ⚠️ **Sobre la revisión anterior de esta misma fecha, que se quedó a medias.** Corrigió `U3` → `U2`
> y anunció esa corrección aquí, **pero dejó intacto el pinout `PA9`/`PA10` del mismo apartado 2**,
> que ya estaba obsoleto. El resultado era peor que no haber tocado nada: el apartado quedó con la
> referencia del chip bien y el cableado mal, y el detalle corregido en la cabecera daba a entender
> que el apartado entero estaba revisado. **Esta cabecera enumera lo que se revisó; no garantiza
> nada que no nombre explícitamente.**

**Revisión del 31 de Agosto de 2026 — QUÉ SE REVISÓ, y nada más que esto:**

1. **§1.9 rehecha.** Publicaba la decisión **contraria** a la vigente —*«se instala `HC-05` / `JDY-30`,
   no ESP32»`*— cuando el 28/08 se decidió y se dejó escrito lo opuesto. **La fila de la tabla de
   caminos se ha DECIDIDO y anotado**, que era lo que faltaba.
2. **§2.3: el módulo del diagrama pasa de `HC-05`/`JDY-30` a `ESP32`.** El **pinout de `J17` p2/p3 NO
   se ha tocado**: era y sigue siendo correcto. Lo que estaba mal era el módulo dibujado.
3. **§2.3.bis nueva: la alimentación.** El ESP32 lleva **fuente propia desde 12 V** y no cuelga del
   3,3 V de `J17`.
4. **«Puesta a punto del módulo… el `AT+NAME`» marcada como NO aplicable a un ESP32**, con lo que la
   sustituye y lo que falta.

5. **§2.1: se corrige el «el `.kicad_pcb` está vacío»**, que era falso — el fichero pesa 2.158.421 B y
   trae 185 huellas y 1.447 pistas. **La advertencia de medir con multímetro se mantiene íntegra**:
   lo que se corrige es el motivo, no la precaución.

**Lo que NO se ha tocado en esta revisión, y sigue como estaba:** el **apartado 1 congelado** (el
cuadro de arquitectura, las tres razones y la tabla de prohibiciones), el pinout de `J17`, §2.2
(`J16` vs `J17`), **§2.5 (`PA8`/`J10`, residuo pendiente)**, y los apartados 3, 4 y 5.

> 🛑 **NADA DE ESTO HA PASADO PRUEBA DE BANCO, y este manual no es un permiso para instalar.**
> ~~Hay **dos bloqueos vivos delante del montaje**: `BLQ-1` —la serigrafía del ESP32, sin leer— y la
> línea `A5` —la fuente propia, sin pedir—. Y **el firmware del puente SPP del ESP32 no existe
> todavía** (MEDIDO el 31/08).~~
>
> 🔴 **TACHADO el 07/09, y las DOS mitades eran falsas — ver la fe de erratas de la cabecera.**
> **Queda UN bloqueo, no dos:** `BLQ-1` está cerrado desde el 31/08 (fila de `ESTADO.md`, N-107 en
> `roadmap.md`, y el propio recuadro de arriba de este manual). **Y el firmware del puente SÍ
> existe** desde ese mismo 31/08: `01_Firmware/ESP32_Expansion/`, 16 ficheros, 2.588 líneas
> (`d2427c2`). **El único bloqueo vivo es la línea `A5`, la fuente propia DC-DC, que sigue sin
> pedirse.** El cableado de §2.3 describe **a dónde van los hilos**, y hoy ya hay firmware que los
> ejerce; lo que falta para instalar es la fuente, no el código.

> 🔒 **EL APARTADO 1 NO SE HA DEROGADO, Y ESTA REVISIÓN NO LO DEROGA.** Sigue congelado: **Bluetooth
> Clásico SPP, no BLE, no Web Bluetooth**. Un ESP32 **clásico** haciendo de puente SPP **cabe dentro
> de esa decisión sin reabrirla** —es la vía que el propio manual dejaba abierta—, y es justamente por
> eso que se eligió esa fila y no otra.

---

## 1. Arquitectura de la App — DECISIÓN CONGELADA

> ### 🔒 **Bluetooth Clásico SPP. No BLE. No Web Bluetooth. Y no es negociable sin reabrir este apartado por escrito.**

Esto se congela porque ya se fue por el camino equivocado una vez y hay que dejar constancia de por
qué, o se repetirá.

### Lo que se eligió

```text
 ┌─────────────────────────────────────────────────────────────────────────────┐
 │                    ARQUITECTURA DE LA APP MÓVIL (V9.0)                      │
 ├─────────────────────────────────────────────────────────────────────────────┤
 │ • ENLACE:        Bluetooth CLASICO, perfil SPP.                             │
 │                  UUID 00001101-0000-1000-8000-00805F9B34FB                  │
 │ • MODULOS:       HC-05 / JDY-30.  NO HM-10, NO JDY-31, NO BLE.              │
 │ • EMPAREJADO:    Lo hace ANDROID en Ajustes, con PIN 0000 o 1234.           │
 │                  La app NO empareja: solo lista getBondedDevices().         │
 │ • IMPLEMENTACION: Puente NATIVO Android en el proyecto Capacitor            │
 │                  (BluetoothAdapter + createRfcommSocketToServiceRecord).    │
 │                  NO navigator.bluetooth. NO navigator.serial.               │
 │ • CONEXION:      UNA a la vez, explicita. SIN reconexion automatica.        │
 │ • INTERFAZ:      HTML5 + CSS + JS en WebView (Dark Theme IOT-VIAL).         │
 │ • ALMACENAMIENTO: LocalStorage / IndexedDB para logs y cruces.              │
 │ • AUTONOMIA:     100% offline. Opera en montana sin internet ni 4G.         │
 └─────────────────────────────────────────────────────────────────────────────┘
```

> 📌 **El cuadro de arriba se deja LITERAL, porque es el acta de la decisión congelada — pero una de
> sus once líneas ya no describe el montaje.** La línea `MODULOS: HC-05 / JDY-30` se sustituye por
> **`ESP32` clásico haciendo de puente SPP** (§1.9, decisión de obra del 28/08).
>
> **Las otras diez líneas no cambian, y ese es exactamente el argumento**: el enlace sigue siendo
> Bluetooth Clásico SPP con el mismo UUID, el emparejado lo sigue haciendo Android en Ajustes, el
> puente nativo `createRfcommSocketToServiceRecord` **no se toca**, y `NO BLE` sigue siendo `NO BLE`.
> **Cambia quién lleva la radio, no qué radio es.** Por eso este apartado **no se reabre** — y por eso
> mismo, si el módulo resultara ser BLE, **sí habría que reabrirlo** (`BLQ-1`, §1.9).

### Por qué SPP y no BLE — las tres razones, para que no se vuelva a preguntar

1. **`navigator.bluetooth` (Web Bluetooth) solo habla BLE.** No es que falle con un HC-05: **la API
   no existe para SPP**. La versión anterior de esta app usaba `navigator.bluetooth` y por eso *no
   abría el Bluetooth y no se conectaba a ningún dispositivo*. No era un error de programación: era
   la tecnología equivocada.
2. **La app probada en campo de esta casa es la de Baliza, y usa SPP.** `BluetoothAdapter`,
   `getBondedDevices()`, `createRfcommSocketToServiceRecord(00001101-…)`, con reintento por
   `createInsecureRfcommSocketToServiceRecord`. Está funcionando en la calle. **Se copia ese bloque,
   no se reinventa.**
3. **El técnico ya sabe usarlo.** Empareja en Ajustes de Android con `0000` o `1234` —el PIN del
   módulo, no el del semáforo— y la app le lista lo que ya está emparejado. Cambiar a BLE le cambia
   un flujo que domina, sin darle nada a cambio.

### Lo que queda PROHIBIDO, y por qué

| Prohibido | Motivo |
|---|---|
| `navigator.bluetooth` / Web Bluetooth | No puede ver un HC-05. Es la causa del fallo anterior |
| Módulos BLE (`HM-10`, `JDY-31`) | Obligarían a rehacer el puente nativo y cambiar el flujo del técnico |
| Reconexión automática | El operario camina al Km 24, el teléfono se reengancha solo al Km 12 que sigue en rango, y la pantalla muestra un sistema vivo **que está a 12 km**. No hay forma de que lo note |
| Dos conexiones simultáneas | Físicamente imposible —los postes de una pareja están a cientos de metros y el Bluetooth alcanza 10-15 m— y Baliza ya usa un único socket. **Una a la vez es una propiedad de seguridad, no una limitación** |

### 🔍 Qué módulo cumple esta decisión: la etiqueta comercial NO lo dice

> **El 28/08 llegaron a obra módulos `ESP32` en vez de los `HC-05` que pedía la lista de compras.**
> Eso obliga a escribir aquí algo que faltaba: **«ESP32» no es una respuesta a la pregunta «¿habla
> SPP?»**. Unos sí y otros no, y el rótulo del vendedor no permite distinguirlos.

| Familia | Radio que lleva de verdad | ¿Sirve para esta app? |
|---|---|---|
| `ESP32-WROOM-32` · `-32D` · `-32E` · `-32U` (ESP32 **clásico**) | Bluetooth **Clásico (BR/EDR)** + BLE | ✅ **Sí.** Tiene SPP: `createRfcommSocketToServiceRecord` conecta y **la app funciona tal cual**, sin tocar el puente nativo |
| `ESP32-S3` · `ESP32-C3` | **Solo BLE** | ❌ **No.** El socket RFCOMM no abre contra ellos. Es **exactamente el fallo del `navigator.bluetooth`** que congeló este apartado, pagado por segunda vez |
| `ESP32-S2` | **Sin radio Bluetooth.** Solo WiFi | ❌ **No.** No hay nada que emparejar en Ajustes de Android |

**La etiqueta del vendedor no es un instrumento.** Las tres familias se anuncian con la misma
cadena —*«WiFi + BT · SoC · ISM 2.4G · 802.11»*— y esa cadena dice que hay una radio de 2,4 GHz;
**no dice si hay Bluetooth Clásico**. Comprar leyendo el anuncio es elegir al azar entre las tres
filas de la tabla, y dos de las tres no conectan.

> Es la **regla del instrumento** del repositorio aplicada a una etiqueta: *un «no aparece» no es un
> hallazgo hasta haber descartado al buscador*. Aquí el buscador es el rótulo comercial, y **no sabe
> distinguir lo que se necesita**. Un módulo no queda descartado ni aprobado por lo que diga el
> listado del proveedor.

**Dónde sí está la respuesta. Las dos formas miran el chip, no el anuncio:**

1. **La serigrafía del blindaje metálico del módulo.** Sobre la lata va impresa la referencia real
   (`ESP32-WROOM-32E`, `ESP32-S3-WROOM-1`, …). Es la que manda.
2. **Preguntándoselo al propio chip**, con el módulo conectado por USB:
   ```text
   python "C:/.platformio/packages/tool-esptoolpy/esptool.py" --port COM# chip_id
   ```
   `esptool.py v4.11.0` **ya está instalado** en la máquina de trabajo (viene con PlatformIO): no hay
   que descargar nada. Responde con la familia detectada —`Chip is ESP32-D0WD-V3`, `Chip is
   ESP32-S3`, …— y esa línea es la que decide.

> ~~⏳ **PENDIENTE — no se da por sabido.** De los módulos que llegaron a obra **la referencia exacta
> está sin confirmar**. Hasta que alguien lea el blindaje o corra el `chip_id` de arriba y lo anote,
> **no se sabe si sirven**.~~
>
> 🔴 **TACHADO el 07/09: esto es `BLQ-1`, y `BLQ-1` está CERRADO desde el 31/08.** Este documento lo
> declara cerrado en su recuadro de cabecera y lo reabría aquí, veinte líneas después. La referencia
> **está confirmada por la ficha del artículo comprado**: `ESP32-WROOM-32` clásico, `BR/EDR`, hay
> SPP (`grep -n "BLQ-1" ESTADO.md` · `grep -n "N-107" roadmap.md`). **No hace falta leer ningún
> blindaje para instalar.**
>
> ✅ **Lo que del párrafo anterior SÍ sigue valiendo, y por eso el `chip_id` de arriba se conserva:**
> si algún día llega un módulo distinto, un `S3` o un `C3` **no habla SPP**, la app no conectará
> jamás, y el síntoma será indistinguible del fallo que congeló este apartado —*«no abre el
> Bluetooth, no se conecta a ningún dispositivo»*—. **El comando es la forma barata de descartar esa
> causa ante un módulo de procedencia desconocida**; deja de ser un requisito previo al montaje y
> pasa a ser una herramienta de diagnóstico.

### ⚡ Si se va con un ESP32, el consumo no es un detalle de montaje

Un ESP32 con WiFi activo da **picos de ~500 mA**. La alimentación de la tarjeta es
`12 V → LM7805 → LM1117-3.3`, y ese camino **no los aguanta**:

* **El `LM7805` se quema.** A 500 mA disipa $(12-5)\times 0{,}5 = 3{,}5\ \text{W}$, que sin disipador
  no se evacúan.
* **Y antes de quemarse, se lleva por delante al micro.** Si el riel de 3,3 V se hunde, **se reinicia
  el STM32 que está gobernando el semáforo**. El síntoma en campo no se parece a un fallo de
  telemetría: se parece a un cruce que se reinicia solo, y ahí ya no se está diagnosticando un
  módulo de diagnóstico.

> 🔌 **Regla de alimentación: un ESP32 va con FUENTE PROPIA desde los 12 V, masa común con la
> tarjeta y alimentación NO compartida.** Un `HC-05` (~40 mA) sí puede colgarse del riel de la placa
> —por eso el diagrama del apartado 2 lo dibuja así—, y **ese diagrama no vale para un ESP32**.

### 1.9 ✅ La decisión VIGENTE: el ESP32 clásico SUSTITUYE al módulo SPP dedicado

> ### ~~✅ Decisión de obra del 28/08: se sigue con el módulo SPP dedicado~~
> ### ~~**Se instala `HC-05` / `JDY-30`, no ESP32.**~~
>
> ⛔ **ANULADO. Era la decisión de la 1.ª revisión del 28/08, y ese mismo día se decidió lo
> contrario.** Este manual se quedó publicando la versión vieja **once días**, mientras
> `15_Lista_de_Compras_Hardware.md` ya publicaba la nueva desde el commit `2e6baf4`.
>
> **Su motivo era bueno y se conserva escrito**, porque es la mitad del argumento que sigue en pie:
> un módulo SPP dedicado deja esta decisión congelada intacta y su consumo cabe en la alimentación
> que la tarjeta ya tiene. **Lo que lo tumbó no fue el argumento: fue el almacén.**
>
> **No se borra**, porque una vía descartada que desaparece en silencio se vuelve a proponer, y la
> segunda vez ya nadie recuerda por qué se descartó.

**Lo que manda hoy, y por qué este manual no era quien lo decidía:**

```
15_Lista_de_Compras_Hardware.md:159  "Decision de obra del 28/08 - VIGENTE: el ESP32 SUSTITUYE al modulo SPP"
15_Lista_de_Compras_Hardware.md:85   linea A1 ANULADA: los HC-05 "nunca llegaron, y ya no se piden"
ESTADO.md:80                         "sustituyendo al modulo SPP dedicado"
ESTADO.md:251                        A3: "ya no se compran HC-05 ni JDY-30: los sustituye el ESP32"
```

📖 **LEÍDO** en esos documentos, no medido: **los `HC-05` nunca llegaron a obra, ya no se piden, y el
28/08 llegaron módulos `ESP32` en su lugar.** No se está eligiendo entre dos módulos disponibles: hay
uno.

#### La fila decidida — y se decide aquí, por escrito, porque faltaba

La tabla de caminos del 28/08 se publicó **sin ninguna fila marcada como elegida**, que es como este
manual acabó contradiciendo a la lista de compras sin que nada chirriara. **Se decide ahora:**

| Camino | Qué exige | Estado de este apartado 1 | Decisión |
|---|---|---|---|
| ~~`HC-05` / `JDY-30` (SPP)~~ | ~~Nada nuevo. Es lo que este manual ya especifica~~ | ~~Intacto~~ | ⛔ **DESCARTADO 28/08.** No llegaron y ya no se piden (`15_…:85`) |
| **ESP32 clásico** (`WROOM-32`/`-32D`/`-32E`/`-32U`) haciendo de **puente SPP** | Confirmar la referencia por serigrafía o `chip_id`, y **fuente propia de 12 V** | **Intacto**: sigue siendo Bluetooth Clásico SPP, que es lo que este apartado congela | ✅ **ELEGIDO.** 🛑 **Condicionado a `BLQ-1`** |
| ESP32 **por WiFi / BLE** (`S3`, `C3`, `S2`, o cualquiera renunciando al SPP) | Rehacer el transporte de la app entero | 🛑 **Exige REABRIR ESTE APARTADO 1 POR ESCRITO**, antes de comprar y antes de escribir una línea | ⛔ **NO ELEGIDO.** Es la rama que hay que evitar, no un plan |

> **Por qué la fila 2 y no otra, que es lo único que autoriza a no reabrir el apartado 1.** Esa vía
> ya estaba abierta en la tabla original: **un ESP32 clásico haciendo de puente SPP deja el apartado 1
> INTACTO**. Si la serigrafía dice `ESP32-WROOM-32`/`-32D`/`-32E`/`-32U`, **hay Bluetooth Clásico
> BR/EDR, hay SPP, y `createRfcommSocketToServiceRecord` conecta sin tocar una línea de la app.**
> Cambia el módulo; **no cambia el transporte**, que es lo que este apartado congela.
>
> **La última fila no es burocracia, y no se ablanda.** El valor de una decisión congelada está
> justamente en que cambiarla cueste un documento: la vez anterior se cambió de transporte sin
> escribirlo y el resultado fue una app que no conectaba con nada. Un ESP32 por WiFi o BLE no es «el
> mismo módulo con otra radio»: cambia el emparejado, el descubrimiento, la autonomía sin internet y
> el flujo del técnico. Si se toma ese camino, **se reabre aquí, con fecha y firma, antes**.

#### 🛑 `BLQ-1` — BLOQUEO VIVO: nadie ha leído la serigrafía. **No lo resuelve este manual.**

> ## Hasta que alguien lea el blindaje del módulo, **NO SE SABE en cuál de las dos ramas estamos**, y las dos consecuencias son distintas.

📖 **LEÍDO** en `ESTADO.md:23` (`BLQ-1`, dueño: **Responsable**) y `15_Lista_de_Compras_Hardware.md:86`
(línea `A1′`, **🛑 BLOQUEADA**): de los módulos que llegaron a obra el 28/08, la **referencia exacta
está sin confirmar** y la **cantidad sin anotar**.

| si la serigrafía dice… | qué pasa con la app | qué pasa con este apartado 1 |
|---|---|---|
| `ESP32-WROOM-32` · `-32D` · `-32E` · `-32U` | ✅ **Nada. Conecta tal cual**, sin tocar el puente nativo | ✅ **Intacto.** No se reabre |
| `ESP32-S3` · `ESP32-C3` | 🔴 **El socket RFCOMM no abre NUNCA.** Hay que **rehacer el transporte de la app entero** | 🛑 **Reapertura OBLIGATORIA, por escrito** |
| `ESP32-S2` | 🔴 **No tiene radio Bluetooth.** No hay nada que emparejar en Ajustes de Android | 🛑 **Reapertura OBLIGATORIA, por escrito** |

**Lo que cuesta no saberlo, y es la parte que no se ve:** si son `S3` o `C3`, el síntoma en campo es
**indistinguible** del fallo que congeló este apartado —*«no abre el Bluetooth, no se conecta a ningún
dispositivo»*—, y el tiempo de diagnóstico se gasta otra vez en el sitio equivocado. **Es la regla del
instrumento aplicada a una etiqueta:** el rótulo del vendedor no distingue las tres familias, así que
comprar o instalar leyendo el anuncio es elegir al azar entre tres filas de las que **dos no
conectan**.

**Cómo se levanta el bloqueo — treinta segundos, y es una medida, no una consulta al proveedor:**
leer la **serigrafía del blindaje metálico**, o correr el `chip_id` de «Qué módulo cumple esta
decisión: la etiqueta comercial NO lo dice», más arriba en este mismo apartado. **Y anotarlo**, en
`ESTADO.md` y en la línea `A1′` del Manual 15. Mientras no esté anotado, **`BLQ-1` sigue vivo y este
manual sigue sin poder afirmar que el montaje funcione**.

> 🔴 **Y `BLQ-1` bloquea también la compra:** no se compra ni un ESP32 más hasta leer qué referencia
> llegó (`15_…:86`). Un lote entero de `S3` es un lote entero de módulos que no sirven.

### El flujo de campo, que es el de Baliza

```text
  1. Ajustes de Android > Bluetooth > emparejar > PIN 0000 o 1234
  2. Abrir la app > "Buscar" > lista los emparejados (nombre + MAC)
        SEM-7A3F-M   Maestro, Km 12
        SEM-7A3F-E   Esclavo,  Km 12
        SEM-C104-M   Maestro, Km 24
  3. Tocar uno > socket RFCOMM sobre SPP > leer/escribir lineas
```

El nombre visible del módulo se fija con `AT+NAME`, así que **la lista de Android ya dice quién es
cada equipo antes de conectar**. El técnico lee; no adivina.

### 🔧 Puesta a punto del módulo ANTES de instalarlo — el `AT+NAME` no es opcional

> ## ⚠️ ESTE PROCEDIMIENTO ES DE `HC-05`, Y CON UN ESP32 **NO SE APLICA**. La NECESIDAD sí sigue en pie.
>
> **Lo que NO cambia:** dos módulos sin matricular en el mismo corredor salen en la lista de Android
> como dos filas iguales, y el técnico **no sabe a qué poste se ha conectado**. Eso es igual de grave
> con un ESP32 que con un `HC-05`, y sigue siendo obligatorio.
>
> **Lo que SÍ cambia:** un ESP32 **no tiene modo AT ni `AT+NAME`** — el nombre lo fija **su propio
> firmware**, en la llamada que abre el `SerialBT` del lado ESP32 (`SerialBT.begin("SEM-7A3F-M")` en
> el API clásico de Arduino-ESP32). No hay terminal a 38400 bps que abrir: **hay un firmware que
> escribir y grabar**.
>
> ~~🔴 **Y ese firmware NO EXISTE. MEDIDO el 31/08:** el único fuente de ESP32 del repositorio es
> `01_Firmware/Repetidor/src/main.cpp` (un solo fichero, 8.348 B), **que es el del repetidor de radio,
> no un puente Bluetooth**. Mientras no exista, **no hay nada que rotular y no hay módulo que
> instalar**: no es un paso que se salta, es un paso que todavía no tiene con qué hacerse.~~
>
> ~~🟡 **PENDIENTE, con dueño: escribir el firmware del puente SPP del ESP32, y en él la matrícula.**
> Va **detrás del watchdog** del ESP32 —hoy no tiene ninguno, y hay precedente escrito de uno clavado
> tumbando el enlace el 31/07— según el orden de fases de `ESTADO.md:107`. **Lo decide y lo ordena el
> responsable**, no este manual.~~
>
> # 🔴 TACHADO EL 07/09 — ESTE ES EL `MEDIDO` CADUCADO DE ESTE MANUAL, Y LA FECHA ERA CORRECTA
>
> **La medida del 31/08 fue cierta el día que se tomó, y el módulo entró ESE MISMO DÍA**
> (`d2427c2`, `2026-08-31`). Una fecha correcta no valida el contenido: **`01_Firmware/ESP32_Expansion/`
> son 16 ficheros y 2.588 líneas**, y trae las dos cosas que este bloque daba por pendientes:
>
> | lo que este bloque daba por inexistente | lo medido hoy, por símbolo |
> |---|---|
> | la **matrícula** | `ROTULO_PREFIJO "SEM-"` y `ROTULO_PROVISIONAL "SEM-SIN-MATRICULA"` en `ESP32_Expansion/include/contrato.h`; se aplica en `transporte_app.cpp` sobre `spp.begin(rotulo)` y **se guarda en NVS**, así que sobrevive al corte |
> | el **watchdog**, que era el requisito previo | `#include <esp_task_wdt.h>` en `ESP32_Expansion/src/vigilante.cpp`, con `ESP32_WDT_MS` y su pack |
>
> 🔴 **Lo que esto cambia para quien monta: ya no falta «un firmware que escribir». Falta la línea
> `A5`, la fuente propia DC-DC 12 V→5 V, que sigue sin pedirse** — y ésa sí bloquea (§2.3.bis).
>
> ⚠️ **Y una diferencia de método que hay que saber antes de rotular:** el rótulo **no se teclea**
> como un `AT+NAME`. Se aprende y se guarda solo; un módulo que aún no ha aprendido su serie sale
> como `SEM-SIN-MATRICULA`, que es **un nombre que admite que no sabe** en vez de uno inventado. Si
> en la lista de Android aparece esa cadena, el módulo está sano y **todavía no ha visto a su
> equipo**: no es una avería del Bluetooth.
>
> **Lo que sigue se conserva íntegro** porque describe el `HC-05` que puede haber montado ya en algún
> equipo, y porque **el `9600 8N1` del modo datos lo impone el firmware del STM32 y vale para los dos
> módulos**.

> **Ese «la lista ya dice quién es cada equipo» no ocurre solo: hay que provocarlo en el banco, con
> el módulo en la mano y antes de que suba al poste.**

Un módulo recién sacado de la bolsa se anuncia con su nombre de fábrica. Dos módulos de fábrica en
el mismo cruce salen en la lista de Android como **dos `HC-05` idénticos**, distinguibles solo por
la MAC — que nadie lleva apuntada subido a una escalera. El técnico ve dos filas iguales, elige una,
y **no sabe a qué poste se ha conectado**. Ese es justo el error que la matrícula `SEM-…-M` /
`SEM-…-E` existe para impedir.

**Procedimiento, uno por módulo, rotulando el módulo por fuera con el mismo nombre:**

```text
  1. Modo AT: alimentar el modulo con el boton/pin KEY en alto (HC-05 arranca en AT)
  2. Terminal serie a 38400 bps 8N1, final de linea CR+LF
  3. AT              -> debe responder  OK
     AT+NAME=SEM-7A3F-M     (Maestro del cruce)      -> OK
     AT+NAME=SEM-7A3F-E     (Esclavo del mismo cruce) -> OK
     AT+UART=9600,0,0       (deja el modo datos a 9600 8N1)
  4. Quitar el modo AT, reiniciar, y comprobar que Android lo lista con el nombre nuevo
```

> ⚠️ **Las dos velocidades son distintas y confundirlas parece un módulo muerto:**
>
> | | velocidad |
> |---|---|
> | **Modo AT** (configuración, antes de instalar) | **38400 bps** |
> | **Modo datos** (operación, ya en el poste) | **9600 bps** — que es la de `USART1` en el firmware y la de todas las tramas del apartado 4 |
>
> Si el módulo se deja a otra velocidad en modo datos, la telemetría llega como basura y el síntoma
> es idéntico al de un cable cruzado. **El `9600` no se elige: lo impone el firmware.**

**La matrícula sigue el patrón del apartado anterior:** `SEM-<SERIE>-M` y `SEM-<SERIE>-E`, donde
`<SERIE>` son los 24 bits en hexadecimal que el propio equipo emite en `$STATUS` (§ 4.2). Así el
nombre que se lee en la lista de Android y el que viaja en la trama **son el mismo dato**, y un
módulo trasplantado a otra placa se delata al primer `$STATUS`.

### Lo que la app NO puede hacer, aunque el operario lo pida

**Al Esclavo no se le manda nada que abra paso.** Puede leer telemetría, ~~ajustar el reloj~~
**CONSULTAR el reloj sin cambiarlo (`CMD:LEER_RTC`)**, forzar
rojo —que es la dirección segura— y **solicitar paso**, que viaja por radio al Maestro como una
demanda: el Maestro decide, aplica el todo-rojo y ordena.

> 🔵 **11/09 (`D-26`, construida en `68dd2c5`, sin banco) — ESTA CAJA ESTÁ CADUCADA EN SU NÚCLEO, Y
> SE CORRIGE HACIA LA DECISIÓN:** «ajustar el reloj» **vuelve** a la lista del poste 2. Con radio, su
> controladora hace caso a la hora del Maestro; **sin radio, toma la de su propio ESP32, que el técnico
> le pone desde el teléfono en su gabinete** —es lo que se hace cuando salta la alarma de radio—. La
> prohibición de abajo ya estaba tachada en la propia fila `D-20` el 07/09 por la noche (*«la barrera
> es la SOBREESCRITURA»*). Qué ve y qué hace el técnico: `14_Manual_App_Movil_IOT_VIAL.md` §5.3.bis.
>
> ~~🛑 **07/09 (`D-20`) — «AJUSTAR EL RELOJ» SALE DE ESTA LISTA, Y ES LA CORRECCIÓN MÁS DURA DEL
> APARTADO: ES JUSTO LA FRASE DONDE HACÍA FALTA LA PROHIBICIÓN.**~~
>
> **LA AUTORIDAD DE LA HORA ES EL ESP32**, ~~SIEMPRE Y PARA TODO. La app le da la hora al **ESP32
> Maestro**; ése al **ESP32 Esclavo**; y el STM32 de cada punta la recibe **de su propio ESP32**.
> **Hay UNA sola fuente.** Un `SET_RTC` dirigido al Esclavo **se rechaza**: no es una sincronización,
> **es una segunda fuente de hora**.~~ y el STM32 de cada punta la recibe **de su propio ESP32**; el
> del poste 2, **con radio**, hace caso a la del Maestro. Filas **`D-20`** y **`D-26`** de `DECISIONES.md`.
>
> ```
> ESP32-M  ->  STM32-M  ->  radio  ->  STM32-E  ->  ESP32-E      (los STM32 son CARTEROS)
> ```
>
> **Los dos ESP32 NO se hablan entre sí**: el único enlace entre postes es la radio entre los STM32.
>
> ✅ **Lo que NO cambia: `CMD:LEER_RTC` se sigue mandando A LOS DOS POSTES.** ~~`D-20` prohíbe
> **escribir** la hora en el poste 2;~~ **leerla no escribe nada** ~~, y con `D-20` construida es la
> única forma de comprobar que la siembra del Maestro llegó de verdad~~ *(11/09: la radio no escribe el
> `DS3231` del poste 2; lo que mide es el salto que dará el poste 2 al perder la radio)*.
>
> ~~🔴 **DECIDIDA Y SIN CONSTRUIR.**~~ *(construida el 11/09 en `68dd2c5`)* **Medido el 07/09, corrido antes de publicarlo** *(crónica)*:
>
> ```bash
> $ grep -c "ESCLAVO\|Esclavo\|esclavo" 01_Firmware/ESP32_Expansion/src/despachador.cpp
> 0
> ```
>
> El puente es **el mismo firmware en los dos postes** y el fichero que decide qué hacer con un
> `SET_RTC` **no nombra al Esclavo ni una vez**: hoy lo atiende venga por donde venga *(11/09: y con
> `D-26` es lo correcto)*. ~~Falta también el mando **ESP32 → STM32** que siembre la hora en la
> controladora (el camino físico existe, `enlace_stm32.cpp`; el mando no).~~ *(existe desde `68dd2c5`:
> `CMD:HORA_ESP32`, `siembra.cpp`)*
>
> ~~⚠️ **Mientras tanto NO hay ninguna otra vía de poner en hora el poste 2, así que hoy se sigue
> visitando y sincronizando allí. Eso es un ESTADO DECLARADO, no la arquitectura**, y muere el día
> que `D-20` se construya.~~ *(No muere: es el procedimiento de `D-26` (5).)*
>
> 🔵 **Y la regla de operación que sale de todo esto: EL POSTE 2 SE PONE EN HORA EN LA PUESTA EN
> MARCHA** ~~**, NO DURANTE LA AVERÍA.** Con `D-20` dentro, el único camino al reloj del poste 2 pasa
> por la **radio**, y la radio se cae justo cuando hace falta el Modo Degradado — que es el modo que
> **exige hora**.~~ **Y CON LA RADIO CAÍDA, ALLÍ MISMO** (`D-26`). ✅ **Su `DS3231` tiene pila y
> conserva la hora que ya tenía. Perder la radio no es perder la hora.** Por eso se pone también
> **antes**: en la puesta en marcha, al cambiar la pila de ese módulo, y tras cualquier
> `OSCILADOR_PARADO_CAMBIE_PILA` leído allí.

**Al probarlo, espere esa asimetría: es la regla, no una avería.** Una petición hecha en el Esclavo
—por cámara o por la app— no enciende ninguna luz en el Esclavo. Sale al aire, y el verde lo concede
el Maestro después de aplicar el todo-rojo. Si el Esclavo abriera por su cuenta, estaría dando paso
a un carril sin que nadie compruebe el otro.

> **Consecuencia para el operario, que es lo que importa:** da igual en qué extremo esté. Los dos
> postes se operan igual y en la pantalla **no aparecen las palabras «maestro» ni «esclavo»** —
> aparece el sentido de la vía.

---

## 2. Diagrama de Conexión Físico y Desacoplo de Hardware (KiCad)

> ## 🔴 28/08/2026 — ESTE APARTADO SE REDIBUJÓ ENTERO. EL CABLEADO CAMBIÓ.
>
> **El módulo Bluetooth entra por el conector `J17`, en `USART1` REMAPEADO a `PB7`/`PB6`.**
>
> Hasta esta revisión, este manual mandaba cablear a **`PA9`/`PA10`**. Ese pinout **ya no es el
> vigente** y **el firmware que corre hoy no escucha por ahí**. Como este es el **único documento
> de la entrega con dibujo de conexión del módulo**, quien siguiera el dibujo anterior cableaba un
> equipo que no responde, sin nada que le contradijera.
>
> **La corrección no se borra el rastro:** si usted ya cableó a `PA9`/`PA10`, no se ha equivocado
> siguiendo el manual — seguía la versión anterior. Vea **«Si ya se cableó a `PA9`/`PA10`»** al
> final de este apartado antes de tocar nada.

### 2.1 De dónde sale este pinout — y con qué nivel de prueba

Las dos mitades de este apartado **no tienen la misma solidez**, y se separan a propósito:

| dato | nivel de prueba |
|---|---|
| El firmware abre `USART1` sobre `PB7` (RX) y `PB6` (TX) a 9600 bps | ✅ **MEDIDO EN EL FUENTE.** `01_Firmware/Maestro/src/bluetooth.cpp` y `01_Firmware/Esclavo/src/bluetooth.cpp`, línea idéntica en las dos puntas: `static HardwareSerial SerialBT(PB7, PB6);` |
| `J17` p2 = `PB7` (`U1` p43) · `J17` p3 = `PB6` (`U1` p42) · p6/p8 = 3,3 V · p7/p9 = `GND` | 📐 **MEDIDO EN EL ESQUEMÁTICO.** Trazado sobre `Controladora_Semaforos.kicad_sch` (§7 de `05_Funcional/historico/MAPEO_TARJETA_KICAD.md`) |
| Que en la tarjeta física esas vías vayan a donde dice el esquemático | 🔴 **NO VERIFICADO EN LA PLACA.** Nadie lo ha medido con multímetro |

> 🔴 **Esa última fila es una advertencia, no un formalismo. Antes de enchufar el módulo, compruebe
> con el multímetro las vías que vaya a usar** (continuidad de p2 a la pata 43 de `U1`, de p3 a la 42,
> y masa en p7). Son cinco minutos y son los que separan una hipótesis muy buena de un hecho.
>
> ⚠️ **CORRECCIÓN DEL 31/08 al motivo que esta advertencia daba.** Esta nota decía que *«el
> `.kicad_pcb` de este proyecto está vacío»* y que *«no existe ningún artefacto que ate el esquemático
> con la tarjeta»*. **Las dos frases son falsas, y se corrigen midiendo:**
>
> ```
>   wc -c  Controladora_Semaforos.kicad_pcb           ->  2.158.421 B
>   grep -oE '\(footprint\b'  ... | wc -l             ->      185 huellas
>   grep -oE '\(segment\b'    ... | wc -l             ->    1.447 pistas
>   grep -oE '\(via\b'        ... | wc -l             ->       89 vias
>   grep -c  'J17'            ...                     ->  J17 esta en el cobre, con sus pads
> ```
>
> **Por qué se creyó vacío:** KiCad separa los tokens con **tabulador y salto de línea**, así que un
> `grep -c '(segment '` —con espacio detrás— devuelve **0**, y un cero se lee como *«no hay»*. Es la
> **regla del instrumento** aplicada a un formato: `grep` estaba, respondía, y aun así no sabía
> encontrar (`CLAUDE.md` §4).
>
> **Lo que NO cambia con la corrección, y es lo importante:** sigue sin haber **una sola medida con
> punta sobre la tarjeta física**. Que el `.kicad_pcb` esté ruteado sube el nivel de prueba de
> *«hipótesis»* a *«hay un diseño de cobre que lo dice»* — **no lo sube a hecho**. La comprobación con
> multímetro se mantiene íntegra.

### 2.2 ⚠️ ANTES DE ENCHUFAR NADA: `J16` y `J17` SON EL MISMO CONECTOR A LA VISTA

> ## 🔴 `J16` LLEVA 12 V EN SU POSICIÓN 1. ENCHUFAR EL MÓDULO EN `J16` LO QUEMA.

`J16` (botones) y `J17` (donde va el módulo) **comparten el mismo footprint Molex 1x16 en el
cobre**. No se distinguen por la forma, ni por el tamaño, ni por el número de vías: **a la vista son
idénticos.** Y no fallan igual: `J17` reparte 3,3 V y masa, mientras que **`J16` es el único
conector de señal de toda la tarjeta que trae 12 V**, y lo trae en la posición 1 — justo donde cae
el `VCC` si alguien cuenta desde el borde equivocado.

**Cómo se distinguen, y es una medida, no un vistazo:**

```text
  1. Multimetro en tension continua, negra a masa del chasis.
  2. Punta roja en la POSICION 1 del conector, con la tarjeta alimentada.

       ~12 V  -> es J16.  ES EL CONECTOR DE LAS CAMARAS.
                          NO ENCHUFE AQUI EL MODULO, Y TAPE SU POSICION 1.
       ~3,3 V o 0 V -> es J17.  Confirmelo con el paso 3.

  3. Confirmacion de J17: debe haber 3,3 V en las posiciones 6 y 8,
     y masa en las 7 y 9.  J17 NO TIENE 12 V EN NINGUNA POSICION.
```

> ✏️ **05/09 — aquí ponía ~~«es `J16`. ES LA BOTONERA»~~ y ese rótulo caducó.** **`J16` ya no es la
> botonera: es el conector de las CÁMARAS.** `p10` = `CAM_C_PIN` y `p12` = `CAM_D_PIN` (`PB14`/`PB15`);
> `p5` y `p8` quedan **libres y sin cablear** desde `D-1`. **La instrucción de no enchufar el módulo
> ahí no cambia** —sigue habiendo 12 V en `p1` y sigue quemándolo—, pero llamarlo «la botonera»
> mandaba a buscar unos pulsadores que ya no se montan, y **hacía leer `p10` como un botón cuando es
> el borne de una cámara**. Se añade lo que sí hay que hacer con ese pin: **taparlo** (N-120).

> ⚠️ **Y el conector se orienta midiendo, no contando huecos.** El símbolo del esquemático de `J17`
> tiene **13 posiciones** y su footprint en la placa tiene **16** (el de `J16`: 12 en el símbolo, 16
> en el cobre). **Sobran vías físicas que no están en el esquema**, así que contar desde el borde
> del conector desplaza el mapa entero. Se cuenta **desde la posición 1 marcada**, y se confirma la
> orientación **leyendo 3,3 V en la 6 y masa en la 7** antes de insertar el módulo.

### 2.3 Diagrama de conexión — VIGENTE (ESP32 clásico, 31/08)

> ⚠️ **Lo que cambió el 31/08 en este apartado es EL MÓDULO, no el pinout.** `J17` p2 = `PB7` y
> `J17` p3 = `PB6` **siguen siendo correctos y no se han tocado**: son los que midió N-76 sobre el
> esquemático y el fuente. Lo que estaba mal era que el dibujo mandaba enchufar un `HC-05`, y **ese
> módulo ya no es el que se instala** (§1.9).
>
> 🛑 **Y sigue condicionado a `BLQ-1`:** hasta leer la serigrafía del blindaje no se sabe si el ESP32
> que hay en obra habla SPP. **Este diagrama no autoriza a instalar nada.**

```text
 ┌─────────────────────────────────────────────────────────────────────────────┐
 │   CONEXION DE TELEMETRIA BLUETOOTH  --  CONECTOR J17   (VIGENTE 31/08)      │
 ├─────────────────────────────────────────────────────────────────────────────┤
 │                                                                             │
 │   ESP32 CLASICO (WROOM-32/-32D/-32E/-32U)   TARJETA -- CONECTOR J17         │
 │   ┌────────────────────────────┐        ┌──────────────────────────────┐    │
 │   │  GPIO17 (TX2)  transmite   ├────────┤► J17 p2 = PB7  (U1 pin 43)   │    │
 │   │                            │        │           USART1 RX del STM32│    │
 │   │  GPIO16 (RX2)  recibe      ├────────┤► J17 p3 = PB6  (U1 pin 42)   │    │
 │   │                            │        │           USART1 TX del STM32│    │
 │   │  GND                       ├────────┤► J17 p7 = GND     (o p9)     │    │
 │   └────────────────────────────┘        └──────────────────────────────┘    │
 │        ▲                                                                    │
 │        │  ALIMENTACION: NO SALE DE J17.  Fuente propia desde 12 V.          │
 │        │  J17 p6/p8 (3,3 V) SE DEJAN SIN CONECTAR.  Ver 2.3.bis.            │
 │                                                                             │
 │   SON TRES HILOS, NO CUATRO:  RX, TX y MASA COMUN.                          │
 │                                                                             │
 │   LAS LINEAS DE DATOS VAN CRUZADAS:                                         │
 │      TX del ESP32 (GPIO17)  ->  RX del micro (p2).                          │
 │      RX del ESP32 (GPIO16)  <-  TX del micro (p3).                          │
 │   Conectarlas en paralelo -TX contra TX- no rompe nada, pero no llega       │
 │   ni una trama, y el sintoma es identico al de un modulo muerto.            │
 │                                                                             │
 │   LA MASA COMUN ES OBLIGATORIA: con dos fuentes distintas y sin masa        │
 │   comun, las dos puntas no comparten referencia y el serie no cuadra.       │
 └─────────────────────────────────────────────────────────────────────────────┘
```

| hilo del ESP32 | dirección | va a | pin del `U1` | qué es |
|---|---|---|---|---|
| **`GPIO17`** (`TX2`) | ---> | **`J17` p2** | `PB7` (p43) | `USART1` **RX** del STM32 — el micro **escucha** aquí |
| **`GPIO16`** (`RX2`) | <--- | **`J17` p3** | `PB6` (p42) | `USART1` **TX** del STM32 — el micro **habla** aquí |
| `GND` | --- | `J17` p7 (o p9) | — | **masa común, obligatoria** |
| *(alimentación)* | — | **NO va a `J17`** | — | 🔴 **Fuente propia desde 12 V.** `J17` p6/p8 **se dejan libres** — ver 2.3.bis |

**`9600 8N1`.** Es la del `USART1` del firmware y la de todas las tramas del apartado 4: **no se
elige, la impone el firmware.**

✅ **Nivel de prueba de la columna del ESP32 — SUBE de `LEÍDO` a `MEDIDO EN EL FUENTE` el 07/09.**
~~**LEÍDO** en `05_Funcional/17_Arquitectura_28-08_y_Decisiones_Abiertas.md` §1.4 y `ESTADO.md:80` —
es la asignación decidida, **sin firmware que la ejerza todavía** y sin nadie que la haya cableado.~~

**Este manual dejó escrita la condición de su propia corrección —*«si el firmware del puente acaba
usando otros pines, lo que manda es el firmware y esta tabla se corrige entonces»*— y hoy hay
firmware. Se ha ido a mirar, y la tabla ACIERTA:**

```
$ grep -n "ENLACE_PIN_TX\|ENLACE_PIN_RX" 01_Firmware/ESP32_Expansion/include/contrato.h
44:#define ENLACE_PIN_TX         17   // GPIO17 -> J17 p2 -> PB7, que es el RX del micro
45:#define ENLACE_PIN_RX         16   // GPIO16 <- J17 p3 <- PB6, que es el TX del micro
```

Y se abren **ahí y en un solo sitio** —`haciaSTM32.begin(ENLACE_BAUDIO, ENLACE_FORMATO,
ENLACE_PIN_RX, ENLACE_PIN_TX)` en `ESP32_Expansion/src/enlace_stm32.cpp`, que es **el único fichero
del proyecto que nombra `Serial2`**, con un pack que lo vigila—. **`GPIO16`/`GPIO17` son la `UART2`
por defecto del ESP32 clásico y el firmware las usa tal cual.** La columna del STM32 ya estaba
**MEDIDA EN EL FUENTE** (§2.1): **las dos columnas de esta tabla están hoy medidas en código, y lo
que sigue sin medirse es el cobre — nadie la ha cableado todavía.**

> ⚠️ **Duda abierta que este manual NO cierra y que no es de aquí:** la etiqueta de red del **pin 3**
> de `J17` está en disputa —el esquemático la llama `RS(A0)` y el firmware `LCD_PSB`—, y los dos
> nombres no pueden ser ciertos a la vez (doc 17 §1.4, `MAPEO_TARJETA_KICAD.md` §6.bis). **No cambia
> nada del cableado de arriba**, pero se cierra siguiendo el hilo del pin 3 hasta la pata rotulada, no
> leyendo más código. **Dueño: responsable.**

#### 2.3.bis 🔌 La alimentación del ESP32 — **no cuelga de `J17`, y esto no es un detalle de montaje**

> ## 🔴 EL ESP32 LLEVA FUENTE PROPIA DESDE LOS 12 V. NO SE ALIMENTA DEL 3,3 V DE `J17` p6/p8.

**El motivo no es la corriente: es de quién es esa corriente.** Ese riel de 3,3 V es **el mismo que
alimenta al STM32 que gobierna el semáforo**, y un accesorio de diagnóstico **no puede tumbar al que
manda**.

Un ESP32 con radio activa da **picos de ~500 mA**, y el camino `12 V → LM7805 → LM1117-3.3` de la
tarjeta no los da:

* **El `LM7805` se quema:** a 500 mA disipa $(12-5)\times 0{,}5 = 3{,}5\ \text{W}$, que sin disipador
  no se evacúan.
* **Y antes de quemarse se lleva por delante al micro:** si el riel de 3,3 V se hunde, **se reinicia
  el STM32 que está gobernando el cruce**. El síntoma en campo **no se parece a un fallo de
  telemetría**: se parece a un cruce que se reinicia solo, y ahí ya no se está diagnosticando un
  módulo de diagnóstico.

| | `HC-05` / `JDY-30` (~40 mA) | **ESP32 (~500 mA de pico)** |
|---|---|---|
| ¿puede colgarse de `J17` p6/p8? | ✅ sí — por eso el diagrama viejo lo dibujaba así | 🔴 **NO. Nunca.** |
| alimentación | del riel de la tarjeta | **fuente propia DC-DC 12 V → 5 V, 1 A** |
| masa | la del conector | **masa común con la tarjeta, obligatoria** |

> 🛑 **PENDIENTE Y BLOQUEANTE DE MONTAJE: esa fuente NO SE HA PEDIDO.** Es la línea **`A5`** de
> `05_Funcional/historico/15_Lista_de_Compras_Hardware.md:90`, marcada **🔴 NO cubierta** — *«sin ella el `ESP32`
> reinicia el STM32 del semáforo»*. **Sin `A5` no se monta el ESP32**, ni «provisionalmente desde el
> 3,3 V para probar»: esa prueba provisional se hace sobre el equipo que controla el tráfico.
> **Dueño: responsable** (`ESTADO.md:251`, línea `A3`).

#### ~~Diagrama anterior (`HC-05` / `JDY-30`)~~ — conservado, NO es el montaje vigente

**No se borra**, porque las revisiones anteriores de este manual lo mandaban y **puede haber equipos
montados así**. Un `HC-05` cableado a `J17` con este dibujo **funcionaría eléctricamente** —el pinout
era y es correcto—; lo que ya no es cierto es que sea el módulo que se instala, porque **esos módulos
nunca llegaron y ya no se piden** (`15_…:85`).

```text
   ##########  MONTAJE ANTERIOR -- YA NO ES EL MODULO QUE SE INSTALA  ##########

   MODULO BLUETOOTH (HC-05 / JDY-30)        TARJETA -- CONECTOR J17
   ┌────────────────────────────┐        ┌──────────────────────────────┐
   │  [ TXD ]  transmite        ├────────┤► J17 p2 = PB7  (U1 pin 43)   │
   │  [ RXD ]  recibe           ├────────┤► J17 p3 = PB6  (U1 pin 42)   │
   │  [ VCC ]  3,3 V            ├────────┤► J17 p6 = 3,3 V   (o p8)     │
   │  [ GND ]  masa             ├────────┤► J17 p7 = GND     (o p9)     │
   └────────────────────────────┘        └──────────────────────────────┘

   El pinout de J17 NO cambia. Lo que cambia es el modulo, y con el la
   alimentacion: el ESP32 NO usa p6/p8.  (Ver 2.3.bis.)
```

> ⚠️ **Si usted ya tiene un `HC-05` montado en `J17` y funcionando, no lo desconecte por este
> manual.** Está cableado al pinout correcto y el firmware del STM32 le habla igual. Lo que este
> apartado dice es **qué se instala de aquí en adelante**, no que lo montado esté mal. **Que un cruce
> se quede sin consola por seguir un cambio de documento es peor que la inconsistencia.**

**Por qué estos dos pines y no otros:** son los que dejó libres la **pantalla LCD, que se retira**
(ver `1_Manual_Usuario.md` y `OPTIMIZACIONES.md`, ambos del 28/08). El equipo va montado en alto y
la pantalla no se lee desde el suelo, así que **la app pasa a ser la única interfaz de operación**.
En `J17`, `PB7` era el `RST` del display y `PB6` su nivel estático de modo serie: **ninguno de los
dos transportaba datos**, y por eso el puerto serie sale gratis sin tocar los tres hilos que sí
dibujan (`PB3`, `PB4`, `PB5`).

> ✅ **RESUELTO PARA EL CAMINO VIGENTE, y solo para ese: con el ESP32 esta pregunta desaparece,
> porque el módulo NO se alimenta de `J17`** (2.3.bis, fuente propia de 12 V). Lo de abajo **sigue
> valiendo íntegro para un `HC-05` ya montado o para quien vuelva a esa vía**, y por eso no se borra.

> ⚠️ **PENDIENTE DE CONFIRMAR *(solo en el camino `HC-05`)* — la tensión de `VCC` del módulo que se instale.** `J17` entrega
> **3,3 V, y solo 3,3 V**: en esta tarjeta **los 5 V son un raíl interno que no sale a ningún
> conector de señal**. Muchas placas de evaluación de `HC-05` (tipo `ZS-040`) llevan su propio
> regulador y piden **3,6–6 V** en el pin rotulado `VCC`, aunque casi todas exponen además una
> entrada de 3,3 V directa al chip. **Antes de alimentar: lea la serigrafía del módulo concreto que
> tenga en la mano.** Si esa placa exige 5 V en `VCC` y no expone entrada de 3,3 V, **no hay 5 V en
> `J17`** y hay que resolverlo por escrito antes de cablear — no improvisando un hilo desde el
> regulador, que es soldadura en placa. Esto **no está resuelto en este manual**.

> ⚡ **Alimentar desde el riel de la tarjeta vale para un `HC-05`/`JDY-30` (~40 mA) y NO vale para un
> ESP32** (picos de ~500 mA). Ver 2.3.bis y el apartado 1, «Si se va con un ESP32, el consumo no es un
> detalle de montaje». **El diagrama histórico de `HC-05` no vale para un ESP32.**

### 2.4 `PA9`/`PA10`: alternativa histórica, NO el montaje vigente

**No se borra, porque hubo una versión de este manual que la mandaba cablear** y puede haber equipos
ya montados así.

`USART1` es **un solo periférico** y el STM32F103 lo puede sacar por `PA9`/`PA10` **o** por
`PB6`/`PB7`, **nunca por los dos a la vez**. Eléctricamente `PA9`/`PA10` sigue siendo válido, pero:

| | `J17` — `PB6`/`PB7` **(vigente)** | `PA9`/`PA10` (histórico) |
|---|---|---|
| ¿sale a una bornera? | ✅ **Sí, `J17`, enchufable** | ❌ **No sale a ninguna bornera de la tarjeta** |
| cómo se conecta | se enchufa | **soldando** en las patas del `MAX3485 U2` o del propio micro |
| ¿lo escucha el firmware de hoy? | ✅ sí | ❌ **no** — `SerialBT` no está ahí |

**Un montaje en `PA9`/`PA10` exigiría cambiar el firmware de las dos puntas**, no solo el cableado.
Mientras el firmware declare `SerialBT(PB7, PB6)`, `PA9`/`PA10` es un camino muerto.

#### Si ya se cableó a `PA9`/`PA10`

1. **No es un fallo del montaje**: era lo que decía la versión anterior de este manual, hasta el
   28/08.
2. **Hay que recablear a `J17`** siguiendo §2.3. El módulo, el emparejado y el `AT+NAME` del
   apartado 1 **se conservan tal cual**: solo cambian los cuatro hilos.
3. Si el módulo se soldó a las patas de `U2` o del micro, **retire esos hilos** antes de enchufar en
   `J17`: dejarlos puestos cuelga dos cosas del mismo pin del transceptor.
4. **Síntoma que confirma que el equipo estaba en el cableado viejo:** la app empareja con el módulo
   por Bluetooth sin problema —el emparejado es cosa del módulo, no del semáforo— pero **no llega
   ni una trama `$STATUS`** y ningún comando surte efecto. El módulo está vivo; simplemente no está
   hablando con el micro.

### 2.5 ⚙️ El `PA8` y el transceptor `MAX3485` (`U2`) — RESIDUO PENDIENTE DE REVISAR

> ## ⚠️ ESTE APARTADO YA NO DESCRIBE UN DISEÑO VIGENTE. DESCRIBE UN RESTO.
>
> Todo lo que sigue existía para **liberar `PA10` al `TXD` del Bluetooth**. **Ese motivo desapareció
> el 28/08**, cuando el módulo se movió a `J17` (`PB6`/`PB7`): **el Bluetooth ya no usa `PA10`, así
> que no hay ningún conflicto que desacoplar.**
>
> **Pero el firmware no ha cambiado.** `bluetooth_setup()` sigue clavando `PA8` en `HIGH` en las dos
> puntas, con un comentario que sigue justificándolo por un `PA10` que ya nadie disputa.
>
> **Se deja escrito aquí, y no se borra, porque el efecto eléctrico sigue ocurriendo en la placa.**
> Lo que cambia es su clasificación: **era el precio aceptado de una decisión de diseño; hoy es un
> residuo sin beneficio.**

> 🔴 **Corrección de referencia: el transceptor que se pone en Hi-Z es `U2`, NO `U3`.** Varios
> documentos —y los comentarios de `pines.h` y `bluetooth.cpp`— lo tienen invertido. Medido sobre
> `Controladora_Semaforos.kicad_sch`, que es la fuente:
>
> | | `RO` | `DE`/`~RE` | `DI` | par `A`/`B` sale por | qué es |
> |---|---|---|---|---|---|
> | **`U2`** | **`PA10`** | **`PA8`** | **`PA9`** | **`J10`** | **el que comparte pines con el Bluetooth** |
> | `U3` | `PB11` | `PB12` | `PB10` | `J12` | el de la **radio** — no tiene nada que ver con `USART1` |
>
> Los dos son `MAX3485`, y ese es justo el motivo de que se confundan: **se distinguen por la red a
> la que van, no por el encapsulado**. Quien vaya a medir con punta a la placa buscando `U3` estará
> pinchando el transceptor de la radio.

#### Qué hace hoy el firmware, y qué justificación le queda

**MEDIDO EN EL FUENTE (28/08):** `bluetooth_setup()`, en las dos puntas, sigue ejecutando

```cpp
pinMode(RS485_IN_DE_RE, OUTPUT);        // RS485_IN_DE_RE = PA8
digitalWrite(RS485_IN_DE_RE, HIGH);     // el comentario dice: "libera PA10 al modulo Bluetooth"
```

**Ese comentario ya no describe la realidad.** `SerialBT` vive en `PB7`/`PB6`; **`PA10` no lo
disputa nadie**, así que liberarlo no beneficia a nada.

`PA8` no llega a un pin: **llega a dos**. En la PCB va a la vez a `~RE` (pin 2) y a `DE` (pin 3) de
`U2`, unidos en la misma red. Un solo nivel manda sobre las dos mitades del transceptor, y **no las
apaga: las intercambia**.

| `PA8` | receptor (`RO` → `PA10`) | transmisor (`DI` ← `PA9`, salida a `J10`) |
|:---:|---|---|
| `LOW` | escuchando | apagado |
| **`HIGH`** *(lo que hace hoy el firmware)* | Hi-Z — `PA10` libre, **que ya no le hace falta a nadie** | **ENCENDIDO de forma permanente** |

**Consecuencia real, y ahora sin contrapartida:** con `PA8` en alto, el transmisor de `U2` está
**permanentemente tomado sobre el par `A`/`B` de `J10`**, y ese conector **nunca puede recibir
nada**. El puerto RS-485 de `J10` no está inactivo: está tomado y sordo.

> **Antes esto era un precio pagado a cambio de algo** —liberar `PA10` para el Bluetooth—. **Hoy es
> solo el precio.** El beneficio se fue con el remapeo a `J17` y el coste se quedó.

> **Es la misma lección que `05_Funcional/historico/TROUBLESHOOTING.md` dejó escrita con el repetidor el
> 31/07/2026:** *«si un DE/RE se queda permanentemente en alto, esa línea queda bloqueada en ambos
> sentidos»*. Allí fue un fallo; aquí **dejó de ser una decisión y volvió a ser lo que era allí**.

> ⚠️ **Y un dato que hay que mirar antes de tocar nada, MEDIDO EN EL FUENTE, no en la placa:** tras
> el remapeo **ya nadie configura `PA9`**. `protocolo_setup()` retiró la apertura de `AiBus` —el
> único código que declaraba `PA9`/`PA10`— y `USART1` se fue a `PB6`/`PB7`. Es decir: el `DI` de
> `U2` **no está gobernado por ningún periférico**, mientras su transmisor sigue habilitado por
> `PA8`. **Qué nivel presenta entonces `J10` no se ha medido en la placa y este manual no lo
> afirma.** Es parte de lo que hay que revisar.

#### Qué NO se ha hecho, y es deliberado

> 🛑 **Retirar el `digitalWrite(PA8, HIGH)` es un cambio de firmware que AÚN NO SE HA HECHO.**

No se ha tocado, y no se toca desde este manual, por tres razones:

1. **Es un cambio con sentido propio** y va en su propio `N-x`, con su pack y su compuerta — no
   colado dentro del cambio de cableado.
2. **Toca las dos puntas** (`Maestro` y `Esclavo`) y afecta a una línea RS-485, no solo a un
   comentario.
3. **No se ha medido en la placa** qué hace hoy `J10` con `PA9` sin gobernar. Cambiar el nivel de un
   `DE`/`~RE` sin saber el estado de partida es exactamente lo que este repositorio no hace.

**Estado que queda anotado, para que nadie lo lea como diseño:**

| | |
|---|---|
| **Qué es** | Un **residuo**: código que sobrevivió al motivo que lo justificaba |
| **Efecto hoy** | `J10` con el transmisor de `U2` tomado y sin poder recibir. **Inofensivo mientras `J10` esté vacío** |
| **Cuándo deja de ser inofensivo** | El día que alguien cuelgue **cualquier cosa** de `J10`. Ese día se toca **este código**, no el cableado |
| **Acción pendiente** | Revisar si `PA8` debe pasar a `LOW` o dejar de tocarse. **Cambio de firmware aparte, sin fecha** |
| **Nivel de prueba** | Firmware: **MEDIDO EN EL FUENTE**. Comportamiento de `J10`: **NO VERIFICADO EN LA PLACA** |

---

## 3. Especificación de Pantallas y Módulos de la App

La App cuenta con **5 pantallas funcionales**, diseñadas con alto contraste para visibilidad bajo sol directo en carretera:

```text
 ┌─────────────────────────────────────────────────────────────────────────────┐
 │ 🚦 STATUS BAR: [● Conectado (👑 MAESTRO P1)] · [RSSI: -62 dBm] · [18:25:00] │
 ├─────────────────────────────────────────────────────────────────────────────┤
 │   [ 🗺️ ESTADO ]   [ 🎮 CONTROL ]   [ 🔔 EVENTOS ]   [ 🔬 TEST ]   [ ⚙️ RTC ] │
 └─────────────────────────────────────────────────────────────────────────────┘
```

### Pantalla 1: ESTADO (Monitoreo en Tiempo Real)
* **Semáforos Duales con Glow Dinámico:** Representación gráfica en vivo de Maestro (Sentido 1) y Esclavo (Sentido 2).
* **Anillo de Cuenta Regresiva SVG:** Círculo animado en tiempo real con indicador gigante en monospace del tiempo restante de verde/rojo (`T:<segundos>`).
* **Métricas Clave:** Calidad de enlace de radio inter-semáforo (%), tiempo de respuesta RTT (ms) y nivel de batería (V).
* **Botón de Pánico Rojo Total:** Forzado inmediato de All-Red ante emergencias viales.

### Pantalla 2: CONTROL (Comandos Protegidos por PIN)
* **Selector de Modos:** Automático, Manual, Ámbar de Seguridad y Parada de Emergencia.
* **Control de Tráfico Manual:** Botón táctil para alternar el turno vehicular desde el suelo respetando el tiempo de despeje All-Red normativo.
* **Seguridad Obligatoria:** Requiere validación del PIN de 4 dígitos (`1234`) antes de enviar comandos que alteren las luces.

### Pantalla 3: EVENTOS (Caja Negra y Registro Histórico)
* **Feed de Alarmas:** Registro cronológico de caídas de radio, transiciones de modo y fallas con timestamp del reloj RTC.
* **Compartir por WhatsApp:** Genera automáticamente el mensaje formateado para interventoría con ubicación y nodo.
* **Exportar a CSV:** Descarga el archivo de auditoría para archivo formal.

### Pantalla 4: TEST Y DIAGNÓSTICO EN TALLER
* **Test de Lámparas de 6 Segundos:** Secuencia de prueba de banco (2s Rojo ➔ 2s Amarillo ➔ 2s Verde) ejecutada a través de `semaforo_iniciarTestLeds()` bajo la barrera de seguridad de `semaforo.cpp` con semáforo fuera de servicio o Todo-Rojo controlado.

### Pantalla 5: AJUSTES & ~~ASISTENTE COURIER RTC~~ **RELOJ**

> 🛑 **CORREGIDO EL 07/09 — `D-20` cambia a QUIÉN se le pone la hora, y el Courier RTC queda
> DEROGADO.** ~~Ver la caja larga del `§1` (*«lo que la app NO puede hacer»*): **la app pone la hora en
> el POSTE 1 y sólo en el POSTE 1**; el poste 2 la recibe del Maestro por radio. **Hay UNA sola
> fuente.** 🔴 **SIN CONSTRUIR** — hoy el poste 2 se sigue poniendo en hora visitándolo, y eso es un
> estado declarado, no la arquitectura.~~ 🔵 **11/09 (`D-26`, `68dd2c5`, sin banco): la hora se pone en
> LOS DOS postes**; el poste 2 hace caso a la del Maestro con radio y a la de su ESP32 sin ella. El
> Courier sigue derogado. `14_Manual_App_Movil_IOT_VIAL.md` §5.3.bis.

* **Sincronización Directa de Hora:** Ajuste del reloj `DS3231` **del ESP32 del poste conectado** con la hora del teléfono móvil. ⛔ ~~del nodo conectado~~ — se leía como el reloj del STM32, que va sobre `Y2` y está confirmado muerto (`N-17`). ~~🛑 **07/09 (`D-20`): esta orden es DEL POSTE 1.** Dirigida al Esclavo **se rechaza** — sería una segunda fuente de hora.~~ 🔵 **11/09 (`D-26`): de los dos postes.** La atiende el puente, que la pasa a su controladora (`CMD:HORA_ESP32`); ya no cruza al STM32.
* 🔍 **Consulta de Hora (`CMD:LEER_RTC`, `D-17`):** ✅ **se sigue usando en LOS DOS POSTES.** Lee sin escribir ~~, así que `D-20` no la toca; con `D-20` construida es **la única forma de comprobar que la siembra del Maestro llegó al reloj del poste 2**~~ *(11/09: mide el salto que dará el poste 2 al perder la radio — la radio no escribe su `DS3231`)*. Ver `§4.1`.
* ~~**Modo Asistente Courier RTC (Sincronización Puente sin Radio):**~~ 🛑 **DEROGADO EL 07/09 (`D-20`). Se conserva tachado con su motivo para que no se vuelva a proponer:**
  1. ~~*Paso 1:* Capturar hora y ciclo en el Poste Maestro.~~
  2. ~~*Paso 2:* Viajar hasta el Poste Esclavo (la App cronometra el tiempo de viaje).~~
  3. ~~*Paso 3:* Inyectar en el Esclavo la hora compensada ($\Delta t < 0.1\text{ s}$), permitiendo sincronizar el Modo Degradado sin cables ni radio.~~

  **El motivo, y no es que estuviera mal hecho: la hora que ese asistente inyectaba en el poste 2
  NO era la del Maestro, era la DEL TELÉFONO** — al Maestro no se le manda nada durante todo el
  procedimiento. Eso no es una sincronización: **son dos fuentes de hora**, y es exactamente lo que
  `D-20` prohíbe. La compensación del viaje era correcta; **lo que estaba mal era de dónde salía la
  hora**. 🔴 **El botón sigue en la APK — `D-20` decide la autoridad, no ha retirado código. No se
  use.**

---

## 4. Estructura de Tramas y Protocolo Serie ASCII (Estilo NMEA con Checksum XOR)

Todas las tramas viajan a **9600 baudios (8N1)** y finalizan en `\r\n`.

### 4.1 Cálculo del Checksum NMEA (*XX)
El checksum se calcula aplicando la operación **XOR bit a bit** de todos los bytes contenidos entre el carácter `$` inicial y el asterisco `*` (ambos excluidos), formateado como dos caracteres hexadecimales en mayúsculas (`00` a `FF`).

> ### 🔵 `SET_RTC` — el único comando cuyo acuse NO lo emite el STM32 (D-15, 05/09)
>
> El reloj es el **DS3231 con pila del ESP32**, así que **contesta él**, y sus tramas van
> marcadas `NODE:PUENTE`. ~~Las dos puntas del STM32 **reconocen** la orden y la **consumen en
> silencio** —si no, caería al `else` y saldría `$ERR,CMD:DESCONOCIDO`, que sería otra vez
> dos respuestas—, y dejan un `$EVENT` con `DETALLE:SET_RTC_LO_ACUSA_EL_PUENTE`.~~ 🔵 **11/09
> (`D-26`, `68dd2c5`): la orden ya NO LLEGA al STM32** —el puente se la queda— y ese `$EVENT` ya no
> existe. Lo que la controladora recibe es `CMD:HORA_ESP32:…` con la hora releída del `DS3231`, sin PIN
> y sin respuesta; en el diario queda `HORA_ESP32_SEMBRADA` (o, en el poste 2 con radio,
> `HORA_ESP32_IGNORADA_MANDA_RADIO`) sólo en el cambio. `14_Manual_App_Movil_IOT_VIAL.md` §5.3.bis.
>
> ~~🛑 **07/09 (`D-20`) — ESTO SIGUE SIENDO CIERTO DEL STM32, Y YA NO BASTA.** *«Las dos puntas
> consumen la orden en silencio»* describe al STM32 y no cambia. Lo que `D-20` añade es **una punta
> más arriba**: **el PUENTE del poste 2 tiene que RECHAZAR el `SET_RTC` con motivo**, no atenderlo.
> Un `SET_RTC` dirigido al Esclavo **no es una sincronización, es una segunda fuente de hora**, y
> consumirlo callado no es lo mismo que negarlo — **el silencio no le dice al técnico que su orden
> no valía.**~~ *(Derogado: ya tachado en la propia fila `D-20` el 07/09 por la noche, y `D-26` manda
> ponerle la hora al poste 2 cuando cae la radio. El puente no rechaza nada: decide la controladora.)*
>
> 🔴 **SIN CONSTRUIR, y se mide en vez de suponerse (07/09, corrido antes de publicarlo):**
>
> ```bash
> $ grep -c "ESCLAVO\|Esclavo\|esclavo" 01_Firmware/ESP32_Expansion/src/despachador.cpp
> 0
> ```
>
> El puente es **el mismo firmware en los dos postes** y **no nombra al Esclavo ni una vez** en el
> fichero que decide qué hacer con un `SET_RTC`: hoy lo atiende venga por donde venga. Ver la caja
> de `§1`.
>
> **Una orden, un acuse.** Hasta el 05/09 contestaban **los dos aparatos**: el puente
> `RESULT:OK` (la puso en su DS3231) y el STM32 `DESC:NO_QUEDO_PUESTA` (en el suyo no).
> **Las dos eran ciertas**, y juntas una contradicción sobre la misma orden.

> ### 🔍 `LEER_RTC` — consultar el reloj SIN cambiarlo (A-9, 05/09)
>
> **Hasta hoy la única forma de LEER el reloj era MANDARLO:** el `$ACK` de `SET_RTC` devuelve
> `FECHA:`/`HORA:` releídas del chip. O sea que **comprobar** si el cruce estaba en hora
> obligaba a **cambiársela**, y con eso se perdía justo el dato que se buscaba: **cuánto se
> había desviado**.
>
> La app manda `CMD:LEER_RTC`, **sin PIN** —no abre paso, no para nada y no cambia nada—, y
> **esa línea NO cruza a la controladora**: el puente se la queda porque es suya. *(Medido
> sobre el `bluetooth.cpp` compilado de las dos puntas: reenviada, las dos contestan
> `$ERR,CMD:AUTH_FAILED,DESC:PIN_INVALIDO` — un rechazo en rojo acusando al operario de una
> clave que no tecleó, cada vez que pregunta la hora.)*
>
> Respuesta buena, con la hora **releída del chip en ese instante**:
> `$ACK,NODE:PUENTE,CMD:LEER_RTC,RESULT:OK,FECHA:2026-09-05,HORA:22:19:58*XX`
>
> **Y lo que contesta cuando NO sabe, que es lo que de verdad importa:** un DS3231 sin pila
> entrega una fecha **perfectamente formada y falsa**, así que **aquí no se rellena nada** —
> sale `$ERR` con **un motivo por avería**:
>
> | `DESC:` | qué pasa | qué se hace |
> |---|---|---|
> | `NUNCA_SE_PUSO_PONGA_LA_HORA` | módulo virgen | sincronizar |
> | `OSCILADOR_PARADO_CAMBIE_PILA` | el `OSF` dice que el oscilador se paró | **cambiar la pila** y volver a poner la hora |
> | `SIN_RELOJ_NO_RESPONDE` | el bus I²C no contesta | destornillador: módulo, cableado, SDA/SCL |
> | `ESCRITURA_A_MEDIAS_REPITA_SET_RTC` | una puesta en hora se cortó a mitad | repetir y comprobar el acuse |
> | `MODO_12H_PONGA_LA_HORA` | registro en 12 h: hasta **12 h de error** con el módulo sano | sincronizar |
> | `REGISTROS_INCOHERENTES` | lo que hay dentro no compone fecha | **dos causas posibles**: sincronice; si vuelve, cambie el módulo |
> | `BARRERA_INCOHERENTE` | el puente se contradice a sí mismo | **no es del reloj**: repórtelo |
> | `MOTIVO_NO_CONTEMPLADO` | firmware más nuevo que la app | no dé la hora por buena |
>
> ⚠️ **Un cruce tiene DOS relojes y ~~nada los sincroniza~~ hoy nada los sincroniza.** Por eso la app
> **compara**: guarda el error de cada poste contra el reloj del celular y los resta, así que **la
> caminata entre postes se cancela**. Con un solo poste no publica desfase: **dice cuál falta**. La
> lista vive en memoria y **no sobrevive a que Android cierre la app**.
>
> 🛑 **07/09 (`D-20`) — dónde poner el remedio de estos ocho motivos, porque NO es el mismo en los
> dos postes.** Cuatro de los ocho terminan en *«sincronizar»*, y sincronizar es **escribir la
> hora**:
>
> * **POSTE 1 (Maestro):** se sincroniza ahí mismo. Es **la fuente**, y es lo correcto.
> * **POSTE 2 (Esclavo):** ~~🛑 **no.** `D-20` decide que la app **no pone la hora en el poste 2,
>   nunca** — sería una segunda fuente. Con `D-20` construida, esos motivos se resuelven **poniendo
>   en hora el Poste 1 y dejando que lo siembre por radio**, y esta consulta pasa a servir para
>   **comprobar que llegó**. ⚠️ **SIN CONSTRUIR:** hoy se sigue sincronizando allí, visitándolo.~~
>   🔵 **11/09 (`D-26`): también ahí mismo.** Estos motivos son de **su** `DS3231`, y la radio no lo
>   escribe: sólo se arreglan sincronizando en ese poste.
> * 🔧 **Lo que no cambia en ningún poste:** *«oscilador parado»* es **la pila del `DS3231` de ese
>   poste** —**no** la `CR2032` de la controladora—, se cambia en el poste donde salga, y **no hay
>   radio que arregle una pila**.
>
> 🔵 **Y la frase que sí se conserva entera, porque `D-20` la usa como premisa: los dos ESP32 NO se
> hablan entre sí.** Por eso la comparación la tiene que hacer la app visitando los dos postes, y por
> eso la hora sólo puede viajar **por la radio entre los STM32**.

### 4.2 Telemetría Periódica ($STATUS) — Emitida cada 2 segundos *(cadencia bajada a **2000 ms** el 04/09, decision del responsable, en las DOS puntas. Un tecnico que cronometre con «1 segundo» declara caido un enlace sano.)*

> ✅ **MEDIDO el 07/09, y se cita el SÍMBOLO porque las dos citas por línea que había aquí ya no
> señalaban al sitio.** Decían `Maestro/src/bluetooth.cpp:851` y `Esclavo/src/bluetooth.cpp:768`; la
> segunda apunta hoy a `enviarTramaConCrc("$ACK,CMD:SET_MODO:DEGRADADO,RESULT:OK")`, que es el acuse
> de `D-18` y no tiene nada que ver con la cadencia. **La cadencia se encuentra así, y no caduca:**
>
> ```
> grep -n "STATUS_PERIODO_MS\|2000" 01_Firmware/Maestro/src/bluetooth.cpp
> ```
>
> **Y la plantilla literal, que es lo que un parser tiene que casar, sale del `snprintf` de cada
> punta** — `grep -n '"\$STATUS' 01_Firmware/*/src/bluetooth.cpp`:
>
> ```
> $STATUS,NODE:MAESTRO,SERIE:%s,MODO:%s,ESTADO:%s,T:%s,RF:%s,RTT:%s,BAT:--,HORA:%s,ESC:%s,PLUMA:%s,CAM:%s
> $STATUS,NODE:ESCLAVO,SERIE:%s,MODO:%s,ESTADO:%s,T:--,RF:--,RTT:--,BAT:--,HORA:%s,PLUMA:%s,CAM:%s
> ```
>
> 🔴 **En el ESCLAVO, `T:`, `RF:` y `RTT:` son `--` LITERALES dentro de la plantilla** —no son
> huecos que a veces se rellenen—, y **no hay ningún campo de antigüedad de sincronización en
> ninguna de las dos**. Ver el punto 5 de la fe de erratas de la cabecera: ese dato existe dentro
> del micro y hoy no sale por ningún sitio.
$$\text{Formato: }\$STATUS,NODE:\langle N\rangle,SERIE:\langle S\rangle,MODO:\langle M\rangle,ESTADO:\langle E\rangle,T:\langle S\rangle,RF:\langle R\rangle\%,RTT:\langle T\rangle ms,BAT:\langle V\rangle,HORA:\langle H\rangle,ESC:\langle C\rangle,PLUMA:\langle P\rangle,CAM:\langle K\rangle*\langle CRC\rangle\backslash r\backslash n$$

**Ejemplo Maestro en Modo Automático:**
```text
$STATUS,NODE:MAESTRO,SERIE:A3F19C,MODO:AUTO,ESTADO:V1_R2,T:24,RF:98%,RTT:82ms,BAT:--,HORA:18:25:00,ESC:ROJO,PLUMA:ARRIBA,CAM:OK*07\r\n
```

> 🔴 **CORREGIDO el 07/09: este ejemplo publicaba `BAT:12.6`, y esa trama NO PUEDE EXISTIR.**
> `BAT:--` está **fijo dentro del `snprintf`** de las dos puntas: no es un valor que a veces falte,
> es texto de la plantilla. **No hay un solo `analogRead()` en `Maestro/` ni en `Esclavo/`**, así que
> mientras no haya divisor de tensión y firmware que lo lea, ese campo no puede traer una cifra.
>
> **Y la ironía, que es la razón de corregirlo y no dejarlo pasar:** cuatro párrafos más abajo este
> mismo apartado usa *«el `BAT:12.6` literal (N-108)»* como **el ejemplo canónico del error de
> publicar un dato inventado** — y lo llevaba en su propio ejemplo. Un técnico que compare la trama
> real contra este renglón habría visto un campo distinto y habría ido a buscar una avería de
> parser.
>
> ✅ **Y el checksum se recalculó, no se copió: `*1C` → `*07`.** Lo acusó el pack
> `documentos_03_trama_status`, que recalcula el `*XX` de cada ejemplo publicado — **cambiar el
> cuerpo de una trama y dejar el checksum viejo produce un ejemplo que ninguna app aceptaría**. Se
> comprobó por separado antes de escribir el número, con el mismo XOR que hace `calcularChecksum()`
> en el firmware: sobre el cuerpo **anterior** da `1C` (o sea que el ejemplo viejo estaba bien
> calculado) y sobre el nuevo da `07`. **El pack tenía razón y el manual estaba mal**, no al revés.
>
> 🔴 **Y un dato que este apartado no dice y cambia cómo se lee todo lo demás: EL CHECKSUM SÓLO
> PROTEGE LA BAJADA.** `calcularChecksum()` es `static` en cada punta y su único llamador es el
> emisor de tramas; **el despachador NO lee el `*XX` de lo que le llega**. O sea: el `*XX` de las
> tramas del equipo hacia la app es real y se comprueba, pero **una orden de la app hacia el equipo
> con un bit cambiado se obedece igual**. Quien escriba un parser no debe leer esta sección como si
> el `*XX` fuera una barrera en las dos direcciones: **en la subida no hay ninguna.**

> 🔵 **`CAM` (D-13 fase 1) — el estado de las cámaras de `J16`, y lo emiten LAS DOS puntas.**
> Cuatro valores, y **es el PEOR de las dos cámaras de esa punta**, no una por campo:
>
> | valor | significa |
> |---|---|
> | `OK` | las dos han dado flancos y ninguna está pegada |
> | `?` | **todavía no se sabe** — al encender, hasta que una dé su primer flanco |
> | `CIEGA` | una lleva **24 h de paso abierto** sin ver un vehículo |
> | `PEGADA` | una lleva **20 min** con el contacto cerrado sin abrirse |
>
> **`?` pesa más que `OK` a propósito**, y ése es todo el diseño del campo: si una cámara se sabe
> buena y de la otra no se sabe nada, publicar `OK` **taparía** la desconocida. La gravedad va en
> el orden del `enum`, así que el peor se resuelve con un mayor-que y no con una cadena de `if`
> que alguien tendría que mantener ordenada.
>
> 🛑 **Ninguno de esos cuatro valores mueve el cruce.** El vigilante de cámaras **avisa y no
> manda**: ver **§4.3.bis**, donde está lo que sí hay que saber antes de mandar a nadie a un poste
> por esto.
>
> ⚠️ **Y un parser tiene que leerlo con valor por defecto**, igual que `ESC`: este campo **no
> existía en `4b90f98`** y una app anterior no lo trae.

> 🔵 **`ESC` (N-149) — y este campo SÓLO SALE DEL MAESTRO.** Es el único campo asimétrico
> de la trama, y la asimetría es deliberada. Toma cuatro valores: `ROJO`, `VERDE`, `AMBAR`
> y `?`.
>
> **Qué significa exactamente, porque no es «el color de la lámpara del Poste 2».** Es el
> color que el **Esclavo confirmó** por radio: sale de `quienVerde`, que el coordinador del
> Maestro sólo escribe al recibir el acuse (`CMD_ACK_GREEN`), nunca al mandar la orden.
> Publicar la orden en vez del acuse pintaría un semáforo que quizá no existe, que es el
> error que este proyecto ya pagó con el `BAT:12.6` literal (N-108) y con el equipo
> declarándose en hora con el reloj parado en ceros (N-144).
>
> **`?` no es un hueco: es la respuesta correcta.** Con el enlace caído el Maestro no sabe
> de qué color está la otra punta, y decirlo vale más que un color plausible. La app tiene
> que escribirlo como *sin dato*, nunca pintar el último valor como si fuera de ahora.
>
> **Por qué el Esclavo no lo emite.** No tiene de dónde sacarlo: no le pregunta el color al
> Maestro y no existe función que lo devuelva. Un campo que sólo pudiera valer `?` sería un
> dato que nunca informa. Y encaja con la decisión de las dos pantallas: **conectado al
> Maestro la app es la consola de operación y enseña el cruce entero; conectado al Esclavo
> es sólo diagnóstico.**
>
> 🔵 **`PLUMA` (N-153) — la posición de la talanquera de LA PUNTA QUE EMITE**: `ARRIBA` o
> `ABAJO`. **Lo emiten las DOS**, porque las dos placas llevan el motor en `PB2` — no es
> asimétrico como `ESC`. Sale del valor que se escribió en el pin, no de recalcular la
> fórmula.
>
> ⚠️ **Con la decisión D-13 habrá ratos de LUZ ROJA CON LA PLUMA ARRIBA** —la cámara ve a
> alguien debajo y la barrera no baja—. **Eso no es una avería**, y la app lo dice con esas
> palabras.

> **Quien escriba un parser contra esta trama tiene que leer `ESC` con valor por defecto**,
> porque en el poste del Esclavo no llega. El pack `documentos_03_trama_status` lo exige en
> cada corrida.

> **`SERIE` (N-62).** El firmware lo emite desde `f7d613f` y este manual no lo documentaba:
> la especificación describía una trama que ya no salía del micro. Son **24 bits en
> hexadecimal** derivados del UID de silicio de 96 bits del STM32 (`identidad.cpp`), iguales
> en las dos puntas y **no reescribibles**: identifican la **placa**, no el cruce donde esté
> montada hoy. El pack `documentos_03_trama_status` compara este apartado contra el `.cpp`
> en cada corrida del banco, así que la próxima vez que la trama cambie y el manual no, la
> compuerta lo dirá.
>
> ⚠️ **El separador de clave/valor es el PRIMER `:` de cada campo.** `HORA` lleva dos más
> dentro del valor (`18:25:00`); un parser que parta por todos los `:` se queda con `18`. Le
> pasaba a la app hasta N-62.

### 4.3 Trama de Alarma Inmediata ($ALARM) — Emitida ante incidentes
```text
$ALARM,NODE:MAESTRO,EVENTO:FALLO_RF,CAUSA:SILENCIO_25000ms,RF:--,RTT:--,SINRESP:5,ACCION:CAMBIO_A_AMBAR,HORA:17:54:58*18\r\n
```

> 🔴 **ESTE EJEMPLO LLEVABA TRES CAMPOS DE MENOS, y el checksum del manual estaba BIEN — que
> es exactamente lo que lo hacía difícil de ver.** Aquí ponía
> ~~`$ALARM,NODE:MAESTRO,EVENTO:FALLO_RF,CAUSA:SILENCIO_25000ms,ACCION:CAMBIO_A_AMBAR,HORA:17:54:58*3D`~~,
> sin `RF:`, `RTT:` ni `SINRESP:`. El firmware los emite **desde N-108**: los compone
> `bluetooth_reportarAlarma()`, entre la `CAUSA` y la `ACCION`, y salen en **todas** las
> alarmas, no sólo en las de radio.
>
> ```
> grep -n "ALARM,NODE:" Maestro/src/bluetooth.cpp Esclavo/src/bluetooth.cpp
> grep -n "SINRESP:" Maestro/src/bluetooth.cpp
> ```
>
> **Y el pack no podía cazarlo, por una razón que vale la pena escribir:** lo que
> `documentos_03_trama_status` comprueba de estos ejemplos es que **cada uno cuadre con su
> propio XOR**, no que describan la trama que sale del micro. Un ejemplo obsoleto con su
> checksum recalculado es **internamente coherente y falso**, y un instrumento verde encima.
> Quien escribiera un parser contra este apartado se encontraría tres campos que no espera.
>
> **Los dos checksums que estaban mal antes** (`*4F` y `*3B` frente a los `*42` y `*43`
> reales) llevaban desde el 26/08 en el manual y en el `.docx`. Un ejemplo con checksum
> inválido en el mismo apartado que explica cómo calcularlo es una trampa para quien escriba
> un parser: descarta la trama buena y busca el fallo donde no está. Ahora los recalcula el
> pack `documentos_03_trama_status` sobre **todos** los ejemplos de este manual.

#### 🆕 4.3.bis Las alarmas de CÁMARA (D-13 fase 1, `4b90f98`) — **avisan y no tocan el cruce**

El firmware vigila las dos entradas de cámara de `J16` —`CAM_C` = **p10**, `CAM_D` = **p12**— y
emite dos alarmas nuevas y dos eventos de cierre. **Las emiten las DOS puntas**, con el mismo
código: `NODE:` es lo único que cambia.

```text
$ALARM,NODE:MAESTRO,EVENTO:CAM_PEGADA,CAUSA:CAM_C_CONTACTO_FIJO,RF:98%,RTT:82ms,SINRESP:0,ACCION:NINGUNA,HORA:18:25:00*57
$ALARM,NODE:MAESTRO,EVENTO:CAM_CIEGA,CAUSA:CAM_D_SIN_FLANCO,RF:98%,RTT:82ms,SINRESP:0,ACCION:NINGUNA,HORA:18:25:00*57
$EVENT,NODE:MAESTRO,ORIGEN:CAMARA,DETALLE:CAM_C_RECUPERADA,HORA:18:25:00*5F
$EVENT,NODE:MAESTRO,ORIGEN:CAMARA_PLUMA,DETALLE:VETO_HABRIA_ACTUADO_N:3,HORA:18:25:00*03
```

| campo | valores | qué significa |
|---|---|---|
| `EVENTO` | `CAM_PEGADA` | el contacto lleva **20 min** cerrado **sin abrirse ni una vez** |
| `EVENTO` | `CAM_CIEGA` | **24 h de PASO ABIERTO** sin un solo flanco |
| `CAUSA` | `CAM_C_CONTACTO_FIJO` · `CAM_D_CONTACTO_FIJO` | qué entrada, y qué se observó |
| `CAUSA` | `CAM_C_SIN_FLANCO` · `CAM_D_SIN_FLANCO` | idem |
| `ACCION` | **`NINGUNA`, siempre** | ver abajo — **no es un hueco** |
| `DETALLE` | `CAM_C_RECUPERADA` · `CAM_D_RECUPERADA` | la alarma **se cierra sola**; no hay que rearmar nada |
| `DETALLE` | `VETO_HABRIA_ACTUADO_N:<n>` | contador de la fase 2. `<n>` es un `uint16_t` que **satura en 65535**, no da la vuelta |

> 🛑 **`ACCION:NINGUNA` NO ES RELLENO: es el dato que decide si esto para un cruce o no.** Ese
> campo significa *«medida de seguridad vial ejecutada»*, y la fase 1 **no ejecuta ninguna**: no
> veta, no baja la pluma, no toca una luz, no cambia un tiempo. **El cruce funciona exactamente
> igual con las dos alarmas puestas.** Son **avisos de mantenimiento** —«que alguien vaya a mirar
> esa cámara»—, **no fallos de seguridad**.
>
> **Quien escriba la app, el tablero o el aviso al operario tiene que pintarlas así.** Una alarma
> de cámara que se muestre con la misma cara que un `FALLO_RF` hace que alguien pare un cruce por
> una cámara sucia. Escribir en ese campo cualquier otra cosa sería el `$ACK` que no mira lo que
> devolvió la llamada (§6 de `CLAUDE.md`) trasladado a la caja negra.

> 🛑 **Lo que `CAM_PEGADA` NO SABE DISTINGUIR, y por eso la causa dice `CONTACTO_FIJO` y no
> «avería»:** un **relé trabado** y un **vehículo parado veinte minutos debajo de la pluma** dan
> **el mismo nivel**, y este firmware no tiene con qué separarlos. Las dos cosas piden que alguien
> vaya a mirar, así que avisar es correcto en los dos casos; **llamarlo avería no lo sería**.

> ⏱️ **`CAM_CIEGA` cuenta 24 h de PASO ABIERTO, no 24 h de reloj.** El cronómetro sólo corre con la
> **pluma arriba**: con el cruce en menú, en rojo total o con el turno en la otra punta nadie puede
> cruzar el barrido, y una cámara callada está diciendo la verdad. Con el ciclo mínimo cada poste
> tiene el paso abierto **~la mitad del tiempo** —del orden de **2 dias de reloj**—, así que **no
> puede dispararse dentro de una sola noche sin tráfico**, que es el único silencio largo legítimo.

> 🔴 **RESIDUAL, Y NO SE LEE COMO APROBADO: `CAM_CIEGA` a su valor de producción NO es ejecutable
> en una sesión de banco.** Está comprobado en su **forma** —la trama se compone y sale bien— **y
> no en su tiempo**. Ejercerlo exigiría cargar una compilación con el umbral reducido, **y esa
> compilación no es la que va a campo**. Lo que sí se ejerce en banco es la puerta que impide que
> salte sola: que el cronómetro **no corre con el paso cerrado** (paso **21.ter** de la guía).

> ⚠️ **`CAM_C` y `CAM_D` no son «la cámara 1 y la 2».** Esos números son de **otras** dos entradas
> —las de `PB0`, una por punta—. Las de `J16` **no tienen número: son `C` y `D`**, y confundirlos
> manda a un técnico a revisar el borne equivocado.

> ⚠️ **Estas cuatro tramas son TODO lo que el vigilante publica por su cuenta.** El firmware
> además calcula un estado por punta —`OK` · `?` · `CIEGA` · `PEGADA`, y publica **el peor de las
> dos cámaras**, con `?` pesando más que `OK` para que una cámara desconocida no quede tapada por
> la otra—. **Dónde viaja ese estado lo dice §4.2, que es la especificación del `$STATUS`, y no se
> copia aquí**: una segunda copia de un formato se queda describiendo una trama que ya cambió, que
> es exactamente lo que le pasó al ejemplo de arriba.
>
> ⚠️ **Ese estado viaja en el `$STATUS`, en el campo `CAM:` — está en §4.2 con sus cuatro valores.**
> **En `4b90f98`, el commit de la fase 1, ese campo NO salía**: el getter estaba declarado sin
> llamador a propósito y con el motivo medido en `costura_10_funciones_muertas`, porque el `$STATUS`
> no cabía en su peor caso. Se conectó **después**, con el presupuesto de bytes rehecho. **Un parser
> tiene que leerlo con valor por defecto**, porque una app anterior a ese cambio no lo trae.
>
> **Y quien lo verifique no tiene que creerse este párrafo:** `documentos_03_trama_status` compara
> **campo a campo** la plantilla del `.cpp` contra §4.2 en cada corrida del banco, y
> `camara_03_vigilante` comprueba las dos mitades del vigilante. Si un día la trama cambia y el
> manual no, la compuerta lo dice.

### 4.4 Comandos desde la App hacia la Controladora (Protegidos por PIN)
```text
 ┌─────────────────────────────────────────────────────────────────────────────┐
 │ COMANDOS DE CONTROL CON VALIDACIÓN DE PIN (USART1 a 9600 bps)               │
 ├─────────────────────────────────────────────────────────────────────────────┤
 │ • CMD:PIN:1234:SET_MODO:AUTO\r\n            ➔ Pone el cruce en Automático.  │
 │ • CMD:PIN:1234:SET_MODO:MANUAL\r\n          ➔ Pone el cruce en Modo Manual. │
 │ • CMD:PIN:1234:SET_MODO:AMBAR\r\n           ➔ Pone el cruce en Ámbar Seguro.│
 │ • CMD:PIN:1234:FORZAR_ROJO\r\n              ➔ ROJO TOTAL DE EMERGENCIA.     │
 │ • CMD:PIN:1234:MANUAL:CAMBIAR_TURNO\r\n     ➔ Concede turno opuesto.        │
 │ • CMD:PIN:1234:TEST_LEDS\r\n                ➔ Inicia test de lámparas de 6s.│
 │ • CMD:PIN:1234:SET_RTC:YYYY-MM-DD,HH:MM:SS\r\n ➔ Ajusta reloj RTC.          │
 │ • CMD:PIN:1234:SOLICITAR_PASO\r\n     ➜ Solo ESCLAVO: pide al Maestro. │
 │ • CMD:FORZAR_ROJO\r\n                    ➜ SIN PIN. Ver nota abajo.   │
 └─────────────────────────────────────────────────────────────────────────────┘
```

### 🛑 El ROJO DE EMERGENCIA no pide PIN, y es deliberado

`mando.cpp` lo dejó escrito hace meses para el mando de relés: **«asimetría deliberada: lo seguro,
fácil; lo peligroso, difícil»**. Detener el tráfico es la acción **segura** —el equipo cae a
todo-rojo—, así que ponerle una clave delante solo retrasa a quien está viendo el incidente.

Se aceptan **las dos formas**: `CMD:FORZAR_ROJO` y `CMD:PIN:1234:FORZAR_ROJO` hacen lo mismo. El PIN
sigue guardando lo que **abre** paso o mueve luces.

> ⚠️ **Este apartado habla del MAESTRO. En el Esclavo el comando cambió de nombre (N-83) y el
> razonamiento de arriba no le vale.**
>
> ~~«Detener el tráfico es la acción segura, así que no pide PIN»~~ — en el Esclavo eso **no
> describe lo que ocurre**: `semaforo_iniciarFallo()` deja el equipo en `S_FALLO`, que es **ámbar
> intermitente a 500 ms con la talanquera ARRIBA**, no rojo. Ese camino **sí abre paso**. La
> exención de PIN sigue siendo correcta por otro motivo, escrito en
> `Esclavo/src/bluetooth.cpp:110-129`: un ámbar intermitente **no le da prioridad a nadie** —pone a
> los dos sentidos a pasar con precaución—, y una caída segura que exija recordar una clave delante
> de un accidente no es una caída segura.
>
> El literal `FORZAR_ROJO` **sigue existiendo en el Esclavo, rechazándose y enseñando el nombre
> bueno** (`:157` y `:176`). No se convirtió en alias mudo a propósito: quien lo manda tiene una app
> o un manual anteriores al cambio, y lo que necesita no es enterarse de que el comando no existe,
> sino de cómo se llama ahora. **El nombre vigente es `AMBAR_EMERGENCIA`, y qué contesta en cada
> estado es §4.5.**

### 📋 Qué acepta cada punta, y no es lo mismo

| Comando | Maestro | Esclavo | Por qué |
|---|---|---|---|
| `SET_MODO:AUTO` · `MANUAL` · `AMBAR` | ✅ con PIN | ❌ | El Maestro es el único que arbitra el ciclo |
| `MANUAL:CAMBIAR_TURNO` | ✅ con PIN | ❌ | idem |
| **`SOLICITAR_PASO`** | — | ✅ **con PIN** | **Pide**, no ordena: manda `CMD_DEMANDA` por radio y decide el Maestro |
| ~~`FORZAR_ROJO`~~ ~~✅ sin PIN en las dos~~ | ✅ **sin PIN** | 🛑 **RECHAZADO con motivo** | 🔴 **Esta fila era falsa desde N-83.** En el Esclavo `FORZAR_ROJO` **ya no se atiende**: contesta `$ERR,CMD:FORZAR_ROJO,DESC:RENOMBRADO_USE_AMBAR_EMERGENCIA` (**MEDIDO POR LECTURA**, `Esclavo/src/bluetooth.cpp:157` sin PIN y `:176` con PIN). En el Maestro sí hace rojo de verdad (`Maestro/src/bluetooth.cpp:253`). Llamarlas igual era el defecto |
| **`AMBAR_EMERGENCIA`** | ❌ *(el Maestro usa `SET_MODO:AMBAR`, con PIN)* | ✅ **sin PIN y con PIN** | Ámbar intermitente con la pluma arriba. **No es «lo seguro» a secas: SÍ abre paso a los dos sentidos** — la exención de PIN se razona en `Esclavo/src/bluetooth.cpp:110-129`, no en «esto para el tráfico». **Su tabla de respuestas es §4.5** |
| `SET_RTC:…` | ✅ **con PIN** *(11/09: el PIN ya no lo comprueba nadie, `D-26` (1))* | ~~🛑 **RECHAZADO con motivo** (`D-20`, 07/09)~~ ✅ **igual que en el Maestro** (`D-26`, 11/09) | ~~🔴 **Esta fila decía `✅ con PIN` en las DOS puntas, y era la peor del manual.** Poner la hora **no es simétrico**: la del poste 2 **sale del Poste 1 por radio**, así que un `SET_RTC` dirigido al Esclavo **no es una sincronización, es una SEGUNDA FUENTE de hora**. ⚠️ … **el que tiene que rechazarla es el PUENTE del poste 2** — y eso **está SIN CONSTRUIR**~~ 🔵 **11/09 (`D-26`, `68dd2c5`): la fila vieja volvía a tener razón.** La atiende el puente de cada poste y **no cruza** al STM32. Lo asimétrico es qué hace cada controladora con la hora que su ESP32 le pasa: el Maestro la toma siempre; **el Esclavo, sólo sin radio** (`§1`, `14_…` §5.3.bis) |
| `TEST_LEDS` | ✅ con PIN | 🛑 **RECHAZADO** | Ver abajo |
| 🔍 `LEER_RTC` | — **no llega al STM32** | — **no llega al STM32** | ✅ **`D-20` NO lo toca, y va escrito aquí para que nadie lo retire junto con el `SET_RTC`:** consultar el reloj **no escribe nada**, así que **se sigue mandando A LOS DOS POSTES**. ⚠️ **Pero no es una fila como las otras: esta orden no la atiende ninguna de las dos puntas del STM32** — **el puente se la queda porque el reloj es suyo**, y contesta con `NODE:PUENTE`, **sin PIN**. Reenviada al STM32, las dos contestarían `$ERR,CMD:AUTH_FAILED,DESC:PIN_INVALIDO`. `D-17`, y su tabla de motivos está en `§4.1` |

### 🛑 Por qué el Esclavo rechaza `TEST_LEDS`

El test enciende 6 s de secuencia —rojo, ámbar y **verde**— sin mirar el estado del ciclo. Lanzado
sobre un Esclavo en servicio, ese verde sale **mientras el Maestro está dando paso al otro sentido**:
dos vehículos entrando de frente al tramo.

Y lo que costó ver: **conectarse al Esclavo *correcto* era igual de peligroso.** El fallo no es
equivocarse de poste —eso lo arreglaría una matrícula—, es que esa punta acepte mover luces. Por eso
la guarda no vive en la app: una app se actualiza, se instala otra, se usa una vieja. Vive en el
firmware, y la vigila el pack `esclavo_06_no_abre_paso`.

El Esclavo contesta `$ERR,CMD:TEST_LEDS,DESC:NO_EN_SERVICIO_USE_EL_MAESTRO` — un motivo legible, no
un silencio que el técnico leería como equipo colgado. **El test de lámparas se hace desde el
Maestro.**

> **Volverá al Esclavo** cuando exista un estado `FUERA DE SERVICIO` que el propio equipo conozca, no
> una promesa del manual.

### ✋ `SOLICITAR_PASO`: el funcional trabaja desde cualquier extremo

El PMT coloca a un funcional en el extremo que haga falta, y ese funcional **no tiene por qué saber
cuál de los dos postes es el Maestro**:

```text
   ORDEN     "ponte en verde"    -> el Esclavo la ejecutaria          NO
   PETICION  "hay demanda aqui"  -> viaja al Maestro por radio,
                                    el Maestro decide, aplica el
                                    todo-rojo y ordena                SI
```

Es **la misma demanda que manda la cámara**: un botón del funcional y un coche detectado significan
lo mismo. Con dos funcionales, uno en cada extremo, el Maestro **serializa** — ninguno concede nada,
los dos piden. Que pulsen a la vez tiene que ser aburrido, y así lo es.

Si la petición cae en la ventana de silencio de 3 s, el equipo contesta
`$ERR,CMD:SOLICITAR_PASO,DESC:REPITA_EN_UNOS_SEGUNDOS`. **No se finge un envío que no ocurrió:** si el
operario no lo sabe, vuelve a pulsar creyendo que no le hacen caso.

---

### 4.5 🟠 `AMBAR_EMERGENCIA` en el Esclavo — la tabla de respuestas

> # 🔴 07/09 — LEA ESTO ANTES DE USAR NINGUNA CITA DE ESTA SECCIÓN
>
> **Las direcciones `fichero.cpp:N` de este apartado ya no señalan al sitio.** Medido hoy sobre este
> fichero: de **20 citas de firmware juzgables, 19 no encuentran el símbolo que anuncian** ni con un
> margen de ±3 líneas, y la mayoría son de aquí. **Ninguna de ellas es una prueba de nada.** Lo que
> se lee es el símbolo:
>
> ```
> grep -rn "degradado_salir\|degradado_entrar\|DEG_RENDIDO\|DEG_SALIENDO" 01_Firmware/Esclavo/
> ```
>
> **Si una cita de aquí y ese `grep` no coinciden, manda el `grep`.**
>
> ### 🔴 Y el cambio de fondo que esta sección todavía no recoge: `D-18`
>
> El Esclavo **sí** entra hoy en Modo Degradado por app —`SET_MODO:DEGRADADO` existe en su
> `bluetooth.cpp`, fila `D-18` de `DECISIONES.md`, y por ahí desapareció el hueco de `A-11`—.
> **Lo que NO existe es el camino de vuelta:** no hay ningún comando de radio por el que el Esclavo
> anuncie que entró, y el getter de estado del Maestro **sólo sabe devolver color**.
>
> **Consecuencia operativa, y es la que hay que tener delante al leer la tabla de abajo: el poste 1
> no puede enterarse de que el poste 2 está en Degradado.** Cualquier frase de esta sección —o del
> Manual 8, o del 18— que describa al Maestro **reaccionando** a ese estado, o a la app
> **enseñándolo desde el Maestro**, describe algo que no tiene canal por el que ocurrir.
>
> 🛑 **ESTO ES ESPECIFICACIÓN, NO ES LO QUE EL FIRMWARE HACE HOY.** Escrito el **31/08/2026**.
> Ninguna línea de esta sección ha pasado banco, y el firmware de hoy contesta
> `RESULT:OK` **en los cinco casos**. Mientras esta tabla no esté implementada y vista fallar, el
> `$ACK` que llega del Esclavo **no distingue nada** y no debe leerse como si distinguiera.
>
> **La tabla vive AQUÍ y en ningún otro sitio.** El Manual 8 (§5.bis) y el Manual 18 (§3.6) la
> **referencian**; copiarla crearía dos versiones que alguien tendría que sincronizar a mano, que es
> exactamente el defecto que este proyecto lleva un mes cerrando.

#### 4.5.0 La decisión que ya está tomada, y de quién es

**Decisión del responsable, 31/08/2026:**

1. `CMD:AMBAR_EMERGENCIA` en el Esclavo **sale del Modo Degradado de forma ORDENADA** —por el
   todo-rojo de despedida—, **igual que hace `B·B·B` desde el mando**, en vez de limitarse a
   `semaforo_iniciarFallo()`.
2. **La jerarquía: la app es la superficie de mando; el `B·B·B` del mando es la vía de último
   recurso** —cuando no hay teléfono, no hay cobertura o el ESP32 se colgó—.

**Lo que esa decisión NO dijo, y es lo que especifica esta sección: qué contesta el equipo en cada
caso.** Y hace falta decirlo porque el arreglo directo —copiar el molde de `mando.cpp:129-141` a las
dos puertas— **lo rechazó el banco, con razón**. El pack `app_03_sin_ok_mudo` dijo:

```text
FALLA Esclavo / CMD:AMBAR_EMERGENCIA: llama a degradado_salir() y TIRA lo que
      devuelve -o no comprueba su guarda- y aun asi manda $ACK. El tecnico recibe
      una confirmacion de algo que puede no haber ocurrido, se va del poste, y el
      equipo se queda como estaba sin que nada lo diga
```

Es la barrera de `CLAUDE.md` §6 literal, y es **el mismo defecto que N-80 cerró en `SET_RTC`**
apareciendo en la rama de al lado. Por eso la respuesta tiene que **distinguir los casos**, y cuántos
son y cómo se llaman es especificación.
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

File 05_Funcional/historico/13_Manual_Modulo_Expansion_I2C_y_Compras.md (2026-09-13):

# 🔌 MANUAL 13: ESPECIFICACIÓN DE HARDWARE, MODIFICACIÓN DE PCB Y COMPRAS PARA EXPANSIÓN I²C Y POTENCIA (V9.0)

**Sistema:** Controladora de Semáforos Móviles de 3 Estados (Maestro y Esclavo)  
**Propósito:** Guía de taller para modificación de placa madre KiCad, ensamble del bus I²C, compras locales y etapa de potencia  
**Estado:** 🛑 **DISEÑO DE HARDWARE / PRE-IMPLEMENTACIÓN (V9.0). NO ESTÁ EN EL FIRMWARE V8.9.**  
**Fecha de Emisión:** 27 de Agosto de 2026  
**Última Revisión:** 11 de Septiembre de 2026 (tarde) — 🟢 **`D-27`: `J14` queda LIBRE, sin cablear —el fin de carrera NO se instala en este despliegue—, lo que cierra el conflicto de `A-2` que la revisión de abajo dejaba abierto** (fe de erratas, §3, §4.1, §5 y §6, tachado con esta fecha); y **la pieza de la talanquera es un relé con bobina de 12 V DC y contacto NA**, no un módulo optoacoplado con `JD-VCC` (§3, línea `A4` del Manual 15).  
**Revisión anterior:** 11 de Septiembre de 2026 — 📷 **`D-25`: la talanquera va a `J15` por la BOBINA de un relé (p1 12 V, p2 drenador de `Q10`, que NO es masa) y su contacto a la entrada `OPEN` de la centralita**; se tacha la conexión directa del drenador a `OPEN` de §3, se corrige lo que §3 decía de «la pluma se queda abajo», y `J14` deja de llamarse «la entrada de la cámara»: **~~`A-2` la reservó al fin de carrera~~ y el firmware la sigue leyendo como cámara — ~~CONFLICTO ABIERTO~~** *(derogado por `D-27` en la revisión de arriba: `J14` libre y sin cablear, el fin de carrera no se instala)*. Las cámaras son **cuatro, dos por poste, en `J16` p10 y p12**.  
**Revisión anterior:** 28 de Agosto de 2026 (segunda revisión del día) — 🔴 **corrige un error de cableado que puede DESTRUIR EL MICROCONTROLADOR** (`J14`/`J15`, §3 y §5), da por **muerta la ruta C** del bus (el Bluetooth ocupó `PB6`/`PB7` hoy mismo), añade la **ruta D**, avisa de que el `DS3231` **no tiene driver** y actualiza la cifra de flash. Ver las fes de erratas antes de usar cualquier copia impresa anterior.  

---
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

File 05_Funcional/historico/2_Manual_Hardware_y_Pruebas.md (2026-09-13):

# MANUAL DE HARDWARE Y PRUEBAS (Ecosistema Semáforos - V9.0)

Este documento contiene las instrucciones paso a paso para el personal funcional encargado de ensamblar, probar y actualizar el firmware de los semáforos en campo o laboratorio.

## 📌 HARDWARE COMPLETO Y HOMOLOGADO (V9.0)

| Elemento | Estado | Ubicación / Conexión |
|---|---|---|
| **Pila `CR2032` en `VBAT`** | ✅ **Instalada en AMBAS tarjetas** (Maestro y Esclavo) | Alimentación directa RTC (R5 retirado). Ver §5 |
| **Pantalla LCD ST7920** | 🛑 **SE RETIRA (28/08/2026)** | No se lee desde el suelo. Sus pines `PB6`/`PB7` (conector `J17`) pasan al módulo Bluetooth. Ver §3 y §8 |
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

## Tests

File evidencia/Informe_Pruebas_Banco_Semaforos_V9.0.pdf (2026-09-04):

Informe de Pruebas de Banco - Semaforos Sisga V9.0 (617bd00) | Pagina 1

# Informe de Verificación en Banco

## Sistema de Semáforos Inteligentes — Proyecto Sisga

Versión de firmware: V9.0 · Commit: 617bd00 Paquete: Paquete_Revision_V9.0_2026-09-02_617bd00_SIN_BANCO Rama: main-nuevo · Árbol al momento del acta: limpio

Fecha de la revisión de acta (referencia): 2026-09-02
Fecha de ejecución de pruebas de banco: 2026-09-03 / 2026-09-04

Preparado por: Sebastian — IT Vial SAS Equipo de banco: nitro5-marco

Resultado global
24 de 29 pasos de la guía completados y verificados en banco · 4 pasos bloqueados por el enlace Bluetooth · 1 incidente crítico de seguridad (paso 29, sobrecalentamiento del Maestro)

Informe de Pruebas de Banco - Semaforos Sisga V9.0 (617bd00) | Pagina 2

## 1. Resumen ejecutivo

Se realizó la verificación física en banco del paquete V9.0 (commit 617bd00) de la controladora de semáforos, siguiendo paso a paso la guía interna del proyecto Guía de Cableado y Pruebas de Banco (29 pasos). El acta de verificación previa (ACTA_verificacion.txt, 2026-09-02) ya certificaba el paquete a nivel de archivo — compilación de los cuatro firmwares (Maestro, Esclavo, Repetidor, ESP32) y simuladores de software, con 20/20 comprobaciones en PASS — pero explícitamente marcada como no probada en banco. Esta sesión cubre justamente esa verificación física que faltaba.
El resultado general es positivo en los aspectos estructurales del hardware: carga de firmware, comunicación por radio entre Maestro y Esclavo, comportamiento de la talanquera, señal de la cámara de demanda (J14), y cableado de cámara en J16 funcionan como se espera. Se resolvió además una contradicción de arquitectura documentada desde antes de esta sesión (la identidad real del conector J17). Sin embargo, quedan tres asuntos abiertos que impiden certificar el sistema como listo para campo:
1. El enlace Bluetooth (ESP32 + app) no se logró establecer de forma confiable — pese a que el hardware del módulo (ESP32-WROOM-32 clásico) y la carga del firmware ESP32_Expansion se verificaron correctos. Esto bloquea 4 pasos completos de la guía y la verificación real del Modo Automático, que hoy solo se puede seleccionar desde la app.
2. Los pines de mando de J16 (pin5/pin8) miden 0,6V en reposo en vez de los ~3,3V esperados — lo que sugiere una resistencia externa dominando el pull-up interno del STM32 y pone en riesgo el respaldo de seguridad del mando de relés (SFTY-21).
3. Incidente de seguridad durante el paso 29 — el chip STM32 de la placa Maestro se sobrecalentó durante la prueba del mando de relés. La prueba se abortó de inmediato; la placa requiere inspección técnica antes de cualquier prueba eléctrica adicional.

Estado global de los 29 pasos

Completados | Bloqueados (Bluetooth) | Abortado por seguridad
24 / 29 | 4 / 29 | 1 / 29
pasos 1-6, 8-9, 15-18, 20-24 | pasos 25, 26, 27, 28 | paso 29

Nota: los pasos 7, 19 y 21 se completaron parcialmente — la parte de cableado/medida se verificó, pero la respuesta funcional completa del semáforo depende del Modo Automático, bloqueado por el mismo motivo Bluetooth. Se cuentan dentro de los 24 completados por su parte verificable en banco, con la salvedad indicada en su sección.

## 2. Alcance y metodología

Equipo bajo prueba: una placa Maestro y una placa Esclavo (firmware V9.0, commit 617bd00, compilado desde fuente vía PlatformIO/VSCode y cargado por SWD con ST-LINK), más un módulo ESP32 DevKitV1 usado como puente Bluetooth hacia la app móvil, con firmware propio del proyecto (ESP32_Expansion) y reloj de tiempo real DS3231.
Condiciones de banco: sin cámara de demanda real, sin receptor de mando de relés, sin lámparas montadas. Las entradas de campo se simularon con cables puente y las salidas se verificaron con multímetro, siguiendo la secuencia de 29 pasos de la guía interna del proyecto.
Diferencia relevante de arquitectura frente a la guía: esta versión del hardware ya no tiene pulsadores físicos ni pantalla LCD — toda la selección de modo de operación se migró a una aplicación móvil por Bluetooth

Informe de Pruebas de Banco - Semaforos Sisga V9.0 (617bd00) | Pagina 3

(decisión de arquitectura del 31/08). La única excepción es el mando de relés (canales A y B, conector J16 pines 5 y 8), que se conservó deliberadamente como respaldo físico de seguridad independiente de la app y del ESP32. Esta diferencia explica varios de los resultados de este informe: el equipo, al encender, queda en un estado de espera de selección de modo (rojo fijo con comunicación, ámbar intermitente sin ella) hasta que se elige un modo desde la app.

Informe de Pruebas de Banco - Semaforos Sisga V9.0 (617bd00) | Pagina 4

## 3. Resultados detallados por paso

### 3.1 Identificación del módulo y carga de firmware (pasos 1-2)

Paso 1
Identificar el módulo
ESP32

COMPLETO

Módulo confirmado como familia ESP32 original (no S3/C3/S2) por su mapa de pines (30 pines, TX2/RX2, D34-D39 solo entrada). La chapa impresa es genérica ("WiFi ESP-32 · WiFi+BT SoC Inside") y no dice "WROOM-32" literalmente; esa identidad se confirmó por otra vía (ver 3.2). Dos módulos disponibles. No se pudo medir el ancho entre filas por falta de pie de rey — dato menor, sin impacto en la prueba.

Paso 2
Carga de firmware a
Maestro y Esclavo

COMPLETO

Las dos tarjetas se cargaron correctamente desde VSCode + PlatformIO (subida directa por SWD vía ST-LINK). En ambos casos: "escrito y verificado" al primer intento, sin necesidad del puente BOOT0.

### 3.2 Identificación de conectores J16 / J17 (pasos 3-5)

Paso 3
Identificar J16 (potenci
a/mando/cámaras) vs
J17

CRÍTICO

J16 pin1 mide 12V y J17 pin1 (CS/PB4) no da 12V, coincidiendo con lo esperado. Pero se encontró una contradicción entre el esquemático KiCad del proyecto y la guía de pruebas: el esquemático real muestra J17 como el conector de la pantalla LCD (CS, RST, RS/A0, SCL, SI, 3,3V y masas), mientras que el paso 9 de esta misma guía indica conectar ahí el UART del ESP32. Ver hallazgo resuelto más abajo.

Paso 4
Tapar el pin de 12V
crudo de J16

COMPLETO

Se retiró físicamente el pin del conector volante (en vez de usar funda termorretráctil). Pin tapado y confirmado en las mediciones posteriores del paso 21.

Paso 5
Comprobar J17 antes
de conectar el módulo

COMPLETO

Continuidad correcta entre J17 pos.3↔pata 42 y pos.2↔pata 43 de la STM32. Con energía: CS y RST en 3,3V, RS/A0 variando activamente entre 2,8 y 3,3V (línea en uso), SCL y SI en 0V, dos posiciones más en 3,3V y dos en masa, resto en 0V. Sin 12V en ningún pin. El hecho de que RS/A0 estuviera activamente cambiando de voltaje refuerza que J17 se usa como interfaz activa (relevante para el hallazgo del paso 3).

Hallazgo de arquitectura — RESUELTO
La aparente contradicción (J17 = LCD según esquemático vs. J17 = UART/Bluetooth según la guía) se resolvió consultando el manual interno del proyecto 17_Arquitectura_28-08_y_Decisiones_Abiertas.md: el netlist KiCad quedó desactualizado tras retirarse la pantalla y los pulsadores (decisión del 31/08), y el firmware remapea USART1 a PB6(TX)/PB7(RX), que sale físicamente por J17 posición 3/2. La medición de continuidad del paso 5 lo confirma de forma independiente. Arquitectura vigente: el ESP32 sustituye a un módulo Bluetooth SPP dedicado (no se usa un HC-05/JDY-30 aparte).

### 3.3 Arranque y comunicación Maestro-Esclavo (pasos 6-8)

Informe de Pruebas de Banco - Semaforos Sisga V9.0 (617bd00) | Pagina 5

Paso 6
Encender y observar
arranque

COMPLETO

Ambas tarjetas encienden y se comunican entre sí; el zumbador de J13 no suena, lo cual es esperado y no es una avería. El comportamiento observado no es un ciclo automático vehicular: es rojo fijo mientras hay comunicación Maestro-Esclavo, ámbar intermitente sin ella, y un breve rojo inicial antes de enlazar. Esto es correcto: el equipo espera selección de Modo Automático desde la app, que en esta sesión aún no se había podido establecer por Bluetooth.

Paso 7
Orden de luces y
todo-rojo entre verdes

PARCIAL

No se pudo verificar: nunca apareció la luz verde en ningún poste porque el equipo permanece en el menú de selección de modo, no en operación. Está relacionado con la regresión conocida N-42 ("Modo Automático no mueve las luces"), pero la causa observada aquí es secuencial — falta completar el enlace de app — no necesariamente el mismo defecto. Pendiente repetir una vez resuelto el Bluetooth, para confirmar o descartar N-42.

Paso 8
Cortar la radio: verificar ámbar intermitente

COMPLETO

Se realizaron 3 cortes de comunicación; en cada uno el equipo pasó a ámbar intermitente en aproximadamente 20 segundos (la guía espera 23-28s — ligeramente más rápido, diferencia menor sin impacto). El ámbar quedó parpadeando en ambos semáforos hasta restablecer el enlace, y volvió solo a rojo fijo en unos 3 segundos al reconectar.

### 3.4 Enlace Bluetooth de mesa (pasos 9-14)

Paso 9
Montar el enlace de
mesa (ESP32 ↔ J17)

COMPLETO

Conexión confirmada: ESP32 GPIO17(TX2)→J17 pos.2→PB7(RX de la STM32); GPIO16(RX2)→J17 pos.3→PB6(TX de la STM32); GND común; 9600 8N1. El ESP32 se alimentó de forma independiente (no desde J17).

Paso 10
El módulo aparece en
la lista de Bluetooth del
teléfono

CRÍTICO

No apareció de forma confiable, incluso con el firmware ESP32_Expansion cargado sin errores. Se verificó por otra vía que el hardware es compatible (ver recuadro), por lo que la causa probable está en el firmware, la antena o el propio módulo — pendiente de diagnóstico adicional.

Paso 11
La app logra conectar

BLOQUEADO

No se pudo intentar de forma confiable al depender del paso 10. Se aclaró un punto de proceso: el ESP32 empareja por "Just Works" (sin PIN de sistema operativo, confirmado en el firmware). El PIN 1234 de la guía es un PIN de comando dentro de la app (ver paso 28), no el PIN de emparejamiento Bluetooth.

Paso 12-14
Verificaciones
adicionales del enlace
de mesa

BLOQUEADO

No ejecutados: dependen directamente de establecer el enlace de los pasos 10-11.

Hardware del ESP32 verificado como compatible — la causa no es el chip

Informe de Pruebas de Banco - Semaforos Sisga V9.0 (617bd00) | Pagina 6

Se confirmó, a través del archivo de configuración del propio proyecto (ESP32_Expansion/platformio.ini, cierre de bloqueo BLQ-1 del 31/08), que el módulo es un ESP32-WROOM-32 clásico (Xtensa LX6, Bluetooth v4.2 BR/EDR + BLE, 4MB de flash, USB-UART CP2102). BR/EDR es exactamente el perfil que necesita la app para el socket SPP — un ESP32-S3/C3/S2 no lo tiene y jamás conectaría. Esto descarta que el chip sea la causa del problema; el firmware compiló y se cargó sin errores. La causa de que el dispositivo no se observe en el teléfono queda abierta y requiere diagnóstico adicional (por ejemplo, revisar si el proceso de anuncio SPP se está iniciando, estado de la antena del módulo, o interferencia).

### 3.5 Talanquera — conector J15 (pasos 15-16)

Paso 15
¿Con qué color de luz
sube la talanquera?

COMPLETO

Se identificó que J15 es una salida directa de motor (MOT+/MOT-, transistor de potencia hasta 10A en la propia placa), no una entrada de disparo de bajo voltaje como sugiere el texto genérico de la guía — no requiere 12V externo para medir. En rojo (esperando modo): 0V, talanquera abajo. En ámbar intermitente: 12V, talanquera sube. El comportamiento en verde queda pendiente de Modo Automático (bloqueado por Bluetooth).

Paso 16
¿Cuándo baja la
talanquera?

COMPLETO

Al recuperar la comunicación (ámbar intermitente → rojo), la salida vuelve a 0V y la talanquera baja correctamente y queda abajo.

### 3.6 Cámara de demanda — conector J14 (pasos 17-19)

Paso 17
Medir bornes de J14

COMPLETO

Borne "3.3V": 3,3V. Borne "Puerta": 0V. Coincide con lo esperado.

Paso 18
Conmutación de la
cámara en J14

COMPLETO

Al puentear 3,3V con "Puerta" el borne sube a 3,3V; al soltar vuelve a 0V. Conmutación correcta.

Paso 19
Respuesta del
semáforo a la
demanda de J14

PARCIAL

No se pudo verificar la reacción del semáforo: mismo motivo que el paso 7, el equipo está en espera de selección de modo (rojo fijo), no en operación. Pendiente de repetir tras resolver Bluetooth/Modo Automático.

### 3.7 Conector J16 — medida crítica y cableado de cámara (pasos 20-21)

Paso 20 — Medida crítica de J16. Con el conector vacío y sin energía, los cuatro pines (5, 8, 10, 12) muestran valores de resistencia consistentes entre sí, pero ninguno se comporta como "abierto" hacia 3,3V (como predice el ideal de la guía) — indicio de resistencias externas en la placa hacia ambos rieles. Con energía, medido contra masa:

Informe de Pruebas de Banco - Semaforos Sisga V9.0 (617bd00) | Pagina 7
Pin | Resistencia a masa (sin energía) | Resistencia a 3,3V (sin energía) | Voltaje contra masa (con energía)
5 (mando A) | 9,92 kΩ | 11,28 kΩ | 0,6 V
8 (mando B) | 9,92 kΩ | 11,28 kΩ | 0,6 V
10 (cámara) | 9,93 kΩ | 11,29 kΩ | 0 V
12 (cámara) | 9,94 kΩ | 11,31 kΩ | 0 V

Hallazgo eléctrico — pines de mando (5/8) en reposo por debajo del umbral lógico alto Los pines 10 y 12 (cámara) se comportan correctamente: 0V en reposo, permitiendo continuar con el cableado del paso 21. Los pines 5 y 8 (mando A/B), en cambio, miden 0,6V en reposo en vez de los ~3,3V que se esperarían con el pull-up interno de la STM32 activo. Está muy por debajo del umbral lógico ALTO, con riesgo de que el pin ya se lea como "accionado" incluso sin que nada lo accione. La explicación más probable es que la resistencia externa medida en la parte (a), del orden de 10 kΩ hacia masa, domine sobre el pull-up interno (débil) de la STM32. El propio manual de arquitectura del proyecto anticipa esta consecuencia: el pulso de prueba del mando (paso 29) podría no producir una transición detectable si el pin ya lee bajo en reposo. Este hallazgo resultó relevante para el incidente descrito en la sección 3.10.

Paso 21
Cablear la cámara en
J16

COMPLETO

Se cableó el pin10 (B3) al pin11 (3,3V) en configuración normalmente abierta. El pin1 (12V) se confirmó que sigue tapado. En reposo, con y sin el cable puesto, el equipo no pide paso por sí solo — sin falsa activación. La concesión real de paso queda pendiente por el mismo bloqueo de Modo Automático que los pasos 7 y 19.

### 3.8 Placa del módulo definitivo (pasos 22-24)

Paso 22
Placa del módulo y su
fuente

PARCIAL

Se construyó la placa definitiva con fuente conmutada 12V→5V, reloj DS3231 (I2C, GPIO21/22) y salida hacia J17 (GPIO17/16/GND). Las conexiones del DS3231 y de J17 quedaron armadas correctamente. No se pudo medir el desempeño de la fuente 12V→5V real: las pruebas de banco se alimentaron por USB en lugar del circuito de 12V. Pendiente medir la fuente con carga de 12V antes de instalar en campo.

Paso 23
Verificar masa común
antes de unir datos

COMPLETO

Masa de la placa del módulo contra masa de la STM32: 0V (dentro del umbral de 50mV exigido, mejor de lo esperado). GPIO17 contra esa misma masa: 3,3V (nivel lógico correcto, descarta un problema de niveles de 5V). Masa común confirmada como segura para unir las líneas de datos.

Paso 24
Unir los 4 hilos a J17
definitivo

COMPLETO

Con el montaje definitivo conectado y encendido junto a Maestro y Esclavo, el comportamiento fue idéntico al de la mesa de pruebas (rojo fijo / ámbar intermitente según el estado del enlace de radio), sin calentamiento, reinicios ni parpadeo anómalo. Migración del montaje de mesa a la placa definitiva correcta.

Informe de Pruebas de Banco - Semaforos Sisga V9.0 (617bd00) | Pagina 8

### 3.9 Reloj y operación vía app en montaje definitivo (pasos 25-28)

Paso 25
Los dos módulos
aparecen en la lista de
Bluetooth

BLOQUEADO

No se pudo verificar — mismo motivo que el paso 10: el enlace no se observó de forma confiable durante esta sesión.

Paso 26
Operar desde la app
sobre el montaje
definitivo

BLOQUEADO

No se pudo verificar — depende directamente del paso 25.

Paso 27
El reloj conserva la
hora

BLOQUEADO

No se pudo verificar. Al revisar el firmware del puente ESP32 se confirmó que la hora del DS3231 solo se lee y se ajusta mediante un comando enviado desde la app (SET_RTC) por Bluetooth — no existe otra vía para consultarla en banco. Este paso queda, entonces, en la misma categoría bloqueada que 25, 26 y 28.

Paso 28
Comandos con PIN
desde la app

BLOQUEADO

No se pudo verificar — depende de los pasos 25 y 26.

Bloqueo en cascada por el enlace Bluetooth
Aunque el firmware ESP32_Expansion compiló y se cargó sin errores, y el hardware del módulo se confirmó compatible con el perfil Bluetooth que la app necesita (ver sección 3.4), el dispositivo nunca se observó de forma confiable en el teléfono durante esta sesión. Esto bloquea en cascada la verificación completa de: Modo Automático real (paso 7), respuesta completa a demanda de cámara (pasos 19 y 21), y la operación completa del equipo vía app sobre el montaje definitivo (pasos 25 a 28). En conjunto, es la causa raíz de 4 de los 5 pasos no completados de este informe.

### 3.10 Mando de relés — Incidente crítico de seguridad (paso 29)

El objetivo de este paso era simular, con un cable puente, el pulso que produciría el receptor del mando de relés (aún no instalado en campo — ver contexto en el recuadro siguiente), puenteando pin5 (MANDO_A) y pin8 (MANDO_B) de J16 contra masa, y así revisar en la práctica el hallazgo del paso 20 (pines ya en 0,6V en reposo).

INCIDENTE — sobrecalentamiento de la STM32 del Maestro

Informe de Pruebas de Banco - Semaforos Sisga V9.0 (617bd00) | Pagina 9

Al conectar y soltar el puente entre pin5/pin8 de J16 y masa, no se observó ningún cambio de comportamiento en el semáforo. Durante la prueba, el chip STM32 de la placa Maestro empezó a calentarse de forma perceptible — el calor se sintió directamente sobre el chip, no en la zona del conector J16. Se confirmó que el cable puente tocó únicamente pin5/pin8 y masa, sin contacto con el pin1 (12V) ni con ningún otro pin. Tras el incidente, el Maestro seguía funcionando con normalidad (LEDs y comunicación con el Esclavo intactos) pero se mantuvo caliente — señal de alerta de un posible daño interno ya iniciado. La prueba se detuvo de inmediato y no se pudieron tomar los datos de voltaje previstos para este paso (pin5/pin8 con el puente puesto).

Acción tomada: se ordenó desconectar la alimentación del Maestro de inmediato y dejarlo enfriar sin volver a repetir el puente pin5/pin8. Este informe recomienda una revisión técnica de la placa (inspección visual y térmica con el equipo frío, y prueba de funcionamiento controlada) antes de someterla a cualquier prueba eléctrica adicional en J16.
Causa probable, sin confirmar: este informe no afirma una causa definitiva — se requiere diagnóstico técnico con el equipo frío y, de ser necesario, con instrumentación adecuada (osciloscopio o cámara térmica) para confirmarla. La hipótesis más consistente con los datos recogidos es una interacción entre la resistencia externa detectada en el paso 20 (que ya dominaba el nivel de reposo de los pines de mando) y el estado interno de esos pines de la STM32 al forzarlos a masa, lo que habría generado una corriente sostenida mayor a la normal. No se descartan otras causas (por ejemplo, un defecto preexistente de la unidad o un problema no relacionado con el puente). El resultado de este paso queda abortado por seguridad, no verificado.

Informe de Pruebas de Banco - Semaforos Sisga V9.0 (617bd00) | Pagina 10

## 4. Hallazgos críticos consolidados

# | Hallazgo | Estado | Impacto

H1 | Identidad real del conector J17 (LCD en esquemático vs. UART/Bluetooth en uso) RESUELTO | Ninguno — arquitectura confirmada y documentada, sin acción pendiente.
H2 | Pines de mando J16 (5/8) en 0,6V en reposo, no ~3,3V esperado ABIERTO | Riesgo sobre el respaldo de seguridad del mando de relés (SFTY-21); posible relación con el incidente H4.
H3 | Enlace Bluetooth (ESP32 + app) no se observó de forma confiable ABIERTO | Bloquea 4 pasos de la guía y la verificación real del Modo Automático (y de N-42).
H4 | Sobrecalentamiento del STM32 del Maestro durante prueba de mando ABIERTO — SEGURIDAD Placa Maestro fuera de servicio hasta inspección técnica; paso 29 no verificado.

Sobre la regresión conocida N-42 ("Modo Automático no mueve las luces"): esta sesión no la confirma ni la
descarta. El equipo nunca llegó a operar en Modo Automático real durante las pruebas porque quedó detenido
en el menú de selección de modo (falta de enlace Bluetooth/app). Es necesario repetir el paso 7 después de
resolver H3 para determinar si N-42 sigue presente.

## 5. Conclusiones

El hardware base de la controladora (Maestro y Esclavo) cumple correctamente sus funciones fundamentales verificables sin el enlace Bluetooth: carga de firmware, comunicación de radio entre puntas con conmutación correcta a ámbar intermitente ante pérdida de enlace, control de talanquera, señal de cámara de demanda en J14, y cableado de cámara en J16. Se resolvió además una ambigüedad de arquitectura heredada de documentación desactualizada (identidad de J17), dejando esa parte del sistema completamente clara y verificada.
No obstante, el sistema no puede considerarse listo para operación en campo en su estado actual: la vía principal de operación (selección de Modo Automático y demás modos desde la app, vía Bluetooth) no pudo verificarse en ningún momento de esta sesión, lo que impide confirmar el funcionamiento real del ciclo vehicular, la respuesta a demanda de cámara y la conservación de hora. A esto se suma un hallazgo eléctrico sin resolver en los pines de mando de J16, y un incidente de seguridad que dejó la placa Maestro en estado de alerta y sin poder completar la verificación del respaldo físico de mando (paso 29).

## 6. Recomendaciones y próximos pasos

Prioridad 1 — Seguridad. Inspeccionar técnicamente la placa Maestro (fría) antes de volver a energizarla para pruebas: revisión visual y térmica de la zona del microcontrolador y del conector J16, y verificación de que no haya un corto o daño permanente antes de reintentar cualquier prueba eléctrica.
Prioridad 1 — Diagnóstico del enlace Bluetooth. Determinar por qué el ESP32 no se anuncia de forma confiable pese al hardware y firmware correctos: revisar si el proceso de advertising SPP arranca (log por USB/monitor serie), estado y ubicación de la antena, y descartar interferencia. Es la dependencia que bloquea más pasos de la guía.
Prioridad 2 — Pines de mando J16 (5/8). Investigar el origen de la resistencia externa hacia masa detectada en el paso 20 (posible red de pull-down en la propia placa) y evaluar si es necesario un ajuste de diseño antes de instalar el receptor de mando en campo.
Repetir una vez resuelto el Bluetooth. Pasos 7 (Modo Automático real / N-42), 19 y 21 (respuesta completa a demanda de cámara), 25-28 (operación por app, reloj, comandos con PIN) y, tras la inspección de seguridad, el

Informe de Pruebas de Banco - Semaforos Sisga V9.0 (617bd00) | Pagina 11

paso 29 (mando de relés).
Pendiente independiente. Medir el desempeño real de la fuente 12V→5V de la placa del módulo definitivo con carga de 12V (paso 22), en vez de USB, antes de dar por cerrada esa parte del montaje.

Con estos puntos resueltos, el equipo estará en condición de completar el 100% de la guía de 29 pasos y avanzar a la siguiente fase de pruebas adicionales que se acordó realizar a continuación de este informe.

Informe de Pruebas de Banco - Semaforos Sisga V9.0 (617bd00) | Pagina 12
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

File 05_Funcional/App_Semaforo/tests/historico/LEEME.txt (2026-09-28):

TESTS ARCHIVADOS DE LA APP (28/09/2026, poda "opcion B")

No corren: compuerta.py no los llama y el script npm "test:e2e" se retiro de package.json.
No se borro nada: git mv, historia intacta.

test_e2e_visual.js - abre Chrome con Puppeteer, pulsa botones y guarda capturas. Sale: no tiene un solo assert, no estaba en la compuerta y no puede fallar por un valor incorrecto. Sus rutas (__dirname/../../../evidencia) quedaron un nivel desplazadas al moverlo.

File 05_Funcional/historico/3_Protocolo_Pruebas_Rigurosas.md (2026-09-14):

# 📋 PROTOCOLO DE AUDITORÍA FUNCIONAL Y ACTA DE CERTIFICACIÓN EN CAMPO

**Revisión:** 4 de septiembre de 2026 *(la anterior, 31 de agosto)* · **Rama:** `main-nuevo`
**Documento para remisión al Ingeniero Funcional / Auditor de Tránsito**
**Ubicación:** `05_Funcional/3_Protocolo_Pruebas_Rigurosas.md`
**Entorno Auditable:** Ecosistema Semafórico Móvil (Maestro STM32, Esclavo STM32)

> **Esta revisión sustituye a la V8.7 del 1 de Agosto.** La anterior seguía dando por navegable un
> menú que ya no se puede abrir y por legible una pantalla que ya no conduce sus pines. Cada una de
> sus pruebas se ha revisado una por una y marcada; **ninguna se ha borrado en silencio.**

---

# 🛑 FE DE ERRATAS DEL 07/09 — SE LEE ANTES DE PLANIFICAR LA SESIÓN, Y ANTES DE TOCAR NADA

> **Este documento no pasó la revisión cruzada del 07/09 que sí pasaron los demás manuales** (commit
> `1185441`, que tocó 22 documentos y **no éste**). Lo que sigue son las ~~siete~~ **ocho** cosas que
> quedaron caducadas y que **cambian lo que el auditor hace con las manos o firma con la pluma**. Cada
> una se corrige además en su sitio; aquí van juntas porque **quien planifica la sesión no lee el
> documento entero antes de repartir la jornada**. *(La octava, `E-8`, se añadió el mismo 07/09 con la
> decisión `D-20`, posterior al resto de esta tabla. La novena, `E-9`, el 11/09 con `D-26`, y corrige
> la mitad de `E-8` que caducó.)*
>
> **Manda `DECISIONES.md`.** Si una frase de este protocolo choca con una fila de allí, la fila gana
> y el párrafo está caducado — incluidos los párrafos que lleven `MEDIDO` encima: *una fecha no
> valida un contenido, sólo dice cuándo se miró.*

| # | dónde | qué decía este documento | qué es verdad hoy (07/09) |
|---|---|---|---|
| 🔴 **E-1** | **§0.3 · §8 entera · §9.5, 9.6, 9.9, 9.10, 9.11, 9.16** | *«el gesto vigente es cerrar `J16` p5 contra p4»*, como procedimiento normal de la sesión | **`J16` p5 y p8 están VACÍOS y el código del mando SIGUE leyendo sus flancos** (`DECISIONES.md` `D-1`, `A-2`). Y **medido el 07/09 en `Maestro/src/mando.cpp`: la secuencia `A·A·A` entra en Modo Automático SIN NINGUNA GUARDA — arranca el ciclo, o sea ABRE PASO.** Lea el recuadro rojo de §0.3 **antes** de tocar `J16` |
| 🔴 **E-2** | **§0.2 · §9 (preámbulo) · §9.15 · §10** | *«el Esclavo NO tiene ni un solo `SET_MODO`»*, y una prueba nueva (**9.15**) escrita para **firmar esa ausencia en el acta** | **FALSO desde `15e8cf3`** (`D-18`): el Esclavo acepta **`CMD:PIN:1234:SET_MODO:DEGRADADO`**. `grep -c "SET_MODO" 01_Firmware/Esclavo/src/bluetooth.cpp` → **10**. Tal como estaba escrita, **9.15 marcaba `NO CUMPLE` a un firmware correcto** |
| 🔴 **E-3** | **§7.1 · §7.11 · §12.7** | mandar `CMD:PIN:1234:SET_RTC:` **al STM32** y esperar una de cuatro respuestas | **El STM32 YA NO CONTESTA A `SET_RTC`** (`D-15`): consume la orden en silencio y sólo emite un `$EVENT` con `SET_RTC_LO_ACUSA_EL_PUENTE`. **Quien espere `$ACK`/`$ERR` en el terminal verá silencio y declarará averiado un equipo sano** — este proyecto ya cambió pila y cristal buenos por eso |
| 🔴 **E-4** | **§11 (preámbulo) · §11.1 · §11.2 · §4.2** | *«la única entrada de cámara que el firmware lee hoy es `PB0`, por la bornera `J14`»* y *«provoque la detección en `J14`»* | **Las cámaras van a `J16` p10 (`CAM_C_PIN`, `PB14`) y p12 (`CAM_D_PIN`, `PB15`)** (`D-2`, `D-3`, `M3` cerrada en cobre el 03/09). `J14`/`PB0` sigue vivo en el firmware **y sin cámara**. 🛑 **Y el motivo por el que esto no es cosmético: el vigilante de `CAM_CIEGA`/`CAM_PEGADA` mira `J16` y NO mira `J14`** — una cámara en `J14` funciona **y no está vigilada** |
| ⚠️ **E-5** | **§0.2 (las dos tramas)** | plantillas de `$STATUS` sin `PLUMA:` ni `CAM:` | Las dos puntas publican hoy **`PLUMA:`** (N-153) y **`CAM:`** (`A-13`, cerrada el 07/09). Plantillas reales abajo, leídas del `snprintf` |
| ⚠️ **E-6** | **todo el documento** | citas por **número de línea** con `MEDIDO` al lado | **Seis de ellas ya no señalan donde dicen** — re-medidas el 07/09 y corregidas por símbolo. `CLAUDE.md` §7.3: se cita el símbolo, no la línea |
| 🟢 **E-7** | **§0.2 · tabla de comportamientos esperados · §9.7 · §10** | *«`MODO:SUBORDINADO` en el Esclavo es un literal fijo»*, y de ahí un **hueco declarado** para el dictamen: *«no hay forma de saber desde fuera si el Esclavo está en Degradado»* | **El hueco ESTÁ CERRADO y el documento no se enteró.** El `MODO:` del Esclavo sale hoy de `obtenerNombreModo(degradado_estado())` y publica **`SUBORDINADO` · `DEGRADADO` · `RENDIDO`**. *(Un hallazgo caducado en un protocolo es peor que uno que falta: **acaba en el dictamen de un auditor** como limitación del equipo.)* |
| 🔴 **E-8** | **§0.2 (censo de órdenes) · §7.1 · §7.6 · §7.8 · §7.11 · §9 (3, 4 y su preámbulo) · §12.6 · el acta** | *«la hora se pone en el Maestro y viaja por radio»* en unos sitios y *«la app valida la hora en las DOS puntas visitando los dos postes»* en otros — **dos arquitecturas contradictorias dentro del mismo documento**, y una prueba con casilla `CUMPLE / NO CUMPLE` para cada una | **`DECISIONES.md` fila `D-20` (07/09): LA AUTORIDAD DE LA HORA ES EL ESP32, SIEMPRE. Hay UNA sola fuente: la app se la da al ESP32 del poste 1, y de ahí baja al STM32, cruza por radio y sube al ESP32 del poste 2.** ~~La app **NO** pone la hora en el poste 2, **nunca** — un `SET_RTC` dirigido al Esclavo **se rechaza**: no es una sincronización, es una **segunda fuente**. 🛑 **Y `D-20` está DECIDIDA Y SIN CONSTRUIR: nada de ese recorrido corre hoy en ninguna tarjeta**, así que las pruebas que lo ejercen se marcan ⏸ **no ejecutables**, nunca `NO CUMPLE`.~~ *(Corregido por **`E-9`**, 11/09.)* **§12.6 (Courier RTC) no se aplaza: MUERE** — es la maniobra que `D-20` prohíbe. **§7.8 NO muere: se PARTE** — su mecanismo caduca y su propiedad (*«nadie toca el Esclavo y la hora le llega sola»*) es justo la que `D-20` eleva a regla |
| 🔴 **E-9** *(11/09)* | **las mismas secciones de `E-8`, y todo lo que diga *«la app no pone la hora en el poste 2»*, *«se rechaza»* o *«en la puesta en marcha, no durante la avería»*** | la fila `E-8` de arriba, en su mitad tachada | **`DECISIONES.md` fila `D-26` (11/09): LA HORA LA MANDA EL ESP32 DE CADA POSTE.** Con radio, el Esclavo hace caso a la del Maestro; **sin radio (25 s, `SFTY6_SILENCIO_MS`) toma la de su propio ESP32**, y **al poste 2 SÍ se le pone la hora desde el teléfono** —es el procedimiento cuando salta `FALLO_RF`—. La prohibición ya estaba tachada en la propia fila `D-20` el 07/09 por la noche. **Construida en `68dd2c5`** —siembra `CMD:HORA_ESP32` cada 300 s, `SET_RTC` atendido por el puente y que no cruza, salto > 29 s en Degradado por rojo (`SALTO_DE_HORA_POR_ROJO`), `$ALARM …EVENTO:HORA_ESP32…`—, **sin banco**. Consecuencias para este protocolo: (1) las pruebas que `E-8` dejó ⏸ **dejan de ser «no ejecutables» por falta de código**: se ejecutan en la próxima sesión y se anotan con su resultado; (2) **«la hora le llega sola al Esclavo» vale CON radio**; sin radio, lo que se prueba es que tome la de su ESP32 y que salte `FALLO_RF`; (3) **ninguna prueba puede exigir que un `SET_RTC` al poste 2 se rechace**: el equipo lo acepta, y eso es lo correcto; (4) **el `$EVENT …DETALLE:SET_RTC_LO_ACUSA_EL_PUENTE` que varias pruebas esperan ya no existe** —el `SET_RTC` no llega al STM32—: lo que se ve en el diario es `HORA_ESP32_SEMBRADA` (o `HORA_ESP32_IGNORADA_MANDA_RADIO` en el poste 2 con radio), **sólo en el cambio**. ⚠️ **Este documento NO se ha re-escrito prueba a prueba el 11/09**: sus secciones de hora siguen con el texto del 07/09 y se leen con esta fila delante. Qué ve el técnico: `14_Manual_App_Movil_IOT_VIAL.md` §5.3.bis |

> ⚠️ **Lo que esta fe de erratas NO hace, y se dice para que nadie lo lea como un permiso:** no retira
> la §8 ni la parte de la §9 que ejerce el mando. **`D-1` conserva el CÓDIGO del mando a propósito**
> —de `mando_ambarLocal()` cuelga el veto de SFTY-21— así que sigue siendo firmware verificable. **Lo
> que cambia es que ejercerlo dejó de ser un paso de rutina y pasó a ser una maniobra con una
> advertencia delante**, y que el equipo de calle **no** lo va a usar nunca. Si el funcional decide
> que no merece la sesión, esa es una decisión suya y del responsable: **este documento no la toma.**

---

## 🛑 04/09 — LO PRIMERO DE TODO: EL BANCO YA CORRIÓ, Y HAY UNA TARJETA EN ALERTA

**El 3 y el 4 de septiembre se ejecutó por primera vez la `Guia_Cableado_y_Pruebas_Banco.html`
completa —29 pasos— sobre tarjetas reales, con el paquete `617bd00`.** El informe devuelto es
`evidencia/Informe_Pruebas_Banco_Semaforos_V9.0.pdf`, y **manda sobre cualquier suposición de este
documento**. Tres cosas de las que trae hay que leerlas **antes** de planificar una sesión con este
protocolo:

| | Qué se midió | Qué significa para este protocolo |
|---|---|---|
| 🔴 **1** | **Durante el paso 29, el STM32 de la placa MAESTRO se sobrecalentó** al puentear `J16` p5/p8 contra masa. La prueba se abortó, la placa siguió funcionando pero caliente, y el informe **pide inspección técnica en frío antes de cualquier otra prueba eléctrica en `J16`** | **Esa tarjeta no se energiza para este protocolo hasta que alguien la inspeccione.** No es una recomendación de proceso: el informe declara *señal de alerta de un posible daño interno ya iniciado* |
| 🔴 **2** | **`J16` p5 y p8 —el mando `A` y `B`— midieron `0,6 V` en reposo**, con `9,92 kΩ` a masa. El pull-up interno no ganaba | ~~**§0.3 escribió dos ramas y salió la mala: el mando está inoperante de fábrica.**~~ 🔧 **Corregido el 04/09 (N-118): ese `0,6 V` lo producía EL FIRMWARE, no sólo la placa** — era el pull-up interno contra los 10 kΩ. **El firmware ya está arreglado en las dos puntas** (`INPUT` pelado, activo en ALTO) y **el gesto para pulsar el mando CAMBIA: p5 contra p4 y p8 contra p7, NO contra masa.** La §8 y la parte de la §9 que dependen del puente **siguen sin ejecutarse**, pero **por otro motivo**: no hay tarjeta sana con la que ejercerlo. Ver §0.3 |
| 🔴 **3** | **El módulo Bluetooth nunca se anunció en el teléfono**, con el firmware cargado sin errores y el hardware descartado como causa | Todo lo que entra por la app sigue sin poder probarse. **La vía de `J17` por USB-TTL sigue siendo la única**, y este protocolo ya está escrito sobre ella |

> ⚠️ **Y lo que el banco NO decidió, que es lo que más se va a malinterpretar: la regresión N-42.**
> El informe es explícito: *«esta sesión no la confirma ni la descarta»*. El equipo **nunca llegó a
> operar en Modo Automático** porque la única vía de selección de modo es la app, y la app no
> conectó. **Un «no se pudo probar» no es un «sigue rota» ni un «ya está»** — es un `ABORTADO`, y
> un `ABORTADO` no dice nada del firmware. **Se decide repitiendo el paso 7 de la Guía con enlace**,
> y hasta entonces la advertencia de la Sección 3 sigue en pie **exactamente igual que antes**.

---

## 🔴 LO PRIMERO: POR QUÉ NO PUEDE USARSE LA REVISIÓN ANTERIOR

Tres cosas cambiaron en el equipo y las tres invalidan procedimiento escrito:

| Qué cambió | Dónde está medido | Consecuencia para este documento |
|---|---|---|
| **`botonAceptar()` y `botonCancelar()` devuelven `false` siempre.** Los pulsadores 3 y 4 dejaron de ser pulsadores: sus pines (`PB14`, `PB15` = `J16` p10/p12) pasan a ser **entradas de cámara** | ~~`Maestro/src/botones.cpp:305-306` · `Esclavo/src/botones.cpp:316-317`~~ → **se cita el símbolo, §4.sexies:** `grep -n "bool botonAceptar\|bool botonCancelar" Maestro/src/botones.cpp Esclavo/src/botones.cpp` — **RE-MEDIDO el 05/09** *(los números viejos ya no señalaban ahí)* | **No se puede aceptar ni cancelar nada.** Todo paso que diga *«pulse Botón 3»*, *«confirme»*, *«entre en CONFIGURACION»* o *«recorra el menú»* **no se puede ejecutar** |
| 🔴 **PERO `botonArriba()` y `botonAbajo()` NO están muertos — y esta fila faltaba.** Devuelven `consumir(0)`/`consumir(1)`, alimentados por `digitalRead(b.pin) == HIGH` sobre `BOTON1`=`PB9` (`J16` p5) y `BOTON2`=`PB13` (`J16` p8) | `grep -rn "botonArriba\|botonAbajo" Maestro/src Esclavo/src` — **MEDIDO el 05/09**: tienen llamadores vivos en `menu.cpp` y `modo_hora.cpp` de las dos puntas | **«Los cuatro botones están fuera» es MEDIA VERDAD y no se puede escribir así en un protocolo.** Fuera está el **pulsador** (`D-1`: no se monta) y fuera están **Aceptar/Cancelar** (el código). **Arriba y Abajo siguen leyendo cobre**, así que **lo que se cierre en `p5`/`p8` contra los 3,3 V entra al firmware** — y por eso esos pines quedan **sin cablear**, no «disponibles» |
| ~~**La pantalla no se retira**~~ → 🔴 **LA PANTALLA Y EL MENÚ SE RETIRAN DEL EQUIPO (`D-17.bis`, 05/09).** Se retira **del equipo, no del código**: `lcd.cpp` y `menu.cpp` siguen compilando y `Validacion_LCD` sigue dando `271/271` sobre un framebuffer en el PC. Y desde antes ya no conducía sus pines: `PB3`/`PB4`/`PB5` en alta impedancia por compartir `J17` con el ESP32 | `Maestro/src/lcd.cpp:74-75` · ~~`Esclavo/src/lcd.cpp:92-93`~~ → **`:103-104`, re-medido el 07/09 (E-6)**. El ancla que no caduca: `grep -n "U8X8_PIN_NONE" Maestro/src/lcd.cpp Esclavo/src/lcd.cpp` | **No hay imagen.** El framebuffer se sigue componiendo y no se vuelca al cable. Todo paso que diga *«la pantalla muestra»* o *«anote lo que muestra»* **no se puede ejecutar** |
| **El CÓDIGO del mando SE CONSERVA**, en los canales `A` (`PB9` = `J16` p5) y `B` (`PB13` = `J16` p8). Las tres secuencias siguen en el firmware — 🔴 **pero el HARDWARE se retiró del equipo (`D-1`) y esos dos pines están VACÍOS (`A-2`). Ver el recuadro rojo de §0.3: `A·A·A` ABRE PASO sin guarda** | ~~`Maestro/src/mando.cpp:202-235` · `Esclavo/src/mando.cpp:218-250`~~ · ~~`mando.cpp:38`/`:39` Maestro~~ → 🔴 **citas caducadas, re-medidas el 07/09 y sustituidas por el símbolo (E-6):** `grep -n "VENTANA_TRIPLE_MS\|VENTANA_CUADRUPLE_MS\|MANDO_A && " Maestro/src/mando.cpp Esclavo/src/mando.cpp`. Los valores **no** cambiaron: `VENTANA_TRIPLE_MS = 12000` y `VENTANA_CUADRUPLE_MS = 18000` en las dos puntas | ~~Las secuencias se pueden **ejercer**~~ ~~**— corregido el 04/09: NO se pueden.** Siguen en el firmware, pero los dos pines miden `0,6 V` en reposo, así que **no hay flanco que darles**: ni con el puente a mano ni con el receptor, que además **nunca se compró**.~~ 🔧 **Corregido otra vez el 04/09, después de N-118, y esta vez con el fuente delante:** el `0,6 V` era obra del `INPUT_PULLUP` que el firmware ponía, y **ese firmware ya no existe** — `botones.cpp` lee `BOTON1`/`BOTON2` en `INPUT` pelado y **activo en ALTO** en las dos puntas. **El flanco sí se puede dar; lo que cambia es cómo: p5 contra p4, p8 contra p7 (3,3 V del pin de al lado), NUNCA contra masa.** Lo que sigue faltando es **una tarjeta con la que ejercerlo** —la Maestro está fuera de servicio por N-116— y el **receptor, que nunca se compró**. Ver §0.3 |

> ⚠️ **Y una consecuencia que no es evidente y hay que decir en voz alta.** Con `botonAceptar()`
> siempre `false`, `menu_estaAbierto()` no puede ser cierto nunca, así que **el mando del Esclavo ya
> no está inhibido en ningún caso**. La regla *«con el menú abierto el mando se ignora»* no está
> rota: **se quedó sin sujeto**.
>
> > ✅ **RE-MEDIDO EL 05/09 y CONFIRMADO — se conserva tal cual, y ahora citado por símbolo**
> > *(la cita vieja `Esclavo/src/botones.cpp:316-317` ya no señalaba ahí)*:
> > `menu_estaAbierto()` devuelve `pantalla != P_MENU`, y `pantalla` sólo cambia con `botonAceptar()`.
> > **El propio firmware lo lleva escrito al lado** — `grep -n "menu_estaAbierto" Maestro/src/botones.cpp Esclavo/src/botones.cpp Esclavo/src/mando.cpp Esclavo/src/menu.cpp`:
> > *«no puede bajar del listado, asi que menu_estaAbierto() es siempre falso y el mando deja…»*.
> > **Y con `D-1` la consecuencia práctica se apaga sola**: sin mando montado nadie compone una
> > secuencia — pero la inhibición sigue **sin sujeto**, no restaurada, y eso importa el día que
> > alguien cablee algo en `p5`/`p8`.

---
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

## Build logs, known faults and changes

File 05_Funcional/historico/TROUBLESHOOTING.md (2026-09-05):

# TROUBLESHOOTING - Controladora de Semáforos V4

Esta bitácora documenta las fallas esperadas y reportadas en campo, su diagnóstico y solución. Dado que la tarjeta (STM32 + MOSFETs) ya está impresa, las soluciones se enfocan en software o modificaciones externas al hardware.

## 1. Problemas de Comunicación (Radios LoRa)

### Síntoma: Ambos semáforos se quedan en Ámbar Intermitente (S_FALLO)
**Diagnóstico:** El maestro no está recibiendo los `PONG` del esclavo o viceversa durante más de
~~5 segundos~~ **25 segundos** — el umbral de orfandad de SFTY-6, releído del C++:

```
$ grep -n "SFTY6_SILENCIO_MS" 01_Firmware/Maestro/include/protocolo.h
149:#define SFTY6_SILENCIO_MS   25000UL
```

**Posibles Causas:**
1. **Ruido en Repetidor (ESP32):** El repetidor se congeló por leer basura electromagnética (ver GAP OPT-5). *Solución temporal:* Reiniciar el repetidor. *Solución Definitiva:* Actualizar firmware del ESP32 para limpiar buffer por timeout. *(Cerrado desde V8.3 con SFTY-16: el puente valida CRC antes de retransmitir y el ruido ya no sale al aire.)*
2. **Antena desconectada:** Verificar cables coaxiales y conector SMA.
3. ~~**Latencia Excesiva:** Si hay línea de vista perfecta, pero igual falla, subir el `TIMEOUT` en `coordinador.cpp` a 10s (OPT-5).~~

> 🔴 **TACHADO EL 05/09: hoy ese consejo BAJA el umbral y mata dos reintentos.** El umbral vale
> ya **25 s**, así que «subirlo a 10 s» es reducirlo. Y no es un número suelto: es el **techo** de
> la ventana de reintentos, la lección de N-71. La cuenta sale del C++ —`CICLO_MAX_REINTENTOS = 5`
> a `TIMEOUT_ACK_MS = 3500` (`coordinador.cpp`), más los 3,0 s de cadencia del latido, dan
> **~20,8 s de peor caso**—: con el techo en 12 s los reintentos 4 y 5 eran **código muerto**,
> porque el ámbar por orfandad saltaba antes y nadie lo notaba, porque el equipo hacía algo
> razonable. **Ese techo no se toca en campo.** La desigualdad la recalcula
> `costura_09_presupuesto_radio` desde las constantes en cada corrida.
>
> Y contra la distancia la palanca correcta **no es esperar más**: la distancia sube la
> probabilidad de pérdida, no la latencia. Contra una trama perdida sirve **repetir**
> (`RF_BURST_COPIES`, SFTY-11), y antes que nada revisar antena y DIP switches.

## 2. Problemas de Luces (Lógica vs Hardware)

### Síntoma: Se encienden luces fantasmas (Rojo y Verde a la vez) o no se apagan.
**Causa:** MOSFET cruzado / dañado (Cortocircuito en el canal N).
**Diagnóstico en terreno:**
- En el código ya implementamos el **Enclavamiento Lógico (SFTY-2)**. Si ves el Verde y Rojo prendidos al mismo tiempo, **NO es culpa del software ni de la lógica del STM32**. 
- Desconecta la bornera de luces. Mide con multímetro continuidad entre el *Drain* y *Source* del MOSFET (IRLZ44N). Si pita, el MOSFET se quemó por sobrecorriente o corto en el cable del semáforo.
*Solución:* Reemplazar MOSFET en la placa (~~`Q1`-`Q9`~~ → **`Q1`–`Q10`**: son **diez** cadenas de potencia, `Q1`–`Q10` con sus optos `U6`–`U15`, no nueve. Contado sobre el `.kicad_pcb` el 28/08; otros dos documentos decían nueve y se tacharon el 05/09).

> ⚠️ **Y el borne NO está a 0 V en reposo, está a ~12 V — LEÍDO DEL COBRE, no medido con
> multímetro.** El pull-up de 1 kΩ + LED al riel de 12 V está en el netlist (`R23`, `R28`, `R33`,
> `R38`, `R43`, `R48`, `R53`, `R58`, `R63`, `R73`) y vive **en el cobre, no en el conector**: no se
> evita dejando un hilo sin poner. Con el MOSFET abierto el borne sube a ~12 V. Medir «0 V =
> apagado» en la bornera lleva a diagnosticar un canal sano como averiado; lo que se mide es la
> **continuidad Drain-Source** con la bornera desconectada, como dice el párrafo de arriba.
> **La excepción es `J8` p2** (`VERDE2`, `PA5`): el cátodo de su LED `D21` está **sin conectar**
> —red `unconnected-(D21-K-Pad1)`, cero pistas—, así que ese borne **flota** en reposo mientras los
> otros nueve suben a 12 V, y ese canal **no tiene indicador luminoso**. Queda `SIN VERIFICAR` si
> es defecto o decisión: se cierra comparando `J8` p1-p2 contra `J7` p1-p2 con el mismo estado de
> luz. *(Y encaja con lo medido en banco el 04/09: `J15` daba «0 V en rojo, 12 V en ámbar» — es
> exactamente este circuito con la sonda entre p1 y p2.)*

### Síntoma: El semáforo se reinicia solo (Se apaga todo y vuelve a prender).
**Diagnóstico:** 
- **Watchdog Timer (SFTY-1):** Desde la V8.0 el perro guardián por hardware está activo a **4.0 segundos** (`IWatchdog.begin(4000000)` en Maestro y Esclavo; el Repetidor ESP32 no lo lleva). Si la tarjeta se resetea sola, significa que el bucle principal se bloqueó más de 4 s: un pico de ruido electromagnético que colgó el procesador, ~~o el bus de la pantalla LCD trabado~~. *Nota: entre la V7.0 y la V7.6 el watchdog estuvo comentado y por tanto inactivo.*

> ⚠️ **La causa «bus de la pantalla trabado» está tachada desde el 05/09: LA PANTALLA SE
> RETIRÓ.** `lcd.cpp` sigue compilando, pero sus tres pines están fijados a `U8X8_PIN_NONE`
> (`Maestro/src/lcd.cpp`, `Esclavo/src/lcd.cpp`) y la librería se salta el `pinMode` y el
> `digitalWrite` cuando el pin es `NONE`: **no hay bus que trabar**. Lo vigila
> `costura_11_lcd_sin_bus`. Con `PB3`/`PB4`/`PB5` en alta impedancia y el ESP32 ocupando `J17`,
> volver a encender la pantalla exige **dos** cosas —devolver los pines Y sacar el módulo del
> conector—, no una.
- **Ventaja:** ¡Este reset salvó el sistema de quedarse congelado en verde para siempre!
- *Solución Definitiva si es recurrente:* Aislar mejor los optoacopladores y separar la fuente de poder de 5V (RS-485) de la de 3.3V (STM32) con filtros capacitivos o ferritas.

## 3. Guía Rápida de Diagnóstico (Leds y Pines)

* **Pin PB12 (LORA_DE_RE):** Si el radio no transmite, mide con osciloscopio o multímetro que este pin suba a 3.3V al momento de enviar, y baje a 0V para escuchar.
* **Transistores MOSFET (IRLZ44N):** Son lógicos directos. Si la salida del STM32 a la compuerta es 3.3V, el semáforo prende. Si es 0V, apaga.
* ~~**Entradas Optoaisladas (TLP127):** Si la demanda de cámaras (PB0/PB8) o botonera no reacciona, medir que haya caída de tensión en el diodo emisor del opto. ¡No puentear nunca la tierra aislada con la tierra digital!~~

> 🔴 **TACHADO EL 05/09/2026. Las tres afirmaciones de esa línea son falsas, y las tres mandan
> a alguien con un multímetro a buscar algo que no está.** Se tacha en vez de borrarse porque la
> frase lleva meses en la guía de campo y volverá a proponerse si desaparece en silencio.
>
> **1. `PB8` no es entrada de cámara desde el 27/08.** Es un LED testigo:
>
> ```
> $ grep -n "PB8" 01_Firmware/Maestro/include/pines.h
> 50:// Medido el 27/08 sobre el esquematico bueno: PB8 va por R16 1K a un LED (D5). Es un
> 60:// pin: un hilo -pad de PB8 retirando R16/D5, o uno de los cuatro pines sin cablear
> 63:#define LED_TESTIGO        PB8  // -> R16 1K -> LED D5. NO es entrada de camara
> ```
>
> La cámara de demanda entra por **`PB0`** (`CAM_DEMANDA_PIN`, bornera `J14`) y por
> **`PB14`** (`CAM_C_PIN`, `J16` p10, la que se cablea hoy — una por poste):
> `grep -n "CAM_DEMANDA_PIN\|CAM_C_PIN" 01_Firmware/Maestro/include/pines.h`.
>
> **2. NO HAY OPTO EN LA ENTRADA. No hay nada.** Los diez `TLP127` (`U6`–`U15`) están en la
> etapa de **POTENCIA**, entre el GPIO y las borneras de luz — no entre la bornera de entrada y
> el micro. Trazado pista a pista sobre el `.kicad_pcb`
> ([`03_Hardware_Tarjeta/MAPEO_TARJETA_KICAD.md`](../03_Hardware_Tarjeta/MAPEO_TARJETA_KICAD.md)
> §7.bis.1): cada red de `J16` tiene **exactamente cuatro pads** —la bornera, la pata de `U1`, y
> `R65`/`C26` colgando **de lado contra `GND`**, que es un antirrebote en paralelo—. **Entre la
> bornera y la pata del micro no hay resistencia en serie, ni divisor, ni diodo, ni opto.**
> Buscar una caída de tensión en un diodo emisor que no existe es tiempo perdido en lo alto de
> un poste.
>
> **3. NO HAY «TIERRA AISLADA» QUE PUENTEAR.** Medido sobre el `.kicad_pcb`: hay **UNA sola red
> `GND` en toda la tarjeta**, con **103 pads** y plano de cobre en las dos capas
> ([`05_Funcional/2_Manual_Hardware_y_Pruebas.md`](../05_Funcional/2_Manual_Hardware_y_Pruebas.md)).
> El opto separa el **pin del micro** del nodo de puerta del MOSFET; **no crea una masa
> separada**: el cátodo de su LED y la fuente del MOSFET están los dos en esa única `GND`.
> Cualquier cosa colgada de esas borneras **comparte la masa del controlador**.

* **Entradas de cámara y mando (`J16`, `J14`) — cómo se miden de verdad:** son GPIO **pelados**
  (`pinMode(..., INPUT)`), **activos en ALTO**, con un pull-**DOWN** de 10 kΩ en placa
  (`R64`–`R68`) y 3,3 V disponibles en la posición contigua del conector. El gesto que pide el
  conector es **cerrar el contacto seco contra esos 3,3 V**, nunca contra masa: en todo `J16` hay
  **una sola masa** (`p2`).

  | qué se mide | conector vacío | contacto cerrado |
  |---|---|---|
  | tensión del pin a `GND` | **0 V** | **3,3 V** |
  | resistencia del pin a `GND` | **~10 kΩ** *(9,92–9,94 kΩ medidos, paso 20 del 03/09)* | — |

  Si el pin no está a 0 V con el conector vacío, el sospechoso es el pull-down (`R64`–`R68`), no
  un opto. *(Y ojo con el histórico: `0,6 V` en reposo no es un defecto de placa — es lo que da
  un `INPUT_PULLUP` interno de ~40 kΩ contra ese 10 kΩ. Los `0,6 V` de N-118 se midieron con un
  binario que aún ponía `INPUT_PULLUP`; el firmware de hoy pone `INPUT` pelado y da 0 V.)*

> ⛔ **ANTES DE ENCHUFAR NADA EN `J16`: `p1` LLEVA 12 V CRUDOS** —sin opto, sin resistencia en
> serie, sin clamp— a nueve posiciones de `p10`. Y la separación real en cobre entre la red de
> 12 V y las de botón baja a **1,359 mm** (§7.bis.2 del mapeo), no a los 10 mm del paso del
> conector. **Tapar `p1` físicamente es obligatorio en cada equipo que se monte** (N-120), no una
> cautela de banco: un error de una posición mete 12 V en un pin de 3,3 V sin nada en medio.

---

## 🔌 RS-485 half-duplex: el control DE/RE

RS-485 usa **un solo par de hilos para ambos sentidos**. Mientras un extremo excita la línea, el
otro **no puede hablar**. Quién habla lo decide la señal DE/RE del transceptor MAX3485.

**Síntoma clásico:** si un DE/RE se queda permanentemente en alto, esa línea queda bloqueada en
**ambos** sentidos. Se manifiesta como dos problemas que parecen distintos:

- El LED **TX de la radio queda encendido fijo** (recibe un flujo interminable y lo radia al aire).
- **No hay datos de vuelta** — el otro extremo no puede meter nada en un bus permanentemente tomado.

Ocurrió en el repetidor el 31/07/2026: el ESP32 levantaba DE/RE ante cualquier byte y solo lo
bajaba tras 5 ms de silencio; con ruido continuo en la línea de entrada, ese silencio nunca llegaba.

**Desde V8.3** el puente solo levanta DE/RE durante los ~4 ms que dura emitir una trama válida.

| Lo que se ve | Qué significa |
|---|---|
| TX **encendido fijo** | DE/RE clavado o ruido continuo. Bus bloqueado en ambos sentidos |
| TX **destella cada 3 s** | Correcto |
| Llega en un sentido y **no vuelve nada** | Sospechar del DE/RE de ese tramo, no de la radio del otro extremo |

---

## 📡 Enlace de radio que funciona en un solo sentido

La propagación es **recíproca**: si A alcanza a B, la pérdida del camino es idéntica en sentido
contrario. **Un enlace no puede fallar solo en una dirección por causas de propagación.** Solo dos
cosas rompen esa simetría: **potencia de transmisión distinta** o **un receptor/transmisor averiado**.

### Prueba de intercambio de frecuencias

Resolvió el caso del 31/07/2026 sin instrumentos:

1. Anotar qué radio está en cada banda y qué falla exactamente.
2. **Intercambiar las asignaciones de frecuencia** entre los extremos.
3. Volver a observar.

| Observación | Conclusión |
|---|---|
| El fallo se queda con el mismo **destino** | Problema del enlace hacia ese punto |
| El fallo sigue a la misma **radio**, aunque cambie de banda y destino | **Transmisor de esa radio averiado** |

**Caso real:** una radio recibía correctamente en ambas configuraciones, pero **nadie oía sus
transmisiones** — ni el Maestro ni el Esclavo, en bandas distintas. La otra radio del repetidor sí
transmitía. Factor común identificado en una sola prueba.

### Por qué suele ser la antena, no el radio

Un receptor capta algo aunque la antena esté floja. **Un transmisor con la antena en mal estado no
radia casi nada**: la potencia se refleja. De ahí el sintoma enganoso de "el LED dice que transmite
pero nadie lo oye".

Revisar en este orden: **conector SMA**, **cable coaxial**, **antena de la banda correcta**, y por
ultimo intercambiar el radio por uno sano.

> **Transmitir con la antena en mal estado dana el amplificador de potencia.** Con 1 W bastan unas
> horas. Al montar un reemplazo, revisar primero el coaxial: si se monta sobre el cable que causo la
> averia, se quema tambien el radio nuevo.

### Antes de nada: los DIP switches

En operacion, **M0 y M1 van SIEMPRE los dos en OFF**. Cualquier otra combinacion mete la radio en un
modo especial donde la transmision puede quedar deshabilitada mientras la recepcion sigue activa.
Es la causa mas frecuente de un enlace de un solo sentido, y se comprueba en diez segundos.

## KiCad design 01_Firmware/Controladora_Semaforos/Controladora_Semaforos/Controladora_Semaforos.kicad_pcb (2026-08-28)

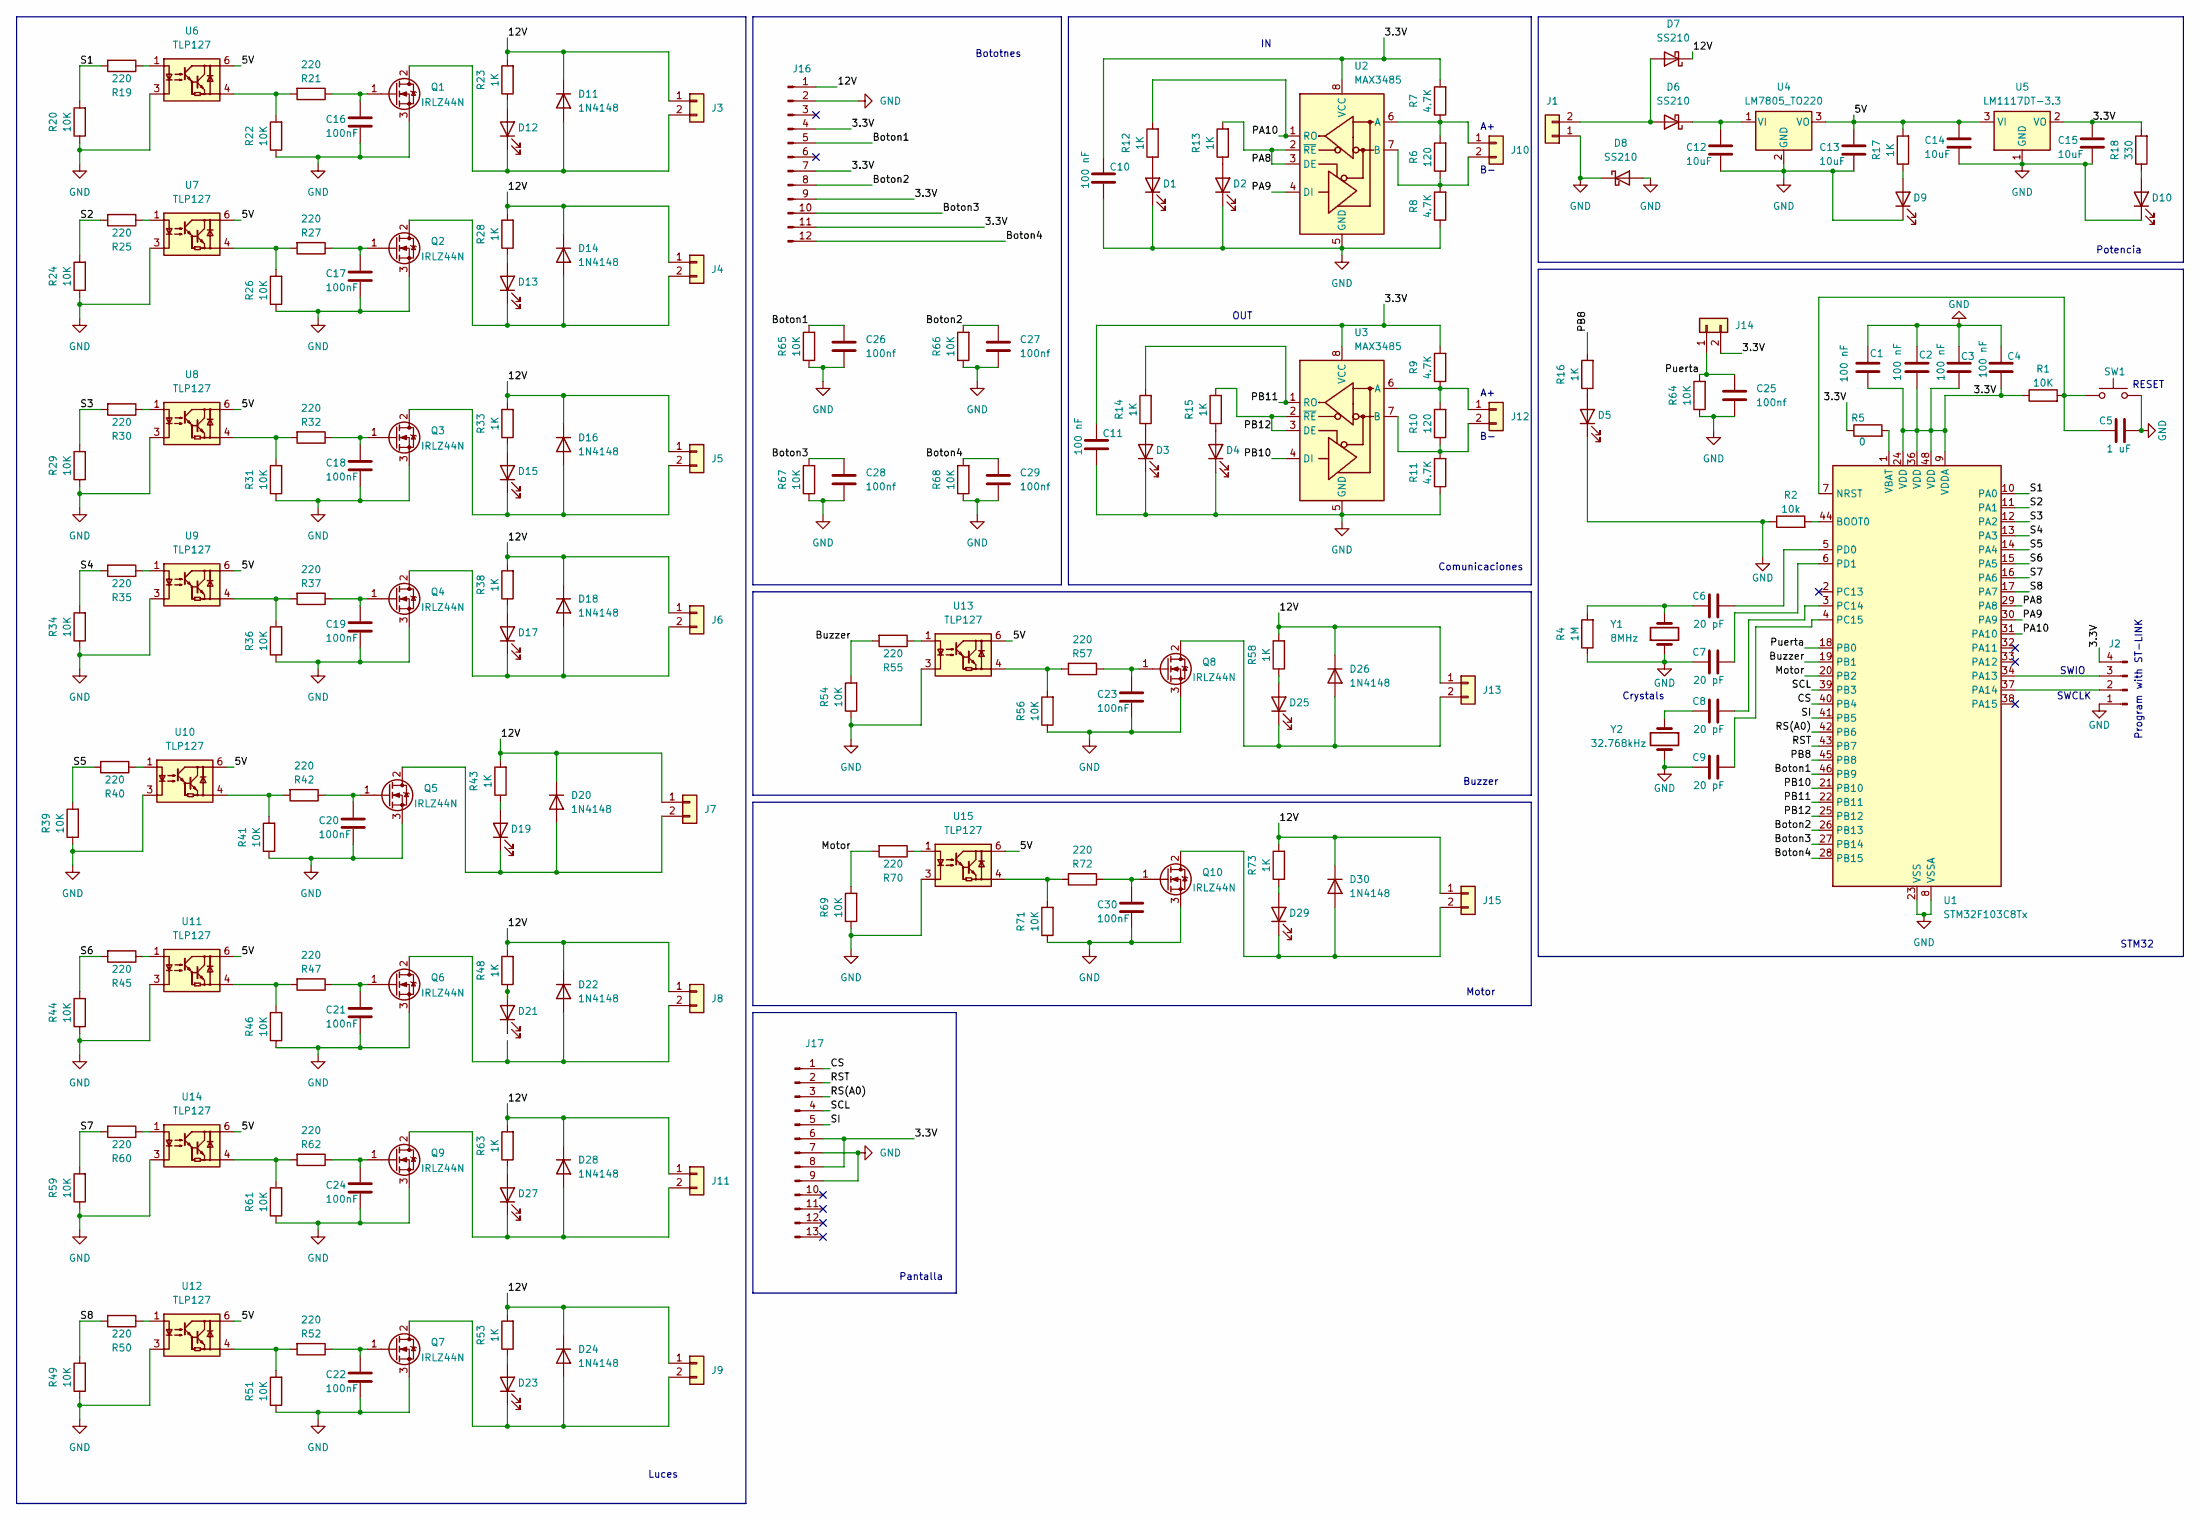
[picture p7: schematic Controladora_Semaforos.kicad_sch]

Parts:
C1, C2, C3, C4, C10, C11: 100 nF; C_0805_2012Metric_Pad1.18x1.45mm_HandSolder
C5: 1 uF; C_0805_2012Metric_Pad1.18x1.45mm_HandSolder
C6, C7, C8, C9: 20 pF; C_0805_2012Metric_Pad1.18x1.45mm_HandSolder
C12, C13, C14, C15: 10uF; C_0805_2012Metric_Pad1.18x1.45mm_HandSolder
C16, C17, C18, C19, C20, C21, C22, C23, C24, C30: 100nF; C_0805_2012Metric_Pad1.18x1.45mm_HandSolder
C25, C26, C27, C28, C29: 100nf; C_0805_2012Metric_Pad1.18x1.45mm_HandSolder
D1, D2, D3, D4, D5, D9, D10, D12, D13, D15, D17, D19, D21, D23, D25, D27, D29: LED; LED_1206_3216Metric_Pad1.42x1.75mm_HandSolder
D6, D7, D8: SS210; D_SMA
D11, D14, D16, D18, D20, D22, D24, D26, D28, D30: 1N4148; D_DO-35_SOD27_P7.62mm_Horizontal
J1, J3, J4, J5, J6, J7, J8, J9, J11, J13, J15: Conn_01x02; TerminalBlock_Phoenix_MKDS-1,5-2_1x02_P5.00mm_Horizontal
J2: Conn_01x04_Pin; PinHeader_1x04_P2.54mm_Vertical
J10, J12, J14: Conn_01x02; Molex_KK-254_AE-6410-02A_1x02_P2.54mm_Vertical
J16: Conn_01x12_Pin; Molex_KK-254_AE-6410-16A_1x16_P2.54mm_Vertical
J17: Conn_01x13_Pin; Molex_KK-254_AE-6410-16A_1x16_P2.54mm_Vertical
Q1, Q2, Q3, Q4, Q5, Q6, Q7, Q8, Q9, Q10: IRLZ44N; TO-220-3_Vertical
R1, R20, R22, R24, R26, R29, R31, R34, R36, R39, R41, R44, R46, R49, R51, R54, R56, R59, R61, R64, R65, R66, R67, R68, R69, R71: 10K; R_0805_2012Metric_Pad1.20x1.40mm_HandSolder
R2: 10k; R_0805_2012Metric_Pad1.20x1.40mm_HandSolder
R4: 1M; R_0805_2012Metric_Pad1.20x1.40mm_HandSolder
R5: 0; R_0805_2012Metric_Pad1.20x1.40mm_HandSolder
R6, R10: 120; R_0805_2012Metric_Pad1.20x1.40mm_HandSolder
R7, R8, R9, R11: 4.7K; R_0805_2012Metric_Pad1.20x1.40mm_HandSolder
R12, R13, R14, R15, R16, R17, R23, R28, R33, R38, R43, R48, R53, R58, R63, R73: 1K; R_0805_2012Metric_Pad1.20x1.40mm_HandSolder
R18: 330; R_0805_2012Metric_Pad1.20x1.40mm_HandSolder
R19, R21, R25, R27, R30, R32, R35, R37, R40, R42, R45, R47, R50, R52, R55, R57, R60, R62, R70, R72: 220; R_0805_2012Metric_Pad1.20x1.40mm_HandSolder
SW1: SW_Omron_B3FS; SW_SPST_Omron_B3FS-100xP
U1: STM32F103C8Tx; LQFP-48_7x7mm_P0.5mm
U2, U3: MAX3485; SOIC-8_3.9x4.9mm_P1.27mm
U4: LM7805_TO220; TO-220-3_Vertical
U5: LM1117DT-3.3; TO-252-3_TabPin2
U6, U7, U8, U9, U10, U11, U12, U13, U14, U15: TLP127; Toshiba_SOIC-4-6_4.4x3.6mm_P1.27mm
Y1: 8MHz; Crystal_HC49-U_Vertical
Y2: 32.768kHz; Crystal_DS10_D1.0mm_L4.3mm_Horizontal

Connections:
/3.3V: C1.2, C2.2, C3.2, C4.2, C10.1, C11.1, C15.1, J2.4, J14.2, J16.4, J16.7, J16.9, J16.11, J17.6, J17.8, R1.1, R5.1, R7.2, R9.2, R18.2, U1.9 (VDDA), U1.24 (VDD), U1.36 (VDD), U1.48 (VDD), U2.8 (VCC), U3.8 (VCC), U5.2 (VO)
/5V: C13.1, C14.1, R17.2, U4.3 (VO), U5.3 (VI), U6.6, U7.6, U8.6, U9.6, U10.6, U11.6, U12.6, U13.6, U14.6, U15.6
/12V: D7.1 (K), D11.1 (K), D14.1 (K), D16.1 (K), D18.1 (K), D20.1 (K), D22.1 (K), D24.1 (K), D26.1 (K), D28.1 (K), D30.1 (K), J3.1, J4.1, J5.1, J6.1, J7.1, J8.1, J9.1, J11.1, J13.1, J15.1, J16.1, R23.2, R28.2, R33.2, R38.2, R43.2, R48.2, R53.2, R58.2, R63.2, R73.2
/Boton1: C26.1, J16.5, R65.2, U1.46 (PB9)
/Boton2: C27.1, J16.8, R66.2, U1.26 (PB13)
/Boton3: C28.1, J16.10, R67.2, U1.27 (PB14)
/Boton4: C29.1, J16.12, R68.2, U1.28 (PB15)
/Buzzer: R54.2, R55.2, U1.19 (PB1)
/CS: J17.1, U1.40 (PB4)
/Motor: R69.2, R70.2, U1.20 (PB2)
/PA8: R13.2, U1.29 (PA8), U2.2 (~RE), U2.3 (DE)
/PA9: U1.30 (PA9), U2.4 (DI)
/PA10: R12.2, U1.31 (PA10), U2.1 (RO)
/PB8: R16.2, U1.45 (PB8)
/PB10: U1.21 (PB10), U3.4 (DI)
/PB11: R14.2, U1.22 (PB11), U3.1 (RO)
/PB12: R15.2, U1.25 (PB12), U3.2 (~RE), U3.3 (DE)
/Puerta: C25.1, J14.1, R64.2, U1.18 (PB0)
/RS(A0): J17.3, U1.42 (PB6)
/RST: J17.2, U1.43 (PB7)
/S1: R19.2, R20.2, U1.10 (PA0)
/S2: R24.2, R25.2, U1.11 (PA1)
/S3: R29.2, R30.2, U1.12 (PA2)
/S4: R34.2, R35.2, U1.13 (PA3)
/S5: R39.2, R40.2, U1.14 (PA4)
/S6: R44.2, R45.2, U1.15 (PA5)
/S7: R59.2, R60.2, U1.16 (PA6)
/S8: R49.2, R50.2, U1.17 (PA7)
/SCL: J17.4, U1.39 (PB3)
/SI: J17.5, U1.41 (PB5)
GND: C1.1, C2.1, C3.1, C4.1, C5.2, C7.1, C9.1, C10.2, C11.2, C12.2, C13.2, C14.2, C15.2, C16.2, C17.2, C18.2, C19.2, C20.2, C21.2, C22.2, C23.2, C24.2, C25.2, C26.2, C27.2, C28.2, C29.2, C30.2, D1.1 (K), D2.1 (K), D3.1 (K), D4.1 (K), D5.1 (K), D8.1 (K), D8.2 (A), D9.1 (K), D10.1 (K), J1.1, J2.1, J16.2, J17.7, J17.9, Q1.3 (S), Q2.3 (S), Q3.3 (S), Q4.3 (S), Q5.3 (S), Q6.3 (S), Q7.3 (S), Q8.3 (S), Q9.3 (S), Q10.3 (S), R2.1, R4.1, R8.1, R11.1, R20.1, R22.1, R24.1, R26.1, R29.1, R31.1, R34.1, R36.1, R39.1, R41.1, R44.1, R46.1, R49.1, R51.1, R54.1, R56.1, R59.1, R61.1, R64.1, R65.1, R66.1, R67.1, R68.1, R69.1, R71.1, SW1.2, U1.8 (VSSA), U1.23 (VSS), U1.35 (VSS), U1.47 (VSS), U2.5 (GND), U3.5 (GND), U4.2 (GND), U5.1 (GND), U6.3, U7.3, U8.3, U9.3, U10.3, U11.3, U12.3, U13.3, U14.3, U15.3, Y1.1, Y2.2
unnamed: C6.1, R4.2, Y1.2
unnamed: C8.1, Y2.1
unnamed: D1.2 (A), R12.1
unnamed: D2.2 (A), R13.1
unnamed: D3.2 (A), R14.1
unnamed: D4.2 (A), R15.1
unnamed: D5.2 (A), R16.1
unnamed: D6.2 (A), D7.2 (A), J1.2
unnamed: C12.1, D6.1 (K), U4.1 (VI)
unnamed: D9.2 (A), R17.1
unnamed: D10.2 (A), R18.1
unnamed: D11.2 (A), D12.1 (K), J3.2, Q1.2 (D)
unnamed: D12.2 (A), R23.1
unnamed: D13.2 (A), R28.1
unnamed: D13.1 (K), D14.2 (A), J4.2, Q2.2 (D)
unnamed: D15.2 (A), R33.1
unnamed: D15.1 (K), D16.2 (A), J5.2, Q3.2 (D)
unnamed: D17.2 (A), R38.1
unnamed: D17.1 (K), D18.2 (A), J6.2, Q4.2 (D)
unnamed: D19.2 (A), R43.1
unnamed: D19.1 (K), D20.2 (A), J7.2, Q5.2 (D)
unnamed: D21.2 (A), R48.1
unnamed: D22.2 (A), J8.2, Q6.2 (D)
unnamed: D23.2 (A), R53.1
unnamed: D23.1 (K), D24.2 (A), J9.2, Q7.2 (D)
unnamed: D25.2 (A), R58.1
unnamed: D25.1 (K), D26.2 (A), J13.2, Q8.2 (D)
unnamed: D27.2 (A), R63.1
unnamed: D27.1 (K), D28.2 (A), J11.2, Q9.2 (D)
unnamed: D29.2 (A), R73.1
unnamed: D29.1 (K), D30.2 (A), J15.2, Q10.2 (D)
unnamed: J2.2, U1.37 (PA14)
unnamed: J2.3, U1.34 (PA13)
unnamed: J10.1, R6.2, R7.1, U2.6 (A)
unnamed: J10.2, R6.1, R8.2, U2.7 (B)
unnamed: J12.1, R9.1, R10.2, U3.6 (A)
unnamed: J12.2, R10.1, R11.2, U3.7 (B)
unnamed: C16.1, Q1.1 (G), R21.1
unnamed: C17.1, Q2.1 (G), R27.1
unnamed: C18.1, Q3.1 (G), R32.1
unnamed: C19.1, Q4.1 (G), R37.1
unnamed: C20.1, Q5.1 (G), R42.1
unnamed: C21.1, Q6.1 (G), R47.1
unnamed: C22.1, Q7.1 (G), R52.1
unnamed: C23.1, Q8.1 (G), R57.1
unnamed: C24.1, Q9.1 (G), R62.1
unnamed: C30.1, Q10.1 (G), R72.1
unnamed: R19.1, U6.1
unnamed: R21.2, R22.2, U6.4
unnamed: R25.1, U7.1
unnamed: R26.2, R27.2, U7.4
unnamed: R30.1, U8.1
unnamed: R31.2, R32.2, U8.4
unnamed: R35.1, U9.1
unnamed: R36.2, R37.2, U9.4
unnamed: R40.1, U10.1
unnamed: R41.2, R42.2, U10.4
unnamed: R45.1, U11.1
unnamed: R46.2, R47.2, U11.4
unnamed: R50.1, U12.1
unnamed: R51.2, R52.2, U12.4
unnamed: R55.1, U13.1
unnamed: R56.2, R57.2, U13.4
unnamed: R60.1, U14.1
unnamed: R61.2, R62.2, U14.4
unnamed: R70.1, U15.1
unnamed: R71.2, R72.2, U15.4
unnamed: R2.2, U1.44 (BOOT0)
unnamed: C5.1, R1.2, SW1.1, U1.7 (NRST)
unnamed: C8.2, U1.3 (PC14)
unnamed: C9.2, U1.4 (PC15)
unnamed: C6.2, U1.5 (PD0)
unnamed: C7.2, U1.6 (PD1)
unnamed: R5.2, U1.1 (VBAT)

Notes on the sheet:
Potencia
STM32
OUT
RESET
Bototnes
Crystals
Luces
Pantalla
Comunicaciones
SWCLK
Buzzer
SWIO
Motor
Program with ST-LINK

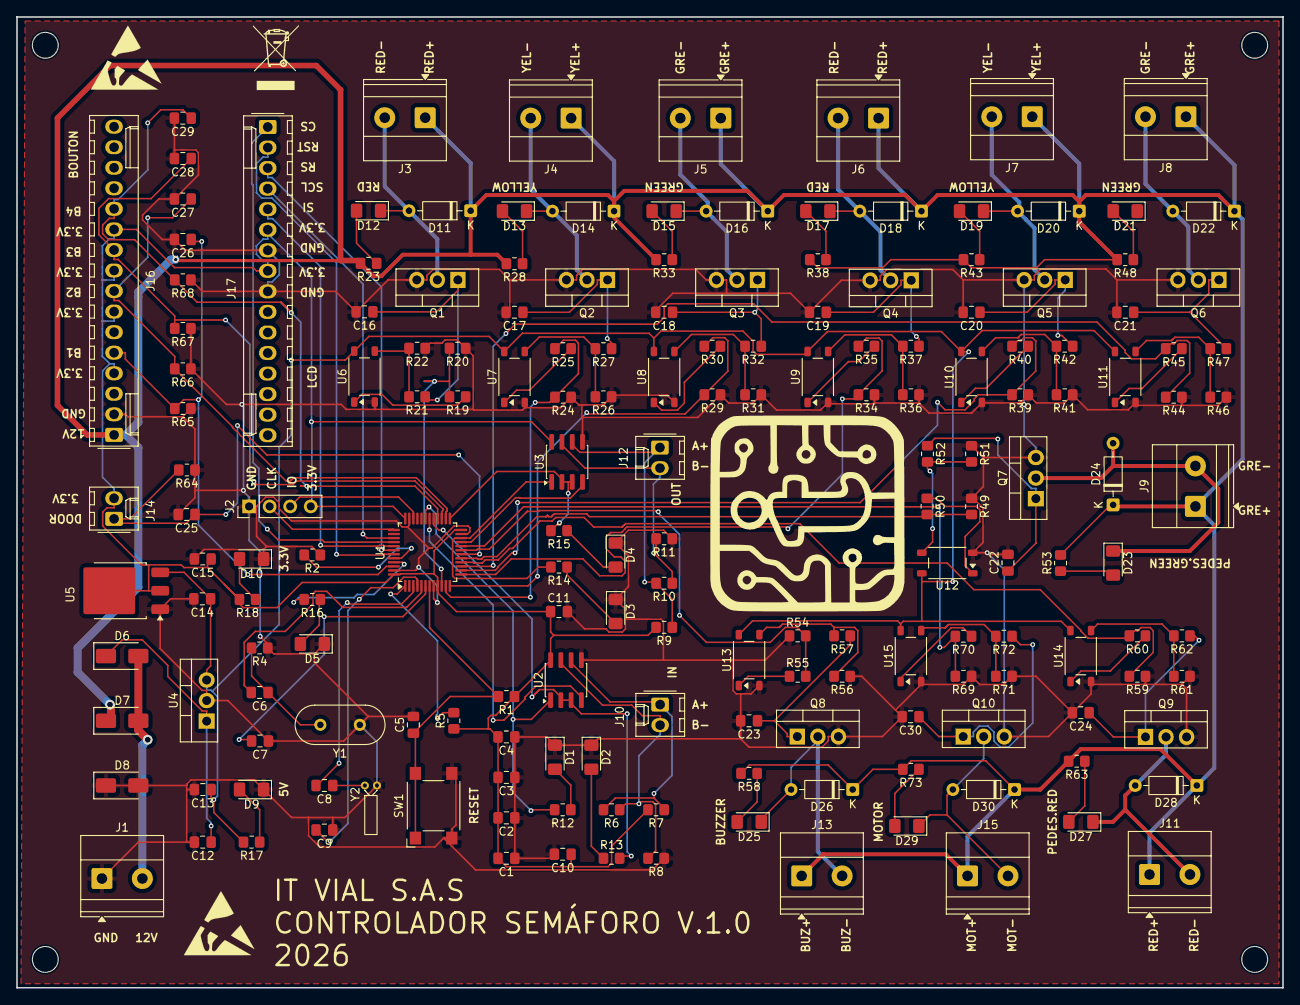
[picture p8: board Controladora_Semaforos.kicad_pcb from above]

Board: 2 copper layers, 156.5 x 120.0 mm, 184 parts (0 on the bottom side), 105 nets.

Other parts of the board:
H1, H2, H3, H4: MountingHole_3.2mm_M3_DIN965
V1, V2: ESD-Logo_8.9x8mm_SilkScreen
V3: WEEE-Logo_5.6x8mm_SilkScreen

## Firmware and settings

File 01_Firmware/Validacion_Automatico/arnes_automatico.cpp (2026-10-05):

// ===== 01_Firmware/Validacion_Automatico/arnes_automatico.cpp =====
//
// coordinador.cpp + semaforo.cpp + modo_automatico.cpp REALES, compilados y ejecutados en
// el PC. La regresion "el Automatico no arranca el ciclo" paso con todo en verde porque
// ningun instrumento ejercia el ciclo sobre el C++ real: los modelos en Python prueban el
// modelo, no el codigo. Molde de Validacion_Ciclo (el .h/.cpp REAL, sin espejo), un nivel
// mas arriba: tres modulos con estado, con un Esclavo simulado que contesta al protocolo,
// un reloj que mueve el arnes y botones que pulsa el arnes. Lo medido se compila tal cual.
//
// QUE NO CUBRE: solo el lado MAESTRO; "verde simultaneo en las dos puntas" es de
// Validacion_Ciclo y del arnes de las dos puntas. Aqui: que el Maestro LLEGA a dar verde,
// lo suelta al tiempo configurado, no salta el amarillo y ante una respuesta ausente o
// incorrecta cae al estado seguro.
//
// A-12: modo_inteligente.cpp y demanda.cpp REALES (Bloque E): "con las camaras muertas se
// comporta EXACTAMENTE como el Automatico" es comportamiento, y se mide corriendo los dos
// modos con la MISMA configuracion. NO CUBRE: la camara es un bool del arnes; el
// antirrebote vive en botones.cpp (no compilado) y el cableado de J16 es cobre.
//
#include <cstdio>
#include <cstdlib>
#include <cstring>
#include <cinttypes>
#include <string>
#include <vector>
#include <fstream>
#include <sstream>
#include <regex>

#include "Arduino.h"
#include "pines.h"
#include "botones.h"
#include "menu.h"
#include "modos.h"   // D-44: lo traia el sustituto de menu.h, que salio

#include "coordinador.h"
#include "semaforo.h"
#include "modo_automatico.h"
#include "protocolo.h"
#include "reloj.h"
#include "respaldo.h"
#include "modo_inteligente.h" // A-12: real, y su .cpp SI se compila (Bloque E)
#include "demanda.h"          // A-12: real, y su .cpp tambien -- entra en el OR

// ---------------------------------------------------------------------------
// EL RELOJ SIMULADO Y LOS PINES OBSERVADOS. Los declara extern Arduino.h; existen
// aqui porque el arnes es quien los mueve.
// ---------------------------------------------------------------------------
unsigned long arnes_millis_valor = 0;
int arnes_pines[64];
unsigned long arnes_escrituras = 0;
// Cuanto tiempo de delay() pidio el firmware. No mueve el reloj (ver Arduino.h);
// se acumula para poder DECIR cuanto no se esta modelando, en vez de callarlo.
unsigned long arnes_delays = 0;

// ---------------------------------------------------------------------------
// LECTURA DE CONSTANTES DEL C++ REAL. Mismo contrato que
// Simulaciones/banco/fuente.py::constante(): sin el patron no hay numero, y sin
// numero el arnes ABORTA -nunca cae a un valor escrito a mano que "casualmente
// coincide" con lo que el firmware tenia la ultima vez que alguien miro-.
// ---------------------------------------------------------------------------

static std::string dirDeEsteArchivo() {
  std::string f = __FILE__;
  size_t p = f.find_last_of("/\\");
  return (p == std::string::npos) ? std::string(".") : f.substr(0, p);
}

// Maestro/src e include/, resueltas desde ESTE fichero (el arnes se invoca desde cualquier
// sitio). N-137: los limites del ciclo viven en include/limites_ciclo.h; rutaDe() elige por
// extension (.h a include/, .cpp a src/).
static const std::string MAESTRO_SRC = dirDeEsteArchivo() + "/../Maestro/src/";
static const std::string MAESTRO_INC = dirDeEsteArchivo() + "/../Maestro/include/";
static std::string rutaDe(const std::string& archivo) {
  return (archivo.size() > 2 && archivo.substr(archivo.size() - 2) == ".h")
           ? MAESTRO_INC + archivo : MAESTRO_SRC + archivo;
}

static void abortar(const std::string& motivo) {
  std::fprintf(stdout, "\n[ABORTADO] %s\n", motivo.c_str());
  std::fprintf(stdout,
      "Sin esa constante el arnes mediria otra cosa que el firmware, y seguiria\n"
      "dando un veredicto aunque ya no describa el C++ real. Regla del banco:\n"
      "sin valor por defecto, nunca.\n");
  std::exit(2);
}

static std::string leerArchivoFuente(const std::string& nombre) {
  std::string ruta = rutaDe(nombre);   // N-137: .h en include/, .cpp en src/
  std::ifstream f(ruta.c_str());
  if (!f) abortar("no se pudo abrir el fuente real " + ruta);
  std::ostringstream ss;
  ss << f.rdbuf();
  return ss.str();
}

// Todas las apariciones del patron (con exactamente un grupo de captura numerico).
// ABORTA si no hay ninguna.
static std::vector<long> leerConstantesTodas(const std::string& archivo,
                                              const std::string& patron,
                                              const std::string& que) {
  std::string txt = leerArchivoFuente(archivo);
  std::regex re(patron);
  std::vector<long> valores;
  for (std::sregex_iterator it(txt.begin(), txt.end(), re), fin; it != fin; ++it) {
    valores.push_back(std::strtol((*it)[1].str().c_str(), nullptr, 10));
  }
  if (valores.empty()) {
    abortar("no se pudo leer del C++ real la constante de " + que +
            " (patron no encontrado en " + archivo + ")");
  }
  return valores;
}

// La primera aparicion, para las constantes que solo se escriben una vez.
static long leerConstante(const std::string& archivo, const std::string& patron,
                           const std::string& que) {
  return leerConstantesTodas(archivo, patron, que)[0];
}

// ---------------------------------------------------------------------------
// EL CONTADOR DE COMPROBACIONES. Mismo patron que Validacion_Ciclo/arnes_ciclo.cpp.
// ---------------------------------------------------------------------------
static int total = 0, fallos = 0;

static void comprobar(bool ok, const char* que) {
  total++;
  if (ok) {
    std::printf("   [OK]    %s\n", que);
  } else {
    fallos++;
    std::printf("   [FALLA] %s\n", que);
  }
}

// ---------------------------------------------------------------------------
// SFTY-2, VIGILADO DE BALDE: con digitalWrite() grabando en arnes_pines[], cada barrido
// comprueba sobre lo que escribirPines() ESCRIBIO que Rojo y Verde nunca coinciden en la
// misma cara (barrera de salidas, medida y no supuesta).
// ---------------------------------------------------------------------------
static long violacionesEnclavamiento = 0;

// SFTY-28: CON LA PLUMA ARRIBA TIENE QUE HABER VERDE ENCENDIDO -o S_FALLO-. Al reves no se
// exige (verde con pluma abajo es feo, no peligroso); lo que mata es una barrera levantada
// con la luz en rojo. LA EXCEPCION DE S_FALLO VA POR NOMBRE (politica del cliente, 27/08:
// sin enlace se deja pasar con precaucion), y no relajando a "solo cuando hay rojo": asi
// una pluma abierta en CUALQUIER otro estado se sigue cazando.
static long violacionesTalanquera = 0;

// D-33 - EL REPARTO DE ESA INVARIANTE (CLAUDE.md 9):
//   1. "la pluma arriba SIEMPRE tiene una razon nombrada"  -> SE CONSERVA (de dos a cuatro).
//   2. "esa razon es el verde encendido"                    -> SE REPARTE: fuera de la
//      ventana de bajada igual; dentro, el retardo de D-33 y el veto, cada uno con su cota.
//   3. "la unica excepcion nombrada es S_FALLO"             -> SE CONSERVA LITERAL.
// LAS RAZONES NUEVAS SE MIDEN (CLAUDE.md 6). EL RETARDO se CRONOMETRA contra
// PLUMA_RETARDO_BAJADA_MS leido del C++, sin preguntar al firmware. EL VETO se cruza con la
// otra funcion real: si semaforo_plumaVetada(), camara_presenciaJ16() tambien; un veto
// pegado sin nadie debajo dejaria la pluma arriba para siempre.
static long vetoSinPresencia = 0;
static unsigned long g_plumaSinVerdeDesde = 0;   // 0 = no hay ventana abierta
static unsigned long g_peorVentanaPlumaMs = 0;     // la mas larga, sea cual sea la razon
static unsigned long g_peorVentanaSinVetoMs = 0;  // la mas larga con el veto SUELTO
static unsigned long g_ventanasPluma = 0;
static unsigned long g_retardoPlumaMs = 0;       // leido del C++ al principio de main()

// EL MARGEN DEL RETARDO ES DEL ARNES, NO DEL FIRMWARE (re-derivado con D-30, CLAUDE.md 7 y
// 14). El retardo se suelta en la siguiente entrada por escribirPines(), y semaforo_
// actualizar() la hace en cada vuelta ("if (plumaCierrePendiente) aplicarSalidas(...)"):
// el firmware no anade retraso, y lo unico que alarga la ventana OBSERVADA es el paso de
// bombeo entre dos vigilarEnclavamiento(). Por eso no se lee del C++. Vale el mayor paso con
// una ventana SIN VETO abierta: A-C a 200 ms, G a PASO_G = 100 ms (las ventanas del Bloque F
// las sostiene el veto y las mide g_peorVentanaPlumaMs, sin tope). La peor ventana sin veto
// sale en el RESUMEN; si rebasa el margen, FALLA en vez de ensancharse.
static const unsigned long MARGEN_MUESTREO_MS = 200;
static unsigned long g_margenSenalMs = MARGEN_MUESTREO_MS;

// N-153: EL CAMPO PLUMA DEL $STATUS (semaforo_plumaArriba()) TIENE QUE SER EL PIN. Un getter
// desincronizado no rompe ninguna luz y ningun pack de texto lo ve; se pregunta al getter en
// el MISMO tick en que se lee el pin. Se compara contra el pin, no contra la formula: una
// tercera copia de SFTY-28 es lo que el campo evita.
static long discrepanciasPluma = 0;

// D-53 (05/10): ROJO - ROJO+AMARILLO (2 s) - VERDE. Manual de Senalizacion Vial 4.4.2 y
// Fig. 4-9. Viene de la DECISION, no del fuente: leida de protocolo.h, sin la constante el
// arnes ABORTARIA en vez de dar ROJO. Cambiarla cuesta dos ediciones (CLAUDE.md 15).
static const unsigned long RA_MS = 2000UL;

// D-53: EL VIGILANTE DE LA APERTURA, sobre los PINES de la cara 1 y en cada tick. Cuenta
// cada encendido del verde y exige que el tick anterior fuera ROJO+AMARILLO (verde OFF).
// La duracion se acota por las dos puntas con lo que el muestreo permite saber sin
// inventar: la ventana EXTERIOR (ultimo tick sin R+A -> primer verde) no puede ser menor
// que RA_MS, y la INTERIOR (primer tick R+A -> ultimo tick R+A) no puede ser mayor. Ningun
// muestreo da un falso rojo con estas dos; el milisegundo exacto lo mide el bloque A.
// La pluma no SUBE en R+A; si viene arriba baja en PLUMA_RETARDO_BAJADA_MS desde el primer tick
// sin luz que la pida (verde, S_FALLO, S_AMARILLO), salvo veto vivo (SPEC_1 3.3 (7)), como SFTY-28.
static unsigned long g_verdesVistos = 0, g_verdesSinRA = 0, g_raMalMedido = 0;
static unsigned long g_plumaEnRA = 0, g_raVistos = 0, g_plumaRAFueraCota = 0, g_tBajadaDesde = 0;
static bool g_prevRA = false, g_prevV = false, g_prevPluma = false;
static unsigned long g_tPrevMuestra = 0, g_tAntesDeRA = 0, g_tRAPrimera = 0, g_tRAUltima = 0;

static bool g_aperturaEnPausa = false;   // los controles negativos falsean pines

static void vigilarApertura() {
  if (g_aperturaEnPausa) return;
  const unsigned long ahora = arnes_millis_valor;
  const bool r = arnes_pines[ROJO1] == HIGH, a = arnes_pines[AMARILLO1] == HIGH;
  const bool v = arnes_pines[VERDE1] == HIGH;
  const bool ra = r && a && !v, pl = arnes_pines[MOTOR_TALANQUERA] == TALANQUERA_ABRIR;
  if (!pl || v || semaforo_estado() == S_FALLO || semaforo_estado() == S_AMARILLO) g_tBajadaDesde = 0;
  else if (g_tBajadaDesde == 0) g_tBajadaDesde = ahora + 1;   // 0 = sin bajada pendiente
  if (ra && !g_prevRA) { g_tAntesDeRA = g_tPrevMuestra; g_tRAPrimera = ahora; g_raVistos++; }
  if (ra) {
    g_tRAUltima = ahora;
    if (pl && !g_prevPluma) g_plumaEnRA++;   // una SUBIDA abajo->arriba en R+A
    if (pl && ahora + 1 - g_tBajadaDesde > g_retardoPlumaMs + g_margenSenalMs &&
        !(semaforo_plumaVetada() && camara_presenciaJ16())) g_plumaRAFueraCota++;
  }
  if (v && !g_prevV) {
    g_verdesVistos++;
    if (!g_prevRA) {
      g_verdesSinRA++;
    } else if (ahora - g_tAntesDeRA < RA_MS || g_tRAUltima - g_tRAPrimera > RA_MS) {
      g_raMalMedido++;
    }
  }
  g_prevRA = ra;
  g_prevV = v;
  g_prevPluma = pl;
  g_tPrevMuestra = ahora;
}
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
int main() {
  std::printf("==============================================================\n");
  std::printf(" ARNES DEL CICLO AUTOMATICO - coordinador.cpp + semaforo.cpp +\n");
  std::printf(" modo_automatico.cpp + modo_inteligente.cpp + botones.cpp REALES,\n");
  std::printf(" compilados y ejecutados en el PC (Bloque E / A-12: el Modo\n");
  std::printf(" Inteligente contra el Automatico; Bloque F/G: camaras y pluma)\n");
  std::printf("==============================================================\n");

  // -------------------------------------------------------------------------
  // Constantes releidas del C++ real. Ni una se escribe a mano: si el patron no
  // aparece, el arnes ABORTA antes de comprobar nada (ver leerConstante()).
  // -------------------------------------------------------------------------
  // D-33: ESTA VA LA PRIMERA: vigilarEnclavamiento() y vigilarApertura() la usan desde el
  // primer tick; leida despues, compararian contra un cero y acusarian al firmware.
  g_retardoPlumaMs = (unsigned long)leerConstante("semaforo.cpp",
      R"(PLUMA_RETARDO_BAJADA_MS\s*=\s*(\d+)UL)",
      "el retardo con el que la pluma baja DESPUES del rojo (D-33)");


  // D-45: el amarillo de cierre, en segundos y en el contrato de las dos puntas.
  long AMBAR_MS = 1000L * leerConstante("../include/protocolo.h",
      R"(#define\s+AMARILLO_SEG\s+(\d+)UL)",
      "el amarillo de cierre Verde->Rojo (D-45, AMARILLO_SEG)");

  long FALLO_PERIODO_MS = leerConstante("semaforo.cpp",
      R"(S_FALLO\)\s*\{\s*if\s*\(ahora\s*-\s*tCambio\s*>=\s*(\d+)\))",
      "el periodo del ambar intermitente de fallo");

  // N-69: el umbral se mudo al contrato compartido (protocolo.h) para que las dos
  // puntas no puedan divergir. Este arnes ABORTO el dia del cambio en vez de seguir
  // midiendo el numero viejo, que es lo que se le pide.
  long ORFANDAD_MS = leerConstante("../include/protocolo.h",
      R"(#define\s+SFTY6_SILENCIO_MS\s+(\d+)UL)",
      "el timeout de orfandad (SFTY-6)");

  long TIMEOUT_ACK_MS = leerConstante("coordinador.cpp",
      R"(TIMEOUT_ACK_MS\s*=\s*(\d+))",
      "el timeout de reintento de ACK (SFTY-7)");

  std::vector<long> reintentos = leerConstantesTodas("coordinador.cpp",
      R"(CICLO_MAX_REINTENTOS\s*=\s*(\d+))",
      "el numero de reintentos del ciclo antes de C_FALLO");

  // LOS VALORES POR DEFECTO YA NO SON LITERALES, Y ESO ES EL ARREGLO (N-131, 04/09).
  //
  // Aqui se leian tres numeros escritos a mano en el inicializador:
  //     static int minRojo = 1, minVerde = 1, segEstatico = 15;
  // El 04/09 se descubrio que ese "1" convertia la guarda de 3 minutos en media
  // guarda -solo la cruzaba SET_TIEMPOS- y los defectos pasaron a salir de las MISMAS
  // constantes que el limite. Este arnes ABORTO en la primera corrida siguiente, que
  // es exactamente su trabajo: leia por patron literal y el patron dejo de existir
  // (CLAUDE.md §5). Un ABORTADO grita; lo que no se puede permitir es que siguiera
  // dando veredicto sobre un firmware que ya no describe.
  //
  // Ahora se leen las constantes por nombre. Sin valor por defecto, igual que antes:
  // si alguien las renombra, esto vuelve a ABORTAR en vez de medir otra cosa.
  long MIN_ROJO_DEFECTO = leerConstante("limites_ciclo.h",
      R"(ROJO_MIN_MIN\s*=\s*(\d+))",
      "el minimo de rojo, que es tambien el valor de arranque del asistente");
  long MIN_VERDE_DEFECTO = leerConstante("limites_ciclo.h",
      R"(VERDE_MIN_MIN\s*=\s*(\d+))",
      "el minimo de verde, que es tambien el valor de arranque del asistente");
  long SEG_ESTATICO_DEFECTO = leerConstante("limites_ciclo.h",
      R"(DESPEJE_SEG_MIN\s*=\s*(\d+))",
      "el despeje All-Red minimo, que es tambien el de arranque");
  (void)MIN_ROJO_DEFECTO;

  std::printf("\nConstantes releidas del C++ real (Maestro/src), no escritas a mano:\n");
  std::printf("   amarillo de cierre (D-45) ...... %ld ms\n", AMBAR_MS);
  std::printf("   periodo del ambar de fallo ..... %ld ms\n", FALLO_PERIODO_MS);
  std::printf("   orfandad (SFTY-6) .............. %ld ms\n", ORFANDAD_MS);
  std::printf("   timeout de ACK (SFTY-7) ........ %ld ms\n", TIMEOUT_ACK_MS);
  std::printf("   despeje por defecto del asistente %ld s\n", SEG_ESTATICO_DEFECTO);
  std::printf("   minutos de verde por defecto .... %ld min\n", MIN_VERDE_DEFECTO);

  // N-71: ESTA COMPROBACION SE INVIRTIO, Y CONVIENE SABER POR QUE.
  //
  // Exigia encontrar DOS literales iguales -"retryCount >= 5" en la rama verde y en la
  // roja- porque el numero estaba escrito dos veces y podian divergir. Al darle nombre
  // (CICLO_MAX_REINTENTOS) esa duplicidad desaparece, y con ella el defecto que la
  // comprobacion vigilaba: ya no se puede cambiar una rama y olvidar la otra.
  //
  // Pero eliminarla sin mas dejaria un hueco: una sola declaracion no sirve de nada si
  // alguna rama sigue con su literal. Asi que ahora se exige lo contrario y mas fuerte:
  // UNA sola declaracion, y las DOS ramas usandola por nombre.
  int usosPorNombre = 0;
  {
    const std::string src = leerArchivoFuente("coordinador.cpp");
    std::size_t pos = 0;
    while ((pos = src.find("retryCount >= CICLO_MAX_REINTENTOS", pos)) != std::string::npos) {
      usosPorNombre++;
      pos++;
    }
  }
  comprobar(reintentos.size() == 1 && usosPorNombre == 2,
            "el numero de reintentos se declara UNA vez y las DOS ramas (verde y roja) "
            "lo usan por nombre: ya no hay dos literales que puedan divergir");
  long MAX_REINTENTOS = reintentos[0];

  unsigned long SEG_ESTATICO_MS = (unsigned long)SEG_ESTATICO_DEFECTO * 1000UL;
  // 60000 = ms por minuto. Es aritmetica de unidades, identica en el firmware y
  // aqui por definicion -no es una politica que el firmware pueda decidir cambiar
  // sin que deje de ser "minutos"-, asi que no se relee por regex como las demas.
  unsigned long MIN_VERDE_MS = (unsigned long)MIN_VERDE_DEFECTO * 60000UL;

  // D-30 (14/09): AQUI SE LEIAN LAS DIEZ CONSTANTES DE LA SENAL DEL MANDO.
  //
  // DESTELLO_ON_MS / DESTELLO_OFF_MS / AMBAR_RAPIDO_PERIODO_MS de semaforo.cpp y
  // DESTELLOS_AUTOMATICO / _AMBAR / _DEGRADADO, VENTANA_TRIPLE_MS, VENTANA_CUADRUPLE_MS
  // y RECHAZO_AMBAR_MS de mando.cpp, mas el PRESUPUESTO_SENAL_MS que se derivaba de
  // ellas. Ninguna existe ya en el firmware: las tres primeras salieron de semaforo.cpp
  // con la interceptacion y el resto con el fichero entero. Se retiran en vez de
  // quedarse con un valor por defecto, que es lo que leerConstante() prohibe.

  // ===========================================================================
  // BLOQUE A: semaforo.cpp EN AISLAMIENTO — SFTY-5, medido al milisegundo
  // ===========================================================================
  std::printf("\n-- Bloque A: semaforo.cpp en aislamiento (SFTY-5) --\n");
  {
    semaforo_setup();
    arnes_millis_valor = 1000000UL;   // arranca lejos de 0 a proposito
    unsigned long t0 = arnes_millis_valor;

    // D-45 (02/10): SE INVIERTE. Aqui se exigia rojo->AMARILLO->verde y verde->rojo directo,
    // que es justo lo que la norma prohibe (4.4.3). Se mira el ORDEN entero, no el final:
    // rojo -> verde directo; verde -> amarillo SOLO en la cara; el cierre no se reabre ni se
    // reinicia; rojo al vencer AMARILLO_SEG; y la pluma arriba hasta el retardo DESDE EL ROJO.
    // D-53 (05/10): SE INVIERTE OTRA VEZ, solo la apertura. "Rojo->Verde es DIRECTO" afirmaba
    // dos cosas (CLAUDE.md 9): (1) sin AMARILLO SOLO antes del verde -> SE CONSERVA (el
    // amarillo solo es cierre, D-45); (2) el verde llega en la misma llamada -> SE INVIERTE:
    // primero ROJO+AMARILLO RA_MS, verde OFF, pluma ABAJO, no estable, $STATUS "ROJO+AMAR".
    semaforo_forzarVerde();
    vigilarEnclavamiento();
    comprobar(arnes_pines[ROJO1] == HIGH && arnes_pines[AMARILLO1] == HIGH &&
              arnes_pines[VERDE1] == LOW && arnes_pines[ROJO2] == HIGH &&
              arnes_pines[AMARILLO2] == HIGH && arnes_pines[VERDE2] == LOW,
              "D-53: Rojo->Verde pasa por ROJO+AMARILLO: rojo y amarillo ENCENDIDOS y verde "
              "APAGADO en las dos caras, en la misma llamada");
    comprobar(arnes_pines[MOTOR_TALANQUERA] == TALANQUERA_CERRAR && !semaforo_plumaArriba(),
              "D-53: durante ROJO+AMARILLO la pluma NO sube (sube con el VERDE real, SPEC_8 1)");
    comprobar(!semaforo_estable(),
              "D-53: ROJO+AMARILLO no es estable: el coordinador no cuenta el verde todavia");
    comprobar(std::string(semaforo_nombreEstado()) == "ROJO+AMAR",
              "D-53: el ESTADO del $STATUS en ROJO+AMARILLO es el literal \"ROJO+AMAR\"");
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

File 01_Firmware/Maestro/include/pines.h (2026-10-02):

// ===== include/pines.h =====
#pragma once

// --- Semáforo 1 (vehicular principal) ---
#define ROJO1       PA0   // S1 -> J3
#define AMARILLO1   PA1   // S2 -> J4
#define VERDE1      PA2   // S3 -> J5

// --- Semáforo 2 (vehicular secundario) ---
#define ROJO2       PA3   // S4 -> J6
#define AMARILLO2   PA4   // S5 -> J7
#define VERDE2      PA5   // S6 -> J8

// --- Semáforo peatonal ---
#define ROJO_PEATON   PA6 // S7 -> J11
#define VERDE_PEATON  PA7 // S8 -> J9

// D-14 (13/09, decidido por el responsable en D-32 (4)): LA ENTRADA DE ALARMA DE LA
// CAMARA -el controlador cierra un contacto y la camara graba- NO SE INSTALA EN ESTE
// DESPLIEGUE. Medido sobre la guia que sigue el instalador
// (05_Funcional/Camaras_Sisga_4x.html): cablea J16 (48 menciones) y J15 (15), nombra
// J14 (9), y de J9, J11 y J13 -los tres candidatos de D-d, roadmap.md 2.4- CERO. Y solo
// cablea la SALIDA de alarma de la camara (1A/1B, hacia J16); nunca su entrada, que es
// lo que D-14 pedia.
//
// EL ANCLA VIVE AQUI PORQUE J9/J11/J13 SON LOS TRES CANDIDATOS: J9 (VERDE_PEATON,
// arriba) y J11 (ROJO_PEATON, arriba) siguen sin firmware detras (D-d), y J13 (BUZZER,
// mas abajo) tambien. NINGUNO SE GASTA PARA D-14: no hay salida de la tarjeta cableada
// hacia la entrada de alarma de la camara, y quien llegue con el destornillador no
// cablea nada ahi para esto. Si D-14 se instala algun dia, primero se elige canal
// (roadmap.md 2.4) y se escribe el codigo; hasta entonces no hay nada que construir.

// --- Actuadores ---
#define LORA_DE_RE        PB12 // Control DE/~RE del MAX3485 (bus OUT) -> E90-DTU LoRa
#define BUZZER             PB1  // -> opto U13 -> MOSFET Q8 -> bornera J13
// J15 SI EXISTE, y esta bornera es la correcta. La nota anterior decia lo contrario
// porque se midio sobre 03_Hardware_Tarjeta/KiCad/*.kicad_sch, que esta INCOMPLETO
// -sin LCD, sin botones y sin este canal-. En el esquematico bueno
// (01_Firmware/Controladora_Semaforos/.../*.kicad_sch, 649 KB) la red se llama
// "Motor" y tiene canal de potencia propio, igual que las ocho luces:
//
//     PB2 --> R70 220 / R69 10K --> opto TLP127 (U15) --> MOSFET IRLZ44N (Q10) --> J15
//
// Son DIEZ MOSFET y DIEZ optos en la placa (Q1..Q10, U6..U15), no nueve: el buzzer
// tiene el suyo (U13/Q8/J13) y la talanquera el suyo. Ver roadmap.md N-64.
#define MOTOR_TALANQUERA   PB2  // -> opto U15 -> MOSFET Q10 -> bornera J15

// SFTY-28: niveles de la pluma. En LOW el MOSFET no conduce, el motor queda SIN
// energia y la pluma se queda ABAJO. Ese es el fallo seguro y por eso el nivel de
// reposo es el de cerrar: si el equipo se muere, la barrera no queda abierta.
// La especificacion de compra pide ademas actuador con retorno por muelle o gravedad,
// porque eso el software no lo puede garantizar.
#define TALANQUERA_ABRIR   HIGH
#define TALANQUERA_CERRAR  LOW

// --- Camaras IA AcuSense (entradas de contacto seco) ---
//
// La camara de DEMANDA entra por PB0, y la placa la ayuda: esa linea lleva R64 10K y
// C25 100nF hasta la bornera J14, o sea un RC de 1 ms. Es un ANTIRREBOTE POR HARDWARE
// -la bornera estaba pensada como entrada, y por eso el esquematico la llama "Puerta"-.
// 🛑 D-27 (2) (11/09, decision del responsable): J14 QUEDA LIBRE, SIN CABLEAR. El fin de carrera
// NO se instala en este despliegue, y eso cierra el conflicto de A-2 SIN TOCAR EL FIRMWARE.
// MIENTRAS EL FIRMWARE LEA PB0 COMO DEMANDA, EN J14 NO SE CONECTA NADA: J14 es una ENTRADA del
// micro -3,3 V, sin opto ni diodo- y la salida de talanquera es J15. Un rele cableado aqui se
// desconecta ANTES de energizar. El ancla vive en este fichero a proposito: es donde mira quien
// llega con el destornillador (CLAUDE.md 3).
#define CAM_DEMANDA_PIN    PB0  // -> R64 10K + C25 100nF -> bornera J14 (antirrebote 1 ms)

// LA CAMARA DE UMBRAL NO TIENE ENTRADA FISICA, Y ESTE PIN NO ES ELLA.
//
// Medido el 27/08 sobre el esquematico bueno: PB8 va por R16 1K a un LED (D5). Es un
// TESTIGO en la placa, no una bornera y no una entrada optoacoplada. Durante meses
// cuatro manuales lo describieron como "umbral de tramo" (N-59) y el firmware le hacia
// un pinMode que no servia para nada.
//
// Se deja en alta impedancia a proposito: sea cual sea el sentido del LED -no esta
// trazado-, un pin flotante no puede encenderlo. Con INPUT_PULLUP se le colarian unos
// 40 uA y quedaria un testigo encendido a medias que nadie sabria explicar.
//
// Si algun dia se quiere la camara de umbral hacen falta DOS cosas, y ninguna es este
// pin: un hilo -pad de PB8 retirando R16/D5, o uno de los cuatro pines sin cablear
// (PA11, PA12, PA15, PC13)- y un comando de radio que lleve la cuenta del tramo al
// Maestro, que es quien decide. Ver roadmap.md N-59 y N-64.
#define LED_TESTIGO        PB8  // -> R16 1K -> LED D5. NO es entrada de camara
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

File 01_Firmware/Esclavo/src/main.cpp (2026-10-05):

#include <Arduino.h>
#include "pines.h"
#include "semaforo.h"
#include "protocolo.h"
#include "demanda.h"    // la puerta unica por la que sale una demanda
#include "reloj.h"           // SFTY-23
#include "botones.h"         // N-16
#include "config_ciclo.h"    // SFTY-23: lo que este fichero publica para el Degradado
#include "modo_degradado.h"  // SFTY-21
#include "respaldo.h"        // N-20: lo que sobrevive al corte de energia
#include "bluetooth.h"       // Módulo Bluetooth Serial (USART1)
#include "deg_auto.h"        // A-15: el Degradado automatico (SPEC_2 7.ter)
#include <IWatchdog.h>

static unsigned long tInicioVerdeEsclavo = 0;

// Backstop de verde máximo. 105 min > los 99 min máximos configurables en el Maestro.
static const unsigned long MAX_VERDE_BACKSTOP_MS = 6300000UL;

// ---------------------------------------------------------------------------
// SFTY-17: Retardo de cortesia antes de responder
//
// En modo REPETIDOR hay una radio intermedia (B2) que acaba de TRANSMITIR la
// orden hacia este nodo y necesita tiempo para volver a RECEPCION. Si el Esclavo
// contesta de inmediato, su respuesta sale mientras B2 todavia esta conmutando y
// B2 sencillamente NO LA OYE: el enlace funciona en un sentido y no vuelve nada.
//
// Sintoma en campo (31/07/2026): con repetidor, el contador del puente marcaba
// C<-Esclavo = 1 byte en dos minutos, mientras la ida fluia con normalidad.
//
// En enlace DIRECTO este retardo es inofensivo: el Maestro espera hasta
// TIMEOUT_ACK_MS = 3500 ms, asi que 200 ms no cambian nada.
static const unsigned long RETARDO_RESPUESTA_MS = 200;

// Respuesta programada: se guarda que hay que contestar y cuando, en vez de
// bloquear el bucle con un delay(). Asi el parpadeo de ambar y el watchdog
// siguen atendidos con normalidad.
static uint8_t respuestaPendiente = 0;   // 0 = ninguna
static uint8_t respuestaParam = 0;
static unsigned long tEnviarRespuesta = 0;

// El param se anadio para SFTY-23: CMD_DELTA_RESP no es un ACK seco, lleva dato
// (el desfase medido). Los ACK previos siguen llamando con un solo argumento.
//
// Solo cabe UNA respuesta pendiente: si llega otra orden dentro de la ventana de
// 200 ms, la nueva pisa a la anterior. Se deja asi a proposito. Las tramas de
// SFTY-23 salen del Maestro estando en menu, con el ciclo parado, de modo que no
// compiten con los ACK de luz; y anadir una cola solo para este caso meteria mas
// codigo del que resuelve en el bucle mas critico del equipo.
static void programarRespuesta(uint8_t comando, uint8_t param = 0) {
  respuestaPendiente = comando;
  respuestaParam = param;
  tEnviarRespuesta = millis() + RETARDO_RESPUESTA_MS;
}

static void atenderRespuestaPendiente() {
  if (respuestaPendiente == 0) return;
  if ((long)(millis() - tEnviarRespuesta) < 0) return;
  protocolo_enviarPaquete(respuestaPendiente, respuestaParam);
  respuestaPendiente = 0;
  respuestaParam = 0;
}

// ---------------------------------------------------------------------------
// SFTY-23: Sincronizacion horaria por radio (lado Esclavo)
//
// NADA de lo que hay en este bloque toca las luces ni el backstop de verde
// maximo. El Esclavo puede estar en verde mientras se le pone en hora y no debe
// enterarse: se escribe en el RTC y en dos variables, punto.
//
// Tampoco se refresca tUltimoComando con estas tramas, y es deliberado. Ese
// temporizador significa "el Maestro sigue GOBERNANDO el cruce", no "hay portadora
// en el aire". Si el Maestro se quedase colgado en la pantalla de hora mandando
// solo sincronizaciones, refrescar el temporizador mantendria al Esclavo en su
// ultimo color de forma indefinida en vez de caer a ambar intermitente a los 12 s.
// La caida a ambar es la conducta segura y no se compra con trafico de servicio.
// ---------------------------------------------------------------------------

// Buffer de aplicacion ATOMICA. Ni la hora ni el dia caben en el unico byte de
// param, asi que el envio llega en CUATRO tramas (D, H, M, S); dia, hora y minuto se
// APARCAN AQUI y el RTC no se toca hasta que llega la de segundos. Nunca puede
// quedar una hora a medias: si se escribiera la hora al vuelo y se perdiera la trama
// de minutos, el Esclavo se quedaria con la hora nueva y el minuto viejo, que es
// peor que no sincronizar, porque reloj_enHora() seguiria diciendo true sobre una
// hora falsa.
//
// EL DIA ENTRA EN ESTA MISMA REGLA, no aparte. Aplicar la hora sin el dia dejaria a
// esta punta sincronizada al segundo pero con SU PROPIO calendario, que es
// exactamente el defecto que CMD_HORA_D viene a cerrar: con calendarios
// desacoplados, un corte de energia en la vuelta de 31 a 1 de una de las dos puntas
// deja a esa en AMBAR sin poder reanudar el Degradado mientras la otra reanuda y da
// VERDE. Media sincronizacion aqui no es media mejora, es el fallo asimetrico
// intacto.
static uint8_t bufDia = 0, bufHora = 0, bufMinuto = 0;
static bool tieneDia = false, tieneHora = false, tieneMinuto = false;
static unsigned long tBufHora = 0;

// Caducidad del buffer. Dia, hora y minuto son una FOTO del reloj del Maestro tomada
// en el instante en que armo las tramas; cuanto mas envejecen aqui, mas se alejan de
// la verdad. El caso feo es el cambio de minuto: con H y M capturados en 10:59:58 y
// los segundos llegando ya en las 11:00, se escribiria 10:59:0x, un minuto atrasado.
// El dia caduca CON los demas y no por separado: es parte de la misma foto -en la
// vuelta de medianoche envejece igual que la hora- y separarlo abriria la puerta a
// aplicar un dia de un envio con una hora de otro.
// Las cuatro tramas viajan seguidas (milisegundos), asi que 3 s es holgado para un
// envio normal y a la vez acota cuanto puede envejecer la foto. Pasada la ventana
// se descarta y el Maestro tendra que repetir el envio entero.
static const unsigned long VENTANA_HORA_MS = 3000;

static void olvidarBufferHora() {
  tieneDia = false;
  tieneHora = false;
  tieneMinuto = false;
}

static void caducarBufferHora() {
  if (!tieneDia && !tieneHora && !tieneMinuto) return;
  if (millis() - tBufHora > VENTANA_HORA_MS) olvidarBufferHora();
}

// FASE 2 (03/08/2026): la configuracion del ciclo se mudo a src/config_ciclo.cpp.
//
// Vivia aqui, y el delator de que no era su sitio estaba a la vista: config_
// verdeSegundos() y sus tres hermanas son API PUBLICA -las declara config_ciclo.h y
// las consume el Modo Degradado- y estaban IMPLEMENTADAS EN EL PUNTO DE ENTRADA. Un
// modulo cuya implementacion vive en main.cpp no se puede probar solo.
//
// Ahi vive tambien el unico fallo abierto del validador del Esclavo, el 30/31 -el par
// verde+despeje mezclado entre envios-, que ahora se ejerce con:
//
//     python 01_Firmware/Simulaciones/banco/correr.py --pack esclavo_03
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

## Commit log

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2026-09-02 fix: SFTY-3 y SFTY-7 estaban INTERCAMBIADAS en el fuente, y el "ocho" de SFTY-27 eran cuatro
    Dos hallazgos, y el segundo es sobre nosotros.
    1. SFTY-3 y SFTY-7 etiquetaban cada una el mecanismo de la otra, en las TRES puntas.
    SFTY-3 es "CRC-8 Maxim (0x31) en todos los paquetes RF" y estaba puesta sobre la
    resincronizacion temporal del buffer; SFTY-7 es "reintento de ACK cada 3,5 s" y
    estaba sobre el polinomio CRC. Solo Repetidor/src/main.cpp usaba SFTY-3 bien.
    Y la tabla de trazabilidad HEREDO el error -la fila SFTY-7 apuntaba a protocolo.cpp-,
    que es por lo que llevaba de pie: la fila se levanta del label, asi que un label malo
    se copia a la tabla y desde ahi se lee como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
    [protocolo.cpp]
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2026-09-02 feat(SFTY-2): un instrumento ejecuta el C++ REAL de LAS DOS PUNTAS a la vez - y conectado a la compuerta
    Hasta hoy NINGUN instrumento ejecutaba las dos puntas a la vez. barrera_02 comparaba el
    TEXTO del enclavamiento -buen proxy, no un ejercicio-, Validacion_Automatico compila C++
    real pero SOLO del Maestro, y lo unico que cerraba el lazo era una copia del firmware
    escrita a mano en Python: justo lo que el apartado 8 avisa que no prueba el codigo.
    Verde contra verde en un cierre de carril es un choque frontal, asi que era la propiedad
    mas cara del equipo y la peor cubierta.
    EL CHOQUE DE SIMBOLOS, que era el problema de verdad. Las dos puntas definen los mismos
    nombres con implementaciones d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
    [pines.h]
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2026-09-04 fix(N-117): el perro del ESP32 se comia su propio arranque
    setup() armaba el task watchdog -2 s, panic=true- y NO lo alimentaba hasta el
    primer vigilante_alimentar() de loop(). Las cuatro etapas de arranque compartian
    un solo presupuesto de 2000 ms, y la cara es transporte_abrir(): monta la NVS por
    Preferences y levanta la pila Bluedroid clasica entera.
    Cuanto tarda eso no lo ha medido nadie, y lo declara el propio contrato.h en AB-3
    con ESP32_ARRANQUE_MEDIDO = 0. Un techo duro de 2 s sobre un arranque de duracion
    desconocida no es una proteccion: es una apuesta, y si se pierde el modulo se
    reinicia en bucle. Desde el telefono eso no se ve como averiado: se ve como que
    APARECE Y DESAPARECE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
    [main.cpp]
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2026-09-04 fix(N-118): el mando A/B pasa a activo en ALTO - lo decide el cobre
    El mando de reles no se podia pulsar, y no era una regresion nuestra: la
    contradiccion es ORIGINAL. Se comprobo contra el repositorio del que salio este
    firmware -github.com/dieleoz/2semaforos_3estados-:
    botones.cpp INPUT_PULLUP + `== LOW`, identico al de hoy
    pines.h PB9 PB13 PB14 PB15, identicos
    .kicad_pcb md5 088667eac75207e8dcfa0ce5b93adce6, 2.158.421 B, BYTE A BYTE
    EL MISMO FICHERO
    (dnp yes) cero apariciones en todo el esquematico: R65-R68 se montan
    Mismo firmware y misma placa desde el primer dia. El mando NUNCA fue funcional.
    LA MEDIDA QUE LO CIERRA (ba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
    [botones.cpp, pines.h]
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2026-09-04 docs(AB-1): el latido del ESP32 NO se construye - el plan escrito era falso y aqui esta la medida
    El responsable decidio hoy que el ESP32 emita un latido propio, para que los tres
    contadores de silencio de J17 del STM32 dejen de contar "silencios del puerto" y
    pasen a contar cortes del puente. El problema esta bien planteado: por J17 solo
    entra lo que un dedo pulsa en la app, asi que hoy un puente vivo y uno muerto no se
    distinguen desde el STM32.
    SE PARO ANTES DE ESCRIBIRLO, y no por el presupuesto de cable: por el RECEPTOR.
    MEDIDO en las DOS puntas, mismo codigo -Maestro/src/bluetooth.cpp:626-637 y
    Esclavo:605-616-: j17RegistrarLinea() vive DENTRO del if de linea no vacia y
    DESPUES del d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
    [main.cpp]
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2026-09-04 fix(N-130): el equipo deja de decir que si a lo que no va a hacer
    El Esclavo contestaba "$ACK,CMD:SOLICITAR_PASO,RESULT:PEDIDO_AL_MAESTRO" y el
    Maestro armaba demandaRemotaPendiente SIEMPRE. Censado quien LEE esa bandera:
    solo modo_inteligente.cpp. En Manual y en Automatico el operario de pie junto
    al Poste 2 pulsaba, leia la confirmacion, y el cruce no se movia. Volvia a
    pulsar.
    POR QUE NO LO VIO NADIE, que es la parte reutilizable: leidas por separado,
    NINGUNA de las dos ramas esta mal escrita. La del Esclavo dice la verdad -la
    peticion salio-. La del Maestro acusa un paquete que recibio. El defecto solo
    existe en la COSTURA, y ningun pack de una punta podia verlo. Es §6 -un $ACK
    que no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
    [main.cpp]
2026-09-04 fix(N-131): la guarda de 3 minutos era MEDIA guarda
    Lo encontro una revision cruzada el mismo dia que se escribio la guarda, y es
    el hallazgo que casi se escapa: VERDE_MIN_MIN / ROJO_MIN_MIN solo los cruzaba
    SET_TIEMPOS. Habia CINCO sitios mas con el numero prohibido escrito a mano en
    modo_automatico.cpp:
    - el inicializador estatico ............ minRojo = 1, minVerde = 1, segEstatico = 15
    - el reset de modoAutomatico_setup() ... los mismos tres, otra vez
    - los topes de los tres campos del menu piso 1 min / 1 min / 5 s
    techo 99 / 99 / 999
    CONSECUENCIAS REALES, no teoricas:
    - un equipo al que nadie manda SET_TIEMPOS corria con UN MINUTO por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
    [arnes_automatico.cpp]
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2026-09-04 fix(N-42, N-133): el Modo Automatico vuelve a correr, y los tiempos dejan de perderse
    DESBLOQUEA EL BANCO. Reportado hoy con las dos placas ya hablando: "maestro
    rojo, este poste no da paso, poste dos no informa, y a veces el esclavo se
    pasa a ambar parpadeando solo".
    N-42, LA CADENA COMPLETA Y FECHADA. SET_MODO:AUTO contesta $ACK RESULT:OK y
    entra en modoAutomatico_setup(), que dejaba fase = CONFIG_ROJO -un cuestionario
    de tres preguntas de la epoca de la pantalla LCD-. Su unica salida era
    botonAceptar(), que devuelve false SIEMPRE desde deeeab4 (31/08), cuando BOTON3
    y BOTON4 pasaron a ser entradas de camara. Nunca llegaba a CORRIENDO, y de ahi
    salian DOS de los sintomas con una sola caus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
    [respaldo.cpp]
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2026-09-05 fix(N-134, N-135): el ambar se ordena, y un enum de un valor no es un estado
    N-135 ES UN DEFECTO PROPIO, introducido por el arreglo de N-42 de esta misma
    tarde y cazado horas despues. Va primero porque es el que importa.
    Al retirar las tres fases del asistente quedo `enum FaseAuto { CORRIENDO };`
    con su `static FaseAuto fase;`, y un comentario ESCRITO EN EL MISMO COMMIT
    diciendo que el enum sobrevivia porque enMarcha() "se lee mejor preguntando por
    la fase que por una bandera suelta". Se leia mejor y ya no preguntaba nada.
    Medido con el compilador del proyecto, no razonado:
    arm-none-eabi-g++ -Os -S -mcpu=cortex-m3 -mthumb
    enMarcha: movs r0, #1
    bx lr
    Con un solo e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
    [arnes_automatico.cpp, main.cpp]
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2026-09-05 fix(N-137, N-138): el Modo Inteligente corria a 2 minutos, y el reloj mentia el motivo
    N-137 ES LA TERCERA VEZ EL MISMO DIA. modo_inteligente.cpp configuraba el
    coordinador con `maxVerde = 2` MINUTOS -por debajo del minimo vial de 3 que fijo
    el responsable- y NO pasaba por SET_TIEMPOS, asi que ninguna guarda lo tocaba.
    Encima era el modo que la guia de banco recomendaba como salida mientras el
    Automatico estuvo roto: el cruce habria corrido con verdes de 2 minutos justo
    donde el minimo son 3.
    Los otros dos del mismo dia fueron N-131 -cinco copias a mano dentro del propio
    modo_automatico.cpp, con pisos de 1 min y 5 s- y la cuarta copia de js/config.js.
    Tres agujeros, una causa: los seis limi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
    [arnes_automatico.cpp]
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2026-09-05 fix(N-144): HORA:00:00:00 no es medianoche - y el instrumento que no veia la barra
    DOS COSAS QUE DESTAPO LA MISMA SESION DE BANCO, y las dos son de la familia
    "algo declarado que nadie ejercio".
    N-144 - EL EQUIPO SE DECLARABA EN HORA CON EL RELOJ PARADO EN CEROS.
    En la cinta de campo del 04/09 el Maestro pasa de mandar HORA:--:--:-- a mandar
    HORA:00:00:00 justo despues de intentar el Courier RTC. No es medianoche: es un
    contador que no avanza con la bandera de "tengo hora" puesta.
    La causa: reloj_ajustar() pone horaValida = true al terminar de escribir, y
    ajustarRelojVerificado() comprobaba DESPUES si habia quedado. Cuando no quedaba
    -que con el cristal Y2 muerto (N-17) es el caso NORMAL,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
    [reloj.cpp]
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2026-09-05 fix(N-142): el Esclavo AVISA de su ambar de emergencia - y los dos vetos se quedan
    Reportado en banco el 04/09: se pide ambar desde el telefono junto al Poste 2 y el
    Maestro no se entera. Peor: el Esclavo sigue contestando PONG estando en ambar, asi
    que el enlace le parece perfecto al otro extremo. Si el Maestro estaba en VERDE,
    seguia dandolo -hasta 3 minutos con los tiempos de hoy- con el otro lado en ambar, y
    los dos sentidos podian entrar al carril. El Maestro solo se enteraba al agotar
    reintentos en el cambio siguiente, o sea tarde y por el camino del fallo.
    CMD_AMBAR_ESCLAVO (0x14): el Esclavo lo manda al armar el latch, sin esperar acuse y
    sin reintento -su operario esta esperando de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
    [main.cpp]
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2026-09-05 fix(N-151): DAR PASO en un modo sin coordinador trababa el cruce para siempre
    LO DESTAPO UNA CINTA, Y EL SINTOMA NO SE PARECIA A LA CAUSA
    ------------------------------------------------------------
    El equipo en MODO:AMBAR y TRES MANUAL:CAMBIAR_TURNO en 40 s, los tres contestados
    "$ERR,CMD:CAMBIAR_TURNO,DESC:EN_TRANSICION_REINTENTE". El operario leia "el cruce esta
    cambiando de fase, repita al terminar" y EL CAMBIO NO TERMINABA NUNCA.
    main.cpp EXCLUYE a MODO_AMBAR y a MODO_DEGRADADO del refresco de fondo -en esos dos el
    Maestro calla en la radio A PROPOSITO- y sus loop() no llaman al coordinador: alli la
    maquina esta CONGELADA. La PRIMERA pulsacion si entraba -estadoC valia C_IDLE- y dejaba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
    [pines.h]
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2026-09-05 fix(N-152): el Esclavo AVISA de que retira su ambar - y en MODO_AMBAR el Maestro ESTABA SORDO
    N-142 cerro el aviso al ARMAR el ambar y dejo abierto el de CANCELARLO: la rama
    CANCELAR_AMBAR limpiaba el latch y contestaba al telefono, y el unico
    protocolo_enviarPaquete() del fichero era el :486 de armado. Al cancelar desde el Poste
    2, el Esclavo salia y EL MAESTRO SE QUEDABA EN AMBAR: habia que caminar al Poste 1.
    EL HALLAZGO QUE CAMBIO EL DISENO ENTERO, Y QUE UN COPIA-PEGA DE N-142 NO HABRIA VISTO
    --------------------------------------------------------------------------------------
    Censado, no leido: protocolo_hayPaqueteDisponible() se llama en UN SOLO SITIO de todo el
    Maestro -coordinador_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
    [main.cpp]
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2026-09-05 fix: la linea falsa de pines.h que quedo SIN ARREGLAR en el Esclavo, y un enum de un solo valor
    LOS TRES SALEN DE UNA REVISION EXTERNA, NO DE UN TEST. Los comentarios no compilan y los
    enums de un valor no fallan: hay que ir a mirarlos.
    1. EL POSTE 2 SE QUEDO CON LA CABECERA EQUIVOCADA
    ---------------------------------------------------
    El arreglo de 273b315 corrigio "BOTON1/BOTON2: INPUT_PULLUP, activo en BAJO" en el Maestro
    Y NO TOCO EL ESCLAVO. Durante unas horas la punta que esta a 1000 m -a la que no se llega
    andando- llevo la frase falsa en el fichero que ESTADO llama "la cabecera que todo el mundo
    lee antes de cablear". El fuente de esa punta hace pinMode(BOTON1, INPUT) pelado
    (boton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
    [pines.h]
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2026-09-05 fix: la camara PEDIA paso pero no podia SOSTENER la fase - 362.500 ms contra 720.000
    EL DEFECTO QUE YO LE DI AL AGENTE ERA FALSO. Escribi "el vigilante mira J16 y el modo lee J14,
    asi que la camara no hace nada por el trafico". La cadena existia y estaba viva desde N-97:
    camaras_actualizar() -> demanda_solicitar() -> demanda_hayLocal(), y botones_actualizar() corre
    en TODAS las vueltas y TODOS los modos. Estaba escrito a proposito en el fuente del Esclavo.
    Y DEBAJO HABIA UNO PEOR, QUE SOLO ENCONTRO EL ARNES CORRIENDO: ese camino sirve para PEDIR
    PASO, no para SOSTENER una fase. La ventana de demanda_hayLocal() NO SE PROLONGA con cada
    deteccion -la peticion que cae dentro se descarta COMO PE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
    [arnes_automatico.cpp, botones.cpp, pines.h]
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2026-09-07 docs(firmware): anclar las decisiones vigentes en el codigo - de 5 marcas D-x a 16
    EL PROBLEMA, en palabras del responsable: "cambiamos varias veces las spec y
    el codigo arrastra cosas de una spec y de otra; lanzas subagentes y todos
    desarrollan con una version o con otra, y vamos y volvemos".
    MEDIDO DE DONDE SALE: el firmware tenia 61 marcas N-x -como se descubrio un
    fallo- y 5 marcas D-x -que decision obedece este codigo- de 19 vigentes. El
    codigo contaba muy bien como se encontro cada bug y casi nada sobre a que
    version de la spec obedece. Por eso cada agente elegia una spec distinta: no
    habia nada en el codigo que se lo dijera.
    Solo comentarios. Cero lineas ejecutables, verificado con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
    [botones.cpp, main.cpp, pines.h]
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2026-09-07 fix: encapsular parseo de SET_RTC en reloj y sincronizar metricas del acta
    [reloj.cpp]
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2026-09-07 revert(D-14): retirar el ancla sin construir - un rojo no se decora
    Revierte 25593de. Ponia dos comentarios en pines.h con la marca D-14 y con
    eso decisiones_01_anclas dejaba de contarla como ausente. No habia una linea
    de codigo detras: D-14 sigue BLOQUEADA por la medida de multimetro del
    regimen electrico de la entrada de alarma de la camara.
    Y el informe que la acompanaba decia que reservaba PB14/PB15. Medido: PB14 y
    PB15 son CAM_C_PIN y CAM_D_PIN, ENTRADAS de camara que ya existian; los
    comentarios fueron a parar junto a ROJO_PEATON (PA6) y VERDE_PEATON (PA7).
    CLAUDE.md 1: si un rojo se apaga CONSTRUYENDO, se construye o se deja rojo.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
    [pines.h]
2026-09-07 revert(D-22): retirar el ancla sin construir - Y1 sigue sin arrancarse nunca
    Revierte 6a79649. Ponia tres comentarios en cada main.cpp con la marca D-22.
    Cero codigo: D-22 es poner Y1 como latido del micro, y el firmware sigue
    arrancando con el HSI, que es lo que hacia antes.
    Y el comentario describia el HSI de HOY como si fuera la decision
    implementada -"corre con HSI interno seguro (fallback que no cuelga si Y1 no
    oscila)"-, que es peor que no tener ancla: el siguiente que lo lea da por
    construido lo que no existe. El informe ademas la situaba en reloj.h, donde
    no hay ni una marca D-22.
    D-22 va la ULTIMA y va SOLA, y su carga no se hace sin una tarjeta delante:
    si Y1 no oscila el _Error_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
    [main.cpp]
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2026-09-08 fix(N-160, D-20): el sembrador de hora acusa lo que hizo, y el contador vuelve a decir "no hay reloj"
    DOS DEFECTOS, y el segundo es el que podia dar dos verdes desfasados en una calle.
    1) reloj_sembrarDesdeIso() devolvia true aunque reloj_ajustar() -void- hubiera
    rechazado los valores en silencio. Es el patron de CLAUDE.md 2 una capa por
    debajo del $ACK: el retorno no dependia de lo que la llamada hizo. La barrera de
    coordinador_sincronizarHora() cubria el reloj nunca sembrado; NO cubria la
    RE-SIEMBRA, donde el equipo acusaba exito y propagaba la hora VIEJA, y el tecnico
    se iba del poste creyendo que la dejo puesta.
    No se pudo cambiar la firma de reloj_ajustar() a bool: TRES arneses la DEF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
    [reloj.cpp]
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2026-09-08 fix(N-160, D-20): si Y2 arranca TARDE, la hora saltaba en silencio con horaValida en true
    TERCER defecto de la familia, y lo encontro la auditoria de solo lectura.
    EL CAMINO, que D-20 hace normal: arranca sin cristal -reloj_setup() sale por
    "if (!arrancarCristal()) return;" y rtcOperativo queda en false-, alguien siembra
    por SET_RTC y la base se queda SOLO en software, porque el bloque
    "if (rtcOperativo)" de reloj_ajustar no corre. Treinta segundos despues
    reloj_actualizar() reintenta, ve el LSERDY y adopta el cristal: rtcOperativo pasa
    a true. A PARTIR DE ESA LINEA reloj_hora/minuto/segundo/dia() y
    reloj_segundosDelDia() cambian de fuente al RTC hardware, QUE NUNCA SE SEMBRO, y
    horaValida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
    [reloj.cpp]
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2026-09-08 fix(N-154): el $ALARM cabia por VALOR y no por BUFFER, y lo que se perdia era la HORA
    EL SINTOMA PUBLICADO DURANTE UN MES ERA FALSO EN SU MITAD UTIL, y esto vale mas
    que el arreglo. Decia: "trunca en silencio, no casa el CRC, y la app la tira
    entera: el sintoma es -el equipo se callo-, que manda a mirar el cable". Medido
    al arreglarlo: EL CRC SI CASA. enviarTramaConCrc() calcula el checksum sobre el
    payload YA TRUNCADO, asi que la trama sale bien formada y la app la acepta. Lo
    que falta es el final, o sea el valor de HORA: -y en el Esclavo parte de ACCION:-.
    Una alarma que la app tira se nota; una alarma SIN HORA se archiva y nadie la
    mira, que es lo contrario de para lo que existe una Caja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
    [botones.cpp, main.cpp]
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2026-09-08 feat(D-24): CAM_CIEGA sube a 24 h de paso abierto - las dos puntas, la app y los 7 documentos
    DECIDIDO EL 05/09 Y SIN CONSTRUIR HASTA HOY. Y la decision no estaba en
    DECISIONES.md: vivia en roadmap.md y en un manual, o sea que un agente que
    abriera la tabla vinculante antes de trabajar -que es lo que manda- se paraba
    con razon. Se escribe la fila.
    EL NUMERO: 24 h, no los 4 dias anotados. El responsable delego el numero -"los
    dias que estimes"- sobre la premisa de que "la desincronizacion es de meses".
    ESA PREMISA ES DE OTRO SITIO Y SE CORRIGE EN VEZ DE HEREDARLA: los meses son el
    plazo del RELOJ (D-21, el extrapolador); CAM_CIEGA no cuenta reloj. Una
    propiedad es del oscilador y la otra de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
    [botones.cpp]
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2026-09-11 fix(N-162): GO_GREEN idempotente en el Esclavo - un reintento ya no reinicia el ambar
    La rama CMD_GO_GREEN del Esclavo llamaba a semaforo_iniciarTransicionAVerde()
    en CADA orden, y esa funcion pone S_AMARILLO y rearma tCambio este donde este
    la luz. El Maestro repite GO_GREEN cada TIMEOUT_ACK_MS (3500) mientras no le
    llega el ACK_GREEN, y el ambar dura 4000: con acuses perdidos, cada reintento
    reiniciaba el ambar y el Esclavo no llegaba a verde mientras duraran; uno
    tardio devolvia un VERDE a ambar. Es lo del banco del 04/09 ("rojo y ambar a
    los 15 s" y la app diciendo "repita") y del Sisga el 10/09.
    Ahora, con S_AMARILLO o S_VERDE la orden no toca la luz y se re-acusa. Los
    vetos (mando_amb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
    [main.cpp]
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2026-09-11 fix(N-162): el Maestro no se da verde sin el ACK_RED del Esclavo - 180 s de verde en las dos puntas
    Medido en el arnes de las dos puntas (C++ real de las dos): un corte de radio
    de ~18 s al dar el verde al Esclavo se llevaba el unico GO_RED de la
    autorrecuperacion SFTY-9; el Maestro no esperaba ACK_RED y a los 10 s de
    despeje se daba verde con el Esclavo aun en verde: 180 s de verde en las dos
    puntas (G2-d). Igual al entrar en un modo (iniciarModo, G5), con un ROJO TOTAL
    cuyo GO_RED se pierde (G6) y con DAR PASO desde todo-rojo sin rojo confirmado
    (G7).
    coordinador.cpp: bandera rojoEsclavoConfirmado, que solo pone un ACK_RED que no
    llega esperando un ACK_GREEN y se borra con cada orden de r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
    [arnes_automatico.cpp]
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2026-09-13 fix(anclas): D-25 y D-27 quedan ancladas donde el codigo YA vive - el rojo baja de 6 a 4
    Un agente midio las SEIS decisiones que decisiones_01_anclas acusa, una por una, para separar
    lo que es firmware que falta de lo que seria un defecto del instrumento. Resultado: 57/65 -> 61/65.
    🔴 Y REFUTA MI SOSPECHA ENTERA. El roadmap sospechaba que D-14, D-25 y D-27 "puede que no
    necesiten ni una linea de codigo y el instrumento les exige ancla igual". Medido:
    - D-14 es LO MAS FIRMWARE de las seis: pide una SALIDA que cierre un contacto y hoy no existe
    ninguna -el unico digitalWrite fuera de semaforo.cpp es el DE/RE del RS485 y el del LoRa-. Su
    propia fila dice "CERO CODIGO". Refutada de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
    [pines.h]
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2026-09-14 fix(D-32 (4)): D-14 anclada donde el destornillador la lee - quedan DOS decisiones sin ancla
    El responsable contesto D-14 el 13/09: NO SE INSTALA EN ESTE DESPLIEGUE. La medida que lo
    decide, recontada por el agente sobre la guia que de verdad sigue el instalador
    (05_Funcional/Camaras_Sisga_4x.html): J16 48 menciones, J15 15, J14 9, y de J9, J11 y J13 CERO.
    Y solo cablea la SALIDA de alarma de la camara (1A/1B hacia J16); nunca su ENTRADA, que es lo
    que D-14 pedia.
    EL ANCLA VA JUNTO A LOS TRES CANDIDATOS, no a un pin: a diferencia de D-25 y D-27 -que anclan en
    un pin ya elegido- D-14 nunca eligio. La decision es que NINGUNO de los tres se gasta, asi que
    el ancla vive donde estan los tres y d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
    [pines.h]
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2026-09-15 fix(1.49c): el silencio del Maestro cuenta desde lo que le CONTESTAN, no desde cualquier trama
    Medido: con la bajada Maestro->Esclavo muerta y la camara del poste 2 pidiendo
    paso, cada CMD_DEMANDA refrescaba tUltimaRxEsclavo y el Maestro nunca vencia su
    silencio - poste 1 en verde toda su fase (157 s) frente al ambar del poste 2.
    Contradecia SPEC_2 4 ("ancla = la respuesta que le CONTESTARON").
    tUltimaRxEsclavo sale: sus cinco lectores preguntaban "me contesta?". Entra
    tUltimaRespuestaEsclavo, que solo refrescan la respuesta del latido en vuelo,
    ACK_RED en su espera o en C_FALLO (SFTY-9, medido: sin el, +2,1 s de ambar en
    G13) y ACK_GREEN en su espera. La compuerta de D-34 exige ahora de ve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
    [arnes_automatico.cpp]
2026-09-15 fix(1.49a+b): el cristal parado no deja reanudar el Degradado, y REINICIAR_RELOJ ya no dice OK sin saberlo
    (b) Medido: tras un reinicio SOLO del STM32, si la siembra del ESP32 caia en la
    ventana del cristal, el Esclavo reanudaba con 0 h y msDesdeSyncEfectivo ignoraba
    la CADUCADA porque "la RAM esta sana" - RAM que salio de la pila: verde del
    poste 2 frente al ambar del poste 1 (273 s). b1: bandera syncDesdePila en el
    Esclavo (dos preguntas, dos banderas). b2: la reanudacion espera el veredicto
    del cristal en las dos puntas, acotado a la ventana (D-29 no lo prohibe). b3:
    el Maestro alarma la rama del limite con su causa real (RELOJ_NO_CUENTA,
    SYNC_SIN_FECHA, LIMITE_48H) en vez de caer mudo co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
    [reloj.cpp]
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2026-09-15 fix(1.49b3): sin cristal ya no se rotula 'Reloj sin contar - No es la radio'
    reloj_estadoCristal() juntaba dos preguntas: 'nunca arranco' y 'arranco y no
    cuenta'. En las tarjetas de campo el cristal no oscila (D-22 sin construir), asi
    que un limite REAL de 48 h sin radio salia como RELOJ_NO_CUENTA y mandaba al
    tecnico lejos de la radio. Cuarto estado SIN_CRISTAL: RELOJ_NO_CUENTA solo con
    cristalCongelado; sin cristal cae a LIMITE_48H o SYNC_SIN_FECHA. REINICIAR_RELOJ
    contesta SIGUE_PARADO si lo ve (nunca un ACK). Flash Maestro +32 B, Esclavo +16 B.
    Instrumento, contesta el hallazgo: G8 del Degradado (48 h enteras sin cristal:
    70/71 en 622a20b -> 71/71). Control negativo visto fallar, restaur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
    [reloj.cpp]
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2026-09-28 fix(test_leds): la prueba de focos ya no da verde contra verde en servicio
    Cinta del funcional del 28/09 (Maestro 4D2007): al acabar TEST_LEDS la luz
    quedaba en rojo con ESTADO:VERDE. Medido con coordinador+semaforo reales:
    en servicio, con el Maestro en rojo y el Esclavo en verde, la fase verde del
    test encendia el verde del Maestro 2 s (SFTY-2 solo mira este poste).
    - Maestro: TEST_LEDS solo en MENU/HORA/ALCANCE y con el rojo del Esclavo
    acusado; si no, $ERR con motivo (molde SET_TIEMPOS). Se corta si sale de
    servicio y al acabar devuelve la luz del estado. En C_MENU_IDLE no se
    pisa la luz mientras el test corre.
    - Esclavo: el final del test pasa por semaforo_forzarRojo().
    - App: el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
    [semaforo.cpp]
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
